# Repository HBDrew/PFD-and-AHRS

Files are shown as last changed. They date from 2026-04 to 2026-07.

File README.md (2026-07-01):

# AHRS PFD — Dual Display System

A two-board avionic display system with **two display versions** that share a single AHRS source:

| Board | Role |
|---|---|
| **Pico W** | Reads IMU (ICM-42688-P or WT901), GPS, BME280 baro. Serves state to the display over Wi-Fi SSE |
| **Pi Zero 2W** | Waveshare 3.5" DPI 640×480 PFD — plain horizon, TAWS alerting, airport/runway overlays, no SVT |
| **Pi 4 / Pi 5** | 1024×600 PFD — true 3D Synthetic Vision Terrain rendered through OpenGL ES + same overlays (same `pi4/` build on either board) |

Both displays connect to the same Pico W AHRS unit over Wi-Fi SSE. The feature set (airports, runways, extended centerlines, obstacles, TAWS, persistence, simulator, demo mode) is identical across both — the Pi 4 adds the OpenGL SVT terrain background with mountains that rise above the horizon line.

---

## Repository Structure

```
PFD-and-AHRS/
├── firmware/          # Pico W AHRS sensor firmware (shared by both displays)
├── shared/            # Common Python modules
│   ├── sse_client.py  # SSE streaming client
│   ├── terrain.py     # SRTM tile loader + TAWS clearance query
│   ├── obstacles.py   # FAA DOF parser + spatial query
│   ├── airports.py    # OurAirports parser + spatial query
│   ├── runways.py     # OurAirports runways parser + spatial query
│   ├── settings.py    # Debounced atomic JSON settings persistence
│   └── config_base.py # SIM_PRESETS + shared constants
├── pi_zero/           # Pi Zero 2W display version (no SVT)
│   ├── pfd.py         # Pygame PFD — plain horizon
│   ├── config.py      # 640×480 display config
│   ├── setup.sh       # One-shot install for Pi Zero 2W
│   ├── data/          # SRTM tiles (TAWS) + obstacles + airports + settings.json
│   └── previews/      # Screenshots for this version
├── pi4/               # Pi 4 display version (full SVT)
│   ├── pfd.py         # PFD with OpenGL SVT terrain background
│   ├── svt_renderer.py    # Pygame SVT fallback (when EGL unavailable)
│   ├── svt_renderer_gl.py # OpenGL ES 3.0 SVT renderer (moderngl + EGL)
│   ├── render_pfd_offline.py # Offline preview PNG generator
│   ├── config.py      # Display profile (waveshare_35 / roadom_7)
│   ├── setup.sh       # One-shot install for Pi 4
│   ├── data/          # SRTM tiles + obstacles + airports + settings.json
│   └── previews/      # Screenshots (setup screens + pfd_gl/ OpenGL flight scenes)
├── pi_display/        # Original combined codebase (preserved for reference)
├── iphone_display/    # iPhone / browser PFD (served over AHRS-Link AP by the Pico W)
├── tools/             # Preview image generator
├── fetch_sedona_tiles.sh   # Quick-start: download KSEZ area SRTM tiles
├── fetch_airports.sh       # Download OurAirports CSV + runways CSV
├── wifi_switch.sh          # Toggle Pi between home WiFi and Pico W AP
├── Docs/              # Requirements, user manuals, test procedures
└── README.md
```

---

## Display Version Comparison

| Feature | Pi Zero 2W | Pi 4 |
|---|---|---|
| Processor | ARM Cortex-A53, 512 MB RAM | ARM Cortex-A72, 2–8 GB RAM |
| Display | Waveshare 3.5" DPI LCD (640×480, 40-pin GPIO parallel RGB, I2C cap touch, PWM backlight) | ROADOM 7" HDMI IPS (1024×600, USB cap touch) — or Waveshare 3.5" DPI as a fallback |
| Graphics | Pygame / SDL2 framebuffer | Pygame UI + OpenGL ES 3.0 SVT (via moderngl/EGL) |
| SVT terrain background | No — plain sky/ground horizon | Yes — full 3D perspective mesh |
| Terrain above horizon | No | Yes — mountain peaks + ridges rise above horizon line |
| Sun-angle shading + distance grid | No | Yes |
| TAWS caution / warning banners | Yes | Yes |
| Obstacle symbols (caret + lit star + R/Y/W height colour) | Yes | Yes |
| Airport symbols (public ring / heli H / seaplane / balloon) | Yes | Yes |
| Road-sign airport labels on posts | Yes | Yes |
| Runway polygons (within 8 NM) | Yes | Yes |
| Extended dashed centerlines (within 15 NM) | Yes | Yes |
| Type filters (PUBLIC / HELI / SEAPLANE / OTHER) | Yes | Yes |
| Overlay toggles (RUNWAYS / EXT C/LINES) | Yes | Yes |
| Settings persistence (atomic JSON, debounced writer) | Yes | Yes |
| Built-in flight simulator (12 presets + failure injection) | Yes | Yes |
| Demo mode (scripted Sedona flight) | Yes | Yes |
| Target frame rate | 30 fps | 30 fps |

Both versions share the same AHRS unit, instrument layout, menus, simulator, demo mode, and touch interface. A single `shared/` module tree is used by both.

---

## Hardware

### AHRS PCB rev A (shared by both display variants)

The AHRS sensor head is now a single integrated PCB carrying every sensor on one board. Wiring is fixed in the board layout — no bench breakouts, no jumpers, no per-build pinout drift.

| Part | Bus | Address / Port | Role |
|---|-----|---|---|
| Raspberry Pi Pico W | — | USB-C (debug + power) | Host processor + WiFi AP |
| WitMotion WT901 | UART0 (GP0/GP1, 9600 baud) | — | 9-DOF IMU, fused Euler output |
| u-blox NEO-6M | UART1 (GP4/GP5, 9600 baud) | — | NMEA GPS (GGA + RMC) |
| Bosch BME280 | I²C1 (GP2/GP3, 400 kHz) | `0x76` | Static pressure + OAT |
| Sensirion SDP33-1500Pa | I²C1 (GP2/GP3) | `0x21` | Differential pressure (pitot − static) |
| *(reserved)* SDP3x AOA twin | I²C1 (GP2/GP3) | `0x22` | Future AOA probe — see `Docs/BUGS_AND_TODO.md → AOA-PROBE` |
| MAX3232 breakout | — | — | RS-232 driver for future TruTrak autopilot tie-in |

Power draw is ~130 mA at 5 V from the Pico's USB-C — typical wallwart / cigarette-lighter 5 V supply works fine; aircraft-grade builds run through a regulated 5 V converter.

Pneumatic plumbing for the air-data path:

- SDP33 `+` port → pitot tube (ram pressure)
- SDP33 `−` port → static reference (teed into the BME280's open port)

The combination produces the full pitot-static set — IAS, TAS, density altitude, and a wind solution from the AHRS heading + GPS track — broadcast on the same `$AHRS` SSE / USB JSON packet. See `Docs/REQUIREMENTS_AHRS.md §7B` for the field-level requirements and `Docs/USER_MANUAL_PI4.md §21` for the pilot-facing description.

### Pi Zero 2W display
| Part | Notes |
|---|---|
| Raspberry Pi Zero 2W | 512 MB RAM |
| Waveshare 3.5" DPI LCD | 640×480 IPS, DPI parallel RGB via 40-pin GPIO header, 5-point I2C capacitive touch, PWM backlight on GPIO 18, device-tree overlay `waveshare-35dpi-3b-4b` |
| 64 GB microSD (Class 10 / A1) | Raspberry Pi OS Lite 64-bit |
| USB-C power (5V 2A+) | |

### Pi 4 / Pi 5 display
| Part | Notes |
|---|---|
| Raspberry Pi 4 **or Pi 5** | 2 GB+ RAM recommended. The `pi4/` build runs unchanged on a Pi 5 — same install, just more frame-rate headroom for the OpenGL SVT. |
| ROADOM 7" or 10" HDMI IPS | 1024×600, HDMI video + USB capacitive touch (no software backlight control — use the panel button). Set `DISPLAY_PROFILE` to `roadom_7` or `roadom_10` in `pi4/config.py`. Waveshare 3.5" DPI 640×480 (`waveshare_35`) is a panel-mount fallback (BRIGHTNESS over GPIO-18 PWM). |
| 64 GB microSD (Class 10 / A1) | Raspberry Pi OS Lite 64-bit |
| USB-C power (5V 3A) | |

### ADS-B IN receiver (optional)
Adds live traffic to the moving map. The display consumes **GDL90 over UDP** (port 4000) — the same wire format Stratux and portable receivers emit — so any GDL90 source works; the build below runs the receiver on the same Pi.

| Part | Notes |
|---|---|
| Nooelec NESDR Nano 2 — Dual-Band ADS-B bundle | Two RTL-SDR (RTL2832U) dongles + high-gain 978/1090 antennas. One dongle per band: **1090ES** (airliner/transponder traffic) and **978 UAT** (GA traffic + FIS-B weather, US only). Marketed for Stratux/FlightAware/ForeFlight. |
| (host) Raspberry Pi | Runs `dump1090` (1090) + `dump978` (978) and the GDL90 bridge. Can be the display Pi, a dedicated Pi (e.g. a Pi 5), or an existing Stratux box on the network. |

Install the receiver stack with `sudo bash tools/install_adsb.sh`. Pipeline:

```
NESDR dongles → dump1090 / dump978 → tools/adsb_gdl90_bridge.py → GDL90/UDP :4000 → PFD
```

The display layer is hardware-free (`shared/gdl90.py` decoder + `shared/adsb.py` UDP listener), so traffic also works against a Stratux on the network or in `--demo` (synthetic targets). Toggle the symbols via **Setup → Display → MAP LAYERS → TFC**. See `Docs/ADSB_IN.md` for the full design + setup.

**No receiver? Use the internet.** `tools/adsb_internet_feed.py` pulls live aircraft from a public ADS-B aggregator (airplanes.live / OpenSky, no key) and emits the same GDL90/UDP — so you can **test with real traffic** with no hardware, or use it **in flight over Starlink / cabin Wi-Fi** as a traffic source (it can follow your GPS with `--follow-ahrs`). Internet traffic is advisory only — see the doc. Quick test: `python3 pi4/pfd.py --demo --sim` in one terminal, `python3 tools/adsb_internet_feed.py --lat 33.94 --lon -118.40 --radius 80` in another.

---

## Quick Start — Pi Zero 2W

### 1. Flash SD card

Download **Raspberry Pi OS Lite (64-bit)**. Use **Raspberry Pi Imager** with SSH enabled, hostname `pfd`, and your Wi-Fi credentials.

### 2. Clone and install

```bash
ssh pi@pfd.local
sudo apt update && sudo apt install git -y
git clone https://github.com/HBDrew/PFD-and-AHRS.git
cd PFD-and-AHRS
sudo bash pi_zero/setup.sh
```

### 3. Download runtime data

```bash
bash fetch_sedona_tiles.sh        # SRTM tiles for KSEZ area (TAWS)
bash fetch_airports.sh pi_zero    # OurAirports airports + runways CSVs
# FAA obstacle data downloads in-app from Setup → System → OBSTACLES
```

### 4. Test demo mode

```bash
python3 pi_zero/pfd.py --demo --sim
```

### 5. Reboot — PFD starts automatically

```bash
sudo reboot
```

---

## Quick Start — Pi 4 / Pi 5

### 1. Flash SD card

Same as above, but use a Pi 4 **or Pi 5** (hostname e.g. `pfd4` / `pfd5`). The install is identical on both boards. Set `DISPLAY_PROFILE` in `pi4/config.py` to match the connected panel — `roadom_7` or `roadom_10` for the 1024×600 HDMI panels, `waveshare_35` for the 640×480 DPI.

### 2. Clone and install

```bash
ssh pi@pfd4.local
sudo apt update && sudo apt install git -y
git clone https://github.com/HBDrew/PFD-and-AHRS.git
cd PFD-and-AHRS
sudo bash pi4/setup.sh
```

### 3. Download runtime data

```bash
bash fetch_sedona_tiles.sh        # SRTM tiles — powers TAWS and the SVT terrain mesh
bash fetch_airports.sh pi4        # OurAirports airports + runways CSVs
# FAA obstacle data downloads in-app from Setup → System → OBSTACLES
```

### 4. Test demo mode

```bash
python3 pi4/pfd.py --demo --sim
```

You should see the SVT terrain mesh behind the attitude indicator with cyan distance grid and sun-angle shading. If the console logs `SVT_RENDERER: opengl  GL_AVAILABLE: True` you're running the full OpenGL path; a `pygame` fallback indicates EGL couldn't initialise.

### 5. Reboot — PFD starts automatically

```bash
sudo reboot
```

---

## Multi-display panels (Pi 4/5 + Pi Zero together)

Several displays on the same cabin network keep each other in sync (bugs,
baro, direct-to, flight plans, **and winds aloft**) over UDP — peer-to-peer, no
master. Turn it on per display from the **Screen Sync** setup screen (see the
pilot manuals). Winds in particular: only **one** display needs internet — it
fetches the national winds grid and broadcasts it; the others adopt it and make
zero Open-Meteo calls (so three displays don't trip the per-IP rate limit).

### Seeding a fresh Pi Zero from a Pi 4/5 (no re-download)

The Pi 4/5 does the heavy data work (SRTM, water masks, Natural Earth). Hand
the cooked data to a Pi Zero instead of re-downloading on it:

```bash
# On the Pi 4/5: compact SRTM1 → SRTM3 copies for the Zero
python3 tools/compact_srtm.py --srtm-dir ~/PFD-and-AHRS/pi4/data/srtm \
    --output-dir /tmp/srtm3_out
# Then on the Pi Zero, pull the three datasets over the LAN:
rsync -av pfd4.local:/tmp/srtm3_out/                      ~/PFD-and-AHRS/pi_zero/data/srtm/
rsync -av pfd4.local:~/PFD-and-AHRS/pi4/data/water/       ~/PFD-and-AHRS/pi_zero/data/water/
rsync -av pfd4.local:~/PFD-and-AHRS/pi4/data/natural_earth/ ~/PFD-and-AHRS/pi_zero/data/natural_earth/
```

The Zero then has terrain + water + boundary lines with no Mapzen/Natural-Earth
downloads of its own. (A one-command bootstrap wrapper is on the TODO list —
DEPLOY-RSYNC.)

---

## Pico W / Pico 2W — Setup

> **Pico 2W (RP2350) vs Pico W (RP2040):** either works; the Pico 2W's larger RAM is the recommended board (it absorbs the bigger iPhone page + future growth). Both flash the same way. If the board is **blank** (no MicroPython yet), install MicroPython first: hold the **BOOTSEL** button while plugging the USB cable, release once it mounts as a USB drive (labelled `RPI-RP2` on RP2040 or `RP2350` on the Pico 2W), then **drag the matching MicroPython `.uf2`** onto that drive — be sure to use the **RP2350** build for a Pico 2W. It reboots into MicroPython; then copy the firmware files below.

### Copy firmware files

Connect the Pico via USB. Copy the `firmware/` folder contents to the Pico root (using Thonny, rshell, or mpremote):

```
firmware/
├── main.py
├── config.py          ← WiFi credentials, pin map, sensor enables
├── web_server.py
├── wt901.py
├── gps.py
├── bme280.py          ← BME280 (static pressure + OAT)
├── sdp31.py           ← SDP33-1500Pa differential pressure (IAS)
└── airdata.py         ← IAS / TAS / density alt / wind triangle
```

### Edit config.py

```python
AP_SSID     = "PFD_AP"      # must match wifi_switch.sh PICO_SSID
AP_PASSWORD = "picoahrs1"   # must match wifi_switch.sh PICO_PSK
```

`config.py` also carries the sensor enable flags (`BME280_ENABLE`, `SDP31_ENABLE`) so a bench Pico W without one or both sensors still boots cleanly — the firmware sets `baro_ok` / `airdata_ok = False` and the displays fall back automatically.

### Wiring — AHRS PCB rev A

The pin map matches the [hardware table](#ahrs-pcb-rev-a-shared-by-both-display-variants) above. On the PCB build everything is already wired; on the bench-breakout build see the [Appendix](#appendix-bench-breakout-wiring) below.

---

## Flight Mode Workflow

### Switch Pi to Pico W AP
```bash
sudo bash wifi_switch.sh flight
```

### Switch Pi to home WiFi (for updates/terrain)
```bash
sudo bash wifi_switch.sh home
```

### Check current WiFi
```bash
bash wifi_switch.sh status
```

---

## Touchscreen Controls

| Action | Effect |
|---|---|
| Tap altitude tape | Set altitude bug to tapped position |
| Tap top of alt tape | Open altitude bug numpad |
| Tap top of speed tape | Open speed bug numpad |
| Tap heading tape | Set heading bug to tapped position |
| Tap bottom-left of heading strip | Open heading bug numpad |
| Tap bottom-right of heading strip | Open baro setting numpad |
| Two-finger hold (0.8 s) | Open setup menu |
| Setup → System → AIRPORTS | Airport data screen (filters, runway/centerline toggles, UPDATE) |
| Tap red SIM ✕ button at AI top-centre (during sim) | Open SIM CONTROLS overlay (sensor failures + FOLLOW mode + PAUSE/RESUME + EXIT SETUP / EXIT SIM) |
| (keyboard) D | Toggle demo mode |
| (keyboard) Esc | Quit |

See `Docs/USER_MANUAL_ZERO.md` or `Docs/USER_MANUAL_PI4.md` for full operational documentation. Filter states, bug values, brightness, baro unit, and every other user-set value persist across power cycles in `data/settings.json`.

---

## Documentation

| Document | Description |
|---|---|
| `Docs/REQUIREMENTS_AHRS.md` | AHRS unit high-level requirements (shared) |
| `Docs/REQUIREMENTS_DISPLAY_ZERO.md` | Pi Zero 2W display HLRs (no SVT) |
| `Docs/REQUIREMENTS_DISPLAY_PI4.md` | Pi 4 display HLRs (full SVT + OpenGL) |
| `Docs/USER_MANUAL_IPHONE.md` | iPhone / browser PFD pilot's user manual |
| `Docs/USER_MANUAL_ZERO.md` | Pi Zero 2W pilot's user manual |
| `Docs/USER_MANUAL_PI4.md` | Pi 4 pilot's user manual |
| `Docs/TEST_PROCEDURE_ZERO.md` | Pi Zero 2W bench test procedure (TP-ZERO-001) |
| `Docs/TEST_PROCEDURE_PI4.md` | Pi 4 bench test procedure (TP-PI4-001) — adds an OpenGL SVT phase |

---

## AHRS Setup

Configure how the AHRS box is physically mounted in the aircraft, fine-trim residual offsets, and run the compass calibration wizard. All on the same screen:

**Setup → AHRS / SENSORS**

| Row | Control | What it does |
|-----|---|---|
| PITCH TRIM | ± steppers (0.1° per tap) | Fine-trim if the horizon sits above/below level on the ground |
| ROLL TRIM | ± steppers (0.1° per tap) | Fine-trim if a wing reads low on the ground |
| MAGNETOMETER | CALIBRATE button | Opens the 8-point compass-cal wizard (N / NE / E / SE / S / SW / W / NW). Cal table is stored *on the AHRS* in flash, shared by every display |
| ORIENTATION | FWD / LEFT / RIGHT / AFT | Which side of the AHRS the connector points toward, viewed from the pilot's seat. Default is RIGHT. Stored on the AHRS (`orient.json` on Pico flash) |
| MOUNTING | NORMAL / INVERTED | Whether the AHRS is right-side-up or upside-down. Independent of orientation. Stored on the AHRS |
| HEADING SOURCE | MAG / TRK / AUTO | Magnetometer, GPS ground track, or auto-select (TRK in motion, MAG when stationary) |
| AIRSPEED SOURCE | GPS GS / IAS SENSOR | IAS SENSOR by default — SDP33-1500Pa with BME280 density correction; falls back to GPS groundspeed when the air-data path reports unhealthy |

Trim, orientation, mounting, and the compass cal all combine cleanly — orientation remaps pitch/roll axes for a non-RIGHT mounting, mounting flips for upside-down, the cal corrects the residual mag bias, and trim is the final fine-tuning. Sim and Demo modes bypass every AHRS-mounting compensation so a calibrated trim doesn't show up as wing-down on a level sim flight.

### Compass Calibration

Tap CALIBRATE to open the 8-point walk-through wizard:

1. Point the aircraft's nose **NORTH** (000°) and tap **⊕ CAPTURE N**.
2. **NE** (045°), tap CAPTURE NE.
3. **EAST** (090°), tap CAPTURE E.
4. **SE** (135°), tap CAPTURE SE.
5. **SOUTH** (180°), tap CAPTURE S.
6. **SW** (225°), tap CAPTURE SW.
7. **WEST** (270°), tap CAPTURE W.
8. **NW** (315°), tap CAPTURE NW.

The wizard builds a 36-point deviation table (linear interpolation between the 8 captures, one slot per 10°) and pushes it to the AHRS over USB serial (`$MAGDEV,<36 floats>`) or the Wi-Fi config endpoint (`GET /magcal?action=set&t=…`). The Pico W writes the table to `magdev.json` on its flash and applies it before broadcasting yaw — so every display (Pi 4, Pi Zero, iPhone PWA) reads the same calibrated heading off the SSE / `$AHRS` stream without per-display calibration. The Pi 4 also keeps a belt-and-braces local copy in `pi4/data/settings.json` (`pi4_magdev`) that it applies on top of the broadcast yaw if the push to the Pico fails. AHRS orientation + mounting are persisted the same way (`orient.json` on Pico flash, via `$ORIENT,connector,mounting`).

Buttons:
- **EXIT** — close the modal (the cal is committed on the 8th capture, so this is non-destructive). Reads CANCEL only mid-walk when there are partial captures still in flight to the AHRS.
- **RESET** — wipe the stored cal back to zero (sends `$MAGDEV,CLEAR` to the AHRS).
- **RESTART** — abandon partial captures and start the eight-capture sequence over.
- **⊕ CAPTURE X** — record the current heading at the cardinal / intercardinal indicated by X (N / NE / E / SE / S / SW / W / NW).

The status row on the AHRS Setup screen shows `max |Δ|` (worst-case residual across the eight captures) so a glance tells you whether the cal is current.

The cal only shifts MAG-mode display — TRK mode is unaffected because the complementary filter operates on yaw deltas, where a constant-shape correction's frame-to-frame derivative is negligible.

---

## Direct-to Navigation

Tap the empty **CDI strip** above the heading box (or **DIRECT TO** on the AIRPORT DATA screen) to open the on-screen keyboard for waypoint entry.

| Action | Effect |
|---|---|
| Type ident → ENTER | Look up the airport. If found, prompt "Activate Direct to *XXXX*?" with ACTIVATE / CANCEL. Two-tap commit prevents accidental flight-plan edits. |
| Hit ENTER on empty buffer (with an active waypoint) | Re-activate the existing waypoint. Use this to refresh the magenta course line from your current position without retyping. |
| Type unknown ident → ENTER | Keyboard stays open with a red "UNKNOWN WAYPOINT *XXXX*" hint. Backspace or any keystroke clears the error so you can correct in place. |
| **DIRECT TO *XXXX*** button (on tall keyboards) | Resolves and shows the nearest public airport's ident on the button itself, then routes through the same Activate? confirmation. |
| **CANCEL FLIGHT PLAN** | Wipes the active direct-to. |

After activation, a magenta course-trace line draws from your activation point to the destination, **draped over the SRTM terrain mesh**. The trace is sampled in a background thread (every 0.2 NM) so the line shows up immediately at the near end and grows outward toward the waypoint as the worker walks the SRTM tiles — no UI freeze even on long cross-country courses.

The **CDI** strip above the heading box shows ident · bearing · distance and a magenta XTK diamond at full-scale ±1 NM.

---

## AGL Readout

A small "AGL" box in the lower-right corner of the AI shows your real altitude above the SRTM terrain at your current lat/lon — independent of baro, calculated from real GPS / sensor altitude minus the local ground elevation. Reads dashes when at or below ground level (sensor / DEM disagreement). Hidden when there's no GPS fix or the SRTM lookup returns "missing tile".

---

## V-Speed Configuration

V-speeds are set via the on-screen setup menu and take effect immediately on the speed tape:

1. Two-finger hold anywhere on the PFD for 0.8 s to open the setup menu
2. Tap **FLIGHT PROFILE**
3. Tap any V-speed field and enter the value with the numpad

Default values (Cessna 172S) are restored by tapping **RESET DEFAULTS** on the Flight Profile screen, or via **System → RESET DEFAULTS**.

---

## Troubleshooting

### PFD screen blank on boot
```bash
sudo systemctl status pfd.service
sudo journalctl -u pfd.service -n 50
```

### Display wrong orientation / resolution
Check `/boot/firmware/config.txt` — `setup.sh` should have added the framebuffer settings.

### "NO LINK" badge on PFD — can't connect to Pico W
1. Check Pi is on Pico W AP: `bash wifi_switch.sh status`
2. Check Pico W is powered and booted: LED should be blinking
3. Verify `config.py` AP_SSID matches `wifi_switch.sh` PICO_SSID
4. Try: `curl http://192.168.4.1/state` from the Pi

### "AHRS FAIL" on display
- WT901 UART wiring (check TX→RX cross)
- WT901 baud rate (default 9600 in `config.py`)
- Allow 5 seconds after Pico boot for sensor to initialise

### No GPS fix
- GPS needs open-sky view; initial fix can take 2–5 minutes cold-start
- Check NEO-6M LED: 1 Hz blink = fix acquired, fast blink = searching

### Terrain not showing in demo (Pi 4 only)
```bash
bash fetch_sedona_tiles.sh
```
After downloading, restart PFD: `sudo systemctl restart pfd.service`

If the Pi 4 SVT falls back to the flat blue/brown split even with tiles present, check the startup console for `SVT_RENDERER: opengl  GL_AVAILABLE: True`. If it says `GL_AVAILABLE: False`, the EGL context failed to create — typically a GPU memory allocation issue. Check `gpu_mem=256` is set in `/boot/firmware/config.txt`.

### Airport symbols / runways / centerlines not appearing
```bash
bash fetch_airports.sh           # downloads to both pi_zero and pi4
bash fetch_airports.sh pi4       # just pi4
```
Check that the RUNWAYS / EXT C/LINES toggles on the AIRPORT DATA screen are enabled (they persist across power cycles in `settings.json`).

### Settings don't persist across reboots
`data/settings.json` is written atomically on a background thread with a 1.5 s debounce. If a setting isn't persisting, wait 3+ seconds before power-cycling. Verify the file exists and is readable:
```bash
cat pi4/data/settings.json     # (or pi_zero/)
```
The Wi-Fi password is intentionally not persisted — this is not a bug.

---

## Updating

```bash
sudo bash wifi_switch.sh home   # get on internet
cd ~/PFD-and-AHRS
git pull
sudo systemctl restart pfd.service
```

---

## Autostart on Boot

The `pi4/setup.sh` and `setup.sh` installers both create and enable a `pfd.service` systemd unit so the PFD launches automatically on every power-up — no keyboard, no SSH, no manual command. If you've already installed but want to refresh just the service definition (for example after pulling a fix to the unit's environment), run the standalone helper:

```bash
sudo bash tools/install_autostart.sh
```

---

## Shutting down (don't just pull power)

An SD-booted Pi can corrupt its card if power is cut mid-write. The **SYSTEM** setup screen now has **SHUTDOWN** and **REBOOT** buttons (arm-to-confirm: tap once to arm, again within 4 s to execute). SHUTDOWN halts the OS cleanly — **wait for the green activity LED to stop blinking, then cut power.** Settings are also written durably (temp-file + `fsync` + atomic rename), so a hard pull can't truncate `settings.json`.

The setup scripts install a scoped sudoers rule so the non-root PFD user can run *only* `systemctl poweroff` / `reboot`. On a Pi that was set up before this feature, install just that rule:

```bash
sudo bash tools/install_shutdown_sudoers.sh
```

**Optional hardware power button.** Wire a momentary switch across a GPIO and GND and add an overlay to `/boot/firmware/config.txt` — it halts the Pi cleanly on a short press *and* wakes it from halt:

```
# GPIO3 (pin 5) is the default; it also has hardware wake-from-halt
dtoverlay=gpio-shutdown
```

A more robust "cut the master and walk away" option — read-only root filesystem so a power pull can never corrupt the OS — is planned; see `Docs/BUGS_AND_TODO.md`.

This writes a clean unit, reloads systemd, and starts the service. Common control commands:

```bash
sudo systemctl status  pfd.service     # current state + last few log lines
sudo journalctl -u     pfd.service -n 100 --no-pager   # recent log
sudo systemctl restart pfd.service     # bounce
sudo systemctl stop    pfd.service     # take it down (until reboot)
sudo systemctl disable pfd.service     # don't auto-start next boot
```

The unit uses `SDL_VIDEODRIVER=kmsdrm`, `SupplementaryGroups=video render input`, and `StartLimitIntervalSec=0` so the service can grab the framebuffer cleanly and keeps retrying after transient crashes instead of giving up.

---

## Branch Model

This repository carries two independent device timelines on the remote:

| Branch | Targets | Notes |
|---|---|---|
| `main` | Pi 4 + Pi Zero 2W displays | Default branch. The displays auto-pull this on update. |
| `iphone-main` | Browser / iPhone display under `iphone_display/` | Independent history — used for in-flight iPhone testing without disturbing the dedicated displays. |

Shared work (firmware, `shared/` modules, docs touched by both) is generally applied twice — once on each branch — rather than merging across the timelines. The two branches can be merged later if/when the device feature sets converge.

---

## Roadmap

| Phase | Feature |
|---|---|
| ✅ V1 | AHRS PFD — Pico W + phone browser display |
| ✅ V2 | Pi Zero 2W dedicated display with SVT terrain |
| ✅ V3 | Split into Pi Zero 2W (no SVT) and Pi 4 (full SVT) versions |
| ✅ V4 | Pi 4 OpenGL ES SVT with sun shading, distance grid, 3D terrain above horizon |
| ✅ V4.1 | Airport database (OurAirports, 72k airports) + type filters + road-sign labels |
| ✅ V4.2 | FAA obstacle database + caret symbols with R/Y/W height colour coding |
| ✅ V4.3 | Runway polygons + extended dashed centerlines with toggles |
| ✅ V4.4 | User settings persistence (atomic JSON, debounced writer) |
| ✅ V4.5 | Runway forward-clip + per-corner anchoring so the polygon stays visible during taxi / fly-over and never wraps as a phantom across the AI |
| ✅ V4.6 | Obstacle airport-boundary clutter filter — hides terminal / ramp infrastructure under 50 ft AGL within 1 NM of any runway centroid; true MSL labels |
| ✅ V4.7 | AGL readout (lower-right of AI) + magenta direct-to course trace draped over SRTM terrain (async, progressive build) |
| ✅ V4.8 | Direct-to nav with on-screen keyboard, "Activate Direct to XXXX?" confirmation modal, NEAREST quick-button showing the resolved ident |
| ✅ V4.9 | AHRS 4-way mounting orientation (FWD / LEFT / RIGHT / AFT) with magnetic offset, ENU→NED base correction, sim/demo bypass |
| ✅ V5.0 | Compass calibration wizard — 8-point walk-through, 36-slot deviation table stored on the AHRS in flash so every display reads the same calibrated heading |
| ✅ V5.1 | AHRS PCB rev A — single-board Pico W + WT901 + NEO-6M + BME280 + SDP33-1500Pa; full pitot-static air-data set (IAS / TAS / density alt / wind triangle) on the SSE / USB stream |
| ✅ V5.2 | EGPWS-style voice callouts (TERRAIN / OBSTACLE / SINK RATE / PULL UP / BANK ANGLE), unusual-attitude recovery cues, look-ahead TAWS, ±25° forward-wedge obstacle filter |
| ✅ V5.3 | Flight-plan SAVE / LOAD — named, persistent plans recallable on the MFD FPL page |
| ✅ V5.4 | ADS-B IN traffic — GDL90/UDP decoder + UDP listener, TCAS-style diamonds on both moving maps, Nooelec NESDR Nano 2 dual-band receiver via dump1090/dump978 + GDL90 bridge; on-screen traffic status + flashing TRAFFIC banner + "Traffic, Traffic" callout (pi4) |
| ✅ V5.5 | Internet + FIS-B weather suite — METARs (category dots), TAF / AIRMET / SIGMET / NOTAM readouts, graphical AIRMET/SIGMET, NEXRAD, RADIO/AUTO/INET source toggle; full-screen MFD with the OVLY overlay cycle |
| ✅ V5.6 | Winds aloft (WND) — cached national GFS grid (Open-Meteo), barbs + temps at selectable altitude/forecast-time, disk-cached + shared between displays over the LAN |
| ✅ V5.7 | Flight-path vector (velocity-vector marker) on the AI — pi4 + iPhone |
| V6 | TruTrak Vizion RS-232 autopilot interface |
| V7 | Moving map / MFD (separate dedicated hardware unit) |
| V8 | Highway-in-the-sky waypoint tunnel; IFR procedures (approaches / holds / airways) |
| V9 | Time-of-day sun position, texture-mapped terrain |
| V10 | Setup-screen vertical scrolling for compact display profiles |

---

## Appendix — Bench breakout wiring

The original development build wired the Pico W to four separate breakout boards. The same firmware runs on the bench rig as on the PCB — the pin map below matches `firmware/config.py` and produces an identical `$AHRS` packet. Use this when bringing up a Pico without the rev A board.

### WT901 AHRS → Pico W
| WT901 | Pico W | Notes |
|---|---|---|
| VCC (5V) | VBUS (pin 40) | 5 V from USB |
| GND | GND (pin 38) | |
| TX | GP1 (pin 2) | UART0 RX |
| RX | GP0 (pin 1) | UART0 TX |

### NEO-6M GPS → Pico W
| NEO-6M | Pico W | Notes |
|---|---|---|
| VCC | 3V3 (pin 36) | |
| GND | GND | |
| TX | GP5 (pin 7) | UART1 RX |
| RX | GP4 (pin 6) | UART1 TX |

### BME280 → Pico W
| BME280 | Pico W | Notes |
|---|---|---|
| VCC | 3V3 | |
| GND | GND | |
| SDA | GP2 (pin 4) | I²C1 (shared with SDP33) |
| SCL | GP3 (pin 5) | I²C1 (shared with SDP33) |

### SDP33-1500Pa → Pico W
| SDP33 | Pico W | Notes |
|---|---|---|
| VDD | 3V3 | |
| GND | GND | |
| SDA | GP2 (pin 4) | I²C1 (shared with BME280) |
| SCL | GP3 (pin 5) | I²C1 (shared with BME280) |
| ADDR | floating | I²C address `0x21`; tie to VDD for `0x22` (AOA twin) |
| `+` port | airframe pitot | ram pressure |
| `−` port | airframe static (teed into BME280's open port) | static reference |

If your bench Pico has only some of these sensors connected, leave the corresponding `*_ENABLE` flag in `firmware/config.py` as default (the firmware probes for each sensor and gracefully falls back when one is missing — speed tape switches to GPS GS, altitude tape switches to GPS ALT, etc.).

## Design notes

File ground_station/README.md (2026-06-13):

# PFD Ground Station

A desktop companion app that **builds**, **deploys**, and **publishes** the
flight data the PFD/AHRS consumes — so the 28-day data refresh is buttons, not
a terminal.

One card per data product:

| Product | Source you supply | Auto-download |
|---|---|---|
| **Nav Data** | FAA NASR folder + CIFP (`FAACIFP18`) | — |
| **Airspace** | folder of FAA `*.geojson` | — |
| **Airports** | — | OurAirports CSV |
| **Obstacles** | — | FAA Digital Obstacle File |
| **Terrain (SRTM)** | folder of raw `.hgt` tiles | — |
| **Water Tiles** | Natural Earth water `.shp` | — |

For each: **Build** writes the cache into a workspace, **Deploy** copies it into
the connected checkout's `pi4/data/…` and `pi_zero/data/…` folders, and (nav
data only) **Publish →GitHub** uploads it to the release the on-device NAV DATA
screen downloads from.

## Why this exists (nav data in particular)

Airports / obstacles / terrain / airspace can be fetched by the device itself
from public sources. **Nav data can't** — the FAA only publishes IFR data
(fixes, airways, approaches, holds) as large raw subscription files too big to
parse on a Pi. So it must be built on a real computer once per cycle, then
either copied to the device or published for it to download. This app does that
build.

## Run from source

```bash
python3 -m ground_station          # or:  python3 run_ground_station.py
```
Needs Python 3.8+, `numpy`, and Tk (stdlib; on Linux: `apt install python3-tk`).
Run it from inside a repo checkout so **Deploy** can see the `pi4` / `pi_zero`
data dirs.

## Build a standalone app (no Python needed on the target PC)

```bash
pip install pyinstaller
pyinstaller ground_station/pfd_ground_station.spec
# → dist/PFD-Ground-Station(.exe)
```
Drop the executable inside (or next to) a repo checkout so **Deploy** can find
the device data dirs; **Build** and **Publish** work from anywhere.

## The 28-day nav-data refresh

1. Download the current **NASR Subscription** (CSV zip) and **CIFP** zip from
   faa.gov (both free). Unzip them.
2. In the app: point **Nav Data** at the NASR folder and the `FAACIFP18` file,
   click **Build**.
   - First time only: validate the CIFP column offsets — see the note in
     `tools/build_navdata_us.py` (`--dump-cifp`).
3. Click **Deploy** (copies onto the Pi data dir / SD card) **and/or**
   **Publish →GitHub** (needs a token with `repo` / Contents:write scope; the
   device then pulls it via NAV DATA → DOWNLOAD).

Settings (token, last-used paths, deploy targets) are remembered in
`~/.pfd_ground_station.json`.

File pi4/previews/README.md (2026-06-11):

# Pi 4 — Preview Screenshots

Screenshots from the Pi 4 version of the PFD with full Synthetic Vision
Terrain (SVT) rendered via OpenGL.

## Regenerating

These PNGs are checked into git so the user manuals render correctly on
GitHub.  To regenerate them after a UI / scene change, run on the pi4:

```bash
./tools/regen_previews.sh pi4
```

That wraps `tools/capture_pi4_previews.sh`, which uses the offline GL
renderer (`pi4/render_pfd_offline.py`) with `SDL_VIDEODRIVER=dummy` +
an offscreen EGL context so the captured PNGs include the full 3D SVT
terrain.  Must be run on a pi4 (needs the V3D driver).  The script
stops `pfd.service` for the capture session and brings it back on exit.
(The same build runs on a **Pi 5** — capture there too if that's your
flying hardware.)

## New-feature previews (referenced by the manual)

| File (in `pfd_gl/`) | Source | Notes |
|---|---|---|
| `preview_flight_path_vector.png` | **offline tool** (`SCENES` + `_setup_flight_path_vector` in `render_pfd_offline.py`) | regenerated by `regen_previews.sh pi4` — no live data needed |
| `preview_winds.png` | **live capture** | WND overlay needs real winds data — see below |
| `preview_metar.png` | **live capture** | MET overlay needs live METARs |
| `preview_traffic.png` | **live capture** | needs live/replayed ADS-B traffic |
| `preview_mfd.png` | **live capture** | full-screen MFD (3-finger swap), any overlay |
| `preview_mfd_airspace.png` | **live capture** | MFD with OVLY → ASP (airspace data loaded, within 80 NM) |
| `preview_mfd_nexrad.png` | **live capture** | MFD with OVLY → NEX (live NEXRAD raster) |
| `preview_mfd_trk_up.png` | **live capture** | MFD in **TRK↑** orientation (tap the N↑/TRK↑ label) |
| `preview_mfd_160.png` | **live capture** | MFD zoomed out to the **160 NM** range |

The following are **2D screens generated by the offline tool** (`regen_previews.sh pi4`, no live data needed) and land in `pi4/previews/` (not `pfd_gl/`): `preview_fpl_editor.png`, `preview_fpl_load.png`, `preview_fpl_latlon.png`, `preview_user_wpt.png`, `preview_mfd_strip_setup.png`, `preview_setup_screen_sync.png`, `preview_airspace_data.png`, `preview_airspace_classes.png`, `preview_wifi_scan.png`, `preview_ahrs_firmware.png`.

**Live capture** (the offline renderer has no live weather/traffic feeds, so
these four are grabbed from the running display instead): with the app running
and the internet feeds up, switch to the page you want (OVLY → WND / MET / TFC,
or 3-finger-swap to the MFD), then save a framebuffer grab to the matching
filename, e.g.:

> **Load an active flight plan first** (or a Direct-To) before grabbing
> `preview_mfd.png` — otherwise the WPT / BTW / DIST / ETE / ETA slots on the
> bottom data strip dash out and the magenta course line is absent. The piZ
> offline batch seeds a KPRC → KSEZ → KFLG plan for this; match it on the pi4
> capture so the two manuals stay consistent.

```bash
# on the running pi4/pi5, capture the current framebuffer:
fbgrab ~/PFD-and-AHRS/pi4/previews/pfd_gl/preview_winds.png    # WND page up
fbgrab ~/PFD-and-AHRS/pi4/previews/pfd_gl/preview_metar.png    # MET page up
fbgrab ~/PFD-and-AHRS/pi4/previews/pfd_gl/preview_traffic.png  # TFC page, traffic in view
fbgrab ~/PFD-and-AHRS/pi4/previews/pfd_gl/preview_mfd.png      # full-screen MFD
fbgrab ~/PFD-and-AHRS/pi4/previews/pfd_gl/preview_mfd_airspace.png  # MFD, OVLY=ASP
fbgrab ~/PFD-and-AHRS/pi4/previews/pfd_gl/preview_mfd_nexrad.png    # MFD, OVLY=NEX
fbgrab ~/PFD-and-AHRS/pi4/previews/pfd_gl/preview_mfd_trk_up.png    # MFD, TRK-up
fbgrab ~/PFD-and-AHRS/pi4/previews/pfd_gl/preview_mfd_160.png       # MFD, 160 NM range
```

(`sudo apt install fbgrab` if needed; or use the sim + the internet feeds for
repeatable framing.)

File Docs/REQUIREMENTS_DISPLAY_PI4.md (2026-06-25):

# Display Unit (Pi 4) — High-Level Requirements

| Field | Value |
|---|---|
| Document No. | HLR-DISP-PI4-001 |
| Title | Display Unit (Pi 4) — High-Level Requirements |
| Project | Pico-AHRS / PFD |
| Date | 2026-05-15 |
| Version | 0.4 |

---

## 1. Overview

The Pi 4 display unit is the high-performance variant of the pilot-facing PFD. It runs on a Raspberry Pi 4 (2 GB) and renders a full Primary Flight Display with true Synthetic Vision Terrain (SVT) using OpenGL ES vector graphics. The SVT renderer uses a 3D perspective projection so that terrain features — including mountain peaks and ridges above the aircraft's altitude — are visible above the horizon line. The display unit receives flight-state data from the AHRS unit over a Wi-Fi SSE stream and provides the same touch-based interface, menus, simulator, and demo mode as the Pi Zero 2W variant. The Pi 4's VideoCore VI GPU and additional RAM allow sustained 30 fps rendering of the full SVT terrain mesh, vector-drawn instruments, and anti-aliased graphics.

For the lightweight variant without SVT, see HLR-DISP-ZERO-001.

---

## 2. Hardware Platform

> **REQ-DISP-PI4-HW-001** The processor shall be a Raspberry Pi 4 with a minimum of 2 GB RAM.

> **REQ-DISP-PI4-HW-002** The nominal display shall be a ROADOM 7" IPS 1024×600 HDMI panel with USB capacitive touch. The software shall support a configurable display profile via `DISPLAY_PROFILE` in `pi4/config.py` so that alternative panels of the same or higher resolution, or a 640×480 Waveshare DPI panel as a fallback, can be substituted. The minimum supported resolution is 640×480 pixels.

> **REQ-DISP-PI4-HW-003** The touchscreen shall support at minimum 2-point simultaneous touch detection to allow two-finger gestures for menu access.

> **REQ-DISP-PI4-HW-004** The display unit shall be powered from an aircraft 5 V supply (3 A minimum for Pi 4).

> **REQ-DISP-PI4-HW-005** The GPU memory allocation shall be set to a minimum of 256 MB to support OpenGL ES terrain rendering.

---

## 3. Rendering Performance

> **REQ-DISP-PI4-REND-001** The PFD shall render at a sustained minimum of 30 frames per second under all normal operating conditions including full SVT terrain rendering.

> **REQ-DISP-PI4-REND-002** The PFD renderer shall use a hybrid architecture: pygame/SDL shall draw all PFD UI elements (tapes, pitch ladder, roll arc, drum boxes, menus, aircraft symbol) into the display surface; OpenGL ES shall render only the SVT terrain background, which is composited into the attitude indicator region of the pygame surface as a `pygame.Surface` read back from an offscreen framebuffer.

> **REQ-DISP-PI4-REND-003** The OpenGL SVT renderer shall use OpenGL ES 3.0 (accessed via `moderngl`) with a standalone EGL context so that no X11 or Wayland compositor is required. If the EGL context cannot be created, the renderer shall automatically fall back to the pygame scanline SVT implementation.

> **REQ-DISP-PI4-REND-004** The SVT rendering path shall be selectable via the `SVT_RENDERER` configuration value (`"opengl"` or `"pygame"`). Default shall be `"opengl"`.

> **REQ-DISP-PI4-REND-005** Anti-aliasing on terrain grid lines shall be applied via `fwidth()`-based screen-space derivatives so that line width is constant regardless of terrain distance.

> **REQ-DISP-PI4-REND-006** An IIR low-pass smoothing filter with coefficient α = 0.25 per frame shall be applied to the attitude, altitude, airspeed, and vertical speed values before rendering.

---

## 4. Data Stale Detection

> **REQ-DISP-PI4-STALE-001** If no valid SSE event is received from the AHRS unit within 3 seconds, the display shall treat all received data as stale.

> **REQ-DISP-PI4-STALE-002** While data is stale, the display shall show a `NO LINK` status badge and shall set `ahrs_ok = false` internally.

---

## 5. Airspeed Tape

> **REQ-DISP-PI4-SPD-001** The airspeed tape shall display a Veeder-Root style drum readout centred on the current airspeed value, with smooth continuous digit roll as speed changes.

> **REQ-DISP-PI4-SPD-002** V-speed colour arcs shall be drawn on the right edge of the airspeed tape: white (VS0–VFE), green (VS1–VNO), yellow (VNO–VNE), and a red radial line at VNE.

> **REQ-DISP-PI4-SPD-003** The drum numerals shall change colour based on airspeed: white below VNO, yellow above VNO, red above VNE.

> **REQ-DISP-PI4-SPD-004** A speed bug chevron shall be rendered at the currently set speed bug value.

> **REQ-DISP-PI4-SPD-005** The speed bug chevron and readout button shall be MAGENTA when the source is GPS groundspeed, and CYAN when the source is an IAS sensor.

> **REQ-DISP-PI4-SPD-006** The pilot shall be able to set the speed bug via numpad entry by tapping the readout button.

> **REQ-DISP-PI4-SPD-007** The airspeed source shall be selectable from the AHRS / Sensors sub-menu. The selectable options shall be `IAS SENSOR` (SDP33-1500Pa with BME280 density correction, sourced from the AHRS `ias_kt` field) and `GPS GS` (GPS groundspeed, sourced from `speed`). The default selection shall be `IAS SENSOR`, with automatic fallback to `GPS GS` when `airdata_ok = False`.

> **REQ-DISP-PI4-SPD-008** When the active airspeed source falls back from `IAS SENSOR` to `GPS GS` (sensor failure, missing baro, or `airdata_ok` cleared), the speed tape, drum, and bug shall recolour from cyan to magenta to communicate the source change without an explicit banner. No additional alert is required: the colour convention is the same as the altitude tape's baro/GPS fallback indication.

---

## 6. Altitude Tape and VSI

> **REQ-DISP-PI4-ALT-001** The altitude tape shall display a Veeder-Root drum readout advancing in 50 ft increments.

> **REQ-DISP-PI4-ALT-002** An altitude bug chevron shall be rendered at the currently set target altitude.

> **REQ-DISP-PI4-ALT-003** The altitude bug and readout button shall be CYAN when barometric, MAGENTA when GPS-derived.

> **REQ-DISP-PI4-ALT-004** The baro setting button shall display the current QNH in CYAN when the barometric sensor is active, or `GPS ALT` in MAGENTA when absent.

> **REQ-DISP-PI4-ALT-005** The pilot shall be able to enter a QNH baro setting via numpad in either inHg or hPa.

> **REQ-DISP-PI4-ALT-006** The altitude bug shall be settable by tapping the readout button or by tapping directly on the altitude tape.

> **REQ-DISP-PI4-ALT-007** A vertical speed indicator bar shall run along the inner edge of the altitude tape, scaled to ±2000 fpm, turning amber above ±1500 fpm.

---

## 7. Attitude Indicator and Synthetic Vision

The attitude indicator on the Pi 4 variant provides full 3D Synthetic Vision Terrain rendering, including terrain features visible above the horizon line.

> **REQ-DISP-PI4-AI-001** The SVT terrain background shall be rendered using a 3D perspective projection from the aircraft's current position (latitude, longitude, altitude) looking along the current heading vector.

> **REQ-DISP-PI4-AI-002** Terrain features whose elevation exceeds the aircraft's current altitude shall be visible above the horizon line as mountain peaks and ridges, rendered in correct geometric perspective.

> **REQ-DISP-PI4-AI-003** The terrain mesh shall be constructed from SRTM elevation data within a configurable radius of the aircraft position. Default radius shall be 20 nautical miles, with configurable altitude-scaled mode available (radius scales with √altitude, clamped between 10 and 40 nautical miles).

> **REQ-DISP-PI4-AI-004** The terrain mesh shall update at a minimum rate of 10 Hz to ensure smooth visual tracking during turns and altitude changes. Mesh rebuilds shall be cached and triggered only when aircraft position moves by more than ~0.3 nm or altitude changes by more than 200 ft.

> **REQ-DISP-PI4-AI-005** Terrain shall be coloured by clearance relative to the aircraft altitude using the following palette: red for terrain above aircraft altitude, deep orange for 0–100 ft clearance, amber for 100–500 ft, brown for 500–1000 ft, dark brown for 1000–2000 ft, and very dark brown for clearance greater than 2000 ft.

> **REQ-DISP-PI4-AI-006** When SRTM terrain tiles are not present, a plain horizon shall be displayed using a solid blue upper half and solid brown lower half.

> **REQ-DISP-PI4-AI-007** A sky gradient background shall be rendered behind the terrain mesh, darker at zenith and lighter near the horizon. The sky/ground boundary in the background shader shall rotate with aircraft roll to match the terrain mesh orientation at any bank angle.

> **REQ-DISP-PI4-AI-008** Beyond the mesh radius, the rendering shall transition smoothly to a dusty atmospheric-haze gradient (lighter at horizon, darker deep) so that there is no visible seam between the mesh edge and the distant view.

> **REQ-DISP-PI4-AI-009** Directional sun-angle lighting shall be applied to the terrain mesh using a Lambertian diffuse model. Slopes facing the sun shall appear brighter; slopes in shadow shall darken toward a configurable ambient level. Sun azimuth, elevation, intensity, and ambient level shall be configurable in the renderer module.

> **REQ-DISP-PI4-AI-010** A cardinal-aligned distance grid shall be overlaid on the terrain. Minor lines shall be drawn every 0.5 nautical miles; major lines every 2 nautical miles. Grid line width shall be anti-aliased and constant in screen space regardless of distance.

> **REQ-DISP-PI4-AI-011** Distance grid line colour shall be contrast-aware: light cyan-white on safe-clearance terrain, dark blue on caution/warning terrain (red/orange zones). Line intensity shall boost automatically over red zones so the lines remain clearly visible.

> **REQ-DISP-PI4-AI-012** The distance grid shall fade to invisible at the mesh edge to avoid clutter at the haze transition.

> **REQ-DISP-PI4-AI-013** A zero-pitch reference line shall be drawn across the attitude indicator as a pair of cyan hash marks with a gap for the aircraft symbol. The line shall offset vertically with pitch (drop below centre for positive pitch, rise above centre for negative pitch) using a scale of 10 pixels per degree matching the pitch ladder, and shall rotate around the AI centre with aircraft roll.

> **REQ-DISP-PI4-AI-014** The SVT vertical field of view shall be 48° so that the pitch ladder bars, the zero-pitch reference line, and the SVT horizon all align at the same screen position for any given pitch angle.

> **REQ-DISP-PI4-AI-015** Pitch ladder lines shall be drawn at ±5°, ±10°, ±15°, ±20°, and ±30° from the horizon, consistent with GI-275 styling. The pitch ladder 0° bar shall coincide with the zero-pitch reference line.

> **REQ-DISP-PI4-AI-016** A roll arc shall be rendered implementing the sky-pointer convention. The arc, tick marks (10°, 20°, 30°, 45°, 60°), and outer doghouse marker shall rotate with the sky so that a fixed aircraft reference inside the arc reads the current bank angle on the graduated scale.

> **REQ-DISP-PI4-AI-017** A slip/skid ball indicator shall deflect laterally in proportion to lateral acceleration (`ay`).

> **REQ-DISP-PI4-AI-018** A fixed amber delta-wing aircraft symbol shall be rendered at the centre of the attitude indicator.

---

## 8. Heading Tape and Source Modes

> **REQ-DISP-PI4-HDG-001** A heading tape shall scroll horizontally across the bottom of the display with cardinal and intercardinal labels.

> **REQ-DISP-PI4-HDG-002** A central heading box shall display the current heading as a 3-digit value with degree symbol.

> **REQ-DISP-PI4-HDG-003** A subscript `M` (magnetometer) or `G` (GPS track) shall appear in the heading box.

> **REQ-DISP-PI4-HDG-004** In GPS TRK mode, the heading box border shall be MAGENTA.

> **REQ-DISP-PI4-HDG-005** GPS TRK mode shall slave the heading to GPS ground track using a complementary filter (K = 0.05 default).

> **REQ-DISP-PI4-HDG-006** A heading bug shall be rendered on the tape, colour-coded by heading source (CYAN for MAG, MAGENTA for GPS TRK).

> **REQ-DISP-PI4-HDG-007** The heading bug shall be settable via numpad or by tapping the heading tape.

> **REQ-DISP-PI4-HDG-008** A CYAN GPS ground track tick mark shall be rendered on the heading tape when in MAG mode with valid GPS fix.

---

## 9. Terrain and Obstacle Proximity Alerting

> **REQ-DISP-PI4-TAWS-001** A TERRAIN CAUTION banner (amber, steady) shall be displayed when terrain or an obstacle is within 500 ft below aircraft altitude.

> **REQ-DISP-PI4-TAWS-002** A PULL UP / TERRAIN banner (red, 1 Hz flash) shall be displayed when terrain or an obstacle is within 100 ft below aircraft altitude.

> **REQ-DISP-PI4-TAWS-003** Obstacle proximity alerting shall activate within 3 nautical miles of the aircraft.

> **REQ-DISP-PI4-TAWS-004** SRTM terrain tiles shall be downloadable from within the PFD user interface.

> **REQ-DISP-PI4-TAWS-005** FAA Digital Obstacle File data shall be downloadable from within the PFD user interface, with a 28-day expiry indication.

> **REQ-DISP-PI4-TAWS-006** Terrain-clearance alerting shall use a look-ahead along the current GPS ground track of at least 45 seconds at the current ground speed, sampled at no fewer than 12 points and with altitude projected forward by the current vertical speed. The worst (minimum) projected clearance along the look-ahead shall determine the alert level.

> **REQ-DISP-PI4-TAWS-007** Obstacle proximity alerting shall be gated by a forward-facing wedge of ±25° around the GPS ground track. Obstacles abeam or behind the wing shall not trigger the alert, regardless of their absolute clearance.

> **REQ-DISP-PI4-TAWS-008** Both terrain and obstacle alerting (visual banners and audio callouts) shall be inhibited when ground speed is below the pilot-configured VS0 stall speed. This inhibit shall apply uniformly to all alert classes (TERRAIN, OBSTACLE, SINK RATE, PULL UP) to silence false fires during taxi, takeoff roll, and landing rollout.

> **REQ-DISP-PI4-TAWS-009** A SINK RATE caution (audio only; the banner band is owned by TERRAIN / OBSTACLE) shall fire when the aircraft is below 2 500 ft AGL and the descent rate exceeds an AGL-scaled threshold curve: 1 500 fpm at the surface, rising linearly to approximately 5 000 fpm at 2 500 ft AGL. This implements the GPWS Mode 1 (excessive descent rate) callout.

> **REQ-DISP-PI4-TAWS-010** When a synthetic approach is active and the aircraft is inside the published-approach corridor, the terrain look-ahead, obstacle proximity, and pull-up alerts shall be auto-inhibited. The approach corridor shall be defined as: along-track within −0.5 NM to +5.0 NM of the threshold along the published course, cross-track within ±0.3 NM of the centreline, and altitude between threshold elevation and threshold elevation + 2 500 ft. The SINK RATE callout (REQ-DISP-PI4-TAWS-009) shall remain armed inside the corridor — sink rate is the one alert that stays relevant on a stabilised approach. Aircraft outside the corridor on any axis shall re-arm all alerts immediately.

> **REQ-DISP-PI4-TAWS-011** The AHRS / Sensors setup screen shall provide a pilot-controlled TERRAIN INHIBIT button. When tapped, terrain look-ahead, obstacle, and pull-up callouts shall be muted for 120 seconds; SINK RATE shall remain armed. A second tap shall clear the inhibit immediately. The inhibit shall auto-clear when the 120 s timer expires, so a forgotten toggle cannot permanently disable the TAWS safety net.

> **REQ-DISP-PI4-TAWS-012** While the manual TERRAIN INHIBIT (REQ-DISP-PI4-TAWS-011) is active, the status badge strip shall display `TER INH Xs` in amber, where X is the integer number of seconds remaining on the 120 s timer.

> **REQ-DISP-PI4-TAWS-013** While the approach-corridor auto-inhibit (REQ-DISP-PI4-TAWS-010) is gating TAWS callouts, the status badge strip shall display `TER INH APR` in amber, so the pilot can see at a glance that the safety net is off and that the cause is the active approach (not a stuck manual inhibit). When both inhibits are active simultaneously the manual `TER INH Xs` countdown shall take precedence on the badge label, since the countdown is the more actionable cue.

---

## 9A. Airport Display

The display unit shall show nearby airports on the attitude indicator to provide the pilot with immediate situational awareness of emergency-landing options, navigation references, and surrounding airspace structure.

> **REQ-DISP-PI4-APT-001** Airports within a configurable radius of the aircraft (default 20 nm) shall be rendered on the attitude indicator as small symbols projected into the 3D view using the same perspective-projection scale as the pitch ladder and SVT.

> **REQ-DISP-PI4-APT-002** Airport symbol style shall encode airport type:
>
> - Public airport (small / medium / large) — cyan ring with dark centre; a second outer ring shall be added for medium and large airports
> - Heliport — magenta letter "H"
> - Seaplane base — cyan circle with a wavy underscore
> - Balloonport — grey triangle

> **REQ-DISP-PI4-APT-003** The airport identifier (ICAO/local code) shall be rendered within a closer configurable range (default 15 nm) as a "road sign" — a dark-filled, coloured-bordered text box mounted on a thin vertical post anchored at the airport symbol. The post shall lift the sign clear of the airport symbol so the label remains legible against busy terrain. The sign border colour shall match the symbol colour (cyan for public airports, magenta for heliports, etc.). The sign shall be auto-sized to the rendered text width plus padding, and shall be clamped to remain within the AI rectangle when the airport is near the top of the visible area.

> **REQ-DISP-PI4-APT-004** Airports with relative bearing outside the attitude indicator's angular field of view shall be culled so that no symbol appears clipped at the edge of the AI rectangle.

> **REQ-DISP-PI4-APT-005** Airport symbols shall be drawn before obstacle symbols in the Z-order so that close-in towers and obstructions appear on top of airport symbols at the same screen position.

> **REQ-DISP-PI4-APT-006** The airport database shall be the OurAirports global CSV (field-accurate latitude, longitude, elevation, and type for approximately 72,000 airports worldwide). Closed airports and records with missing coordinates shall be filtered out at parse time.

> **REQ-DISP-PI4-APT-007** The airport database shall be downloadable from within the PFD user interface via a dedicated AIRPORT DATA screen. The screen shall show record count, disk usage, age in days since last download, and shall indicate an expired dataset when older than AIRPORT_EXPIRY_DAYS (default 60 days).

> **REQ-DISP-PI4-APT-008** Downloaded airport CSV shall be parsed into a NumPy structured-array cache (.npy) on first access so that subsequent PFD launches load the database without re-parsing the text CSV.

> **REQ-DISP-PI4-APT-009** A `NO APT` status badge (amber) shall be displayed when no airport data is loaded. An `EXP APT` status badge (orange) shall be displayed when the loaded airport data is older than the configured expiry.

> **REQ-DISP-PI4-APT-010** The AIRPORT DATA screen shall provide four independently toggleable display filters controlling which airport types render on the attitude indicator:
>
> - PUBLIC — small / medium / large public-use airports (default: on)
> - HELIPORTS — heliports (default: on)
> - SEAPLANE — seaplane bases (default: off)
> - OTHER — balloonports and uncategorised types (default: off)
>
> Filter state shall persist across the session. When all four filters are off, no airport symbols shall render.

> **REQ-DISP-PI4-APT-011** Runway polygons for airports within 8 NM shall be projected onto the attitude indicator from each runway's low-end and high-end threshold lat/lon/elevation, using the same flat-earth atan2 bearing/elevation projection as airport and obstacle symbols. Polygons shall scale with runway width (derived from `runways.csv`) and translate/scale/rotate correctly with aircraft position, heading, pitch, and roll. The runway database shall be the OurAirports `runways.csv` (approximately 14,700 records globally), parsed into a NumPy structured-array cache (`runways_cache.npy`) analogous to the airport cache. Closed runways shall be filtered out at parse time. Runway polygons shall be drawn before airport symbols in the Z-order so that the cyan airport ring appears on top of the runway asphalt at the airport centre.
>
> A `RUNWAYS` toggle on the AIRPORT DATA screen shall enable or disable runway rendering (default: on). Toggle state shall persist across power cycles via the settings persistence layer.

> **REQ-DISP-PI4-APT-012** Extended dashed centerlines shall be rendered outward from each runway threshold along the runway bearing, for airports within 15 NM. Each centerline shall extend 10 NM from the threshold with 0.5 NM dash segments. Extended centerlines shall not render when the aircraft is between the two thresholds of the same runway.
>
> An `EXT CENTERLINES` toggle on the AIRPORT DATA screen shall enable or disable extended centerlines independently of the runway polygons (default: on). Toggle state shall persist across power cycles via the settings persistence layer.

> **REQ-DISP-PI4-APT-013** The runway polygon shall be clipped to the aircraft's forward half-plane via Sutherland-Hodgman against the perpendicular line through the aircraft. When the aircraft is on / past one threshold (taxi, takeoff roll, landing rollout, low fly-over), the half behind the wing line shall be discarded and the half ahead shall continue to render — the polygon shall not all-or-nothing disappear when one corner crosses the rear of the aircraft.

> **REQ-DISP-PI4-APT-014** Runway-number labels shall be gated per-end by an actual forward-distance check on the threshold lat/lon. Labels shall stop drawing the moment the corresponding threshold passes the wing line, rather than floating on the runway surface where the clip-derived midpoint landed.

> **REQ-DISP-PI4-APT-015** The airport-environment box (green frame around the runway polygon) shall be suppressed when the aircraft is within 2 NM of the runway centroid AND under 500 ft above the threshold elevation. Close-in the box's far corners foreshorten enough that the rectangle reads as broken; the runway polygon itself is the primary cue at that range.

> **REQ-DISP-PI4-APT-016** Obstacle rendering shall apply an airport-boundary clutter filter: obstacles shorter than `_OBS_AIRPORT_FLOOR_FT` (50 ft) AGL within `_OBS_AIRPORT_RADIUS_NM` (1.0 NM) of any runway centroid shall be hidden. This suppresses the dense low-AGL terminal / ramp infrastructure (signs, jetway masts, terminal cornices, taxiway lighting) that otherwise paints across the runway visual at busy fields. Tall airport obstructions like ATC towers (typically 200+ ft) clear the floor and remain visible.

> **REQ-DISP-PI4-APT-017** Obstacles shall additionally be subject to a global `_OBS_MIN_AGL_FT` (25 ft) AGL floor regardless of airport proximity, so airport-surface signs and similar trivial obstructions never render.

> **REQ-DISP-PI4-APT-018** Obstacle labels shall display the obstacle's true MSL top elevation in feet (e.g. `1185`) rather than a bucketed-to-100-ft form. The label format shall make clear the value represents an altitude (MSL) not a height (AGL).

> **REQ-DISP-PI4-APT-019** Obstacle vertical-angle projection shall use the real (sensor) altitude, NOT the camera-floor-clamped `alt_render`. Using the clamped value at low altitudes (when alt_render exceeds real alt to keep the SVT camera above terrain) produces obstacles projected below their actual top angle and made them appear stamped onto the runway visual at major fields like PHX.

---

## 9B. Direct-to Navigation

> **REQ-DISP-PI4-NAV-001** The display shall provide a direct-to navigation feature accessible by tapping the CDI strip above the heading box (live PFD) or the DIRECT TO tile on the AIRPORT DATA screen.

> **REQ-DISP-PI4-NAV-002** A keyboard for waypoint entry shall open with the existing active ident (if any) shown as a dim placeholder under an empty input buffer. The first keystroke shall replace the placeholder rather than appending to it.

> **REQ-DISP-PI4-NAV-003** Pressing ENTER on the keyboard with a non-empty buffer shall validate the typed ident against the airport database. On a match, a centered modal "Activate Direct to *XXXX*?" with CANCEL / ACTIVATE buttons shall be shown. Tapping ACTIVATE (or pressing physical ENTER) shall commit the activation; tapping CANCEL (or pressing ESC) shall dismiss.

> **REQ-DISP-PI4-NAV-004** Pressing ENTER on an empty buffer with an active waypoint loaded shall offer to re-activate the existing waypoint via the same confirmation modal. Re-activation shall reset `act_lat`/`act_lon` to the current aircraft position so the magenta course line redraws from the present position.

> **REQ-DISP-PI4-NAV-005** Pressing ENTER on an unknown ident shall keep the keyboard open with a red "UNKNOWN WAYPOINT *XXXX*" hint under the entry field. Any subsequent keystroke or backspace shall clear the error.

> **REQ-DISP-PI4-NAV-006** A NEAREST quick-button shall be available on the waypoint keyboard. The button label shall display the resolved nearest public airport's ident (S/M/L type within 100 NM of current position, refreshed approximately every 2 s). Tapping shall route through the same Activate? confirmation modal.

> **REQ-DISP-PI4-NAV-007** A magenta course-trace line shall be drawn on the attitude indicator from the activation point to the destination waypoint along the great-circle path, draped over SRTM terrain at a 200 ft offset above the maximum local elevation. Vertices shall be sampled at 0.2 NM intervals (capped at 1000 vertices per course) with rolling-max smoothing so the line never dips below terrain between sample points.

> **REQ-DISP-PI4-NAV-008** The course trace shall be built asynchronously in a background daemon thread and published progressively as samples are computed, so the UI remains responsive during long cross-country activations. If the user changes the active waypoint mid-build, the in-flight worker shall discard its result on detecting the key mismatch.

> **REQ-DISP-PI4-NAV-009** A CDI (Course Deviation Indicator) strip above the heading box shall display ident · bearing · distance and a magenta diamond at full-scale cross-track error. The diamond shall display on the side OPPOSITE the course relative to the aircraft (right-of-course → diamond LEFT, indicating "fly left to intercept"). When no waypoint is active the strip shall display a "DIRECT →" prompt as a tap target.

> **REQ-DISP-PI4-NAV-010** CDI full-scale deflection shall be mode-dependent: ±1.0 NM in en-route / direct-to mode, and ±0.3 NM (RNAV / LPV convention) when a synthetic approach (REQ-DISP-PI4-APPR-001 et seq.) is active.

> **REQ-DISP-PI4-NAV-011** When a synthetic approach is active, the CDI cross-track reference shall be the extended runway centreline (a line through the threshold along the published runway course), NOT the line from the activation point to the threshold. The activation point shall continue to define the cross-track reference in en-route / direct-to mode.

> **REQ-DISP-PI4-NAV-012** When a synthetic approach is active, the CDI ident readout shall append the runway suffix to the airport ident in `IDENT/RWY` form (e.g. `KSEZ/03`).

---

## 9D. Synthetic Approach (HITS + VDI)

The display unit shall provide a synthetic approach capability that loads a 3° glideslope to a selected runway and surfaces three coordinated cues — Highway-In-The-Sky (HITS) tunnel boxes, a vertical glideslope diamond (VDI), and tightened CDI scaling.

> **REQ-DISP-PI4-APPR-001** A synthetic approach shall be activatable from the waypoint keyboard via an **APPR** button. The APPR button shall be visible only when the entered ident matches an airport with one or more runway records loaded.

> **REQ-DISP-PI4-APPR-002** Tapping APPR shall open a runway-end picker listing each end (ident, course, length). Tapping a runway tile shall activate the approach: HITS boxes draw, the VDI paints, the CDI rescales per REQ-DISP-PI4-NAV-010, the magenta direct-to course trace is suppressed, and the airport ident readout transitions to `IDENT/RWY` form.

> **REQ-DISP-PI4-APPR-003** A **CANCEL APPROACH** button shall be present at the bottom of the runway picker when an approach is currently active. Tapping shall clear the approach and revert to plain direct-to to the airport, restoring CDI scaling and the magenta course trace.

> **REQ-DISP-PI4-APPR-004** HITS boxes shall be cyan rectangular polylines drawn along the published 3° glideslope, with the box centre on the glideslope (pilot eye-line through box centre). Default geometry: 300 ft wide × 200 ft tall, spaced 1000 ft apart, starting one spacing-step outside the threshold and continuing to 5 NM final. All values configurable in `pi4/hits.py`.

> **REQ-DISP-PI4-APPR-005** HITS boxes shall be rendered through the same depth-tested polyline pipeline used for the magenta direct-to course trace, so terrain and obstacles correctly occlude boxes that would otherwise paint through intervening ridges.

> **REQ-DISP-PI4-APPR-006** While a synthetic approach is active, the magenta direct-to course trace on the AI shall be hidden. HITS boxes are mutually exclusive with the magenta trace.

> **REQ-DISP-PI4-APPR-007** A Vertical Deviation Indicator (VDI) shall be rendered as a vertical bar with a magenta diamond on the right side of the AI, just inside the altitude tape. The VDI shall paint only when a synthetic approach is active.

> **REQ-DISP-PI4-APPR-008** VDI deviation shall be the elevation-angle error from a 3° glideslope to the threshold:
> `dev_deg = atan2(alt − thresh_elev, dist_ft) − 3°`.
> Full-scale deflection shall be ±0.7° (LPV / ILS convention). The diamond shall move DOWN when the aircraft is above the GS (glideslope below — fly down to the diamond) and UP when below the GS.

> **REQ-DISP-PI4-APPR-009** The moving-map inset's course trace shall switch colour: cyan while a synthetic approach is active (matching HITS / VDI / CDI), magenta otherwise. While approach is active the trace shall be drawn from the threshold along the reciprocal of the published course (the actual extended centreline), NOT from the activation point.

> **REQ-DISP-PI4-APPR-010** The moving-map inset's ETE label shall be coloured cyan in approach mode and magenta in direct-to mode, matching the active trace colour.

---

## 9E. Audio Alerts (EGPWS-style voice callouts)

The Pi 4 display shall provide aviation-style voice callouts coordinated with the visual TAWS / obstacle / attitude alerts.

> **REQ-DISP-PI4-AUD-001** The PFD shall play short, pre-rendered voice callouts through the system audio output for the following conditions, with phrasing chosen to identify the alert source rather than emit a generic tone:
>
> | Trigger | Callout | Band |
> |---------|---------|------|
> | Terrain look-ahead clearance < 500 ft | `Terrain. Terrain.` | Caution |
> | Obstacle in the ±25° forward wedge with clearance < 500 ft | `Obstacle. Obstacle.` | Caution |
> | Descent rate exceeding the AGL-scaled threshold curve (REQ-DISP-PI4-TAWS-009) | `Sink rate. Sink rate.` | Caution |
> | Terrain look-ahead clearance < 100 ft | `Terrain. Terrain. Pull up. Pull up.` | Warning |
> | Obstacle in the ±25° forward wedge with clearance < 100 ft | `Obstacle. Obstacle. Pull up. Pull up.` | Warning |
> | Absolute bank > 60° with AHRS healthy and simulator not paused | `Bank angle. Bank angle.` | Attention |

> **REQ-DISP-PI4-AUD-002** Callout phrases shall be generated once at first run using a text-to-speech engine (default: `espeak`) and cached on disk so subsequent boots can play the clips with no synthesis cost.

> **REQ-DISP-PI4-AUD-003** When multiple alert conditions are satisfied in the same frame, only the highest-priority callout shall be played. Priority order, highest first: obstacle pull-up, terrain pull-up, sink rate, obstacle caution, terrain caution, bank angle.

> **REQ-DISP-PI4-AUD-004** Each callout shall be rate-limited by a minimum repeat interval — warning-band callouts (the `Pull up` variants) at no less than 4 s, caution-band and bank-angle callouts at no less than 3 s. New triggers within the hold-off window shall be silently dropped, not queued.

> **REQ-DISP-PI4-AUD-005** The DISPLAY setup screen shall expose an `ALERT AUDIO` master mute (OFF / ON, default ON) that suppresses all callouts when OFF, and an `ALERT VOLUME` control (1–10) that applies a linear volume multiplier to every loaded callout. Both settings shall persist across power cycles via the settings persistence layer.

> **REQ-DISP-PI4-AUD-006** The PFD shall fire one self-test callout (`Terrain. Terrain.`) at startup when `ALERT AUDIO` is ON, so that speaker continuity and the audio pipeline state can be confirmed without a real alert.

> **REQ-DISP-PI4-AUD-007** Audio initialization shall not block the PFD render loop: if the mixer cannot be opened, the audio module shall log a diagnostic and silently no-op subsequent `play()` calls. The visual alert pipeline shall continue to operate unaffected.

> **REQ-DISP-PI4-AUD-008** The audio module shall force the SDL audio backend to ALSA before pygame imports so that an `~/.asoundrc` redirect to a specific device (e.g. HDMI panel speakers via `plughw:1,0`) is honoured.

---

## 9F. Unusual-Attitude Recovery Cues

When the aircraft enters an extreme attitude, the PFD shall declutter to a minimum legible set and overlay red recovery glyphs centred on the aircraft symbol.

> **REQ-DISP-PI4-UA-001** Unusual-attitude declutter shall trigger when absolute pitch exceeds 30° or absolute roll exceeds 60°. While active, the SVT terrain mesh, water mask, airport / runway / obstacle / direct-to overlays shall all be suppressed, leaving only the sky/ground polygon, the pitch ladder, the aircraft symbol, and the recovery glyphs visible.

> **REQ-DISP-PI4-UA-002** A vertical chevron stack (three filled red chevrons) shall be drawn centred on the aircraft symbol whenever |pitch| > 30°. The stack shall point downward when pitch is nose-high (push to recover) and upward when pitch is nose-low (pull to recover). The midline of the stack shall coincide exactly with the aircraft symbol so the pilot's eye does not need to leave AI centre to read the cue.

> **REQ-DISP-PI4-UA-003** A curved red arrow shall be drawn sweeping over the aircraft symbol whenever |roll| > 60°. The arc shall sweep counter-clockwise when right wing is low (roll left to recover) and clockwise when left wing is low (roll right to recover). The arc radius shall be large enough that the glyph reads as a frame around the pitch chevrons rather than colliding with them, and shall scale with the AI region's short dimension.

> **REQ-DISP-PI4-UA-004** Both glyphs shall be drawable simultaneously when both pitch and roll exceed their respective thresholds.

> **REQ-DISP-PI4-UA-005** The PFD shall correctly express attitudes outside ±90° pitch by re-folding them into the renderer's expected Euler chart (pitch ′ = 180° − pitch; roll ′ = roll + 180°), so that over-the-top loops, split-S manoeuvres, and aerobatic inverted flight remain continuously drawable.

> **REQ-DISP-PI4-UA-006** When the terrain mesh is suppressed (no SRTM tiles, or unusual-attitude declutter), the sky/ground polygon shall be drawn from a roll-aware horizon direction vector so that the brown half of the AI always corresponds to the actual ground side, including past ±90° bank.

---

## 9G. Backlight Control

> **REQ-DISP-PI4-BL-001** The PFD shall provide a brightness control (1–10) on the DISPLAY setup screen, persisted across power cycles, that drives whichever backlight transport is available on the host hardware.

> **REQ-DISP-PI4-BL-002** The PFD shall attempt to control panel brightness through, in order of preference: (a) the `/sys/class/backlight/*/brightness` sysfs node, (b) DDC/CI VCP code 0x10 (luminance) over an i2c-N bus matching a DDC-capable HDMI display, (c) no-op if neither is available.

> **REQ-DISP-PI4-BL-003** DDC/CI writes shall be executed on a background thread under a serialising lock so that brightness adjustments do not block the render loop and concurrent writes do not collide on the I²C bus.

> **REQ-DISP-PI4-BL-004** Diagnostic log lines at startup shall report which backlight transport is in use, or that no transport could be selected.

---

## 9C. AGL Readout

> **REQ-DISP-PI4-AGL-001** A small AGL readout box shall be displayed in the lower-right corner of the attitude indicator, between the altitude tape (right edge) and the heading tape (top edge). Box size: 78 × 42 px on the 1024×600 display. Layout: dim "AGL" label on top line, numeric value (white) on bottom line.

> **REQ-DISP-PI4-AGL-002** AGL value = (real sensor altitude) − (SRTM ground elevation at current lat/lon). The real (unclamped) altitude shall be used, NOT the camera-floor-clamped `alt_render`, so a punched-ground state surfaces as a sanity-check warning rather than being silently clamped to ≥0.

> **REQ-DISP-PI4-AGL-003** When the computed AGL is at or below 0, the readout shall display dashes ("---") in dim grey rather than a misleading negative number. When there is no GPS fix or the SRTM lookup returns the missing-tile sentinel, the readout shall be hidden entirely.

---

## 9a. User Settings Persistence

> **REQ-DISP-PI4-PERSIST-001** User-adjusted settings shall persist across power cycles via a JSON file at `pi4/data/settings.json`. Persisted values shall include: flight profile (V-speeds, tail number, aircraft type, TAS offset), display settings (brightness, baro unit, speed unit, altitude unit, colour scheme), system settings, connectivity settings (Wi-Fi SSID excluding password), airport-data display filters (PUBLIC / HELIPORTS / SEAPLANE / OTHER / RUNWAYS / EXT CENTERLINES), heading bug, altitude bug, and last-used display mode.

> **REQ-DISP-PI4-PERSIST-002** Settings writes shall be debounced and performed on a background thread (default 1.5 s coalesce window) so that rapid consecutive toggle changes produce at most one file write. Writes shall be atomic via `os.replace` from a `.tmp` file so that a power-loss during write cannot corrupt `settings.json`.

> **REQ-DISP-PI4-PERSIST-003** The Wi-Fi password shall not be written to `settings.json`. Any other security-sensitive values explicitly listed in the persistence skip-list shall be excluded similarly.

> **REQ-DISP-PI4-PERSIST-004** On shutdown, pending settings changes shall be flushed synchronously so that no user-visible change is lost on a graceful exit.

---

## 10. Status Badges

> **REQ-DISP-PI4-BADGE-001** Status badges shall appear only when a condition requires pilot attention.

> **REQ-DISP-PI4-BADGE-002** Required badges: `AHRS FAIL` (red), `NO LINK` (red), `NO TER` (amber), `NO OBS` (amber), `EXP OBS` (orange), `NO APT` (amber), `EXP APT` (orange), `GPS TRK` (magenta), `GPS ALT` (amber), `GPS Nsat` (amber), `NO GPS` (red).

---

## 11. Colour Coding — Data Source Convention

> **REQ-DISP-PI4-COLOR-001** GPS-derived values and controls shall be MAGENTA.

> **REQ-DISP-PI4-COLOR-002** Onboard-sensor-derived values and controls shall be CYAN.

> **REQ-DISP-PI4-COLOR-003** The colour convention shall apply to: speed bug/button, altitude bug/button, baro button, heading bug/button, heading box border, and heading source subscript.

---

## 12. Setup and Configuration

> **REQ-DISP-PI4-SETUP-001** The setup menu shall be opened by a two-finger press-and-hold for at least 0.8 seconds.

> **REQ-DISP-PI4-SETUP-002** Sub-menus: Flight Profile, Display, AHRS / Sensors, Connectivity, System.

> **REQ-DISP-PI4-SETUP-003** Factory default V-speeds: VS0=48, VS1=55, VFE=85, VNO=129, VNE=163 (Cessna 172S).

> **REQ-DISP-PI4-SETUP-004** Display units independently selectable for speed (kt/mph/kph), altitude (ft/m), pressure (inHg/hPa).

> **REQ-DISP-PI4-SETUP-005** Backlight brightness adjustable in 10 steps.

> **REQ-DISP-PI4-SETUP-006** Pitch and roll trim shall be independently settable in 0.1° increments via on-screen ± steppers.

> **REQ-DISP-PI4-SETUP-007** AHRS mounting orientation shall be selectable from FORWARD / LEFT / RIGHT / AFT (which side of the AHRS the connector points toward, viewed from the pilot's seat). Default RIGHT. The display shall remap pitch / roll axes and apply a magnetic heading offset such that the displayed values match the aircraft's frame regardless of physical mounting.

> **REQ-DISP-PI4-SETUP-008** AHRS NORMAL / INVERTED mounting shall combine independently with orientation to support upside-down installations.

> **REQ-DISP-PI4-SETUP-009** AHRS firmware reports yaw and roll with an ENU sign convention; the display shall negate both at the base before applying orientation, mounting, and trim transforms so MAG-mode heading reads CW-positive and roll reads right-wing-down-positive.

> **REQ-DISP-PI4-SETUP-010** Sim and Demo modes shall bypass all AHRS-mounting compensations (orientation rotation, mounting flip, base ENU→NED correction, pitch/roll trim, compass cal). Synthetic data is generated in aircraft-frame NED; applying mounting transforms would double-flip values.

> **REQ-DISP-PI4-SETUP-011** A compass-calibration wizard shall be available from the AHRS / Sensors screen. Implementation: cardinal walk-through capturing the (expected − raw) heading delta at NORTH / EAST / SOUTH / WEST. Persistence: four signed deltas stored in `data/settings.json`. Render application: piecewise-linear interpolation between adjacent cardinals so each 90° quadrant has its own correction curve. RESET shall wipe the stored cal back to zero.

> **REQ-DISP-PI4-SETUP-012** The compass cal correction shall apply only to MAG-mode heading. TRK mode shall remain GPS-track-slaved (the complementary filter operates on yaw deltas, where a constant cal correction's frame-to-frame derivative is negligible).

> **REQ-DISP-PI4-SETUP-013** Heading source AUTO mode shall use TRK when ground speed is above ~3 kt, MAG otherwise.

> **REQ-DISP-PI4-SETUP-014** A systemd service (`pfd.service`) shall be installed and enabled by `setup.sh`. The service shall auto-start the PFD on every power-up using `SDL_VIDEODRIVER=kmsdrm` for OpenGL ES compatibility, with `SupplementaryGroups=video render input` for KMS/DRM device access, and `StartLimitIntervalSec=0` to keep retrying after transient crashes. A separate refresh helper (`tools/install_autostart.sh`) shall be available to update just the unit definition without re-running the full installer.

---

## 13. Flight Simulator

> **REQ-DISP-PI4-SIM-001** The display shall include a built-in flight simulator driving all PFD instruments through an internal autopilot model.

> **REQ-DISP-PI4-SIM-002** 12 preset departure airports across the US.

> **REQ-DISP-PI4-SIM-003** Failure injection: GPS, baro, and AHRS failures independently toggleable.

> **REQ-DISP-PI4-SIM-004** A `SIM` watermark shall be displayed during simulator operation; tapping it opens SIM CONTROLS.

> **REQ-DISP-PI4-SIM-005** The autopilot model shall respond to heading, altitude, and speed bug changes in real time.

> **REQ-DISP-PI4-SIM-006** The simulator shall offer two AP follow modes selectable from SIM CONTROLS: **FOLLOW BUGS** (default — pure heading / altitude / speed bug tracker) and **FOLLOW FLT PLAN** (couples the AP to the active direct-to or synthetic approach, overriding the heading bug for course intercept and the altitude bug for glideslope tracking).

> **REQ-DISP-PI4-SIM-007** In FOLLOW FLT PLAN mode the AP shall fly a 45°-max-intercept course-capture profile to the active D2 line (en-route) or the extended runway centreline (approach). Tuning shall switch on approach-active state: gentle band 0.3 → 0.1 NM, full-intercept threshold 1.5 → 0.5 NM, and inner-band gain raised so the AP settles on centreline at the ±0.3 NM CDI scale.

> **REQ-DISP-PI4-SIM-008** In FOLLOW FLT PLAN mode with a synthetic approach active, the AP shall capture the glideslope only from above. While below the GS, the AP shall hold current altitude (it shall NOT command a climb to chase the GS). Approach-mode altitude tracking shall include a feedforward of the GS descent rate (`V × tan(3°)`) and a higher closed-loop gain than en-route altitude hold so the diamond centres without persistent lag.

> **REQ-DISP-PI4-SIM-009** The simulated airplane shall be a coordinated-turn model: bank shall be the only AP-commanded quantity, and yaw rate shall be derived from bank via `ω = g·tan(φ)/V`. Yaw shall not be commanded independently of bank under any condition; zero bank shall produce zero yaw.

> **REQ-DISP-PI4-SIM-010** SIM CONTROLS shall include an EXIT SETUP button so the pilot can leave the SIM CONTROLS overlay without ending the simulator.

---

## 14. Demo Mode

> **REQ-DISP-PI4-DEMO-001** A scripted demo mode shall animate a flight over Sedona, Arizona, driving all instruments without hardware.

> **REQ-DISP-PI4-DEMO-002** Demo mode shall be launchable with the `--demo` command-line flag.

---

## 14A. Display Hardware Profiles

> **REQ-DISP-PI4-HW-001** The full-SVT build shall run unmodified on both the Raspberry Pi 4 and the Raspberry Pi 5.

> **REQ-DISP-PI4-HW-002** A `DISPLAY_PROFILE` selector shall support `roadom_7` (1024×600 HDMI), `roadom_10` (1024×600 HDMI), and `waveshare_35` (640×480 DPI). All layout constants shall be derived from `DISPLAY_W`/`DISPLAY_H` so the PFD scales to the selected resolution.

---

## 14B. Flight-Path Vector

> **REQ-DISP-PI4-FPV-001** The AI shall display a velocity-vector / flight-path marker computed from GPS track (azimuth) and flight-path angle (`atan2(vertical speed, groundspeed)`), projected into the same AI frame as the airport/terrain overlays.

> **REQ-DISP-PI4-FPV-002** The marker shall be hidden below 5 kt groundspeed and shall clamp to an edge arrow when the vector falls outside the AI viewport.

> **REQ-DISP-PI4-FPV-003** The marker shall be toggleable from DISPLAY setup (`FLIGHT PATH`, default ON) and persist in `data/settings.json`.

---

## 14C. Weather (internet + FIS-B)

> **REQ-DISP-PI4-WX-001** The display shall present METAR, TAF, AIRMET/SIGMET, NEXRAD, and NOTAM weather from two blended sources — internet (aviationweather.gov, Open-Meteo, FAA NMS-API for NOTAMs) and FIS-B 978 UAT radio — selectable per product family via a RADIO / AUTO / INET toggle (AUTO: radio wins per station, internet backfills).

> **REQ-DISP-PI4-WX-002** Each readout shall be tagged with its origin (FIS-B / INET) and a data-age, and the map status strip shall show source mode + per-source counts + age.

> **REQ-DISP-PI4-WX-003** A single on-map overlay control (OVLY) shall cycle the heavy overlays one at a time: Airspace → Traffic → METAR → Winds → NEXRAD. Traffic shall render on every page regardless.

> **REQ-DISP-PI4-WX-004** The MET page shall show flight-category station dots (VFR/MVFR/IFR/LIFR) and a tap-to-open readout with METAR/TAF/AIRMET/SIGMET/NOTAM tabs (nearest-first, scrollable, ON-ROUTE flagged), falling back to the nearest reporting station when the tapped field has none. When the map range is below 160 NM the station dots shall be labelled with their ICAO ident (hidden at wider zoom).

> **REQ-DISP-PI4-WX-005** NEXRAD shall badge both the receipt age and the radar mosaic valid-age (green <10 min / amber <20 / red beyond).

> **REQ-DISP-PI4-WX-006** NOTAMs shall require FAA NMS-API credentials — client_id / client_secret and an environment selector — entered on the Connectivity screen as **NOTAM KEY / NOTAM SECRET / NOTAM ENV** (preprod default); absent a key the NOTAM fetch shall be a no-op leaving the rest of the suite unaffected. NOTAM queries shall use a dedicated tight, zoom-following radius (≈10–40 NM), narrower than the weather radius, so a query over a busy area returns a local set rather than the whole region.

> **REQ-DISP-PI4-WX-007** With multiple displays on the network, fetched NOTAMs shall be shared over the screen-sync link (one keyed display feeds peers that hold no key), and the NOTAM credentials shall be pushable to every display by entering them once on any display (each persisting its own copy). The secret shall be transmitted only on entry and shown masked everywhere.

---

## 14D. Winds Aloft

> **REQ-DISP-PI4-WND-001** Winds/temperatures aloft shall be displayed as standard wind barbs on the moving map at a pilot-selectable altitude (3,000–18,000 ft) and forecast time (now / +N h), from the GFS `gfs025` pressure-level forecast via Open-Meteo (US-only, no key).

> **REQ-DISP-PI4-WND-002** Winds shall be cached as a national grid split into zones, fetched one zone at a time (the aircraft's zone first), persisted to disk, and re-pulled only when a zone exceeds a staleness threshold (≥ 1 h; GFS reissues ~6 h) — so the grid can be pre-loaded on the ground and used with no in-flight connection.

> **REQ-DISP-PI4-WND-003** The WND page shall use its own limited zoom (40/80/160 NM), render barbs only at ≥40 NM, and show a grid-fill + age status line.

> **REQ-DISP-PI4-WND-004** With multiple displays on the network, winds zones shall be shared over the screen-sync link so a display with internet feeds its peers, which shall make no Open-Meteo calls while a peer is supplying data (per-IP rate-limit mitigation).

---

## 14E. Traffic (ADS-B / FIS-B IN)

> **REQ-DISP-PI4-TFC-001** ADS-B IN traffic (radio GDL90/UDP or built-in internet feed, source-selectable) shall render as diamonds with a heading leader and relative-altitude tag, colour-coded by threat tier (alert / proximate / other) per range+altitude envelopes.

> **REQ-DISP-PI4-TFC-002** Traffic shall be drawn on every map page (clamped to nearby targets except on the dedicated TFC page); alert-class threats shall never be hidden by the clamp or the declutter filters (TFC ALT / TFC RANGE).

> **REQ-DISP-PI4-TFC-003** A new target entering the alert envelope shall raise a flashing TRAFFIC banner and, on the Pi 4, a rate-limited "Traffic, Traffic" voice callout gated by the ALERT AUDIO master switch.

---

## 14F. Full-Screen MFD

> **REQ-DISP-PI4-MFD-001** A 3-finger ~2 s hold shall swap between the PFD and a full-screen moving-map MFD, gated by an ENABLE MFD setting; the unit shall boot to the PFD.

> **REQ-DISP-PI4-MFD-002** The MFD shall provide direct-to, flight-plan, overlay-cycle, orientation, range, zoom, and recenter controls, pan-by-drag, and a configurable 8-slot bottom data strip.

---

## 14G. Screen Sync (multi-display)

> **REQ-DISP-PI4-SYNC-001** Displays on a shared network shall peer-sync (no master) over UDP broadcast, with per-category TX/RX control for bugs, baro, nav, AHRS, GPS, and the flight plan/library, plus always-on sharing of winds-aloft zones and NOTAMs (with on-demand NOTAM-credential push), an AUTO/USB/NET transport selector, and a live peer/links status.

---

## 14H. Hard-Iron (TUMBLE) Magnetometer Calibration

> **REQ-DISP-PI4-MAG-001** In addition to the cardinal walk-through, the AHRS cal modal shall offer a TUMBLE hard-iron calibration: while active the firmware collects per-axis magnetometer min/max as the unit is rotated through all orientations, and on finish solves the hard-iron offset as the per-axis ellipsoid centre and persists it to AHRS flash. The modal shall show elapsed time and per-axis spread.

---

## 15. Future Planned Features

The following features are planned for future versions of the Pi 4 display and are not required for the initial release:

- **Texture-mapped terrain** with satellite imagery, USGS terrain textures, or elevation-shaded relief maps
- **Velocity vector / flight-path marker** on the AI — see TODO `FPV` (software-only with current sensors)
- **Computed AOA indexer** on the right side of the AI when no approach is active — see TODOs `AOA-CALC` and `AOA-PROBE`
- **Air-data integration** (IAS / TAS / wind triangle / stall warn) once the SDP33-1500Pa ships on the new sensor board — see TODO `SDP31-AIRDATA`
- **GPS-aided AHRS** for centripetal-corrected attitude in coordinated turns (Pico 2 W) — see TODO `AHRS-GPS-AID`

Landed since v0.2 (now in §7, §9D, §13 above): time-of-day sun position, moving-map inset, Highway-In-The-Sky (HITS) rendering with runway picker, vertical glideslope diamond (VDI), approach-mode CDI scaling, sim FOLLOW FLT PLAN with 45° intercept, glideslope capture from above, coordinated-turn AP model.

---

*This document covers the Pi 4 variant with full SVT. For the Pi Zero 2W variant without SVT, see HLR-DISP-ZERO-001.*

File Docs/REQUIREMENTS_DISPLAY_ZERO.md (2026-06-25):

# Display Unit (Pi Zero 2W) — High-Level Requirements

| Field | Value |
|---|---|
| Document No. | HLR-DISP-ZERO-001 |
| Title | Display Unit (Pi Zero 2W) — High-Level Requirements|
| Project | Pico-AHRS / PFD |
| Date | 2026-04-13 |
| Version | 0.2 |

---

## 1. Overview

The display unit (Pi Zero 2W variant) is the pilot-facing component of the Pico-AHRS / PFD system optimised for deployment on Raspberry Pi Zero 2W hardware. It connects to a 640×480 Waveshare 3.5" DPI LCD (parallel RGB over the 40-pin GPIO header with I2C capacitive touch) and is responsible for receiving the flight-state SSE stream from the AHRS unit, rendering a full Primary Flight Display (PFD) at 30 fps directly on the framebuffer, and providing a touch-based interface for pilot configuration and bug setting. The display unit contains all rendering logic, terrain awareness alerting, configuration menus, a built-in flight simulator, and a scripted demo mode.

This variant deliberately omits Synthetic Vision Terrain (SVT) background rendering on the attitude indicator in order to remain within the GPU and memory budget of the Pi Zero 2W. The attitude indicator instead uses a plain horizon: a solid blue upper half representing sky and a solid brown lower half representing ground. SRTM elevation tile data is still consumed for Terrain Awareness and Warning System (TAWS) proximity alerting — generating TERRAIN CAUTION and PULL UP / TERRAIN banners — but that data is never used to texture or colour the attitude indicator background.

The Pi 4 variant of this display (document HLR-DISP-PI4-001) provides the full Synthetic Vision Terrain background capability. Operators requiring SVT should refer to that document.

The display unit operates independently of the AHRS unit for configuration and simulation purposes, and degrades gracefully to stale-data indication when the SSE link is interrupted.

---

## 2. Hardware Platform

The following requirements define the minimum acceptable hardware configuration for the Pi Zero 2W display unit. The display unit must be capable of sustained 30 fps rendering of full-screen PFD graphics without relying on a graphical desktop environment.

> **REQ-DISP-ZERO-HW-001** The processor shall be a Raspberry Pi Zero 2W.

> **REQ-DISP-ZERO-HW-002** The display shall be a Waveshare 3.5" DPI LCD: 640×480 IPS, DPI parallel RGB via the 40-pin GPIO header, I2C capacitive touch, and PWM backlight on GPIO 18. The software shall target 640×480 native resolution. Alternative DPI/HDMI panels of the same resolution may be substituted provided the touch interface is compatible.

> **REQ-DISP-ZERO-HW-003** The touchscreen shall support at minimum 2-point simultaneous touch detection to allow two-finger gestures for menu access.

> **REQ-DISP-ZERO-HW-004** The display unit shall be powered from an aircraft 5 V supply.

---

## 3. Rendering Performance

All PFD rendering is performed by `pi_display/pfd.py` using the pygame library writing directly to the Linux framebuffer. The requirements below govern the frame rate target, the display stack, and the signal smoothing applied to raw sensor values before they reach the rendering pipeline.

> **REQ-DISP-ZERO-REND-001** The PFD shall render at a sustained minimum of 30 frames per second under all normal operating conditions.

> **REQ-DISP-ZERO-REND-002** All rendering shall target the pygame framebuffer interface, writing to `/dev/fb0` or an equivalent framebuffer device. No X11 or Wayland compositor shall be required for the display to operate.

> **REQ-DISP-ZERO-REND-003** An IIR low-pass smoothing filter with coefficient α = 0.25 per frame shall be applied to the attitude (roll, pitch, yaw), altitude, airspeed, and vertical speed values before they are passed to the rendering routines, in order to eliminate jitter caused by sensor noise.

---

## 4. Data Stale Detection

The display unit must detect and clearly indicate to the pilot when the SSE data link to the AHRS unit has been interrupted. The requirements below define the timeout threshold and the required indication behaviour.

> **REQ-DISP-ZERO-STALE-001** If no valid SSE event is received from the AHRS unit within 3 seconds, the display shall treat all received data as stale.

> **REQ-DISP-ZERO-STALE-002** While data is stale, the display shall show a `NO LINK` status badge and shall set `ahrs_ok = false` internally, causing the AHRS FAIL indication to activate on the relevant instruments.

---

## 5. Airspeed Tape

The airspeed tape occupies the left side of the PFD. It presents the current speed value using a Veeder-Root drum readout and provides visual encoding of V-speed thresholds through colour arcs and numeral colouring. The requirements below govern the tape rendering, V-speed arcs, numeral colouring, speed bug behaviour, and source selection.

> **REQ-DISP-ZERO-SPD-001** The airspeed tape shall display a Veeder-Root style drum readout centred on the current airspeed value, with smooth continuous digit roll as speed changes.

> **REQ-DISP-ZERO-SPD-002** V-speed colour arcs shall be drawn on the right edge of the airspeed tape as follows: a white arc spanning the flap operating speed range (VS0 to VFE), a green arc spanning the normal operating speed range (VS1 to VNO), a yellow arc spanning the caution speed range (VNO to VNE), and a red radial line at VNE.

> **REQ-DISP-ZERO-SPD-003** The drum numerals shall change colour based on the current airspeed: white when below VNO, yellow when above VNO, and red when above VNE.

> **REQ-DISP-ZERO-SPD-004** A speed bug chevron shall be rendered on the airspeed tape at the position corresponding to the currently set speed bug value.

> **REQ-DISP-ZERO-SPD-005** The speed bug chevron and the speed readout button at the top of the tape shall be displayed in MAGENTA when the airspeed source is GPS groundspeed, and in CYAN when the airspeed source is an indicated airspeed (IAS) sensor.

> **REQ-DISP-ZERO-SPD-006** The pilot shall be able to set the speed bug value by tapping the speed readout button at the top of the tape, which shall open a numpad entry overlay for direct numeric input.

> **REQ-DISP-ZERO-SPD-007** The airspeed source — GPS groundspeed or IAS sensor — shall be selectable from within the AHRS / Sensors sub-menu of the setup interface. The default selection shall be `IAS SENSOR` (consuming the AHRS `ias_kt` field produced by the SDP33-1500Pa air-data path), with automatic fallback to `GPS GS` when the AHRS reports `airdata_ok = False`. The tape, drum, and bug shall recolour from cyan (IAS) to magenta (GS) when the active source falls back.

---

## 6. Altitude Tape and VSI

The altitude tape occupies the right side of the PFD. It presents the current altitude using a Veeder-Root drum readout, provides an altitude bug, and includes an integrated vertical speed indicator bar. The requirements below govern the tape rendering, the drum increment, the altitude bug, the baro setting button, QNH entry, and the VSI bar.

> **REQ-DISP-ZERO-ALT-001** The altitude tape shall display a Veeder-Root drum readout with smooth continuous digit roll, advancing in 50 ft increments, centred on the current altitude value.

> **REQ-DISP-ZERO-ALT-002** An altitude bug chevron shall be rendered on the altitude tape at the position corresponding to the currently set target altitude.

> **REQ-DISP-ZERO-ALT-003** The altitude bug chevron and the altitude readout button shall be displayed in CYAN when the altitude value is derived from the barometric sensor, and in MAGENTA when the altitude value is derived from GPS because the barometric sensor has failed or is absent.

> **REQ-DISP-ZERO-ALT-004** The baro setting button shall display the current QNH setting in CYAN — formatted as `29.92 IN` or `1013 hPa` depending on the selected unit — when the barometric sensor is active and providing valid data. When the barometric sensor is absent or invalid, the button shall display `GPS ALT` in MAGENTA.

> **REQ-DISP-ZERO-ALT-005** The pilot shall be able to enter a QNH baro setting by tapping the baro setting button, which shall open a numpad entry overlay. Entry shall be accepted in either inches of mercury (four digits with an automatic decimal point inserted after the second digit) or hectopascals (four-digit integer), according to the currently selected pressure unit.

> **REQ-DISP-ZERO-ALT-006** The altitude bug shall be settable by tapping the altitude readout button and entering a value in hundreds of feet via the numpad overlay, or by tapping directly on the altitude tape at the desired target altitude position.

> **REQ-DISP-ZERO-ALT-007** A vertical speed indicator bar shall run along the inner edge of the altitude tape, scaled to ±2000 fpm full deflection. The bar shall turn amber in colour when the magnitude of the vertical speed exceeds ±1500 fpm.

---

## 7. Attitude Indicator

The attitude indicator (AI) occupies the centre of the PFD. It renders the aircraft's roll and pitch attitude against a plain horizon background, and includes a pitch ladder, roll arc, slip/skid ball, and fixed aircraft symbol. Synthetic Vision Terrain (SVT) background rendering is not provided in this variant; SRTM tile data is used solely for TAWS proximity alerting as described in Section 9.

> **REQ-DISP-ZERO-AI-001** The AI background SHALL use a plain horizon at all times: the upper half of the attitude sphere shall be rendered as a solid blue representing sky, and the lower half shall be rendered as a solid brown representing ground, divided by the horizon line. The display SHALL NOT render a synthetic vision terrain background on the attitude indicator regardless of whether SRTM terrain tiles are present on storage. SRTM tiles, when present, are used exclusively for TAWS proximity alerting (Section 9) and shall have no effect on the AI background appearance.

> **REQ-DISP-ZERO-AI-002** Pitch ladder lines shall be drawn at ±5°, ±10°, ±15°, ±20°, and ±30° from the horizon, styled consistent with the Garmin GI-275 pitch ladder convention, with longer lines at the larger pitch angles and text labels at ±10°, ±20°, and ±30°.

> **REQ-DISP-ZERO-AI-003** A roll arc shall be rendered at the top of the attitude indicator with a moving doghouse-style bank angle pointer that tracks the current roll angle, and a fixed wings-level reference mark at the 0° roll position.

> **REQ-DISP-ZERO-AI-004** Terrain proximity colouring SHALL NOT be applied to the AI background. Terrain proximity conditions are communicated to the pilot exclusively through the TAWS banner system defined in Section 9 (TERRAIN CAUTION and PULL UP / TERRAIN banners). No tinting or colouring of the attitude indicator background based on terrain proximity is performed in this variant.

> **REQ-DISP-ZERO-AI-005** A slip/skid ball indicator shall be displayed below the roll arc, deflecting laterally in proportion to the lateral acceleration value (`ay`) received from the AHRS unit.

> **REQ-DISP-ZERO-AI-006** A fixed amber delta-wing aircraft symbol shall be rendered at the centre of the attitude indicator to serve as the pitch and roll reference for the pilot.

---

## 8. Heading Tape and Source Modes

The heading tape runs across the bottom of the PFD and displays the current magnetic heading or GPS ground track. It supports a heading bug, a GPS track pointer, and two selectable heading source modes. The requirements below govern the tape layout, the heading box, source mode indication, the heading bug, and the GPS track pointer.

> **REQ-DISP-ZERO-HDG-001** A heading tape shall be rendered horizontally across the bottom of the display, showing compass cardinal and intercardinal labels that scroll continuously as the aircraft turns.

> **REQ-DISP-ZERO-HDG-002** A central heading box shall be superimposed over the heading tape and shall display the current heading as a 3-digit numeric value followed by a degree symbol.

> **REQ-DISP-ZERO-HDG-003** A subscript letter shall appear to the lower-right of the degree symbol in the heading box: `M` when the heading source is the magnetometer, and `G` when the heading source is GPS ground track.

> **REQ-DISP-ZERO-HDG-004** In MAG mode, the heading box border shall be rendered in a white or dim neutral colour. In GPS TRK mode, the heading box border shall be rendered in MAGENTA to indicate that the heading is GPS-derived.

> **REQ-DISP-ZERO-HDG-005** A GPS TRK heading source mode shall be selectable from within the AHRS / Sensors sub-menu. When GPS TRK mode is active, the display shall continuously slave the gyro-derived heading to GPS ground track using a complementary filter with a default blending coefficient of K = 0.05.

> **REQ-DISP-ZERO-HDG-006** A heading bug shall be rendered on the heading tape at the position corresponding to the currently set target heading. The heading bug and its associated readout button shall be displayed in CYAN when the heading source is MAG, and in MAGENTA when the heading source is GPS TRK.

> **REQ-DISP-ZERO-HDG-007** The pilot shall be able to set the heading bug by tapping the heading readout button and entering a value via the numpad overlay, or by tapping directly on the heading tape at the desired heading position.

> **REQ-DISP-ZERO-HDG-008** When GPS fix is valid and the active heading source is MAG, a CYAN tick mark representing the GPS ground track shall be rendered on the heading tape at the current GPS track angle, providing a wind-correction-angle reference.

---

## 9. Terrain and Obstacle Proximity Alerting

The display unit implements a basic terrain awareness and warning function using SRTM elevation tiles and FAA Digital Obstacle File data. In this Pi Zero 2W variant, SRTM data is used exclusively for TAWS proximity alerting and does not affect the attitude indicator background rendering. The requirements below govern the alert thresholds, alert presentation, obstacle detection range, and the in-app data download capability.

> **REQ-DISP-ZERO-TAWS-001** A TERRAIN CAUTION banner rendered in amber shall be displayed when the MSL elevation of terrain or an obstacle within the look-ahead area is within 500 ft below the current aircraft MSL altitude.

> **REQ-DISP-ZERO-TAWS-002** A PULL UP / TERRAIN banner rendered in red shall be displayed, flashing at 1 Hz, when the MSL elevation of terrain or an obstacle within the look-ahead area is within 100 ft below the current aircraft MSL altitude.

> **REQ-DISP-ZERO-TAWS-003** Obstacle proximity alerting shall activate when a charted obstacle is located within 3 nautical miles of the current aircraft position.

> **REQ-DISP-ZERO-TAWS-004** SRTM terrain elevation tiles shall be downloadable by geographic region from within the PFD user interface, without requiring the use of any external computer tools or command-line utilities.

> **REQ-DISP-ZERO-TAWS-005** FAA Digital Obstacle File data shall be downloadable from within the PFD user interface. Downloaded obstacle data shall be considered expired after 28 days from the download date, and the display shall indicate expired obstacle data via the `EXP OBS` status badge.

> **REQ-DISP-ZERO-TAWS-006** Terrain and obstacle proximity alerting shall be inhibited when ground speed is below the pilot-configured VS0 stall speed, to silence false fires during taxi, takeoff roll, and landing rollout. The Pi Zero 2W variant does not implement the Pi 4 voice-callout pipeline, forward-wedge obstacle filtering, or ground-track look-ahead refinements — alert evaluation uses the spot terrain sample at the aircraft's current GPS position.

---

## 9A. Airport Display

The display unit shall show nearby airports on the attitude indicator to give the pilot immediate awareness of emergency-landing options and navigational references.

> **REQ-DISP-ZERO-APT-001** Airports within a configurable radius of the aircraft (default 20 nm) shall be rendered on the attitude indicator as small symbols projected onto the AI using the same pixel-per-degree scale as the pitch ladder.

> **REQ-DISP-ZERO-APT-002** Airport symbol style shall encode airport type:
>
> - Public airport (small / medium / large) — cyan ring with dark centre; outer ring added for medium and large airports
> - Heliport — magenta letter "H"
> - Seaplane base — cyan circle with a wavy underscore
> - Balloonport — grey triangle

> **REQ-DISP-ZERO-APT-003** The airport identifier (ICAO/local code) shall be rendered within a closer configurable range (default 15 nm) as a "road sign" — a dark-filled, coloured-bordered text box mounted on a thin vertical post anchored at the airport symbol. The post shall lift the sign clear of the airport symbol so the label remains legible against busy terrain. The sign border colour shall match the symbol colour. The sign shall be auto-sized to the text width plus padding and clamped to remain within the AI rectangle.

> **REQ-DISP-ZERO-APT-004** Airports outside the attitude indicator's angular field of view shall be culled so that no symbol appears clipped at the edge of the AI rectangle.

> **REQ-DISP-ZERO-APT-005** Airport symbols shall be drawn before obstacle symbols in the Z-order so that close-in towers and obstructions appear on top of airport symbols at the same screen position.

> **REQ-DISP-ZERO-APT-006** The airport database shall be the OurAirports global CSV (approximately 72,000 airports worldwide). Closed airports and records with missing coordinates shall be filtered out at parse time.

> **REQ-DISP-ZERO-APT-007** The airport database shall be downloadable from within the PFD user interface via a dedicated AIRPORT DATA screen. The screen shall show record count, disk usage, age in days since last download, and shall indicate an expired dataset when older than 60 days (configurable).

> **REQ-DISP-ZERO-APT-008** Downloaded airport CSV shall be parsed into a NumPy structured-array cache (.npy) on first access so that subsequent PFD launches load the database without re-parsing the text CSV.

> **REQ-DISP-ZERO-APT-009** A `NO APT` status badge (amber) shall be displayed when no airport data is loaded. An `EXP APT` status badge (orange) shall be displayed when the loaded airport data is older than the configured expiry.

> **REQ-DISP-ZERO-APT-010** The AIRPORT DATA screen shall provide four independently toggleable display filters controlling which airport types render on the attitude indicator:
>
> - PUBLIC — small / medium / large public-use airports (default: on)
> - HELI — heliports (default: on)
> - WATER — seaplane bases (default: off)
> - OTHER — balloonports and uncategorised types (default: off)
>
> Filter state shall persist across the session. When all four filters are off, no airport symbols shall render.

> **REQ-DISP-ZERO-APT-011** Runway polygons for airports within 8 NM shall be projected onto the attitude indicator from each runway's low-end and high-end threshold lat/lon/elevation, using the same flat-earth atan2 bearing/elevation projection as airport and obstacle symbols. Polygons shall scale with runway width (derived from `runways.csv`) and translate/scale/rotate correctly with aircraft position, heading, pitch, and roll. The runway database shall be the OurAirports `runways.csv` (approximately 14,700 records globally), parsed into a NumPy structured-array cache (`runways_cache.npy`) analogous to the airport cache. Closed runways shall be filtered out at parse time. Runway polygons shall be drawn before airport symbols in the Z-order so that the cyan airport ring appears on top of the runway asphalt at the airport centre.
>
> A `RUNWAYS` toggle on the AIRPORT DATA screen shall enable or disable runway rendering (default: on). Toggle state shall persist across power cycles via the settings persistence layer.

> **REQ-DISP-ZERO-APT-012** Extended dashed centerlines shall be rendered outward from each runway threshold along the runway bearing, for airports within 15 NM. Each centerline shall extend 10 NM from the threshold with 0.5 NM dash segments. Extended centerlines shall not render when the aircraft is between the two thresholds of the same runway.
>
> An `EXT C/LINES` toggle on the AIRPORT DATA screen shall enable or disable extended centerlines independently of the runway polygons (default: on). Toggle state shall persist across power cycles via the settings persistence layer.

---

## 9a. User Settings Persistence

Settings the pilot adjusts through the PFD user interface — brightness, units, flight-profile V-speeds and tail number, display filters, heading bug, etc. — must persist across power cycles so that the display remembers configuration between flights.

> **REQ-DISP-ZERO-PERSIST-001** User-adjusted settings shall persist across power cycles via a JSON file at `pi_zero/data/settings.json`. Persisted values shall include: flight profile (V-speeds, tail number, aircraft type, TAS offset), display settings (brightness, baro unit, speed unit, altitude unit, colour scheme), system settings, connectivity settings (Wi-Fi SSID excluding password), airport-data display filters (PUBLIC / HELI / WATER / OTHER / RUNWAYS / EXT C/LINES), heading bug, altitude bug, and last-used display mode.

> **REQ-DISP-ZERO-PERSIST-002** Settings writes shall be debounced and performed on a background thread (default 1.5 s coalesce window) so that rapid consecutive toggle changes produce at most one file write. Writes shall be atomic via `os.replace` from a `.tmp` file so that a power-loss during write cannot corrupt `settings.json`.

> **REQ-DISP-ZERO-PERSIST-003** The Wi-Fi password shall not be written to `settings.json`. Any other security-sensitive values explicitly listed in the persistence skip-list shall be excluded similarly.

> **REQ-DISP-ZERO-PERSIST-004** On shutdown, pending settings changes shall be flushed synchronously so that no user-visible change is lost on a graceful exit.

---

## 10. Status Badges

Status badges provide at-a-glance annunciation of system conditions that require pilot awareness. The badge strip is intentionally blank during fully normal operation so that any badge appearance is immediately conspicuous. The requirements below govern when the badge strip is used and which specific badges must be implemented.

> **REQ-DISP-ZERO-BADGE-001** Status badges shall appear in the badge strip only when a condition exists that requires pilot attention. The badge strip shall be completely blank during fully normal operation with all systems healthy and all data current.

> **REQ-DISP-ZERO-BADGE-002** The following status badges shall be implemented, with the indicated colour and trigger condition:
>
> - `AHRS FAIL` (red) — the AHRS unit is not providing valid attitude data.
> - `NO LINK` (red) — no SSE event has been received within the stale timeout period.
> - `NO TER` (amber) — no SRTM terrain tiles are present for the current region.
> - `NO OBS` (amber) — no FAA Digital Obstacle File data is loaded.
> - `EXP OBS` (orange) — the loaded obstacle data has exceeded the 28-day validity period.
> - `NO APT` (amber) — no airport data is loaded.
> - `EXP APT` (orange) — the loaded airport data is older than the configured expiry.
> - `GPS TRK` (magenta) — GPS TRK heading source mode is active.
> - `GPS ALT` (amber) — altitude is being sourced from GPS because the barometric sensor has failed.
> - `GPS Nsat` (amber) — GPS fix is valid but the satellite count is below the minimum reliable threshold.
> - `NO GPS` (red) — no valid GPS fix is available.

---

## 11. Colour Coding — Data Source Convention

A consistent colour coding convention is used throughout the PFD to communicate to the pilot whether a displayed value originates from an onboard sensor or from GPS. This convention must be applied uniformly to every affected element so that the pilot can immediately identify the data source of any readout or control element without consulting documentation.

> **REQ-DISP-ZERO-COLOR-001** All values and controls associated with data derived from GPS shall be displayed in MAGENTA.

> **REQ-DISP-ZERO-COLOR-002** All values and controls associated with data derived from onboard sensors — including the IMU, barometric pressure sensor, and any connected indicated airspeed sensor — shall be displayed in CYAN.

> **REQ-DISP-ZERO-COLOR-003** The MAGENTA / CYAN data source colour convention shall be applied consistently to all of the following elements: the speed bug and speed readout button, the altitude bug and altitude readout button, the baro setting button, the heading bug and heading readout button, the heading box border, and the heading source subscript letter.

---

## 12. Setup and Configuration

The setup interface provides access to all pilot-configurable parameters. It is designed to be inaccessible by accidental single-finger touches and is organised into sub-menus grouped by function. The requirements below govern the gesture used to open the setup menu, the required sub-menu structure, default V-speed values, unit options, and brightness control.

> **REQ-DISP-ZERO-SETUP-001** The setup menu shall be opened by a two-finger press-and-hold gesture on the touchscreen, sustained for at least 0.8 seconds.

> **REQ-DISP-ZERO-SETUP-002** The setup menu shall contain the following sub-menus: Flight Profile (for aircraft callsign and V-speed entry), Display (for unit selection and brightness adjustment), AHRS / Sensors (for pitch/roll trim, mounting orientation, heading source mode, and airspeed source selection), Connectivity (for AHRS SSE URL and Wi-Fi configuration), and System (for system information display and terrain/obstacle data downloads).

> **REQ-DISP-ZERO-SETUP-003** The factory default V-speed values shall correspond to the Cessna 172S: VS0 = 48 kt, VS1 = 55 kt, VFE = 85 kt, VNO = 129 kt, VNE = 163 kt.

> **REQ-DISP-ZERO-SETUP-004** Display units shall be independently selectable for each measurement type: airspeed in knots, miles per hour, or kilometres per hour; altitude in feet or metres; and pressure in inches of mercury or hectopascals.

> **REQ-DISP-ZERO-SETUP-005** Display backlight brightness shall be adjustable in 10 discrete steps from minimum to maximum brightness.

---

## 13. Flight Simulator

The built-in flight simulator allows the pilot or technician to exercise all PFD instruments and alerting functions without any connection to the AHRS unit or to an actual aircraft. It uses an internal autopilot model to generate realistic flight dynamics. The requirements below govern the simulator's operational modes, airport presets, failure injection capability, in-flight controls, and PFD interactivity.

> **REQ-DISP-ZERO-SIM-001** The display unit shall include a built-in flight simulator that drives all PFD instruments — attitude, altitude, airspeed, heading, vertical speed, GPS position, and status badges — through an internal autopilot model, without requiring any external hardware or network connection.

> **REQ-DISP-ZERO-SIM-002** The simulator shall provide 12 preset departure airports located across geographically diverse regions of the United States, allowing the pilot to observe terrain awareness and TAWS alerting behaviour in different terrain environments.

> **REQ-DISP-ZERO-SIM-003** The simulator shall allow independent injection of the following failure modes during a simulated flight: GPS failure (forcing GPS-derived values to become invalid), barometric sensor failure (forcing fallback to GPS altitude and activating the `GPS ALT` badge), and AHRS failure (activating the `AHRS FAIL` badge and flagging attitude data as invalid).

> **REQ-DISP-ZERO-SIM-004** A `SIM` watermark shall be displayed on the PFD at all times during simulator operation. Tapping the `SIM` watermark shall open a SIM CONTROLS overlay that exposes the failure injection toggles and simulator parameters.

> **REQ-DISP-ZERO-SIM-005** While the simulator is running, the autopilot model shall respond in real time to changes in the heading bug, altitude bug, and speed bug as set by the pilot through the normal PFD touch interface.

---

## 14. Demo Mode

Demo mode provides a self-contained, scripted demonstration of the PFD that can be run without any AHRS hardware, network connection, or pilot interaction. It is intended for exhibition, software testing, and system verification purposes. The requirements below define the demo flight sequence, the geographic setting, and the launch method.

> **REQ-DISP-ZERO-DEMO-001** The display unit shall include a scripted demo mode that animates a pre-defined flight sequence in the vicinity of Sedona, Arizona, driving all PFD instruments through the scripted profile without requiring any Pico W hardware, SSE connection, or external input.

> **REQ-DISP-ZERO-DEMO-002** Demo mode shall be launchable by invoking the PFD software from the command line with the `--demo` flag, with no additional configuration required.

---

## 14A. Weather, Winds, Traffic, MFD, Screen Sync

The Pi Zero implements the same weather suite, winds aloft, traffic, full-screen MFD, and screen-sync features as the Pi 4 — see **REQUIREMENTS_DISPLAY_PI4 §14C–14G** for the detailed requirements; they apply equally here. Pi-Zero-specific points:

> **REQ-DISP-ZERO-WX-001** The Pi Zero shall present the same internet + FIS-B weather products, OVLY overlay cycle, RADIO/AUTO/INET source toggle, MET readout picker (with ICAO station-ident labels when the map range is below 160 NM), NEXRAD, and NOTAM (FAA NMS-API KEY/SECRET/ENV) key entry as the Pi 4.

> **REQ-DISP-ZERO-WX-002** The Pi Zero shall share/adopt NOTAMs over the screen-sync link (one keyed display feeds keyless peers) and shall accept a pushed NOTAM credential set from a peer, persisting its own copy — matching Pi 4 §14C (REQ-DISP-PI4-WX-007).

> **REQ-DISP-ZERO-WND-001** The Pi Zero shall display winds aloft (national disk-cached GFS grid, altitude/forecast-time selectors, 40/80/160 zoom, status line) and shall share/adopt winds zones over the screen-sync link with peer displays.

> **REQ-DISP-ZERO-TFC-001** The Pi Zero shall display ADS-B/FIS-B traffic with threat-coloured diamonds and the declutter filters, and shall raise a flashing TRAFFIC banner on an alert-envelope entry. The Pi Zero has **no audio stack**, so the traffic alert is **visual-only** (no voice callout).

> **REQ-DISP-ZERO-MFD-001** The Pi Zero shall provide the full-screen MFD (3-finger swap, chrome, data strip, pan/recenter) and peer screen-sync (per-category TX/RX, transport selector).

> **REQ-DISP-ZERO-MAG-001** The Pi Zero compass cal currently provides the cardinal walk-through only; the TUMBLE hard-iron flow (Pi 4 §14H) is a planned port.

> **REQ-DISP-ZERO-FPV-001** The flight-path-vector marker (Pi 4 §14B) is **not yet implemented** on the Pi Zero (planned port).

> **REQ-DISP-ZERO-SRTM-001** When full-resolution SRTM1 tiles are present (e.g. rsynced from a Pi 4/5), an on-screen **COMPACT** action shall decimate them in place to SRTM3 (~8.7× smaller) with atomic per-tile rewrites.

---

## 15. Relationship to Pi 4 Variant and SVT Capability

This section documents the deliberate architectural scope boundary between the Pi Zero 2W display variant and the full-capability Pi 4 variant, to prevent ambiguity in requirements tracing and software integration.

> **REQ-DISP-ZERO-ARCH-001** This document (HLR-DISP-ZERO-001) governs the Pi Zero 2W display variant exclusively. The Pi 4 display variant is governed by a separate document, HLR-DISP-PI4-001, which supersedes this document in all respects where full SVT capability is required.

> **REQ-DISP-ZERO-ARCH-002** The Pi Zero 2W variant SHALL NOT implement Synthetic Vision Terrain background rendering on the attitude indicator. This exclusion is a deliberate design constraint arising from the Pi Zero 2W's limited GPU memory bandwidth and VideoCore IV capability relative to the per-frame cost of SRTM tile sampling and terrain mesh rasterisation at 30 fps.

> **REQ-DISP-ZERO-ARCH-003** SRTM terrain elevation data downloaded and stored on the Pi Zero 2W display unit SHALL be used for TAWS proximity alerting only (Section 9). The presence or absence of SRTM tiles SHALL NOT affect the rendering of the attitude indicator background, which shall remain a plain sky/ground horizon at all times.

> **REQ-DISP-ZERO-ARCH-004** The software architecture of the Pi Zero 2W display variant shall be structured such that the SVT rendering code path is either absent or disabled at build/configuration time, so that no terrain tile loading, sampling, or rasterisation is performed on the rendering thread, ensuring the 30 fps frame budget is not compromised by unused code paths.

> **REQ-DISP-ZERO-ARCH-005** Operators who require Synthetic Vision Terrain background rendering on the attitude indicator shall use the Pi 4 variant of the display unit, as defined in HLR-DISP-PI4-001. The Pi Zero 2W variant is the recommended choice for weight-sensitive or cost-sensitive installations where TAWS alerting without SVT is operationally acceptable.

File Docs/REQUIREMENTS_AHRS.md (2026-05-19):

# AHRS Unit — High-Level Requirements

| Field | Value |
|---|---|
| Document No. | HLR-AHRS-001 |
| Title | AHRS Unit — High-Level Requirements |
| Project | Pico-AHRS / PFD |
| Date | 2026-05-15 |
| Version | 0.2 |

---

## 1. Overview

The AHRS unit is the airborne sensor node of the Pico-AHRS / PFD system. It runs on a Raspberry Pi Pico W and is responsible for acquiring raw inertial, barometric, and GPS data; fusing that data into a real-time attitude solution; and broadcasting the resulting flight-state information over a Wi-Fi Server-Sent Events (SSE) stream to one or more display units. The AHRS unit operates autonomously once powered and requires no operator interaction during normal flight. All pilot-adjustable parameters — mounting orientation, baro reference, and Wi-Fi credentials — are set from the display unit or from a configuration file without reflashing firmware.

---

## 2. Hardware Platform

The following requirements define the minimum acceptable hardware configuration for the AHRS unit. All components must be integrated into a self-contained enclosure suitable for aircraft cockpit installation.

> **REQ-AHRS-HW-001** The processor shall be a Raspberry Pi Pico W.

> **REQ-AHRS-HW-002** The IMU shall be an ICM-42688-P 6-axis (gyroscope and accelerometer) sensor mounted on the same PCB or on a breakout board connected to the Pico W via SPI or I2C.

> **REQ-AHRS-HW-003** A BMP280 or BME280 barometric pressure sensor shall be connected to the Pico W via I2C.

> **REQ-AHRS-HW-004** A GPS module providing NMEA sentences — at minimum GGA and RMC — shall be connected to the Pico W via UART.

> **REQ-AHRS-HW-005** The unit shall be powered from an aircraft 5 V USB supply or a regulated aircraft bus.

> **REQ-AHRS-HW-006** A Sensirion SDP33-1500Pa differential-pressure sensor shall be connected to the Pico W via I²C at address 0x21, sharing the same SDA/SCL pair as the BME280. The sensor's `+` port shall be connected to the airframe pitot tube and the `−` port to the static reference (teed into the BME280's static port).

> **REQ-AHRS-HW-007** The AHRS unit shall be implemented as a single integrated printed-circuit board (rev A or later) carrying the Pico W, IMU, GPS, BME280, and SDP33. The PCB shall reserve an additional I²C device footprint at address 0x22 for a future second differential-pressure sensor dedicated to angle-of-attack measurement (see AOA-PROBE in `Docs/BUGS_AND_TODO.md`). Backwards compatibility with the bench-breakout pinout shall be preserved so that the same firmware boots on either build path. The driver implementation (`firmware/sdp31.py`) is protocol-compatible with the entire Sensirion SDP3x family — the scale factor is read from the device at startup — so a future swap to a higher-range part requires only a part-number update in the documentation.

---

## 3. Sensor Fusion

The firmware must maintain a continuous, low-latency attitude estimate by combining gyroscope and accelerometer measurements through a numerical filter. The requirements in this section govern the algorithm choice, update rate, accuracy budget, and latency budget for the attitude solution delivered to the display.

> **REQ-AHRS-SF-001** The firmware shall compute roll, pitch, and yaw (magnetic heading) by fusing gyroscope and accelerometer data using a complementary filter or a Madgwick / Mahony filter algorithm.

> **REQ-AHRS-SF-002** Yaw drift shall be corrected by magnetometer data when a magnetometer is available, or by GPS ground track when magnetometer data is unavailable or invalid.

> **REQ-AHRS-SF-003** The sensor fusion algorithm shall execute at a minimum internal update rate of 100 Hz.

> **REQ-AHRS-SF-004** Attitude data placed into the outbound SSE stream shall be no older than 20 ms at the moment of transmission.

> **REQ-AHRS-SF-005** Roll accuracy shall be within ±1° of the true roll angle under steady coordinated flight conditions.

> **REQ-AHRS-SF-006** Pitch accuracy shall be within ±1° of the true pitch angle under steady coordinated flight conditions.

---

## 4. Barometric Altimetry

The barometric subsystem converts raw pressure readings from the pressure sensor into a pilot-correctable pressure altitude. The requirements below govern the sampling rate, the altitude computation method, fault detection, and resolution.

> **REQ-AHRS-BARO-001** The firmware shall read the barometric pressure sensor at a minimum rate of 10 Hz.

> **REQ-AHRS-BARO-002** Altitude shall be computed from measured pressure using the International Standard Atmosphere (ISA) formula, with a pilot-adjustable barometric reference setting (QNH) applied to the calculation.

> **REQ-AHRS-BARO-003** When the pressure sensor is absent or returns readings that are outside the valid range or otherwise flagged as invalid, the firmware shall set `baro_ok = false` and report `baro_src = "gps"` in the outbound data stream, indicating that GPS altitude is being used as the fallback source.

> **REQ-AHRS-BARO-004** The computed altitude shall have a resolution better than 5 ft across the operational altitude range.

---

## 5. GPS Integration

The GPS subsystem parses standard NMEA sentences received over UART and forwards position, velocity, and navigation state data to the display unit as part of the regular SSE stream. The requirements below govern which sentences are parsed, which data fields are exposed, and how loss of fix is reported.

> **REQ-AHRS-GPS-001** The firmware shall parse NMEA GGA and RMC sentences received from the connected GPS module.

> **REQ-AHRS-GPS-002** The following GPS-derived values shall be included in the outbound data stream: latitude, longitude, ground track (true), ground speed, GPS altitude (MSL), fix status, and satellite count.

> **REQ-AHRS-GPS-003** When no valid GPS fix is available, the firmware shall set `gps_ok = false` in the outbound data stream.

> **REQ-AHRS-GPS-004** GPS data shall be forwarded to the display within one NMEA update epoch, which is typically one second at the standard 1 Hz GPS output rate.

---

## 6. Data Output — SSE Stream

The SSE stream is the sole output interface of the AHRS unit. It must carry all flight-state data needed by the display unit in a self-describing, reconnect-tolerant format. The requirements below govern the server configuration, the endpoint definition, the JSON payload, the emission rate, and the reconnect behaviour.

> **REQ-AHRS-SSE-001** The Pico W shall host an HTTP/1.1 server listening on port 80.

> **REQ-AHRS-SSE-002** The endpoint `/stream` shall deliver responses with `Content-Type: text/event-stream`, conforming to the Server-Sent Events specification.

> **REQ-AHRS-SSE-003** Each SSE event payload shall be a JSON object containing at minimum the following fields: `roll`, `pitch`, `yaw`, `speed`, `alt`, `vspeed`, `lat`, `lon`, `track`, `gps_alt`, `baro_hpa`, `baro_src`, `baro_ok`, `gps_ok`, `ahrs_ok`, `fix`, `sats`, `ay`, `ias_kt`, `tas_kt`, `dp_pa`, `oat_c`, `dens_alt_ft`, `wind_dir`, `wind_kt`, and `airdata_ok`.

> **REQ-AHRS-SSE-004** The `/stream` endpoint shall emit events at a minimum rate of 20 Hz.

> **REQ-AHRS-SSE-005** A client that disconnects and reconnects to `/stream` shall receive a valid, well-formed SSE event within one second of reconnection, without requiring any handshake beyond the initial HTTP GET request.

> **REQ-AHRS-SSE-006** The Pico W Wi-Fi access point SSID shall default to `AHRS-Link`. Both the SSID and the passphrase shall be configurable by editing a configuration file without requiring reflashing of the firmware.

---
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

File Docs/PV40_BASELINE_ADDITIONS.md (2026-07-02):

# PV.40 Baseline Additions (v0.1)

**Scope:** What the chosen baseline **PMA Vizion PV.40** (`pv.40` branch,
`9757708`, 2019-05-07) adds over the ~2011-era `TT AP Sources` snapshot the v0.1
spec set was reverse-engineered from. The core engine, control laws, stepper
stage, torque scheme, and envelope logic are unchanged (see the v0.1 deep-dives);
this document captures the *deltas*.

**Source:** `pv40/PV.40/vizion2hc12/Sources/` (branch `pv.40`). Citations `File:line`.

---
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

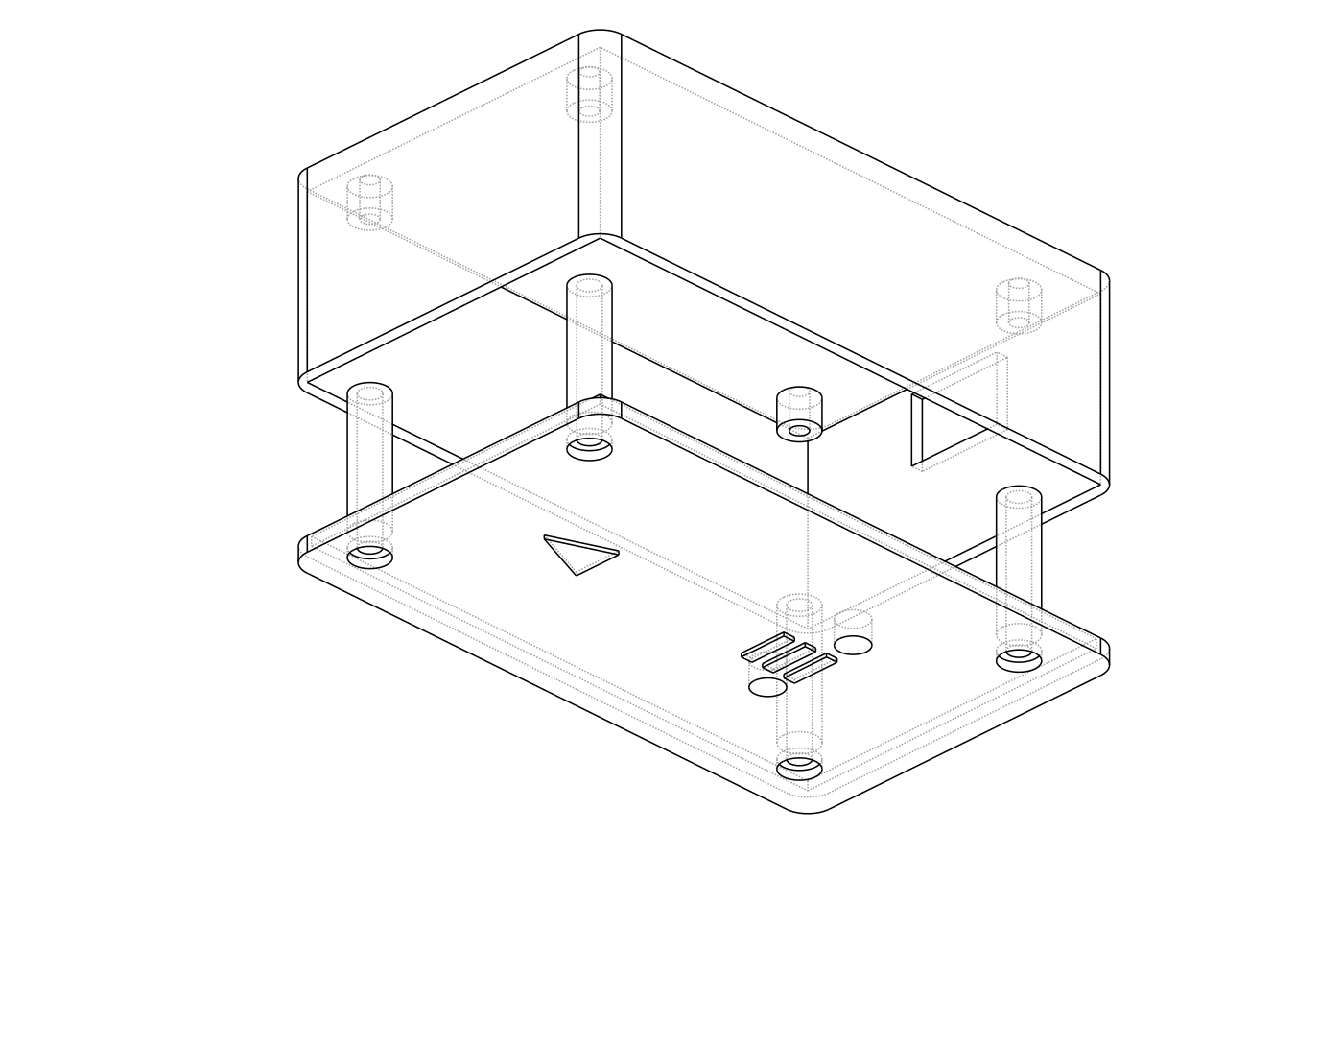
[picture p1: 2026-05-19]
hardware/v1/enclosure/preview_iso.png

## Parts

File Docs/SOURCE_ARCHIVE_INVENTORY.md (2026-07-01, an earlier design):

# Source Archive Inventory (working)

Running triage of the TruTrak source drops provided for the revival project.
Appended as drops arrive. Goal: know exactly what we have, which build is
canonical, and which to use as the revival baseline.

**Products expected (per owner):** Gemini, Sorcerer, PMA Vizion, Vizion 380 —
"everything most recent."

---

## Drops received

| # | Product | Project | VCS | Newest version | Date | Targets | Key interfaces |
|---|---|---|-----|---|---|---|---|
| 1 | Vizion 380 (mixed) | `TT AP Sources` | none (loose) | ~A.43 / 2.44 era | ~2010–11 | VZ380 Flat, Round | GPS NMEA, ARINC-429, CDI |
| 2 | **Vizion 380** (experimental) | `vizion380 VZ15` | **git** | **VZ.15** | 2015-03-17 | VZ380 Flat, Round | + SkyView, Xavion |
| 3 | **PMA Vizion** (certified) | `vizion2hc12` (PV.40) | **git** | **PV.40** | 2019-05-07 | Vizion2 Flat, Round | + **Garmin G5, G3X, Aspen** |
| 4 | **Sorcerer / DFC gen2** | `Sorcerer_2` + `sorcerer_git` | **git** | **V3.66** | 2015-11-19 | Sorcerer, Sorcerer NG, DF-II (flat/round/tall ±ng), Model 100, RV-10, Sky Pilot (flat/round/tall) | GPS, ARINC, CDI |
| 5 | Gemini | — | — | *pending* | — | — | — |

**All three received drops share the same engine** (`DFCMain/DFC_IRQ/p20Hz/
AD7714/EEPROM/...`) — one codebase, target- and era-differentiated. Everything in
`CONTROL_LOGIC_MAP.md` + the four deep-dives applies across them; deltas are
target/version specific.

---

## Drop 1 — `TT AP Sources` (baseline of the existing spec set)

Loose files, no VCS. `DFCMain.asm` HISTORY ends ~`A.43 (11/02/2010)` / `2.44`.
This is the snapshot the current v0.1 docs were reverse-engineered from. Targets:
`Vizion 380 Flat` (PRODUCT_ID 1) and `Round` (49). Oldest of the three — treat as
reference, supersede with Drop 2/3 where they differ.

## Drop 2 — `vizion380 VZ15` (experimental Vizion 380, newest exp.)

- **Git**, branches: `master` = `master-2` = **VZ.15** (`d2c6be1`, "compiled for
  production", 2015-03-17); `Production` = VZ.13.
- History: VZ.08 → VZ.09 → VZ.12 → VZ.125 → VZ.13 (2014-03-31 batch) →
  **VZ.14** (2015-01-09, *"merge from skyview-pilot DY.26 … basic SkyView
  interface … Xavion basic interface"*) → **VZ.15** (2015-03-11, *"bugfix for
  aviation data not recognised on primary serial input"*).
- Full CodeWarrior project: `Vizion380.mcp`, `prm/banked_flash.prm`, built
  `.abs/.s19` images, `.map`/`.lst`.
- New vs Drop 1: `GPSMonitor2.asm`; the SkyView/Xavion serial interfaces.
- **Canonical: `master` @ VZ.15.**

## Drop 3 — `vizion2hc12` (PMA Vizion, PV.40) — **newest & most capable**

- Project folder `PV.40/vizion2hc12`. **Git**, branches: `master`, `master2`,
  **`pv.40`**, `FAILURETEST`, `withouthdgtrkswitching`.
- Timeline: **PV.30 "approved version"** (`431bb46`, 2017-06-27) → flat/round
  rework (2017-08) → G5 interface (2018-06) → **Aspen "went to OSH"** (2018-07) →
  first compile of new line (2019-03) → G5/G3X/Aspen modes working (2019-05) →
  **PV.40** (`9757708`, "PV.40 fixed eeprom save for def vs", 2019-05-07).
- Targets renamed **`Vizion2Flat` / `Vizion2Round`** (the "Vizion2"/PMA line).
  Also carries `Sorcerer_Data/` and `Vizion380_Data/` build-output folders.
- **Certified-panel EFIS interfaces** present in source: **Aspen** (18 refs),
  **G5** (9), **G3X**, SkyView. This is the "talk to anything" line, matured.
- ⚠ **Canonical = branch `pv.40`** (`9757708`) — it is `master` + 1 (the def-VS
  EEPROM-save fix). **The extracted working tree is checked out on
  `withouthdgtrkswitching`** (`a671f07`, 2019-07-18, *"not sure, strange
  behavior"*) — an experimental WIP, **not** the release. Analyze the `pv.40`
  branch, not the loose working-tree files.

## Drop 4 — `Sorcerer_2` + `sorcerer_git` (DFC gen2 multi-product)

- The big **multi-target "gen2"** CodeWarrior project. `Sorcerer_2` is the working
  tree; `sorcerer_git` is its `.git` history (they pair).
- **Git** (in `sorcerer_git`): branches `master`, `364` (checked out),
  `Production`, `3.66`. History `3.60 → 3.61 → 3.62/A.62 → 3.63/A.63/B.63/C.63 →
  3.64` (2014-03-31 batch) → 2015 work (virtual gyro for new gyro model, track
  rollout rework, autocalibrate, servo reverses, new VNAV) → **V3.66 released**
  (`26a3e83`, 2015-11-19), tagged in-message *"last software to work with old
  hardware."*
- **Targets** (`Sources/` + `dfc_gen2_Data/`): **Sorcerer** (PRODUCT_ID 22, "no
  CAN hardware"), **Sorcerer NG** (next-gen), **DF-II** flat/round/tall and `_ng`
  variants, **Model 100**, **RV-10**, **Sky Pilot** flat/round/tall.
- This is the direct descendant of Drop 1's DF-II/Sorcerer/Model-100/RV-10 family —
  the legacy experimental multi-product line, frozen at V3.66.
- ⚠ Working tree checked out on branch **`364`**; canonical release is **`master`/
  `3.66`** (`26a3e83`). Note "NG" targets imply a new-gyro/CAN hardware variant.

---

## Baseline decision

See **[`BASELINE_COMPARISON_PV40_vs_VZ15.md`](BASELINE_COMPARISON_PV40_vs_VZ15.md)**
— structured PV.40 vs VZ.15 diff. **Verdict: fork PV.40 (`pv.40`)** — newest, adds
the `EFISTYPE` interface selector + AEP/ASPEN/EXT_ALT modes + more ARINC/CAN/Aspen,
shares the engine + envelope. VZ.15 kept as experimental cross-reference (and for
its richer audio/`Talker`).

---

## Lineage / timeline

```
2010–11  Drop 1  TT AP Sources        A.43 / 2.44        (spec v0.1 baseline)
   |     (SkyPilot Cessna cert branch diverges at v2.37, 2010)
2014–15  Drop 4  Sorcerer/DFC gen2    3.60 → V3.66       legacy multi-product; "last for old hw"
2014–15  Drop 2  Vizion 380 VZ15      VZ.08 → VZ.15      + SkyView, Xavion
2017–19  Drop 3  PMA Vizion PV.40     PV.30 → PV.40      + G5, G3X, Aspen, EFISTYPE  ← BASELINE
```

## Recommended baseline for the revival

- **Primary reference: PV.40 (`pv.40` branch).** Newest (2019), most interfaces
  (G5/G3X/Aspen/SkyView), certified pedigree — best match for "talk to anything"
  and any future cert path.
- **Cross-check: VZ15 `master`** as the experimental Vizion 380 counterpart (the
  direct experimental drop-in target).
- Keep Drop 1 only as the historical baseline the current docs cite.
- Re-validate the v0.1 spec set against PV.40 and record deltas (mode encodings,
  gains, envelope, target pin maps, the new EFIS interfaces).

---

## Open items

- [x] Baseline decision: **PV.40** (`pv.40`) — see comparison doc.
- [x] Sorcerer/gen2 received (Drop 4, V3.66).
- [ ] Receive **Gemini** drop; add row + detail.
- [ ] Decide whether to **vendor these trees into the repo** (they carry their own
      `.git` + build artifacts; IP/licensing owner-confirmed) or keep them
      external and cite by version.
- [ ] Re-point the spec set's citations to **PV.40 `pv.40`** as canonical, noting
      VZ15/Drop-1 deltas.
- [ ] Document the **G5 / G3X / Aspen / SkyView / Xavion** interface handlers
      (new since Drop 1) — directly serves the interoperability goal.
- [ ] Map PV.30 (certified/"approved") vs PV.40 delta — what changed post-approval.

---

*Working document — updated as drops arrive. Canonical branches: VZ15 `master`
(VZ.15), PMA Vizion `pv.40` (PV.40).*

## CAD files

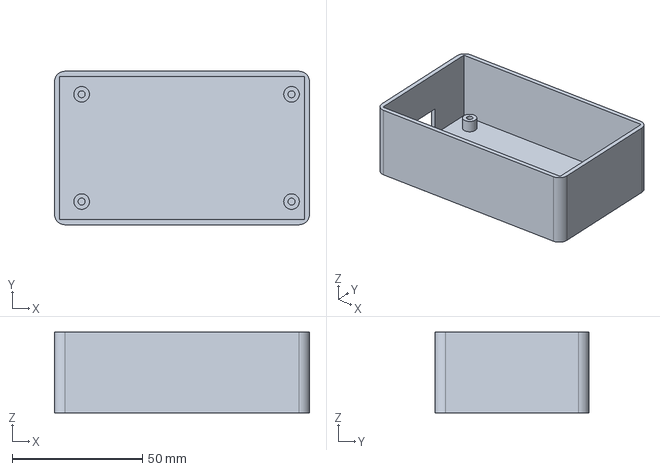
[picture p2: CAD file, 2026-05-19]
hardware/v1/enclosure/enclosure_bottom.step
98.0 x 59.0 x 31.1 mm

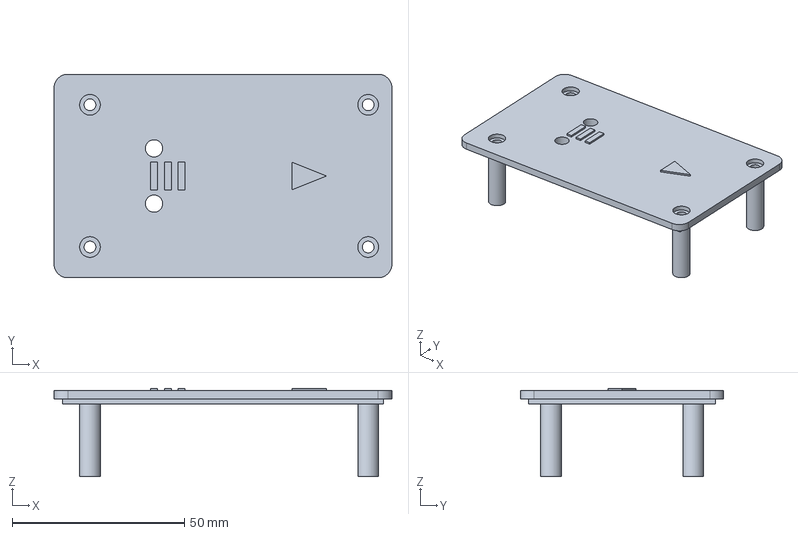
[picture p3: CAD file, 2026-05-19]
hardware/v1/enclosure/enclosure_lid.step
98.0 x 59.0 x 25.6 mm

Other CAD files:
hardware/v1/enclosure/enclosure_bottom.stl
hardware/v1/enclosure/enclosure_lid.stl

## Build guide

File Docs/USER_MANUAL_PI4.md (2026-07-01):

# AHRS PFD — Pi 4 / Pi 5 Pilot's User Manual

**Software version 0.5 · Hardware: AHRS PCB rev A (Pico W + WT901 + NEO-6M + BME280 + SDP33-1500Pa) · Display: ROADOM 7" or 10" HDMI 1024×600 (or Waveshare 3.5" DPI 640×480)**

*Full SVT version — OpenGL vector graphics with 3D terrain rendering*

> This manual covers the **full-SVT build**, which runs on both the **Raspberry Pi 4** and the **Raspberry Pi 5** (same `pi4/` software — the Pi 5's extra headroom just gives more frame-rate margin). For the Pi Zero 2W version (no SVT), see USER_MANUAL_ZERO.md. Display hardware and resolution are set by a **display profile** — see §1.

---

## Contents

1. [Screen Overview](#1-screen-overview)
2. [Airspeed Tape](#2-airspeed-tape)
3. [Altitude Tape and VSI](#3-altitude-tape-and-vsi)
4. [Attitude Indicator](#4-attitude-indicator)
5. [Heading Tape](#5-heading-tape)
6. [Status Badges](#6-status-badges)
6A. [PFD Top Ribbon](#6a-pfd-top-ribbon)
7. [Setting Bugs](#7-setting-bugs)
8. [Setup Menu](#8-setup-menu)
9. [Flight Profile — V-Speeds and Callsign](#9-flight-profile--v-speeds-and-callsign)
10. [Display Settings](#10-display-settings)
11. [AHRS / Sensors](#11-ahrs--sensors)
12. [Connectivity](#12-connectivity)
12A. [Screen Sync (multi-display panels)](#12a-screen-sync-multi-display-panels)
13. [System](#13-system)
14. [Data Downloads](#14-data-downloads)
    - [Terrain data](#terrain-data)
    - [Airspace data](#airspace-data)
    - [Obstacle data](#obstacle-data)
    - [Airport data](#airport-data)
15. [Full-Screen MFD](#15-full-screen-mfd)
16. [Navigation & Approach](#16-navigation--approach)
    - [Direct-to Navigation](#direct-to-navigation)
    - [AGL Readout](#agl-readout)
    - [Synthetic Approach (HITS + VDI)](#synthetic-approach-hits--vdi)
17. [Moving Map & Overlays](#17-moving-map--overlays)
    - [Moving-Map Inset](#moving-map-inset)
    - [Winds Aloft (WND)](#winds-aloft-wnd)
    - [Weather — Sources and Overlays](#weather--sources-and-overlays)
    - [Traffic — ADS-B / FIS-B IN](#traffic--ads-b--fis-b-in)
18. [Demo Mode](#18-demo-mode)
19. [Flight Simulator](#19-flight-simulator)
20. [Audio Alerts](#20-audio-alerts)
21. [Unusual-Attitude Recovery Cues](#21-unusual-attitude-recovery-cues)
22. [AHRS PCB and Air-Data Hardware](#22-ahrs-pcb-and-air-data-hardware)

---

## 1. Screen Overview

This build runs on a **Raspberry Pi 4 or Pi 5** (identical software; the Pi 5 just renders with more headroom) and supports three display profiles:

| Profile (`DISPLAY_PROFILE`) | Display | Resolution | Interface | Backlight |
|---|---|---|---|---|
| `roadom_7` (default) | ROADOM 7" HDMI | 1024×600 | HDMI + USB touch | DDC/CI (BRIGHTNESS slider) |
| `roadom_10` | ROADOM 10" HDMI | 1024×600 | HDMI + USB touch | DDC/CI (BRIGHTNESS slider) |
| `waveshare_35` | Waveshare 3.5" DPI | 640×480 | DPI GPIO + I2C touch | PWM on GPIO 18 |

All layout elements scale automatically to the resolution. Pick your panel by setting **`DISPLAY_PROFILE`** in `pi4/config.py` (or override `DISPLAY_W`/`DISPLAY_H` in `config_local.py` for a custom panel). Both ROADOM panels are 1024×600 — the 7" and 10" differ only physically — so the layout is identical; the 10" just shows it bigger. **All three panels respond to the BRIGHTNESS slider** (§10): the ROADOM HDMI panels over **DDC/CI** (the Pi 4 setup script installs `ddcutil`; the panel's own hardware button still works too), the Waveshare over **GPIO-18 PWM**.

The display is divided into five fixed zones (sizes shown for 1024×600 default):

| Zone | Width / Height | Content |
|---|---|---|
| Left tape | 118 px wide | Airspeed |
| Right tape | 131 px wide | Altitude + VSI |
| Centre AI | remainder (~775 px) | Attitude + synthetic vision terrain |
| Bottom strip | 55 px tall | Heading tape |
| Top ribbon | 28 px tall | Bug readouts + a configurable 5-slot data ribbon (§6A) |

Everything is rendered at 30 fps using OpenGL ES vector graphics directly on the framebuffer.

---

## 2. Airspeed Tape

### Reading the tape

The tape scrolls so that current airspeed is always at the centred **Veeder-Root drum** readout. The drum shows two-digit resolution (e.g. `115`, `099`, `008`): the **ones** digit rolls smoothly on a small inner drum to the right, and the **tens** digit cascades one slot up whenever the ones drum passes 9 → 0. Above the current tens digit a faint preview of the next digit (and the one two above) peeks in from the top of the box so you can see what you're approaching — e.g. at 99 kt the "1" of 100 is already visible above the "0" and "9". This matches the altimeter drum behaviour and makes crossings through 10 / 100 / 1000 obvious at a glance.

The readout box is scaled with the display font so the digits remain crisp at 1024×600.

### Colour arcs (right edge of tape)

| Arc | Colour | Meaning |
|-----|---|---|
| White | White | VS0 – VFE — flap operating range |
| Green | Green | VS1 – VNO — normal operating range |
| Yellow | Yellow | VNO – VNE — caution / structural |
| Red line | Red | VNE — never-exceed |

The drum numerals turn **yellow** above VNO and **red** above VNE.

### Speed bug

A chevron marker tracks the speed bug. Tap the readout button at the **top** of the tape to set a value.

| Colour | Source |
|---|---|
| Cyan | IAS — SDP33-1500Pa differential-pressure sensor with BME280 density correction. Default when the air-data path reports `airdata_ok = True`. |
| Magenta | GPS groundspeed (GS) — fallback when SDP33 is absent, has failed, or AIRSPEED SOURCE is forced to GPS GS in AHRS / Sensors. |

The active source is also surfaced in the AIRSPEED SOURCE row of the AHRS / Sensors menu (§11) and on the speed tape itself as the bug colour. When pulling the IAS feed offline (cap on pitot, low altitude, sensor failure) the tape silently switches to GS — the bug + drum recolour from cyan to magenta so the change is unambiguous.

---

## 3. Altitude Tape and VSI

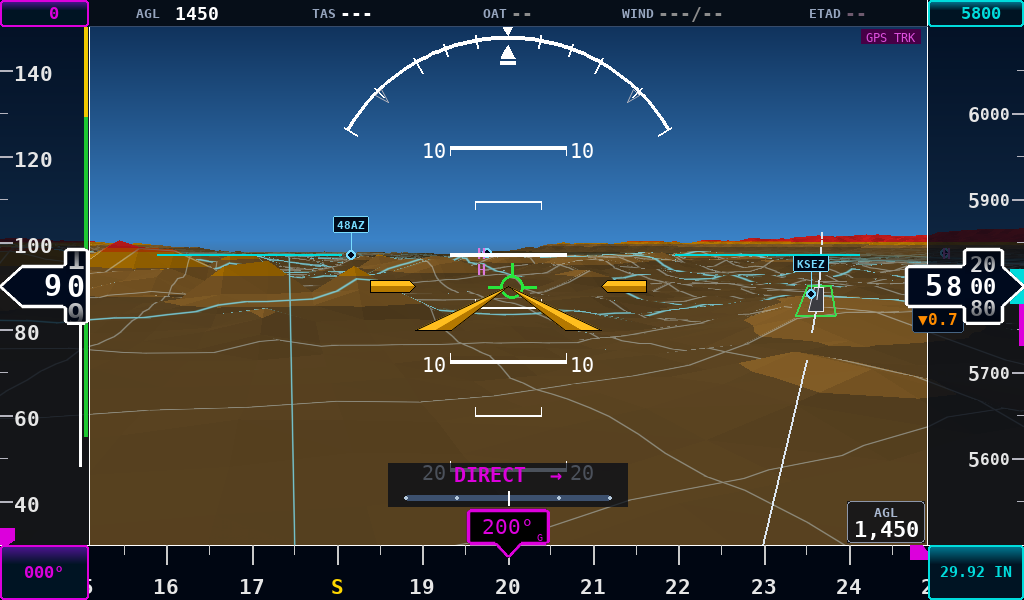
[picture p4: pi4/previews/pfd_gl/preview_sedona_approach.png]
Descending final approach


### Altitude tape

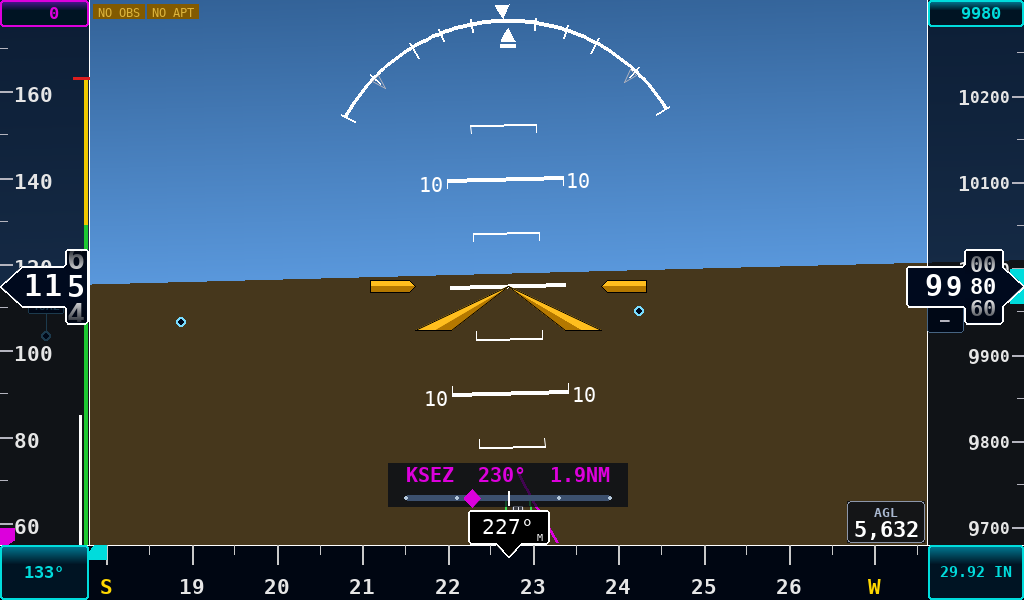
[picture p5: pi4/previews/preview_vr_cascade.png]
Altitude drum passing 10000 ft — the leading "1" is visible above the "0" before integer roll-over


Veeder-Root drum on the right side. Scrolls in 50 ft increments. The right-hand inner drum shows the ten-foot digit; the centre cell shows the hundreds/tens pair in 20-ft steps; the leading thousands column reveals the next column one slot above so transitions through 1000 / 10000 ft stay readable. The drum renders as two/three independent cells that roll at the correct rates — the altitude value is always the number vertically centred in the large outer cell.

**Altitude bug** settable via numpad (entry in hundreds of feet) or by tapping the tape.

| Colour | Source |
|---|---|
| Cyan | Barometric altitude (BME280 active) |
| Magenta | GPS altitude (baro failed or absent) |

### Baro setting

| Display | Colour | Meaning |
|---|---|---|
| `29.92 IN` | Cyan | BME280 active; inHg |
| `1013 hPa` | Cyan | BME280 active; hPa |
| `GPS ALT` | Magenta | No baro sensor |

### VSI

Green/amber bar along the inner edge of the alt tape. ±2000 fpm scale. Amber above ±1500 fpm.

---

## 4. Attitude Indicator

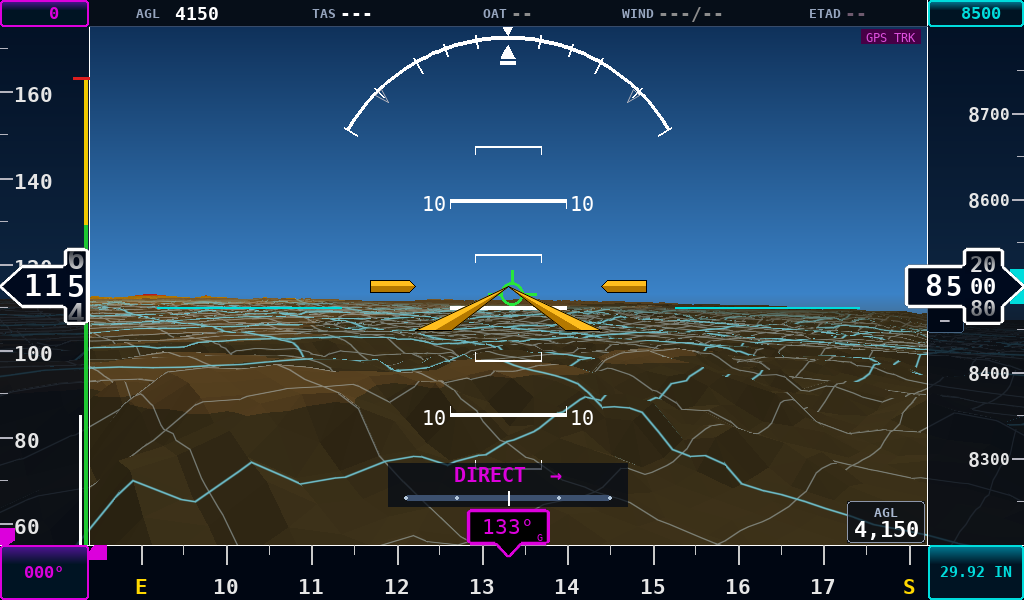
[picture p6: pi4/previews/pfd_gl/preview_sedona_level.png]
Level cruise over Sedona — SVT, distance grid, sun-angle shading


### Synthetic vision background

The Pi 4 renders a **full 3D Synthetic Vision Terrain (SVT)** background behind the attitude indicator using OpenGL ES. A terrain mesh is built from SRTM elevation data within a 20 nm radius of the aircraft and rendered through a true perspective projection from the aircraft's position.

**Key capability:** Unlike 2D scanline renderers, the OpenGL SVT shows terrain features that are **above the aircraft's altitude** — mountain peaks and ridges rise **above the horizon line** in correct geometric perspective. This gives the pilot a natural, out-the-window view of the terrain environment.

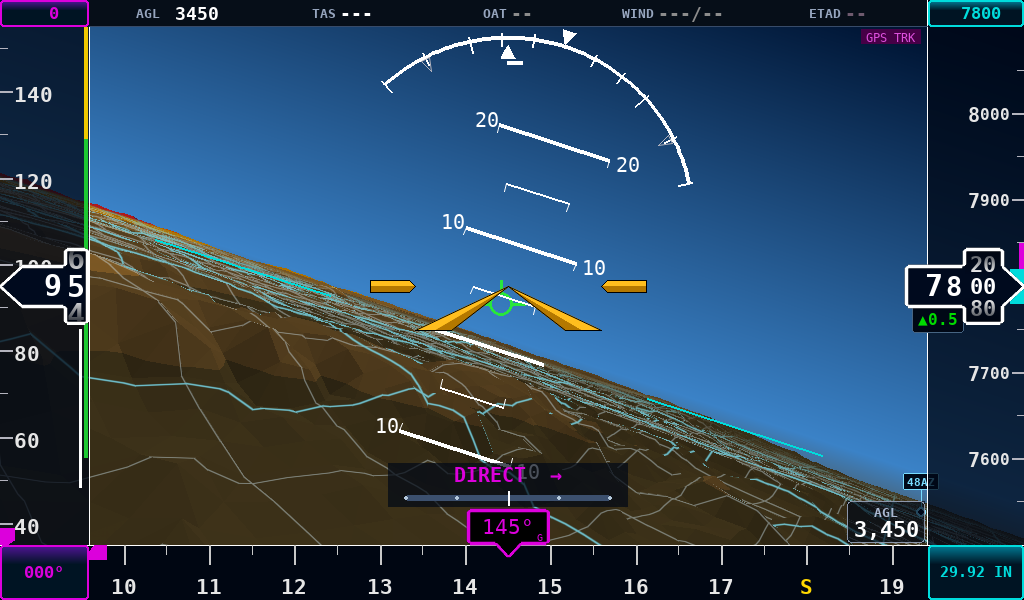
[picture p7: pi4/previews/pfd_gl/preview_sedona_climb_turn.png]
Climbing left turn — banked terrain mesh, grid follows roll


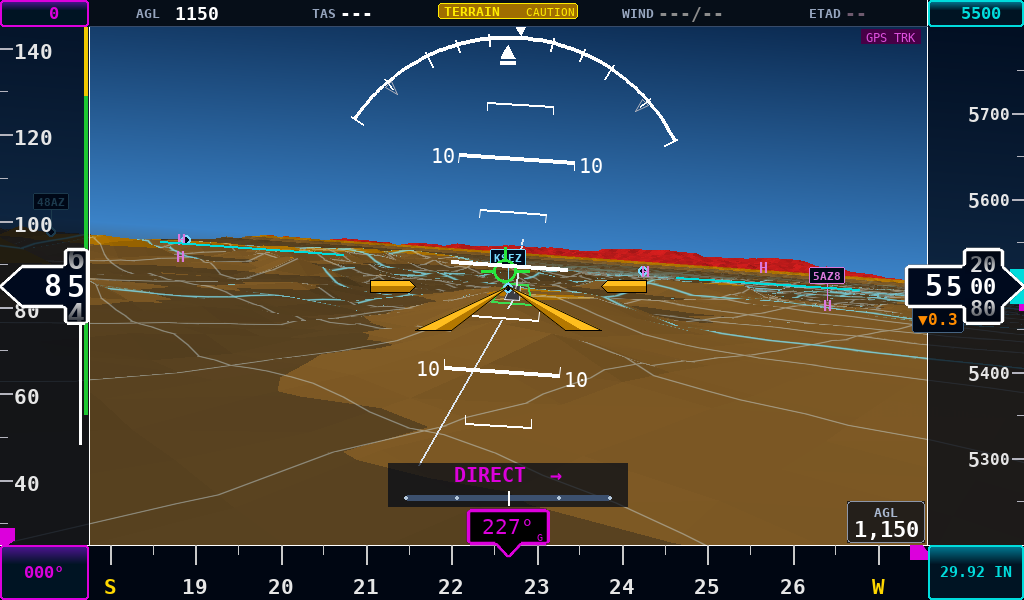
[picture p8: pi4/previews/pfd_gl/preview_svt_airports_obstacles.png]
Combined SVT + airports + obstacles near Sedona


#### Clearance colouring

Terrain is coloured by clearance below the aircraft:

| Clearance | Colour | Meaning |
|---|---|---|
| Above aircraft altitude | Red | Terrain is higher than you — obstacle |
| 0–100 ft below | Deep orange | Immediate proximity |
| 100–500 ft below | Amber | Caution |
| 500–1000 ft below | Brown | Safe clearance |
| 1000–2000 ft below | Dark brown | Well clear |
| More than 2000 ft below | Very dark | Far below |

Beyond the 20 nm mesh edge the rendering fades to a dusty atmospheric-haze gradient that blends with distant terrain so there is no visible seam.

#### Sun-angle lighting

Terrain is shaded by a directional sun source so that slopes facing the sun appear brighter and slopes in shadow darken toward the ambient level. Ridge-lines, valleys, canyons, and mesa edges become immediately recognisable. Default sun position is 45° elevation, SE azimuth (mid-morning). This is configurable in `pi4/svt_renderer_gl.py`.

#### Distance grid

A cyan grid aligned with cardinal directions is overlaid on the terrain to help judge distance and orientation.

- Minor lines every **0.5 nm** (counts squares to estimate distance)
- Major lines every **2 nm** (slightly brighter for longer-range reference)
- Lines fade toward the mesh edge to avoid clutter at the visible horizon
- Grid colours switch automatically: light cyan-white on brown terrain, dark blue on red/orange "above aircraft" terrain for contrast

The grid doubles as a heading reference — the N/S grid line is always parallel to true north, so a glance at the grid orientation relative to the aircraft symbol gives a crude no-compass heading check.

#### Zero-pitch reference line

A pair of short cyan hash marks across the AI mark the aircraft's **0° pitch reference** in the sky frame. With 3D SVT the visible horizon may be higher or lower than the actual 0° pitch position depending on terrain (for example, mountains above your altitude push the apparent horizon up). The zero-pitch line is independent of terrain — it always shows where level flight would put the nose.

- Drops below AI centre in climbs
- Rises above AI centre in descents
- Tilts with the horizon during banks
- Aligned exactly with the pitch ladder's 0° bar

When terrain is at or below your altitude, the zero-pitch line and the visible SVT horizon coincide.

#### No terrain data

When no SRTM tiles are loaded the SVT falls back to a traditional blue-sky-over-brown-ground split. The `NO TER` badge appears in the status strip.

### Pitch ladder

White pitch bars run from ±5° out to ±80° (every 5° to ±20°, every 10° beyond). The horizon bar is white; line length narrows progressively at extreme attitudes so the ladder reads clean during unusual-attitude recoveries. Scale is 10 px/° and matches the SVT horizon projection exactly so the 0° bar and the terrain horizon align at every pitch.

### Roll arc and pointer

Graduated arc at the top of the AI implementing the **sky-pointer** convention. The arc and tick marks (10°, 20°, 30°, 45°, 60°) rotate with the sky so that the fixed aircraft reference at the very top of the screen reads the current bank angle on the arc. A moving doghouse outside the arc marks the sky's "up" direction; a fixed reference inside the arc at the top marks the aircraft's current bank position.

### Aircraft symbol

Amber swept-delta wing symbol fixed at AI centre.

### Flight-path vector (velocity vector)

A cyan open circle with two short horizontal wings and a vertical stub marks the **flight-path vector (FPV)** — where the airplane is actually going through space, not where the nose is pointed. It's computed from GPS: azimuth = ground **track**, elevation = flight-path angle (`atan2(vertical speed, groundspeed)`).

- **Horizontal offset** from the aircraft symbol = drift/crab (track vs. heading). In a left crosswind the FPV sits right of the nose, and vice-versa.
- **Vertical offset** = the difference between pitch and flight-path angle. In a steady climb the FPV sits **below the nose by the angle of attack** — fly the FPV onto the runway numbers on approach and that's where you'll touch down, whatever the crab and AOA are doing.
- **Hidden below 5 kt** groundspeed (parked / taxi has no meaningful track).
- In an extreme attitude (or large crab) where the vector would fall outside the AI, it's **clamped to the edge as a small arrow** pointing toward the true off-screen vector, so the cue never just vanishes.

Toggle it on the DISPLAY setup screen — **FLIGHT PATH** (default **ON**). It draws over the synthetic-vision background and airport symbols, under the pitch ladder.

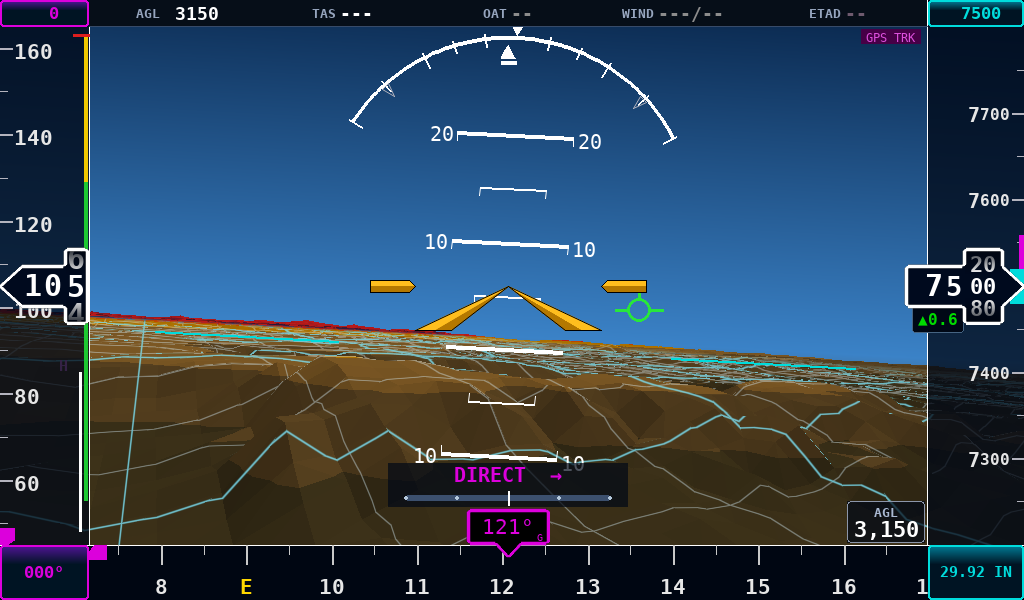
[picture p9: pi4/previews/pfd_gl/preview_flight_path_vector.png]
Flight-path vector — cyan circle/wings/stub sitting below and right of the nose in a climbing crab


### Slip/skid indicator

A short white horizontal bar (16×4 px) sits below the roll pointer's doghouse base and slides laterally with uncoordinated flight. Centred under the zero-bank triangle = ball-centered, coordinated flight. The bar moves in the same direction as the imaginary ball of a conventional inclinometer — step on the rudder toward the bar to re-centre it.

### Terrain / obstacle proximity alert

**TERRAIN CAUTION** (amber, steady) — terrain clearance below **500 ft** along the 45-second look-ahead, or an obstacle within the forward wedge below **500 ft** of the aircraft.

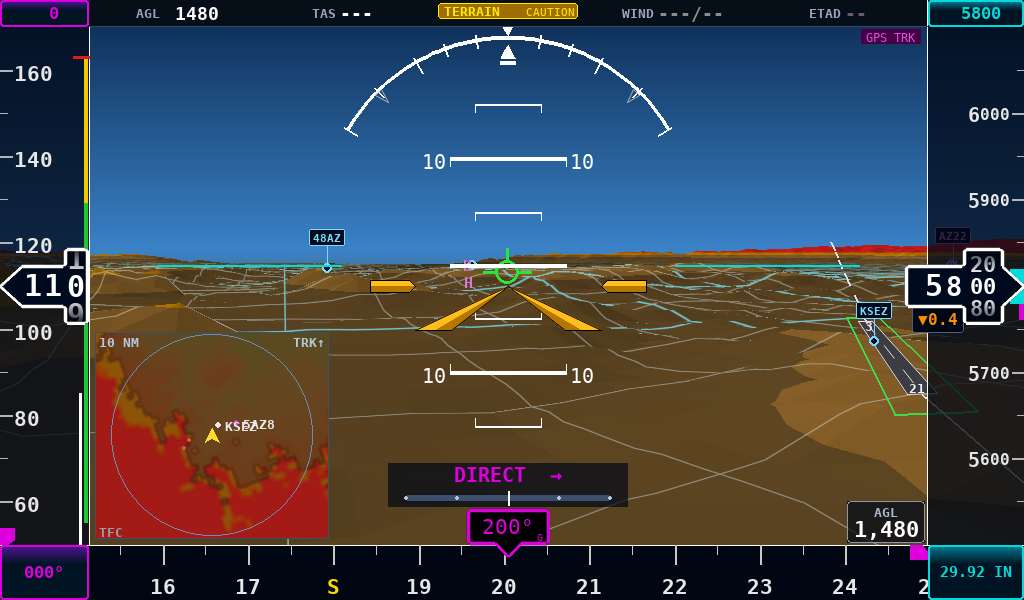
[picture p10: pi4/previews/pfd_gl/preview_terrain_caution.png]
Amber TERRAIN CAUTION banner during a descent into rising terrain


**PULL UP TERRAIN** (red, 1 Hz flash) — terrain clearance below **100 ft** along the look-ahead, or an obstacle within the forward wedge below **100 ft**.

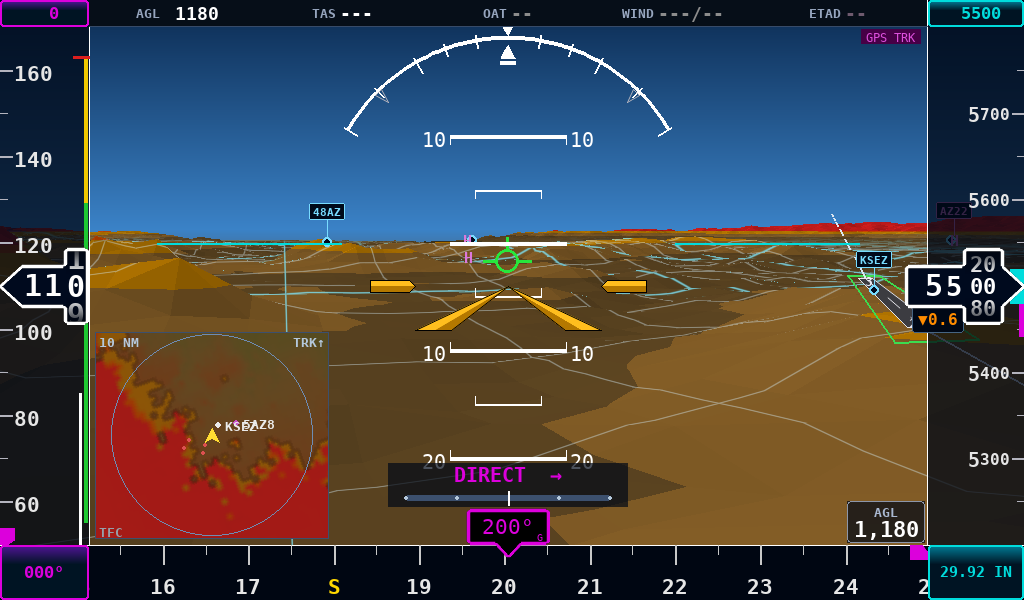
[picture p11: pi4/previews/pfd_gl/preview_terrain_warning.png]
Red PULL UP TERRAIN at critical clearance — flashes at 1 Hz


**TERRAIN look-ahead**: the alert isn't fired off your current ground point alone. Each render frame the PFD walks twelve samples along your current GPS ground track for 45 s of flight (≈ 1.2 NM at 100 kt), projects altitude forward at the current VSI, and trips the alert on the worst clearance encountered — same convention EGPWS / TAWS-B uses. The benefit is that you get the banner (and the voice callout) while there's still room to climb, not when you're already in the wall.

**Forward wedge**: obstacle proximity is filtered to a **±25° wedge** around the GPS ground track. A 1500 ft tower abeam or behind the wing won't fire the alert — only obstacles you're actually flying toward. The wedge is wider than the AI's angular FOV so a sloppy bank doesn't unhide a tower you were about to overfly.

**Low-speed inhibit**: alerts (terrain and obstacle, both banners *and* the voice callouts) are silenced below **VS0** (default 48 kt). This kills the nuisance fire during taxi, takeoff roll, and landing rollout where the aircraft is in continuous "ground-impact territory" by design. Sink-rate / bank-angle callouts share the same inhibit.

**Approach-corridor auto-inhibit**: when a synthetic approach is loaded (§16) and the aircraft is inside the published-approach corridor, TAWS callouts auto-suppress — same Mode 7 convention Honeywell MK V/VII and Garmin G3X use. The corridor is defined as:

- Within **5 NM** of the threshold along the approach course
- Cross-track within **±0.3 NM** of the published centreline (matches the CDI full-scale on approach)
- Altitude between threshold-elevation and threshold + **2 500 ft**

While the aircraft is in the corridor the look-ahead terrain / obstacle / pull-up alerts go quiet — you don't get nagged during a normal descent into a known runway environment. **Sink-rate stays armed** because "you're going down too fast at the runway" is the one cue that's still relevant on a stabilised approach. The moment the aircraft drifts outside the corridor (high deviation, way off centreline, missed approach, sidestep manoeuvre) every alert comes back automatically.

A `TER INH APR` amber badge appears in the status strip whenever the auto-corridor is gating callouts, so you can see at a glance that the TAWS safety net is currently off and that it's the approach that turned it off (not a stuck manual inhibit). The badge clears the instant the aircraft leaves the corridor or the approach is cancelled.

**Manual TERRAIN INHIBIT**: a pilot-controlled mute on the DISPLAY setup screen (§10). Tap **INHIBIT** to silence terrain + obstacle + pull-up callouts for **120 seconds**, after which the safety net comes back on automatically. Use it at known false-positive locations (low passes, off-airport landings, charted approaches into airports surrounded by terrain where the auto-corridor doesn't catch it). The status badge `TER INH Xs` appears in the badge strip with the remaining countdown so you can never forget the inhibit is on. A second tap clears the inhibit immediately. Sink-rate also stays armed under manual inhibit.

Requires GPS fix and SRTM tiles (terrain) or FAA obstacle data (obstacles) loaded.

Voice callouts for the same conditions live in §20. The full alert pipeline (banner + voice + on-AI red recovery cues at extreme attitudes) is designed so the pilot gets the same information whether their eyes are on the instruments or on the windscreen.

### Past 60° bank — sky/ground and pitch ladder agreement

At extreme bank the simple sky/ground polygon (used when there is no SRTM tile or when the unusual-attitude declutter has stripped the SVT mesh, see §21) is drawn from a roll-aware horizon **direction vector** rather than a fixed-up horizontal line. Past ±60° this prevents the brown half from sliding across the wrong side of the AI — the sky/ground split now agrees with the pitch ladder all the way to inverted, and the AI no longer flips to "all brown" when rolled past vertical.

### Roll-aware horizon point

The horizon point the SVT camera projects through is rotated with bank so that inverted flight no longer puts the entire SVT inside the brown half of the screen. Combined with the pitch-ladder Euler-chart fix (pitch >90° re-expressed as 180°−pitch with a 180° roll offset; see `normalize_attitude` in `pi4/pfd.py`) the AI stays drawable through over-the-top loops and split-S manoeuvres.

---

## 5. Heading Tape

### Heading source modes

Heading tape — MAG mode

**MAG mode (default):** Magnetometer heading. Dim border, `M` subscript.

**GPS TRK mode:** Heading slewed to GPS track via complementary filter. Magenta border, `G` subscript. `GPS TRK` badge appears.

### Track pointer

In MAG mode with GPS fix, a **magenta** tick shows GPS ground track (wind/crab indication). Magenta matches the PFD's data-source convention: GPS-derived values and indicators are magenta; sensor-derived values are cyan.

### Heading bug

Chevron on the tape. CYAN (MAG) / MAGENTA (GPS TRK). Settable via numpad or tap on tape.

### Magnetic vs True reference

A small **`MAG`** / **`TRU`** tag sits at the top-left of the heading box telling you which reference *all* headings and courses are shown in:

- **`MAG` (default, grey):** Magnetic — matches charts, plates, runway numbers and ATC clearances. The system computes everything internally in **true** and subtracts the local magnetic variation from the **WMM2025** world magnetic model at your GPS position. In Arizona that's about 10–11° east, so a runway labelled "03" reads ~030°, not the ~041° true it actually points.
- **`TRU` (amber):** True — every heading/course shown exactly as computed, no variation applied. The amber tag flags that you're off the charted (magnetic) convention.

The toggle is **Setup → Display → UNITS → HDG / CRS REF**. It is one global setting: the heading tape, the data-strip `TRK` / `HDG` / `BTW` / `DTK` / `WIND` fields, the CDI/direct-to bearing, and the flight-plan leg courses all follow it. The choice persists across power cycles and is per-display (each screen can differ). Without a GPS fix the system can't look up variation, so MAG mode shows true until a fix is acquired.

> The magnetometer is still calibrated against *true* cardinals (the compass-cal wizard is unchanged); MAG mode is purely a display conversion, so the internal navigation math is unaffected.

---

## 6. Status Badges

Blank during normal flight. Appear only when attention required.

| Badge | Colour | Meaning |
|---|---|---|
| `AHRS FAIL` | Red | IMU data absent or invalid |
| `NO LINK` | Red | SSE stream not connected |
| `NO TER` | Amber | No SRTM terrain tiles loaded |
| `NO OBS` | Amber | No FAA obstacle data loaded |
| `EXP OBS` | Orange | Obstacle data > 28 days old |
| `NO APT` | Amber | No airport data loaded |
| `EXP APT` | Orange | Airport data older than expiry |
| `TER INH` *N*`s` | Amber | TAWS callouts muted by the pilot, *N* seconds remain on the 120 s inhibit |
| `TER INH APR` | Amber | TAWS callouts auto-inhibited because the aircraft is inside the approach corridor of an active synthetic approach (§16). Clears automatically when you leave the corridor or cancel the approach. |
| `GPS TRK` | Magenta | GPS TRK heading mode active |
| `GPS ALT` | Amber | Altitude from GPS (baro failed) |
| `NO FIX` | Amber | GPS hardware responding (NMEA flowing) but no satellite lock yet — acquiring. A shadow/peer display mirrors the source's GPS, so it too shows **NO FIX** (not NO SIGNAL) while the source is still acquiring. |
| `NO SIGNAL` | Red | GPS hardware not responding (no NMEA at all). If GPS is the only position source, airspeed/altitude also show a red ✕. |

---

## 6A. PFD Top Ribbon

The band across the top of the attitude indicator — between the **groundspeed** bug box (top-left) and the **altitude** bug box (top-right) — is a **configurable 5-slot readout ribbon**. It gives you a row of glanceable numbers on the PFD itself, separate from the MFD's bottom data strip (§15).

PFD top ribbon — AGL · TAS · OAT · WIND · ETAD across the top of the AI, between the GS and ALT bug boxes

**Default fields:** **AGL · TAS · OAT · WIND · ETAD** — height above terrain, true airspeed, outside air temperature, wind direction/speed, and estimated arrival at the final destination.

**Configuring it.** **Tap the ribbon** to open its field picker: the five current slots show as pills across the top (the selected one ringed cyan); tap a field in the grid to assign it, and the selection auto-advances to the next slot so you can fill the row with successive taps. It draws from the **same field set as the MFD data strip** — groundspeed, airspeed, TAS, track, heading, altitude, AGL, VS, WIND, UTC, baro, satellites, and the nav-derived WPT · BTW · DTK · DIST · DISTD · XTE · ETE · ETED · ETA · ETAD. See **§15** for the full field table and the **ARRIVAL TIME (LOCAL / ZULU)** toggle that governs the ETA/ETAD readouts.

**Independent of the MFD strip.** The PFD ribbon keeps its **own** 5-slot selection — changing it doesn't touch the MFD's 8-slot strip, and vice-versa. Both persist in `data/settings.json` across power cycles.

**Values fill when their source is live.** A field reads `--` (or `---/--` for WIND) until its data is available: AGL needs terrain data, TAS/OAT/WIND need air-data (WIND is computed from the TAS + GPS-track triangle when there's no OAT sensor), and ETAD needs an active flight plan or Direct-To.

**Alerts win.** When an annunciation fires (terrain, traffic, etc.) it paints over the ribbon, so a warning is never hidden behind a readout.

---

## 7. Setting Bugs

Three bugs — altitude, heading, ground-speed — plus the baro setting. All four use the same numpad overlay.

### Bug buttons on the PFD

Four tap targets sized for gloved / in-turbulence use. The bug buttons fill the full heading-strip height (55 px on 1024×600) so they're easy to hit without looking away from the horizon.

| Button | Location | Opens |
|---|---|---|
| **Speed bug** | Top of airspeed tape | SET SPD BUG |
| **Altitude bug** | Top of altitude tape | SET ALTITUDE BUG |
| **HDG bug** | Bottom-left of heading strip | SET HDG BUG |
| **Baro** | Bottom-right of heading strip | SET BARO inHg / SET BARO hPa |

### Numpad entry

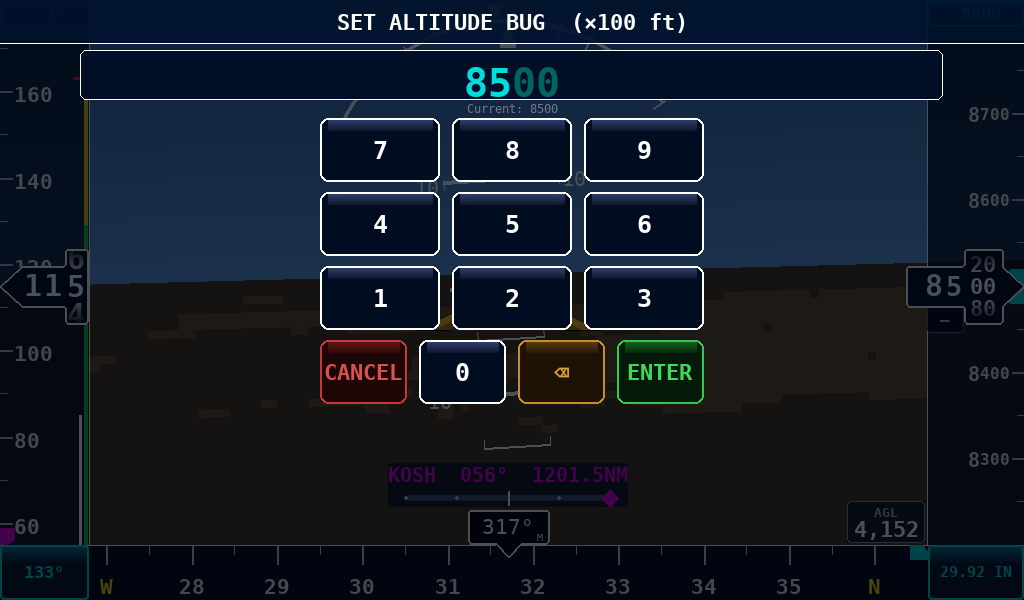
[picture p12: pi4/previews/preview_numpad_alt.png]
Altitude bug numpad — current value 8500 shown as placeholder, new value being typed


Tap the readout button. The numpad slides in over the live PFD so attitude remains visible behind the keys.

**Current value is shown as a dim placeholder** under the entry field — the input starts empty so typing ENTER without changing anything keeps the previous bug value. Typing overwrites; ⌫ backspaces the buffer.

| Target | Entry | Example |
|---|---|---|
| Altitude | hundreds of feet | `85` → `8500 ft` |
| Heading | 3 digits | `270` → `270°` |
| Speed  | whole knots | `90` → `90 kt` |
| Baro (inHg) | 4 digits, decimal auto-inserted | `2992` → `29.92 in` |
| Baro (hPa) | plain integer | `1013` → `1013 hPa` |

Numpad keys: `0`–`9`, **CANCEL**, **⌫** (backspace — deletes one character from the buffer), **ENTER**. The numpad is centred under the AI so the fingers rest below the horizon while typing.

### Baro entry

The baro numpad title switches between **SET BARO inHg** and **SET BARO hPa** based on the unit selected in Display Settings. The pre-populated placeholder shows the current baro setting in whichever unit is active.

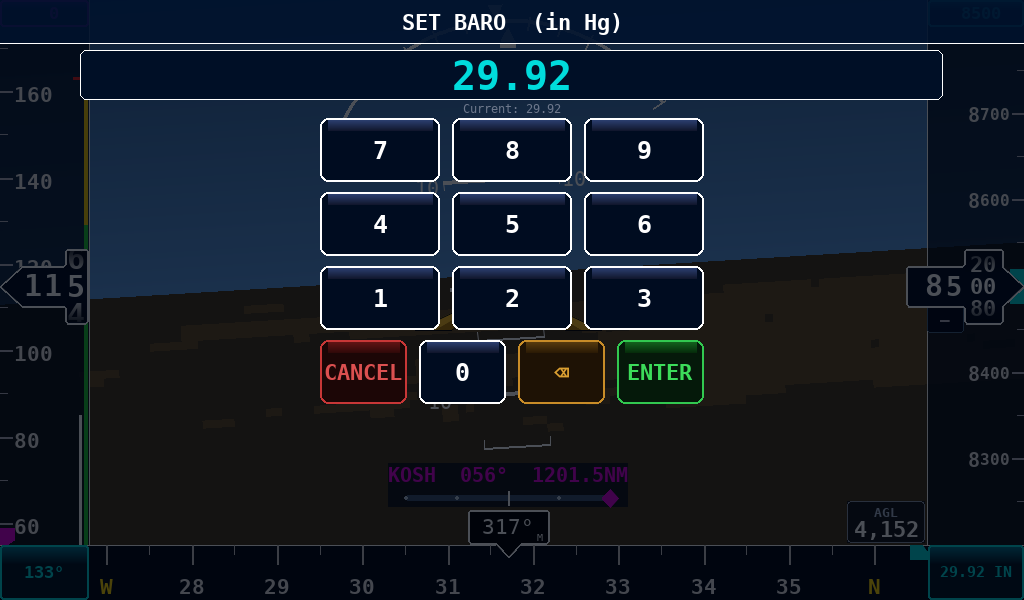
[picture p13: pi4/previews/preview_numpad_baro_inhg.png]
Baro inHg

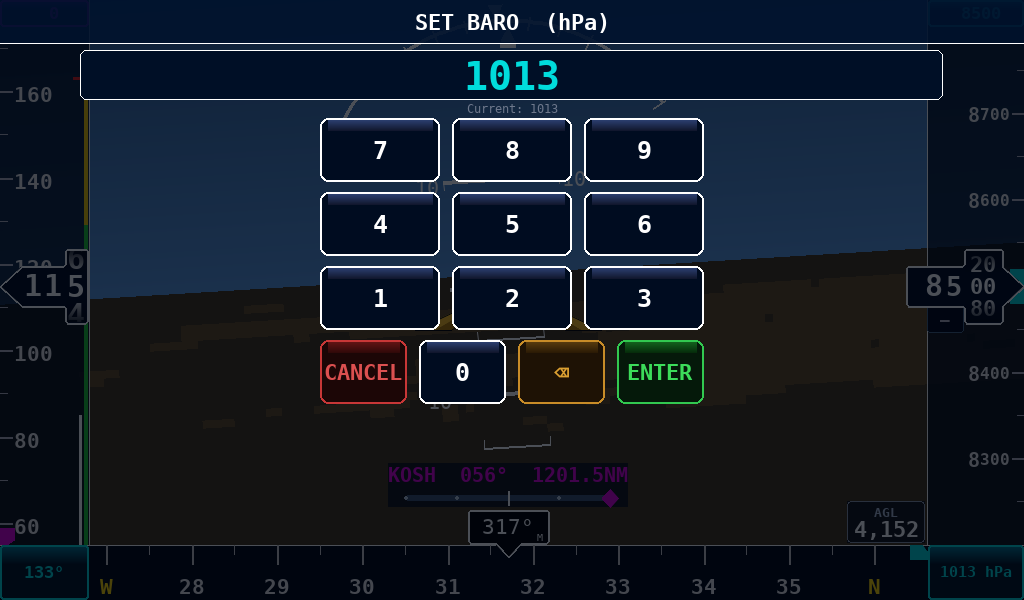
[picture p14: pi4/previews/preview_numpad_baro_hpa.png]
Baro hPa


### Tape taps

Tap heading tape → jump HDG bug. Tap altitude tape → jump alt bug (nearest 100 ft). These are fine-positioning shortcuts — the buttons and numpad are for precise values.

### Clear

Enter `0` + **ENTER**. Clears the bug (alt/spd/hdg); for baro this resets to 29.92 in / 1013 hPa.

---

## 8. Setup Menu

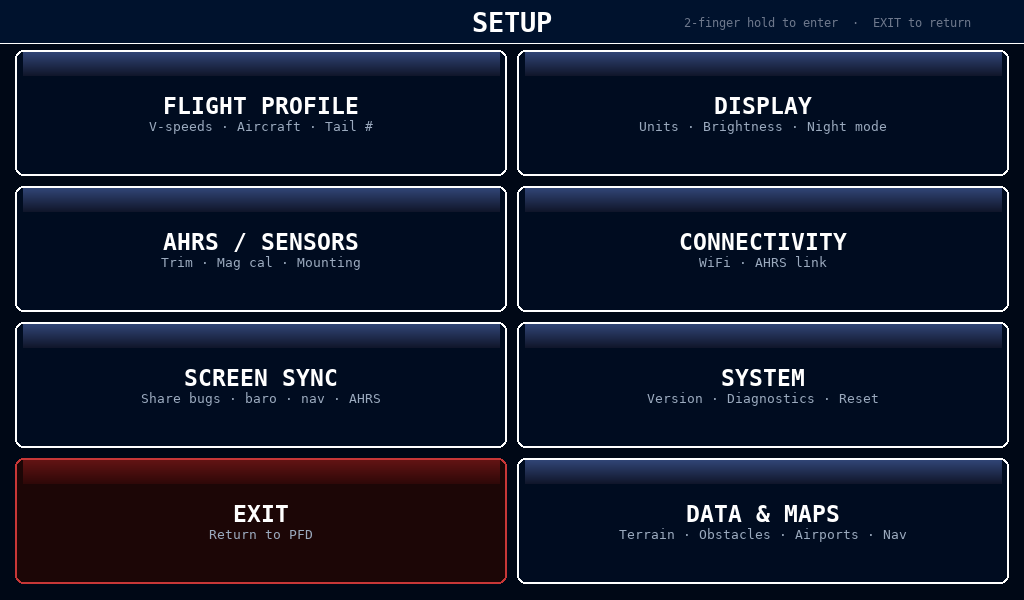
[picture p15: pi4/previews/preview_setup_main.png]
Main setup screen


Two-finger hold 0.8 s → six tiles: FLIGHT PROFILE, DISPLAY, AHRS / SENSORS, CONNECTIVITY, SYSTEM, EXIT.

---

## 9. Flight Profile — V-Speeds and Callsign

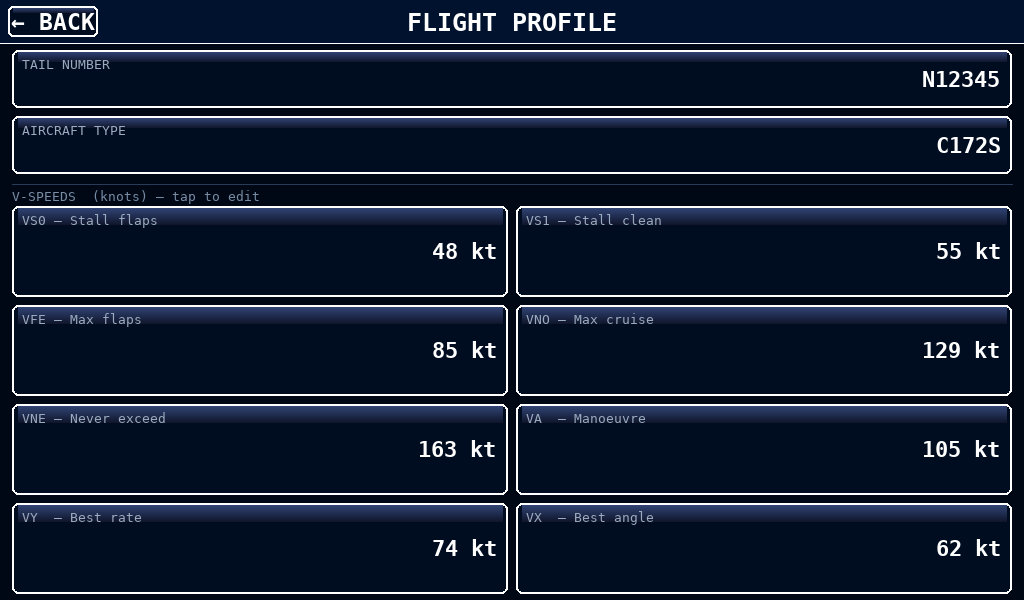
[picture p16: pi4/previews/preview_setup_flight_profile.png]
Flight profile screen


Cessna 172S defaults: VS0=48, VS1=55, VFE=85, VNO=129, VNE=163, VA=105, VY=74, VX=62 kt.

Tap any V-speed box to change — the numpad opens with the current value shown as a dim placeholder. RESET DEFAULTS restores all.

### Keyboard — tail number and aircraft type

Tap **CALLSIGN** or **A/C TYPE** to open the on-screen keyboard.

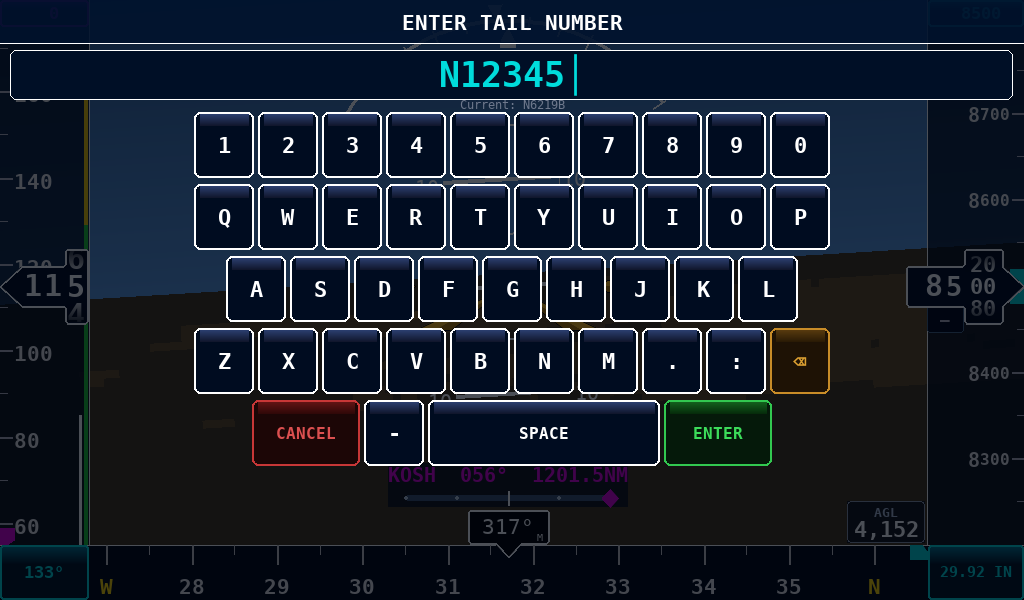
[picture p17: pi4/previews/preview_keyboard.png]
Keyboard — 1234567890 / QWERTY / ASDF / ZXCVBNM.: + CANCEL / - / SPACE / DONE


Four rows:

1. Digits `1 2 3 4 5 6 7 8 9 0`
2. `Q W E R T Y U I O P`
3. `A S D F G H J K L`
4. `Z X C V B N M` + period (`.`), colon (`:`), and **⌫** backspace

Action row across the bottom: **CANCEL** (discard), hyphen (`-`), **SPACE**, **DONE** (commit).

The period and colon keys are useful for entering URLs (e.g. `http://192.168.4.1`) on the Connectivity screen — the same keyboard is used there. The current field value appears pre-populated so you can edit in place rather than re-typing from scratch; the ⌫ backspace key deletes one character at a time from the end of the buffer.

---

## 10. Display Settings

The screen is split into four tabbed sub-pages — **UNITS**, **DISPLAY**, **MAP**, and **HORIZON** — selected from the tab bar under the header. Tapping a tab swaps the visible rows; each page fits without scrolling. The screen opens on **UNITS**. The current tab is not persisted — the screen always reopens on UNITS.

**UNITS** — speed / altitude / pressure:

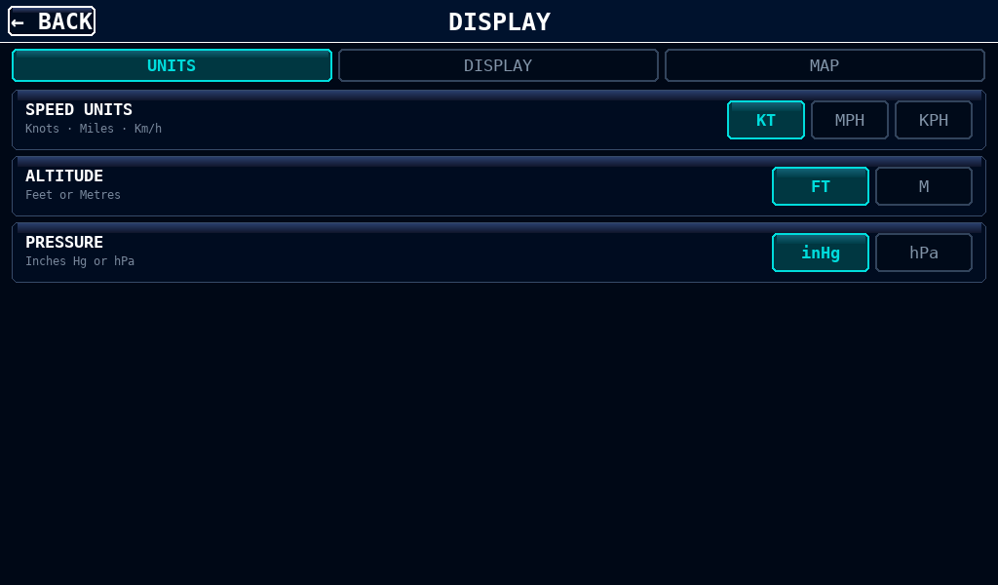
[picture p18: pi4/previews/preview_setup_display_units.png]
Display settings — UNITS tab


**DISPLAY** — brightness, alert audio/volume, sun position, flight path:

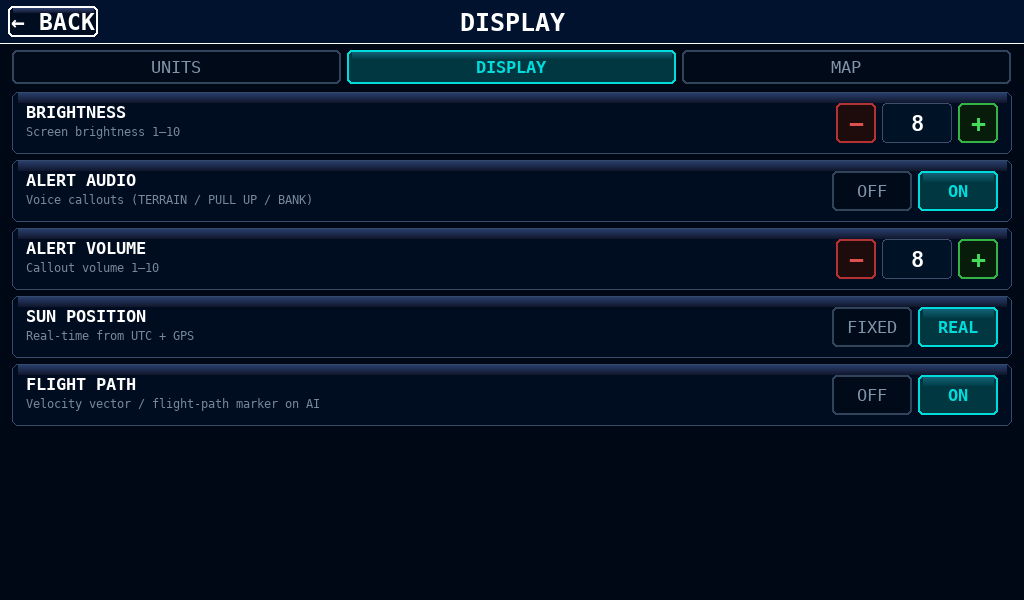
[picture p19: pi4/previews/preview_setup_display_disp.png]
Display settings — DISPLAY tab


**MAP** — inset enable/orient, range, winds level, traffic filters, MAP LAYERS:

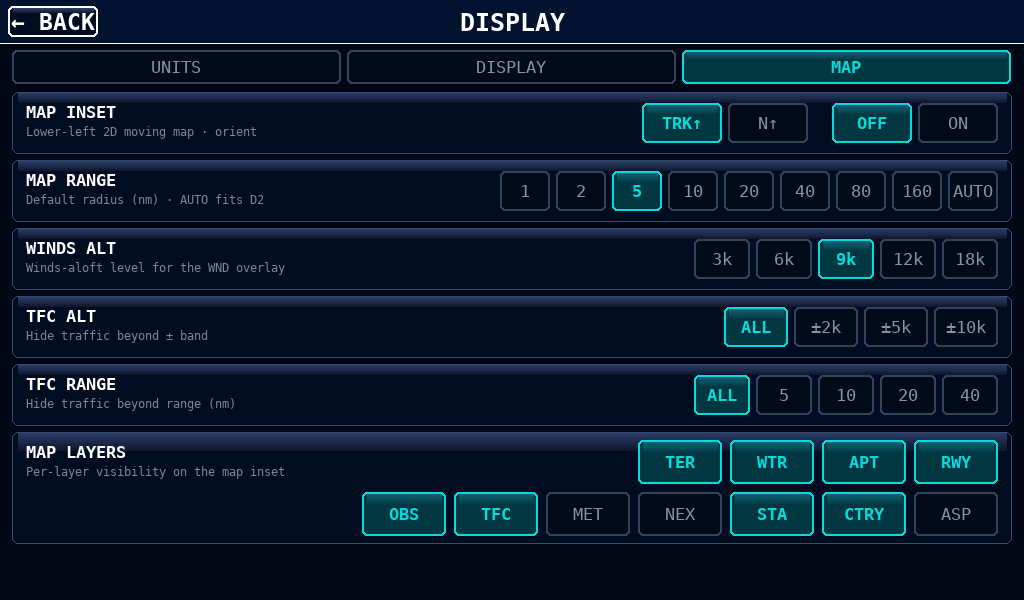
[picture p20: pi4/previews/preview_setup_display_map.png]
Display settings — MAP tab


| Tab | Row | Options | Default | Notes |
|-----|-----|---|---|---|
| UNITS | **SPEED UNITS** | KT / MPH / KPH | KT | Speed tape + bug numpad units. |
| UNITS | **ALTITUDE** | FT / M | FT | Altitude tape, bug, AGL readout. |
| UNITS | **PRESSURE** | inHg / hPa | inHg | Baro setting; numpad title and entry mode follow this. |
| UNITS | **HDG / CRS REF** | MAG / TRUE | MAG | Reference for *all* displayed headings and courses (heading tape, TRK/HDG/BTW/DTK/WIND strip fields, CDI bearing, FPL leg courses). MAG applies WMM2025 magnetic variation at GPS position so the numbers match charts/plates/ATC; TRUE shows the raw computed values. The heading box carries a `MAG` / `TRU` tag. See §5. |
| DISPLAY | **BRIGHTNESS** | 1 – 10 | 8 | Backlight level. Routed to the active backlight transport (see below). |
| DISPLAY | **ALERT AUDIO** | OFF / ON | ON | Master mute for the voice-callout pipeline. When OFF, terrain / obstacle / sink-rate / bank-angle callouts are suppressed and any in-flight clip is cut. The visual banners stay on regardless. |
| DISPLAY | **ALERT VOLUME** | 1 – 10 | 8 | Callout volume scale. 0 is effectively muted; 10 is unity. Applied live to the pygame mixer; takes effect on the next callout. |
| DISPLAY | **SUN POSITION** | FIXED / REAL | REAL | SVT terrain lighting: FIXED uses a SE mid-morning sun; REAL pulls UTC + GPS lat/lon through the NOAA solar formulas. |
| DISPLAY | **FLIGHT PATH** | OFF / ON | ON | Flight-path vector (velocity-vector) marker on the AI. See §4. |
| DISPLAY | **HITS BOXES** | OFF / ON | ON | Highway-in-the-sky approach corridor — the cyan 3D boxes drawn on the AI during an active synthetic approach (§16). Turn off to declutter the AI on approach; the VDI / CDI still work. |
| DISPLAY | **TERRAIN INHIBIT** | INHIBIT button | (off) | Mute all TAWS callouts (terrain look-ahead, obstacle, pull-up) for 120 s. Sink-rate stays armed — the descent-rate alert still applies even while inhibited. Status row shows the countdown while active; an amber `TER INH Xs` badge also appears in the badge strip. Second tap clears the inhibit early. Auto-clears on timeout. |
| MAP | **MAP INSET** | OFF / ON + TRK↑ / N↑ | OFF · TRK↑ | Lower-left 2D moving-map inset and its rotation mode. See §17. |
| MAP | **MAP RANGE** | 1/2/5/10/20/40/80/160 NM · AUTO | 5 NM | Default inset radius; AUTO fits to the active direct-to. |
| MAP | **WINDS ALT** | 3k / 6k / 9k / 12k / 18k ft | 9k | Winds-aloft level shown on the WND overlay. See §16. |
| MAP | **TFC ALT** | ALL / ±2k / ±5k / ±10k ft | ALL | Hide traffic outside this relative-altitude band. See §16G. |
| MAP | **TFC RANGE** | ALL / 5 / 10 / 20 / 40 NM | ALL | Hide traffic beyond this range. |
| MAP | **MAP LAYERS** | TER · WTR · APT · RWY · OBS · TFC · MET · NEX · STA · CTRY · ASP (independent pills) | all ON | Per-layer visibility for the moving-map inset. **TER** terrain tint; **WTR** ocean/lake water mask; **APT** airport / heliport / seaplane symbols; **RWY** runway outlines; **OBS** FAA DOF obstacles; **TFC** traffic; **MET** METAR station dots (idents labelled when zoomed in below 160 NM range); **NEX** NEXRAD; **STA** state / province boundary lines (Natural Earth admin_1, slate-blue, fades in at ≥ 20 NM); **CTRY** country boundary lines (Natural Earth admin_0, tan, also ≥ 20 NM); **ASP** airspace. Toggles are independent and persist in `data/settings.json`. |
| HORIZON | **PITCH TRIM** | ± steppers | 0.0° | 0.1° per tap. Display-side cosmetic offset for a horizon that sits a touch above/below level. Separate from the AHRS **ZERO** (§11) — this only nudges the drawn horizon on this display; the AHRS's own solution is untouched. |
| HORIZON | **ROLL TRIM** | ± steppers | 0.0° | 0.1° per tap. Display-side cosmetic offset for a wing that reads slightly low. |

### Backlight transports

`BRIGHTNESS` writes to whichever backlight control is wired:

1. **sysfs** — `/sys/class/backlight/rpi_backlight/brightness` (Waveshare 3.5" DPI; some HDMI panels with backlight pads on the DSI bus expose the same node).
2. **DDC/CI** — `ddcutil` on the i2c-N bus matching a panel that speaks VESA MCCS. The ROADOM 7" / 10" HDMI panels fall into this bucket. Writes are background-threaded and serialised so a brightness drag never blocks the render loop.
3. **None** — neither found; the slider still works in the UI but won't change panel output. Diagnostic logs print `[BL] No backlight control available` at startup.

The Pi 4 setup script installs `ddcutil` and pre-loads the `i2c-dev` module. If brightness control silently does nothing on an HDMI panel, run `sudo ddcutil detect` to confirm the panel responds and that `Brightness (10)` is in its VCP feature list.

### Alert volume / mute persistence

`ALERT AUDIO` and `ALERT VOLUME` persist with the rest of the display settings in `data/settings.json` and reload at boot, so the speaker level you set on the bench is what powers up in the cockpit. The startup self-test fires a one-shot `"terrain"` callout at boot (unless ALERT AUDIO is OFF) so you can confirm the speaker is alive without waiting for a real alert.

---

## 11. AHRS / Sensors

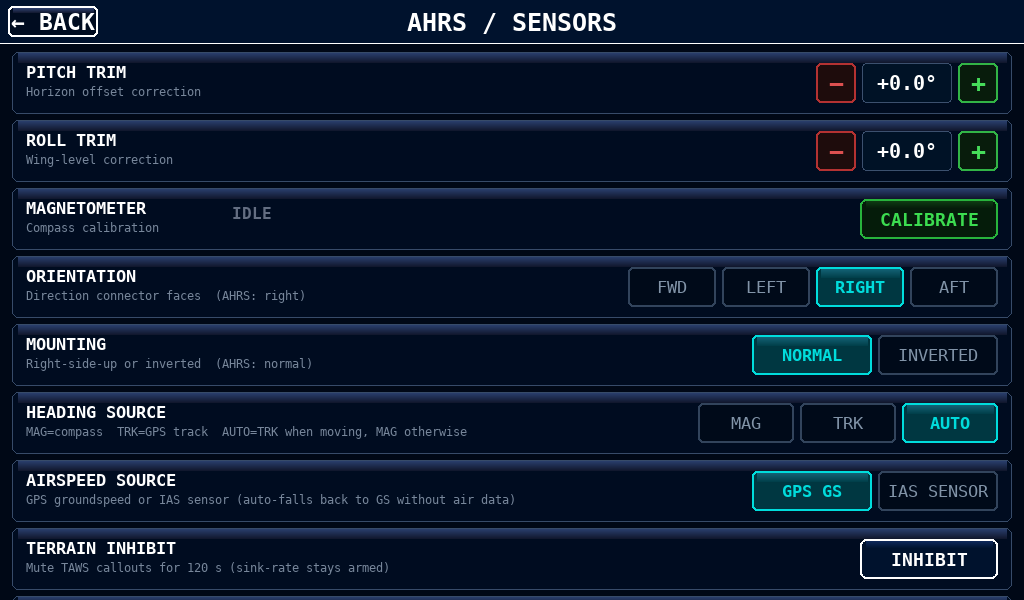
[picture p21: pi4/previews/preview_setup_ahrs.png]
AHRS setup screen


Each row on this screen is independent:

This page now holds **only AHRS-sensor settings** — the sensor **ZERO** and the align/mounting/compass/airspeed setup. The display-side **PITCH / ROLL TRIM** (a cosmetic horizon nudge) moved to **DISPLAY → HORIZON** (§10) so the AHRS zero and the display zero aren't mixed in the same space.

| Row | Control | Default | Notes |
|-----|---|---|---|
| **PITCH ALIGN** | ± steppers + **ZERO** button | 0.0° | Input-side axis alignment — rotates the raw gyro/accel/mag *before* the filter to cancel a mounting tilt. **ZERO** (green, this row) is the one-tap AHRS flight-zero — see below. |
| **ROLL ALIGN** | ± steppers | 0.0° | Roll-axis half of the same input-side alignment. |
| **MAGNETOMETER** | CALIBRATE button | (idle) | Opens the 8-point compass-cal wizard (N / NE / E / SE / S / SW / W / NW). Cal is stored *on the AHRS* in flash, so both Pi 4 and Pi Zero displays read the same calibrated heading off the SSE / USB broadcast. Status row shows `max \|Δ\| X.X°` once a cal is committed. |
| **ORIENTATION** | FWD / LEFT / RIGHT / AFT | RIGHT | Which side of the AHRS the connector points toward, viewed from the pilot's seat. |
| **MOUNTING** | NORMAL / INVERTED | NORMAL | Whether the AHRS is right-side-up or upside-down. Independent of orientation. |
| **HEADING SOURCE** | MAG / TRK / AUTO | AUTO | Magnetometer, GPS ground track (via complementary filter), or auto-select (TRK in motion, MAG when stationary). |
| **AIRSPEED SOURCE** | GPS GS / IAS SENSOR | IAS SENSOR | IAS from the SDP33-1500Pa differential-pressure sensor (default when `airdata_ok`). Forced fallback to GPS groundspeed when the sensor is unhealthy or the pilot pins it manually. |

**ZERO (AHRS flight zero).** The green **ZERO** button on the PITCH ALIGN row re-zeros the **AHRS itself** to the current attitude — the "Level" cage a Sentry gives ForeFlight. Fly straight-and-level, tap it once, and the AHRS treats your present orientation as its new level.

This is a true **sensor** zero, not a display trim: it folds the captured attitude into the AHRS **input-side axis alignment** (the `PITCH ALIGN` / `ROLL ALIGN` steppers it sits on), which rotates the raw gyro/accelerometer/magnetometer *before* the attitude filter runs. The new alignment is pushed to the AHRS (over USB `$ALIGN`, or HTTP `/align` on a WiFi link), **persisted in the AHRS flash**, and seen identically by every display. Because it corrects the mounting tilt at the sensor input, it also removes the yaw-into-pitch/roll coupling that makes a small static error *compound in turns* — the failure mode that makes an un-levelled AHRS unusable. Use it whenever you couldn't do a full ground level.

Notes: the correction is clamped to the AHRS's ±15° alignment range (a residual larger than that is a wrong ORIENTATION/MOUNTING, not a trim job — fix those first). Tapping it also clears any leftover display-side PITCH/ROLL TRIM so the zero isn't double-counted. It's reversible from the PITCH ALIGN / ROLL ALIGN steppers, and you can re-tap any time. On a display connected to the AHRS over WiFi only, the push uses the HTTP `/align` endpoint.

### Mounting and orientation

The AHRS box can be installed with the connector facing any of four directions, plus right-side-up or upside-down:

- **ORIENTATION = RIGHT** (default): connector toward the right wing. No transform applied.
- **ORIENTATION = FWD**: connector toward the nose. Pitch and roll axes swap; magnetic heading shifted +90°.
- **ORIENTATION = LEFT**: connector toward the left wing. Pitch and roll both negate; heading shifted +180°.
- **ORIENTATION = AFT**: connector toward the tail. Pitch and roll axes swap (opposite of FWD); heading shifted +270°.

Combine with **MOUNTING = INVERTED** for upside-down installs — the inversion is a separate flip about the longitudinal axis applied after orientation.

The base AHRS firmware reports yaw and roll with an ENU-style sign convention; the display assumes NED. The PFD negates roll and yaw at the base before any orientation transform layers on, so once you've picked the right ORIENTATION + MOUNTING the AI banks the same direction as the airplane and the heading number rises when you turn right. Pitch is unchanged between the two conventions.

**Sim and Demo modes bypass every AHRS-mounting compensation** (orientation, mounting, base correction, trim, compass cal) so a calibrated trim doesn't show up as wing-down on a level sim flight.

### Compass calibration (8-point walk-through)

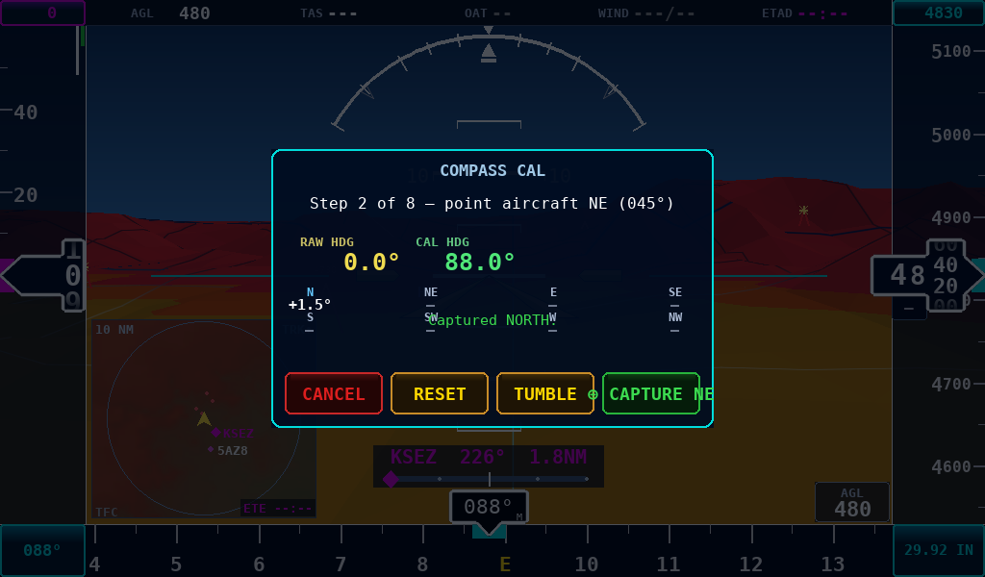
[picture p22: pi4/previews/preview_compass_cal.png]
Compass cal wizard — point cardinal / intercardinal, capture, repeat


Tap CALIBRATE on the MAGNETOMETER row to open the wizard. Step through eight headings, holding each one steady before you tap CAPTURE:

1. **N** (000°) → **⊕ CAPTURE N** (or press ENTER on a keyboard).
2. **NE** (045°) → CAPTURE NE.
3. **E** (090°) → CAPTURE E.
4. **SE** (135°) → CAPTURE SE.
5. **S** (180°) → CAPTURE S.
6. **SW** (225°) → CAPTURE SW.
7. **W** (270°) → CAPTURE W.
8. **NW** (315°) → CAPTURE NW.

The modal shows live readouts for **RAW HDG** (the raw compass output before cal) and **CAL HDG** (with the cal applied), plus the captured Δ values laid out in two rows of four (N / NE / E / SE on top, S / SW / W / NW below). After the eighth capture the cal commits automatically.

| Button | Action |
|---|---|
| **EXIT** | Close the modal. The cal commits on the 8th capture so this is non-destructive. Reads CANCEL only mid-walk when there are partial captures still in flight to the AHRS. |
| **RESET** | Wipe the stored cal back to zero (sends `$MAGDEV,CLEAR` to the AHRS, or `/magcal?action=clear` over Wi-Fi). |
| **RESTART** | Abandon partial captures and restart the eight-capture sequence. |
| **⊕ CAPTURE *X*** | Record the current heading at the cardinal/intercardinal indicated by *X*. Available throughout. |

### Hard-iron calibration (TUMBLE)

The cal modal also has a **TUMBLE** flow — a faster hard-iron calibration that doesn't need you to find headings. Tap **TUMBLE** and then, over about **30 seconds**, slowly rotate the AHRS unit through **all** orientations (roll it, pitch it, yaw it — like polishing every face of a ball). The modal shows the **elapsed time** and the live **per-axis spread** (the min–max range the magnetometer has seen on X / Y / Z) so you can tell when you've covered enough; keep going until each axis stops growing. Tap **STOP TUMBLE** to finish.

The firmware tracks the min/max on each magnetometer axis during the tumble and, on finish, solves the **hard-iron offset** as the centre of that ellipsoid `((min+max)/2)` per axis, writes it to flash, and applies it before computing yaw. It drives the same `/magoff?action=tumble_start` / `tumble_finish` endpoints (over Wi-Fi or USB serial) and persists like the deviation table below — on the **AHRS**, so every display benefits.

Use TUMBLE when you can move the unit freely (bench, or a handheld unit before mounting); use the 8-point walk-through when it's already panel-mounted and you can only swing the airplane. *(The Pi Zero still has the 8-point flow only — its TUMBLE port is pending.)*

### Storage — AHRS-side, not display-side

Magnetometer calibration and the AHRS orientation / mounting selection both live in flash **on the Pico W**, not in the display's `settings.json`. The wizard builds a 36-point deviation table from your eight samples (linear interpolation per 10° slot) and pushes it to the AHRS over the USB serial link (`$MAGDEV,<36 floats>`) or the Wi-Fi config endpoint (`GET /magcal?action=set&t=…`). The Pico writes the table to `magdev.json` on its own filesystem and applies it before broadcasting yaw on the SSE / `$AHRS` stream. Same for orientation / mounting (`$ORIENT,connector,mounting` → `orient.json`).

Practical consequences:

- **Both displays see the same calibrated heading** — Pi 4, Pi Zero, and the iPhone PWA all consume the AHRS's pre-corrected yaw. You don't need to redo cal per display.
- **Re-flashing the display SD card doesn't lose the cal.** The cal sits on the AHRS, not on the display.
- **Re-flashing the Pico firmware does** — the deviation table lives on the Pico flash filesystem; a clean reflash wipes it. Re-run the wizard after a Pico re-flash.
- **The Pi 4 also keeps a local 36-point table** (`pi4_magdev` in `settings.json`) that it applies on top of the broadcast yaw if the push to the Pico fails (the wizard tries USB first, falls back to HTTP). This is a belt-and-braces second copy, not the source of truth.

The 36-point form on the AHRS gives finer resolution than the 8-sample input — at render time the firmware interpolates between adjacent slots so each 10° heading window has its own correction. Same convention as a real aircraft compass swing card; strictly better than a single average offset for sinusoidal hard-iron or higher-order soft-iron error.

### Heading source — MAG / TRK / AUTO

- **MAG** — magnetometer heading from the AHRS. Compass cal applies. Fastest response; subject to local magnetic deviation.
- **TRK** — GPS ground track via a complementary filter (high-frequency from AHRS yaw rate, low-frequency from GPS track). Shows the direction the aircraft is actually moving over the ground, including wind drift.
- **AUTO** — TRK while moving above ~3 kt ground speed; MAG when stationary or below the threshold (where GPS track is meaningless). Default.

Displayed heading sub-tag: `M` (cyan) for MAG, `G` (magenta) for TRK. AUTO shows whichever it's currently using.

The compass calibration only affects MAG-mode display. TRK mode is naturally drift-free because it's slaved to GPS ground track — a constant cal correction's frame-to-frame derivative blends invisibly into the complementary filter.

### AHRS firmware update

The AHRS firmware loader pushes `firmware.py` to the Pico W AHRS over the USB serial link. Tap the loader, and it transfers the firmware and reboots the Pico, showing a `Pushed firmware.py ✓` done state on success. (Re-flashing the Pico wipes the on-AHRS compass cal — re-run the wizard afterward, see Storage above.)

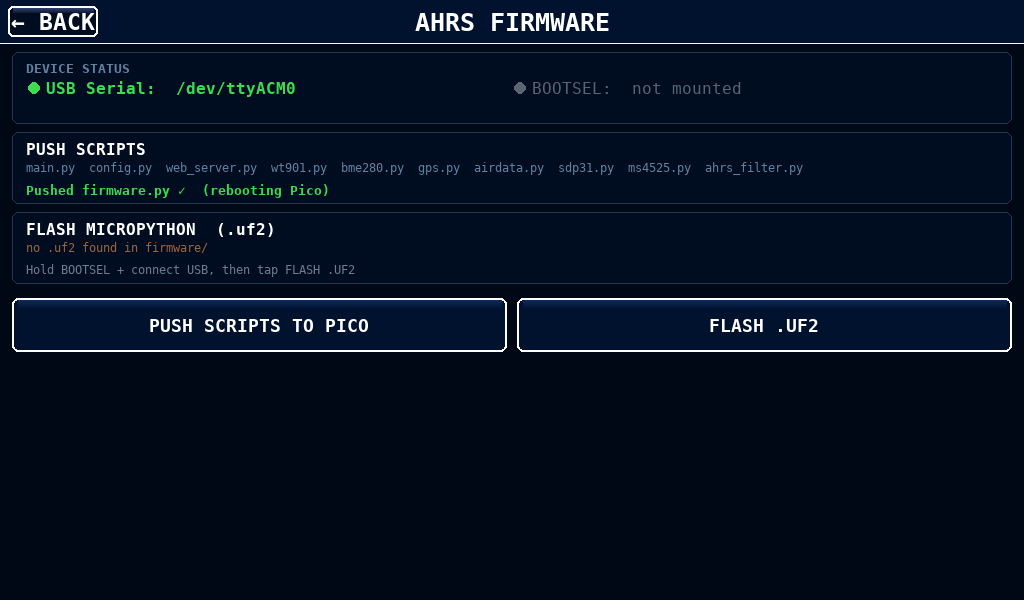
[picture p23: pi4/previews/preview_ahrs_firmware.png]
AHRS firmware loader — pushes firmware.py to the Pico W AHRS over USB, "Pushed firmware.py ✓" done state


---

## 12. Connectivity

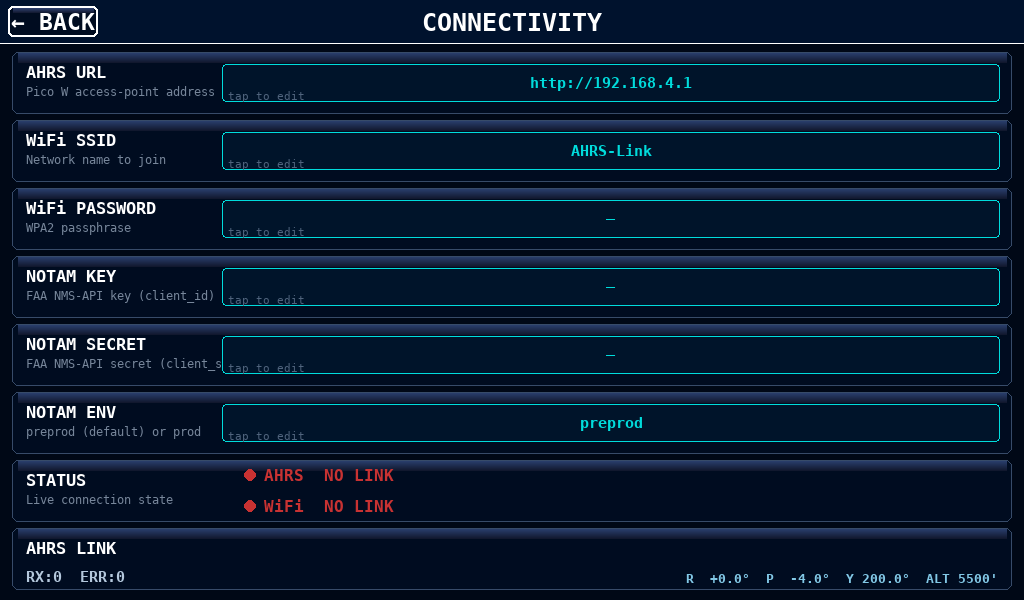
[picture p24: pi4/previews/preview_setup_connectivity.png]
Connectivity screen — editable fields, live STATUS badges, AHRS LINK diagnostics, live R/P/Y/ALT values


Editable fields + two status rows + two action buttons.

### Editable fields

Tap any value box to open the keyboard and edit.

| Field | Purpose | Default |
|---|---|---|
| **AHRS URL** | Pico W access-point address | `http://192.168.4.1` |
| **WiFi SSID** | Network name the Pi should join (for downloads) | `AHRS-Link` |
| **WiFi PASSWORD** | WPA2 passphrase | (blank; not persisted) |
| **NOTAM KEY** | FAA NMS-API client_id | (blank) |
| **NOTAM SECRET** | FAA NMS-API client_secret (masked) | (blank) |
| **NOTAM ENV** | NMS environment: `preprod` (default) or `prod` | `preprod` |

The Wi-Fi password is intentionally **not** stored in `settings.json` and must be re-entered when you switch networks — see §13.

Rather than type the SSID by hand, tap the WiFi SSID field to open the **WIFI NETWORKS** scan list: nearby networks with signal-strength bars and a **WPA** / **OPEN** tag, plus a **RESCAN** button. Tap a network to drop it into the SSID field.

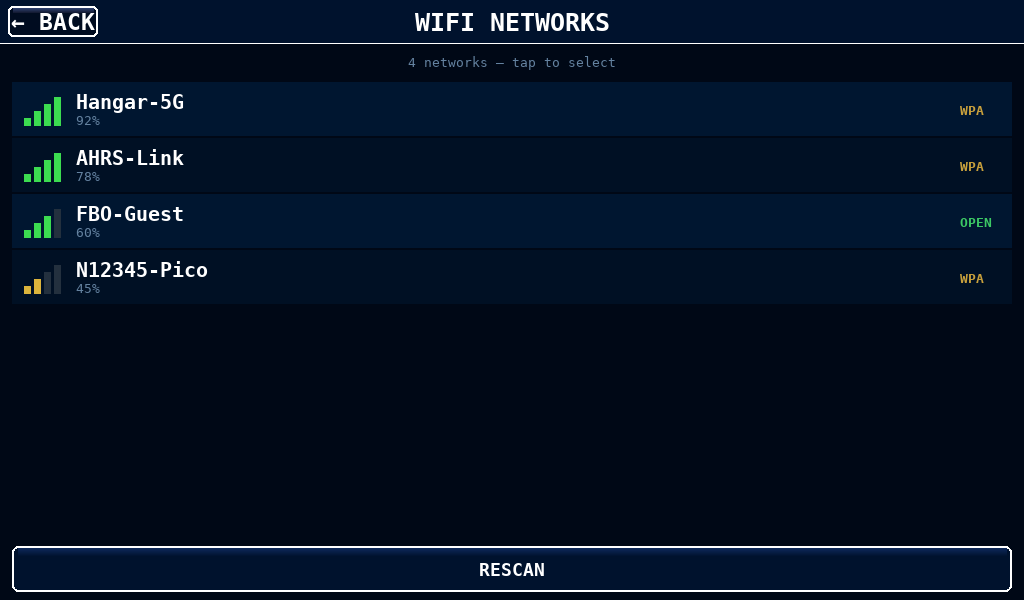
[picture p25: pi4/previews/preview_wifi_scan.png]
WIFI NETWORKS scan list — networks with signal-strength bars and WPA / OPEN tags plus a RESCAN button


**NOTAMs** come from the **FAA NMS-API**. Paste your **client_id** into **NOTAM KEY** and your **client_secret** into **NOTAM SECRET** (masked with bullets), and leave **NOTAM ENV** at `preprod` (switch to `prod` only when you hold production credentials — it selects the NMS host). The poller reads them live, so entering a key enables NOTAMs (in the MET readout picker, §17) on the next fetch with **no reboot**; leave them blank and the rest of the weather suite is unaffected.

**One key for the whole panel.** You only need to enter the key on *one* display:

- *NOTAM data* is shared over the cabin network (screen-sync) — any display on the LAN shows NOTAMs even with **no key entered**, as long as one keyed display is feeding them.
- *The key itself* is **pushed to the other displays** the moment you finish entering it here, so each stores its own copy (persisted locally) and can fetch independently. See §12A.

NOTAMs are scoped to a tight, **zoom-following radius** (~10–40 nm), so the list stays local to what you're looking at rather than returning every NOTAM for hundreds of miles. (Entering the secret on a touchscreen is tedious — you can instead set it over SSH; see the FAQ in `Docs/BENCH_TEST_PI5_ADSB.md`.)

### STATUS row

Two coloured dot/label pairs showing the live state of the two links:

- **AHRS** — green dot + "CONNECTED" when the SSE/USB link is up and the Pico W is pushing frames; red dot + "NO LINK" otherwise.
- **WiFi** — green + `WiFi: <ssid>` when the Pi has an `iwgetid` result (the **actual** network name, truncated with `…` if longer than 18 characters); red + "NO LINK" otherwise. This is the network the Pi itself is joined to, not the AHRS URL.

### AHRS LINK diagnostics row

This row tells you why the AHRS link is or isn't working when STATUS alone isn't enough:

- **Transport + port** (subtitle on the left): `USB /dev/ttyACM0` or `WIFI http://192.168.4.1`. Shows which transport the PFD chose at startup (USB serial is tried first; SSE over Wi-Fi is the fallback).
- **RX counter** — total frames received since boot. Should tick up ~20×/s when a live link is working.
- **ERR counter** — parse failures. A few at boot are normal; continuous growth points at a baud/wiring issue.
- **Last error** — most recent parse error string, truncated at 44 chars.
- **Live R / P / Y / ALT** (right-hand side) — the most recent roll, pitch, yaw, and altitude values the PFD has received. If RX is growing but R/P/Y are stuck at `+0.0°` the firmware is alive but the WT901 isn't talking — check the TX/RX crossover at pin 2 (GP1).

### Action buttons

- **APPLY WIFI** (amber) — saves SSID + password and attempts to join. Uses `nmcli` / `wpa_supplicant` depending on distribution. A status message appears above the button on success or failure.
- **TEST AHRS** (green) — issues a one-shot HTTP GET to the AHRS URL (Wi-Fi transport) or probes the serial port (USB transport) and reports whether the peer answered. Use after APPLY WIFI to confirm the peer is reachable.

After editing WiFi SSID/password, tap **APPLY WIFI** to actually commit the change. After changing AHRS URL, tap **TEST AHRS** to confirm the peer is reachable.

---

## 12A. Screen Sync (multi-display panels)

When you run more than one display (e.g. a Pi 5 PFD + a Pi Zero MFD), they keep each other in sync over the cabin network — set a bug or a flight plan on one and it appears on the others. It's **peer-to-peer** (no master), over UDP broadcast on every available link (USB-gadget, cabin Wi-Fi, the Pico-W AP). The **SCREEN SYNC** setup screen controls it:

- **Master enable** — turn all sync on/off.
- **TRANSPORT** — `AUTO` (broadcast on every link), `USB` (force the USB-gadget link only), or `NET` (force Wi-Fi/ethernet only). Useful for proving a specific link carries packets; the listener still accepts from anywhere.
- **PEER** badge — green with the peer's short ID + "last *N*s ago" when another display is heard; red "NO PEER" when sync is on but nobody's there; grey when sync is off (peers go stale after 6 s of silence).
- **LINKS** row — per-interface diagnostics: `●`/`○` eligible, plus TX/RX packet counts and each interface's address.

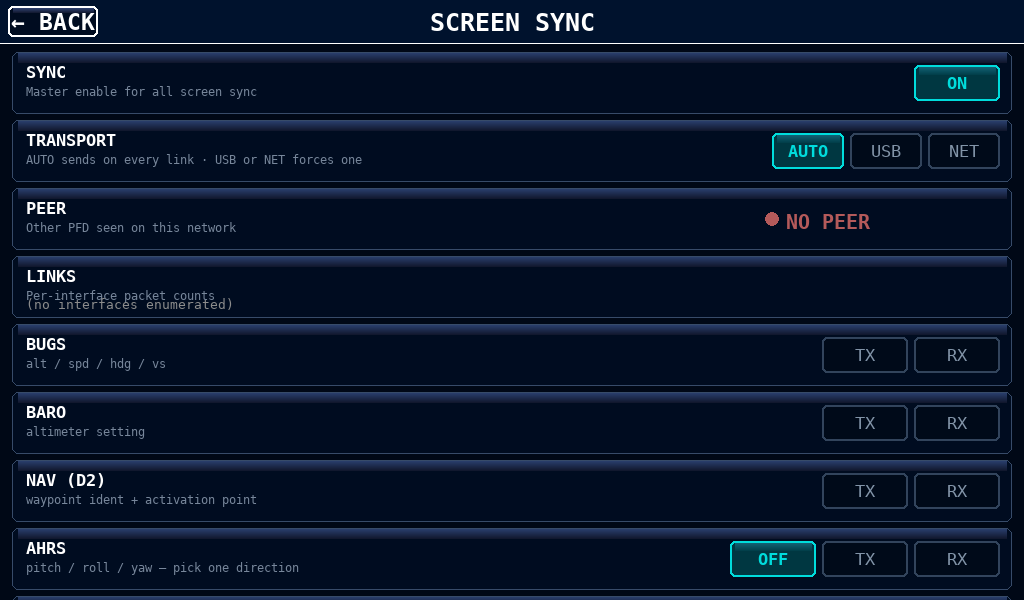
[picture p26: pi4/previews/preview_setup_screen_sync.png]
Screen Sync setup screen — master enable, AUTO/USB/NET transport, per-category TX/RX toggles, SHARE FPL, and the peer / links diagnostics


**Per-category sharing** (each its own TX / RX, so you choose direction):

| Category | What syncs |
|---|---|
| **BUGS** | altitude / speed / heading / VS bugs |
| **BARO** | altimeter setting |
| **NAV** | the active direct-to (ident, position, activation point) |
| **AHRS** | pitch / roll / yaw — **OFF / TX / RX** (mutually exclusive, to prevent an echo loop on the streaming sensor) |
| **GPS** | position / alt / speed / track — **OFF / TX / RX** (same mutex) |
| **SHARE FPL** | the active flight plan **and** the saved-plan / user-waypoint library — a single bidirectional toggle |

Bugs / baro / nav publish only when *you* edit them, so they don't echo. **Winds aloft and NOTAMs are also shared automatically** whenever sync is enabled, and don't need a toggle:

- **Winds aloft** — a display with internet feeds the winds grid to the others (see §17).
- **NOTAMs** — a display with a NOTAM key feeds its fetched NOTAMs to the others, so a display with no key still shows them (§12). Entering the NOTAM key/secret on one display also **pushes the credentials** to the others, which store their own copy so they can fetch independently. The secret travels the LAN only when you enter it, and shows masked everywhere.

All choices persist in `data/settings.json`.

---

## 13. System

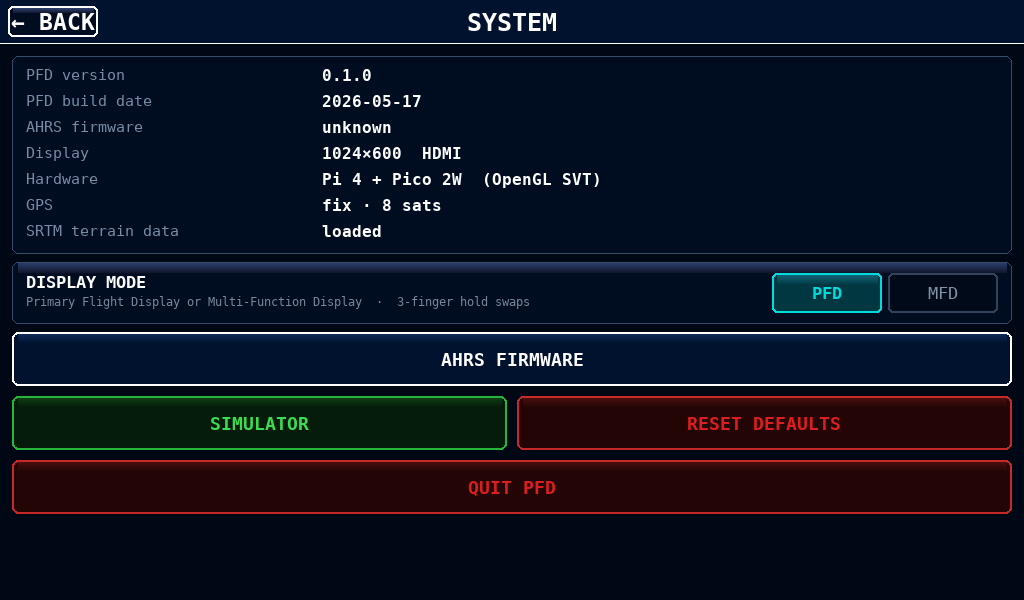
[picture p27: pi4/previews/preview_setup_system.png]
System screen


Version info, terrain/obstacle status, DIAGNOSTICS (future), RESET DEFAULTS, FLIGHT SIMULATOR, and the **SHUTDOWN / REBOOT** power buttons.

**SHUTDOWN / REBOOT (graceful stop).** The bottom button row halts or reboots the Pi cleanly instead of pulling power — which is what protects the SD card from corruption. Both are **arm‑to‑confirm**: the first tap turns the button amber and changes its label to *TAP AGAIN*; a second tap within 4 seconds executes (a single stray tap does nothing, and the arm auto‑clears after 4 s). SHUTDOWN flushes settings, halts the OS, and leaves the Pi in a safe powered‑off state — **wait for the activity LED to stop, then cut power.** REBOOT restarts it. (These need the small sudoers rule the setup script installs; on an already‑set‑up Pi, run `sudo bash tools/install_shutdown_sudoers.sh` once. A hardware power button can also be wired — see the README.)

All configurable settings — V-speeds, tail number, units, backlight brightness, colour scheme, heading-source mode, Wi-Fi SSID, airport display filters, and the runway/centerline overlay toggles — persist across power cycles in `pi4/data/settings.json`. The file is written atomically (temp‑file + `fsync` + rename) on a background thread with a 1.5 s debounce, so rapid successive taps produce a single durable write with no UI stutter, and a power pull can't leave a truncated settings file. The Wi-Fi password is intentionally *not* stored — it must be re-entered when joining a new network.

---

## 14. Data Downloads

### Terrain data

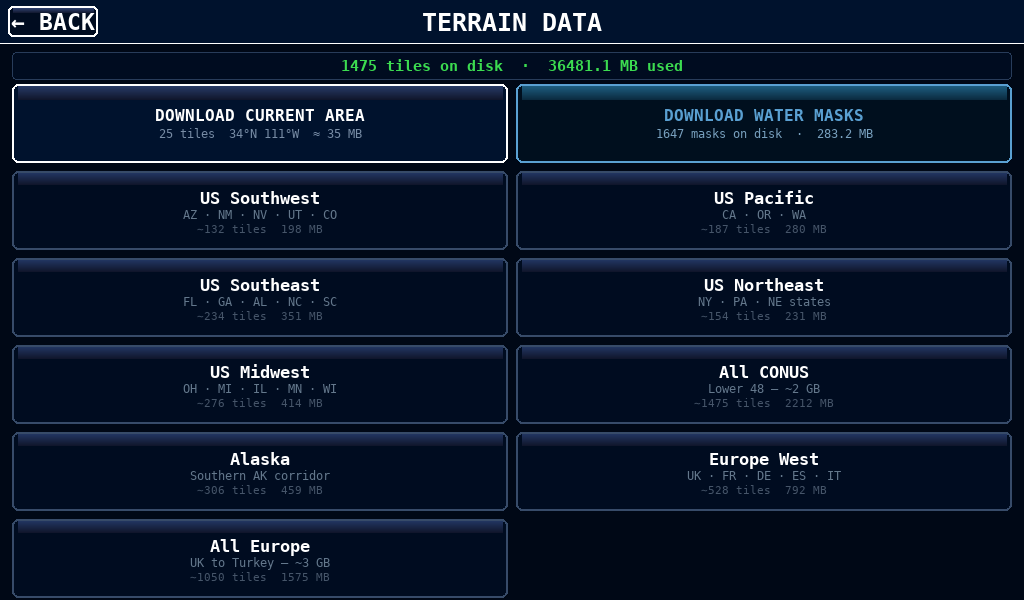
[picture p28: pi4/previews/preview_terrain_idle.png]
Terrain idle screen — DOWNLOAD CURRENT AREA + DOWNLOAD WATER MASKS along the top, preset region tiles below


The TERRAIN DATA screen now manages three layered datasets in one place:

- **SRTM elevation tiles** (`pi4/data/srtm/*.hgt`) — ground texture for the SVT background and the TAWS proximity check. Without these the AI shows a plain blue/brown split and the `NO TER` badge appears.
- **Water masks** (`pi4/data/water/*.npy`) — rasterised Natural Earth ocean + lake polygons so the SVT mesh and the moving-map inset paint water blue rather than terrain-coloured. ~12 MB worldwide, downloaded once.
- **State / province boundary polylines** (`pi4/data/natural_earth/admin_1_*`) — used by the moving-map inset at wide zoom levels to give context (boundaries fade in around 20 NM range, slate-blue). Downloaded automatically alongside the water masks as a free side-effect.
- **Country boundary polylines** (`pi4/data/natural_earth/admin_0_*`) — same Natural Earth source, country-level (admin_0) outlines. Drawn in tan so they're distinguishable from the slate-blue state lines when both layers overlap (e.g. the US-Canada border draws once as state, once as country). Same 20 NM gate. Fetched in the same download pass as admin_1.

#### Top row — DOWNLOAD CURRENT AREA · DOWNLOAD WATER MASKS

Two side-by-side full-width tiles at the top of the screen.

- **DOWNLOAD CURRENT AREA** — downloads a 5°×5° SRTM box (≈ 25 tiles, ~35 MB) centred on the current GPS position. Requires a GPS fix. This is the fastest way to get flying in an unfamiliar area: one tap and the tiles you actually need are on disk a minute later.
- **DOWNLOAD WATER MASKS** — rasterises Natural Earth's 10 m ocean + lake vectors against every SRTM tile already on disk, then fetches the admin-1 (state / province) + admin-0 (country) line sets in the same run. ~12 MB for the global vector source, plus a small per-tile cache. Re-tap any time you've added new SRTM tiles — the rasteriser skips masks that are already on disk and only builds the new ones.

#### Preset regions

Preset regions below the two top tiles. Each tile shows the states/countries it covers, approximate tile count, and estimated size. Tap a tile to start the download; a progress bar replaces the status strip at the bottom of the screen.

| Region | Coverage | ~Tiles | ~Size |
|---|---|---:|---:|
| **US Southwest** | AZ · NM · NV · UT · CO | 132 | 198 MB |
| **US Pacific** | CA · OR · WA | 187 | 280 MB |
| **US Southeast** | FL · GA · AL · NC · SC | 234 | 351 MB |
| **US Northeast** | NY · PA · NE states | 154 | 231 MB |
| **US Midwest** | OH · MI · IL · MN · WI | 276 | 414 MB |
| **All CONUS** | Lower 48 — single-tap full coverage | ~1,475 | ~2 GB |
| **Alaska** | Southern AK corridor | 306 | 459 MB |
| **Europe West** | UK · FR · DE · ES · IT | 528 | 792 MB |
| **All Europe** | UK to Turkey | ~1,050 | ~3 GB |

Downloads are resumable: already-present tiles are skipped, so re-tapping a region after a partial download finishes the remainder. **CANCEL** stops in flight; tiles already on disk are kept.

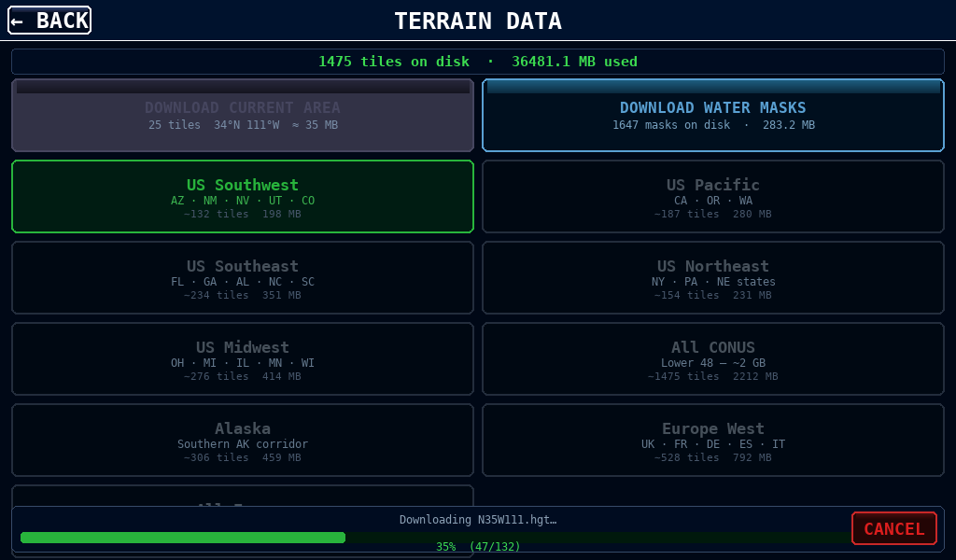
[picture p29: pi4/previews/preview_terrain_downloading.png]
Download in progress


#### WiFi requirement

The Pi 4 must be on an internet-reachable network to download. Use the Connectivity screen (§12) to switch to your home Wi-Fi, download here, then switch back to the Pico W AP for flight. If you tap DOWNLOAD while still on the Pico W AP the screen will show a "WiFi (home network) required" guard message instead of starting.

#### Compacting SRTM (SRTM1 → SRTM3) and the pi4 → pi_zero hand-off

The Pi 4/5 downloads full-resolution **SRTM1** tiles (3601², ~25 MB each). The Pi Zero uses the lighter **SRTM3** (1201², ~3 MB) and can't hold the SRTM1 set, so there's a one-shot compactor, `tools/compact_srtm.py`, that decimates SRTM1 → SRTM3 (~8.7× smaller). On the Pi 4 it's a command line:

```bash
# Compact in place:
python3 tools/compact_srtm.py --srtm-dir ~/PFD-and-AHRS/pi4/data/srtm
# Or write SRTM3 copies elsewhere (leaves the SRTM1 originals untouched) —
# the hand-off path for seeding a Pi Zero:
python3 tools/compact_srtm.py --srtm-dir ~/PFD-and-AHRS/pi4/data/srtm \
    --output-dir ~/srtm3_for_zero        #  then rsync that to the Zero
```

(The Pi Zero also has an on-screen **COMPACT** button that does this in place — see the Pi Zero manual. See also the multi-display deploy recipe in the README.)

---

### Airspace data

The AIRSPACE DATA screen downloads the airspace boundary file that feeds the **ASP** overlay (§17). It mirrors the terrain / obstacle / airport download screens: tap **DOWNLOAD**, watch the progress bar, and the status line reads e.g. `Done ✓ 9,183 airspaces loaded` when the file is parsed and cached.

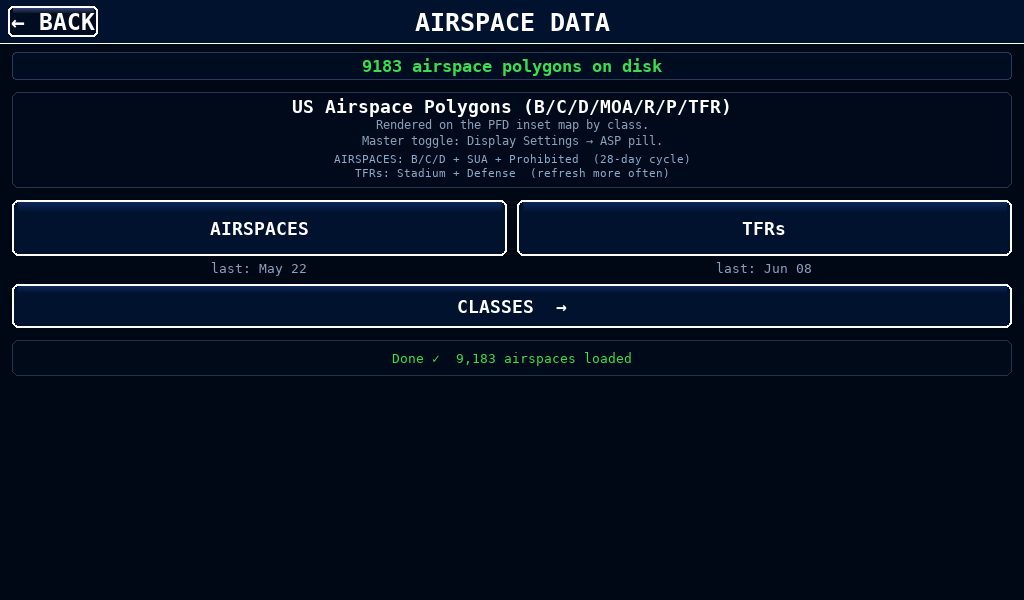
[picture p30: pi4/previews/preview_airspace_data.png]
Airspace data screen — loaded, "Done ✓ 9,183 airspaces loaded"


#### Airspace classes

Per-class toggles hide individual airspace classes on the map without turning off the whole overlay (the master switch is the **ASP** stop in the OVLY cycle). Each colour-coded badge — **Class B / C / D / MOA / R / P / TFR** — has its own **ON / OFF**.

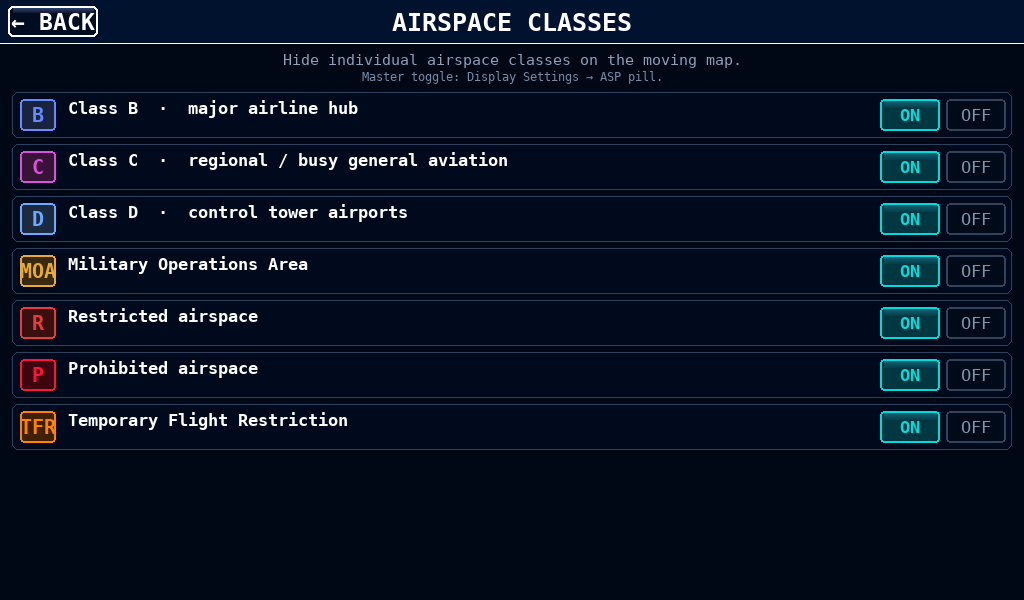
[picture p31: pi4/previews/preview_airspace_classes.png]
Airspace class toggles — colour-coded Class B / C / D / MOA / R / P / TFR badges, each ON / OFF


---

### Obstacle data

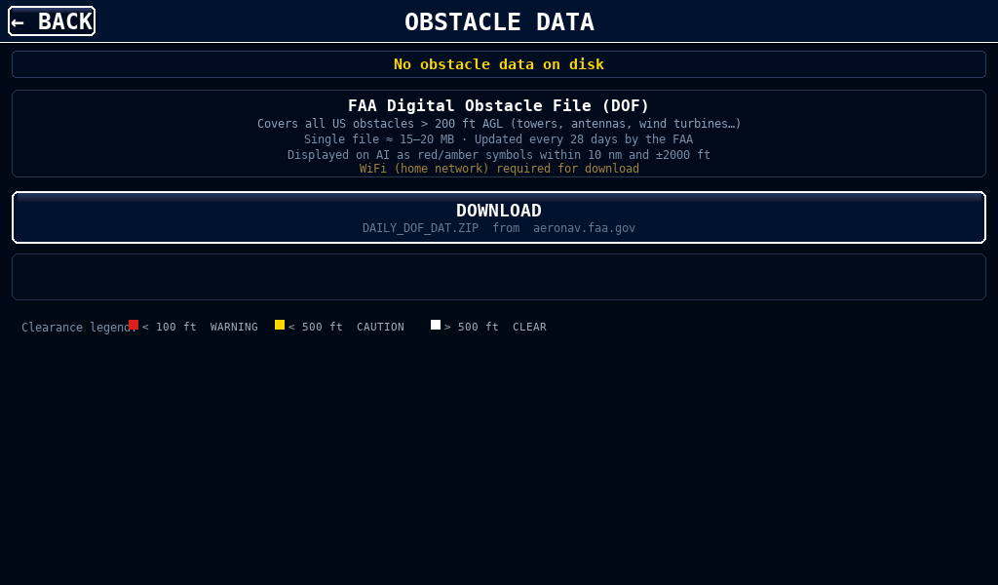
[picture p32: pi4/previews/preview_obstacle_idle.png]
Obstacle data screen — idle


FAA DOF adds tower/antenna/wind-turbine symbols. Within 10 nm and ±2000 ft.

Tap DOWNLOAD to fetch. Symbols colour-coded:

| Colour | Meaning |
|---|---|
| Red | Within 100 ft below |
| Amber | Within 500 ft below |
| White | Cleared > 500 ft |

Red dot = lit obstacle. 28-day update cycle.

---

### Airport data

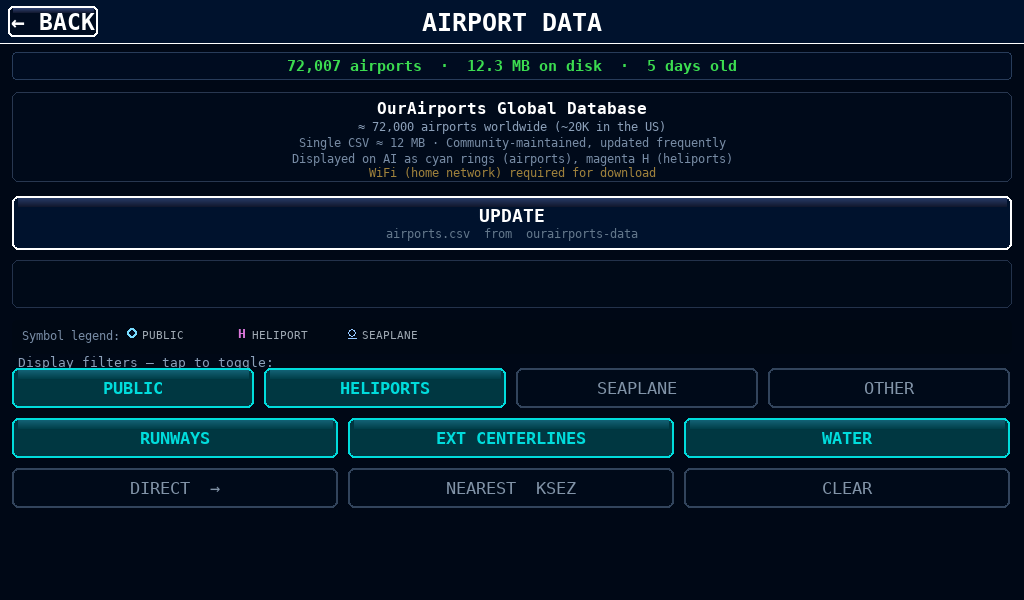
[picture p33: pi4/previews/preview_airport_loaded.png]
Airport data screen — loaded


The OurAirports.com global database adds airport and heliport symbols to the attitude indicator within 20 nm of the aircraft. The database covers approximately 72,000 airports worldwide including ~20,000 in the US.

#### Symbols on the AI

| Symbol | Meaning |
|---|---|
| Cyan ring (filled centre) | Public airport (small / medium / large) |
| Cyan ring with outer ring | Medium or large public airport |
| Magenta "H" | Heliport |
| Cyan circle with wavy underscore | Seaplane base |
| Grey triangle | Balloonport |

The airport identifier (e.g. "KSEZ") is rendered within 15 nm as a small "road sign" — a coloured text box mounted on a thin vertical post that lifts the label clear of the symbol and any nearby terrain features. The sign border matches the symbol colour (cyan for public airports, magenta for heliports). Beyond 15 nm only the symbol is drawn to reduce clutter at distance.

#### Display filters

The AIRPORT DATA screen has four type filters and two overlay toggles at the bottom. Tap any tile to toggle its state.

| Filter | Controls | Default |
|---|---|---|
| **PUBLIC** | Small / medium / large public-use airports | On |
| **HELIPORTS** | Hospital helipads, rooftop pads, private helis | On |
| **SEAPLANE** | Seaplane bases (water operations) | Off |
| **OTHER** | Balloonports and uncategorised types | Off |
| **RUNWAYS** | Paved/unpaved runway polygons (within 8 nm) | On |
| **EXT CENTERLINES** | Dashed extended centerlines off each threshold (within 15 nm) | On |

This lets you declutter the AI to show only the types relevant to your flight — for example, turn off HELIPORTS when operating in dense urban airspace where helipads would swamp the display, or turn off EXT CENTERLINES en-route and only re-enable during terminal-area operations.

All filter and toggle states persist across power cycles — you don't need to re-configure on every startup.

#### Runways and extended centerlines

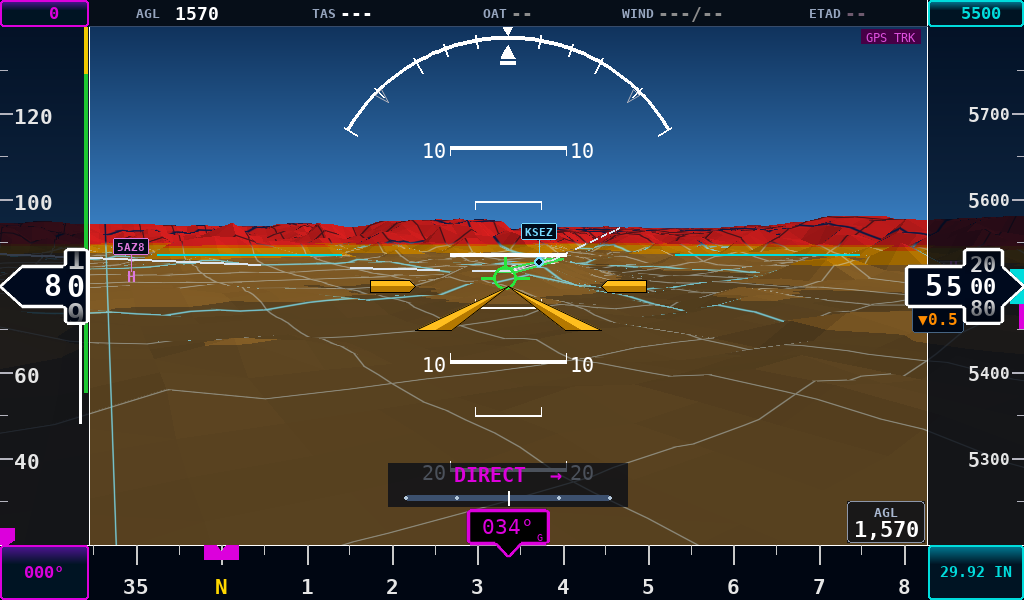
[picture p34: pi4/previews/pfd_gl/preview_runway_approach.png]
Runway approach — KSEZ RWY 03


Within 8 nm of an airport, the PFD overlays a scaled polygon for each runway threshold-to-threshold, projected in the same perspective as the rest of the attitude indicator so runways translate, rotate, and scale naturally with the aircraft's position, bank and pitch. Width is taken from the OurAirports database.

Extended centerlines (dashed yellow) extend 10 nm outward from each runway threshold along its exact bearing, visible within 15 nm of the airport. This provides an at-a-glance final-approach reference for non-precision and visual approaches — the same kind of cue you get from a flight director's course bar, but derived purely from the runway geometry rather than a flight-plan waypoint.

Runway data comes from OurAirports `runways.csv` (approximately 14,700 runways worldwide) and is downloaded alongside the airport CSV in a single UPDATE action.

#### Downloading

Tap **AIRPORTS** on the System screen to open the airport data screen.

Tap **DOWNLOAD** (or **UPDATE** if data is already present) to fetch `airports.csv` (~12 MB) plus `runways.csv` (~3 MB) from the OurAirports GitHub mirror.

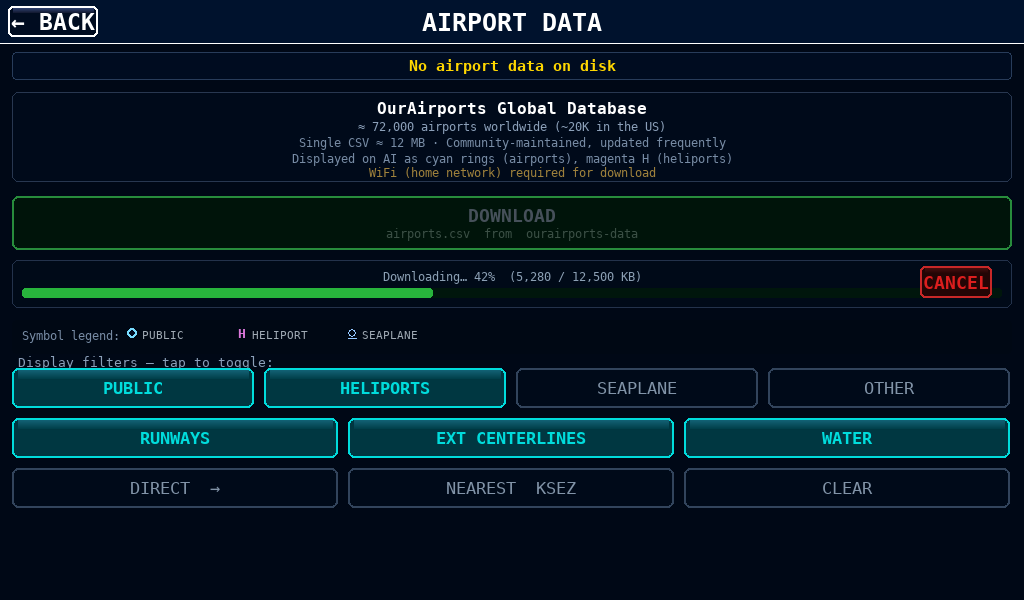
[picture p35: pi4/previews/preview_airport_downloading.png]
Airport data screen — downloading


A progress bar updates as the download runs. After completion the CSV is parsed into a NumPy cache for fast future loads. Tap **CANCEL** to abort at any time — no partial data is kept.

#### Update schedule

The OurAirports database is community-maintained and updated frequently. A 60-day local expiry is enforced; after that the `EXP APT` badge appears in the status strip to remind the pilot to refresh. The data is usable past expiry — the badge is an advisory only.

#### WiFi requirement

The Pi 4 must be on an internet-reachable network to download. Use the Connectivity screen to switch to home Wi-Fi, download here, then switch back to the Pico W AP for flight.

---

## 15. Full-Screen MFD

The map overlays above (weather, traffic, winds, airspace) also live on a **full-screen multi-function display**. The lower-left **moving-map inset** (§17) is always available on the PFD; the full-screen MFD trades the PFD instruments for a large map when you want the whole picture.

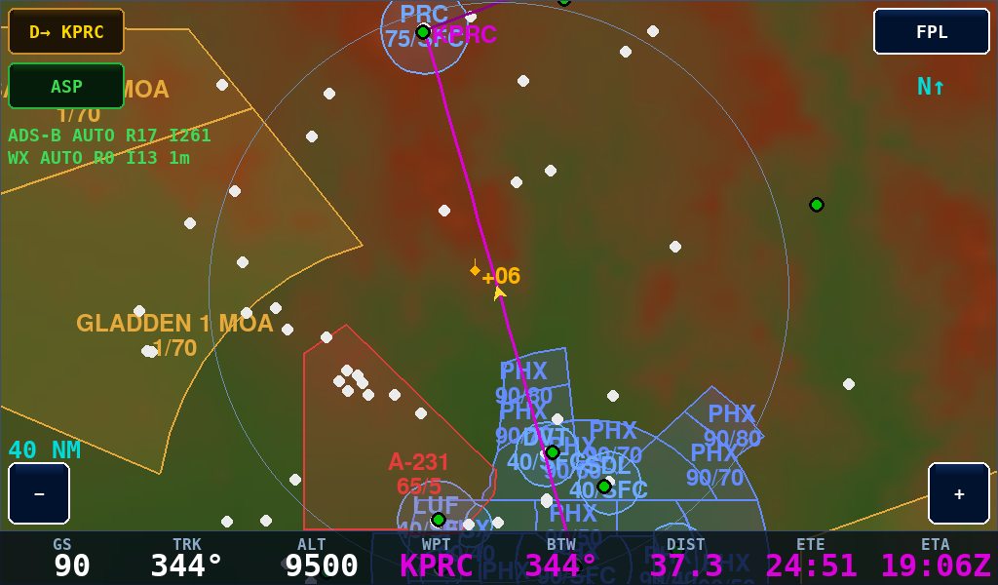
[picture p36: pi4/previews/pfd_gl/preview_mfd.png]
Full-screen MFD — large moving map with D2/FPL/OVLY chrome and the bottom data strip


### Switching PFD ↔ MFD

A **3-finger hold (~2 s)** anywhere on the screen swaps between the PFD and the full-screen MFD. (A **2-finger hold (~0.8 s)** opens the setup menu — different finger count.) The swap is gated by **ENABLE MFD** in DISPLAY setup (default **ON** on the larger HDMI panels); turn it off to lock the display to the PFD and prevent accidental swaps. The unit always boots to the PFD.

### Chrome (buttons and labels)

| Control | Where | Action |
|---|---|---|
| **D→** | top-left | Direct-to. Reads `D→` idle, `D→ KSEZ` (magenta) when active. Tap to enter/clear a waypoint (§16). |
| **FPL** | top-right | Open the flight-plan editor. |
| **TRK↑ / N↑** | top-right, under FPL | Cyan label — tap to toggle track-up vs. north-up. |
| **OVLY** | lower-left | Cycle the weather/airspace overlay (§17). |
| **RNG** (e.g. `10 NM` / `AUTO`) | lower-left, above the zoom buttons | Current range; `AUTO` fits the active direct-to leg. |
| **− / +** | bottom corners | Zoom out / in through the range ladder. |
| **CTR** | right side | Appears only when the map is **panned**; tap to recenter on the aircraft. |

The **TRK↑ / N↑** label toggles the map orientation between track-up (own-ship heading at the top) and north-up.

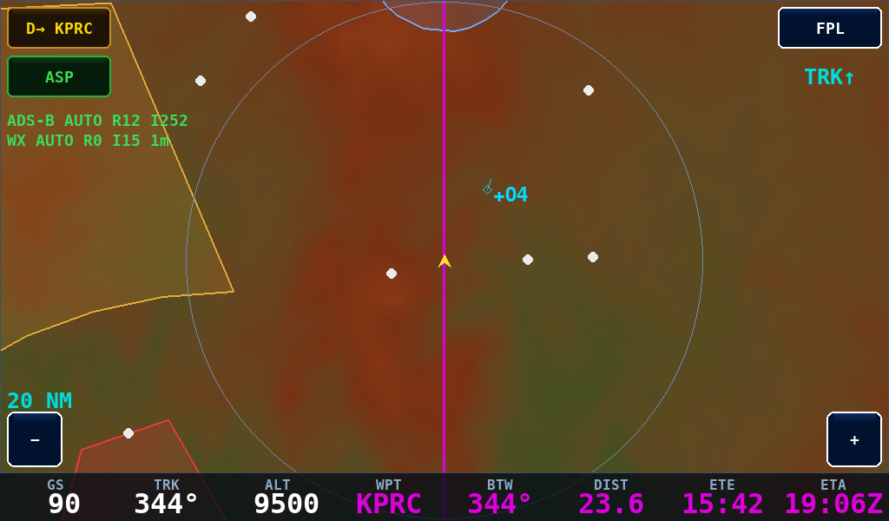
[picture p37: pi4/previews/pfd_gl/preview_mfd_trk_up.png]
Full-screen MFD in TRACK-UP orientation — the orientation label reads TRK↑


The **− / +** buttons step the **RNG** through the range ladder out to 160 NM for a cross-country overview.

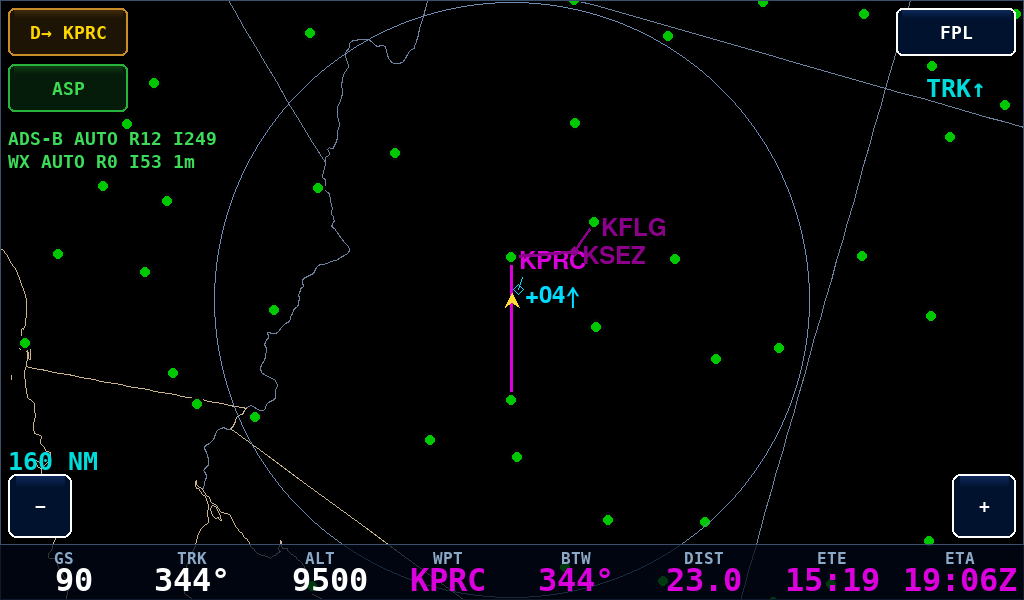
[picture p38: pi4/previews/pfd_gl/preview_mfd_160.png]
Full-screen MFD zoomed out to the 160 NM range


### Pan and recenter

Drag anywhere on the map (outside a button) to **pan**; heavy layers (terrain tint, water, airspace, NEXRAD, METAR) are skipped while dragging so it tracks your finger, and repaint on release. When panned, the **CTR** button appears — tap it (or the own-ship chevron) to snap back to the aircraft.

### Bottom data strip

A full-width strip along the bottom carries **8 readout slots**, each a cyan caption over a coloured value. **Tap any slot** to open the picker, then tap a field to assign it; the selection advances to the next slot so you can fill the row left-to-right with successive taps. The default layout is **GS · TRK · ALT · WPT · BTW · DIST · ETE · ETA**, and your choices persist in `data/settings.json`.

The full set of assignable fields:

| Field | Caption | Shows |
| --- | --- | --- |
| Groundspeed | **GS** | GPS groundspeed, kt |
| Airspeed | **AS** | Indicated airspeed, kt |
| True airspeed | **TAS** | True airspeed, kt |
| Track | **TRK** | GPS ground track, ° (dashes below ~3 kt) |
| Heading | **HDG** | Magnetic/true heading, ° |
| Altitude | **ALT** | Baro altitude, ft |
| Above-ground | **AGL** | Height above terrain, ft (needs terrain data) |
| Vertical speed | **VS** | Climb/descent, ft/min |
| Wind | **WIND** | Wind direction/speed, `DDD/SS` — from the AHRS/sim wind solution, else computed on the display from TAS + GPS track (assumes ISA temperature until an OAT sensor is fitted); `---/--` on the ground or with no IAS / GPS track |
| Time | **UTC** | Zulu clock, HH:MMZ |
| Baro setting | **BARO** | Altimeter setting (inHg or hPa per units) |
| Satellites | **SAT** | GPS satellites in solution |
| Active waypoint | **WPT** | Ident of the active leg's destination |
| Bearing-to | **BTW** | Bearing to the active waypoint, ° |
| Desired track | **DTK** | Course of the active leg, ° |
| Distance | **DIST** | Distance to the active waypoint, NM |
| Distance (dest.) | **DISTD** | Distance to the final destination through all remaining legs, NM |
| Cross-track | **XTE** | Cross-track error off the active leg, NM |
| Time en route | **ETE** | Time to the active waypoint, MM:SS / H:MM |
| ETE (dest.) | **ETED** | Time enroute to the final destination |
| Arrival | **ETA** | Arrival clock at the active waypoint — **local time by default** (`HH:MM`), or Zulu (`HH:MMZ`) per the ARRIVAL TIME toggle |
| Arrival (dest.) | **ETAD** | Arrival clock at the final destination — local by default, Zulu per the ARRIVAL TIME toggle |

The nav-derived fields (**WPT, BTW, DTK, DIST, DISTD, XTE, ETE, ETED, ETA, ETAD**) render magenta and show `--` when there's no active Direct-To or flight-plan leg; once a waypoint is active they fill in live. The `…D` fields (DISTD / ETED / ETAD) are to the **final destination** (the whole route), versus the plain fields to the **active waypoint**.

**Tap any slot** to open the field picker. The eight current slots show as pills across the top (the selected one ringed cyan); tap a field in the grid below to assign it to the selected slot — the selection then auto-advances to the next slot so you can fill the whole row with successive taps. Nav-derived fields are tagged **needs D2** and render magenta. The picker also carries an **ARRIVAL TIME** toggle (**LOCAL / ZULU**, default **LOCAL**) that flips every ETA / ETAD readout between the destination's local time and Zulu.

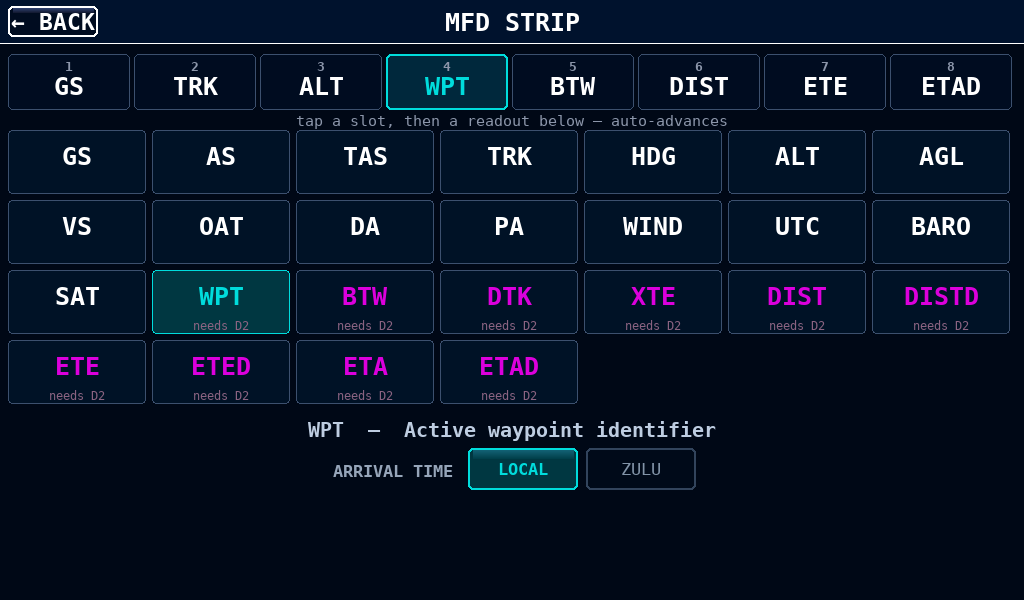
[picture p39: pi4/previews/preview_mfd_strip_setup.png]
MFD data-field picker — eight slot pills on top (WPT selected) over a grid of assignable fields; nav fields tagged "needs D2" in magenta


---

## 16. Navigation & Approach

### Direct-to Navigation

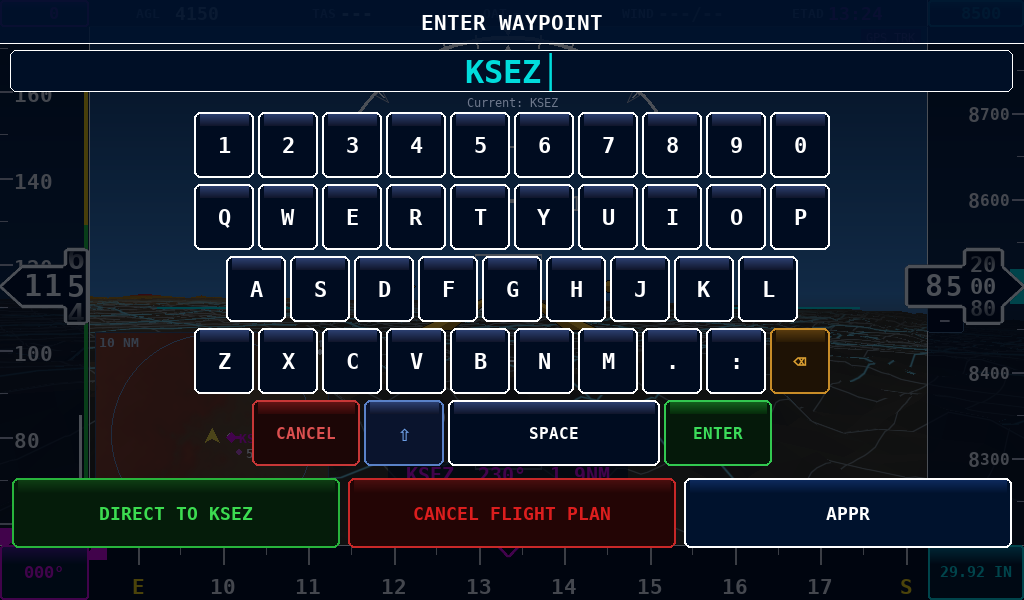
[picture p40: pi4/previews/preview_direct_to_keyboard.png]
Direct-to keyboard with WAYPOINT title and existing ident as placeholder


The PFD has built-in direct-to navigation: pick an airport ident, the pilot is asked to confirm, and a magenta course line draws from the activation point to the waypoint, draped over the SRTM terrain.

### Opening the keyboard

| From | How |
|---|-----|
| **PFD (live flight)** | Tap the **CDI strip** above the heading box. The keyboard opens with the existing ident as a dim placeholder; the buffer starts empty so first-keystroke replaces. |
| **AIRPORT DATA screen** | Tap the **DIRECT TO** tile in the action row. |

### Three keyboard outcomes

| You do | What happens |
|---|---|
| Type a known ident → ENTER | Modal pops up: **"Activate Direct to *XXXX*?"** with **CANCEL** / **ACTIVATE** buttons. Tap ACTIVATE (or hit physical ENTER) to commit. Two-tap commit prevents accidental flight-plan edits. |
| Hit ENTER on **empty** buffer (with an active waypoint already loaded) | Same confirmation modal opens with the **existing** ident — confirms re-activation, which refreshes the magenta course line from your **current** position. Use this when you want a new course line drawn from where you are now. |
| Type an **unknown** ident → ENTER | Keyboard stays open with a red **"UNKNOWN WAYPOINT *XXXX*"** hint under the entry field. Backspace or any keystroke clears the error so you can correct the ident in place. |

### NEAREST quick-button

If the keyboard is opened from PFD and the display is tall enough (1024×600 fits it), an extra row appears below the keys:

- **DIRECT TO *XXXX*** — green. *XXXX* is the resolved nearest public airport (small / medium / large) within 100 NM of your current position. Tap to route through the same Activate? confirmation modal. The ident on the button refreshes every ~2 s so it's accurate even while you're typing.
- **CANCEL FLIGHT PLAN** — red. Wipes the active direct-to immediately (no confirmation; the impact is recoverable by re-typing the ident).

### Confirmation modal

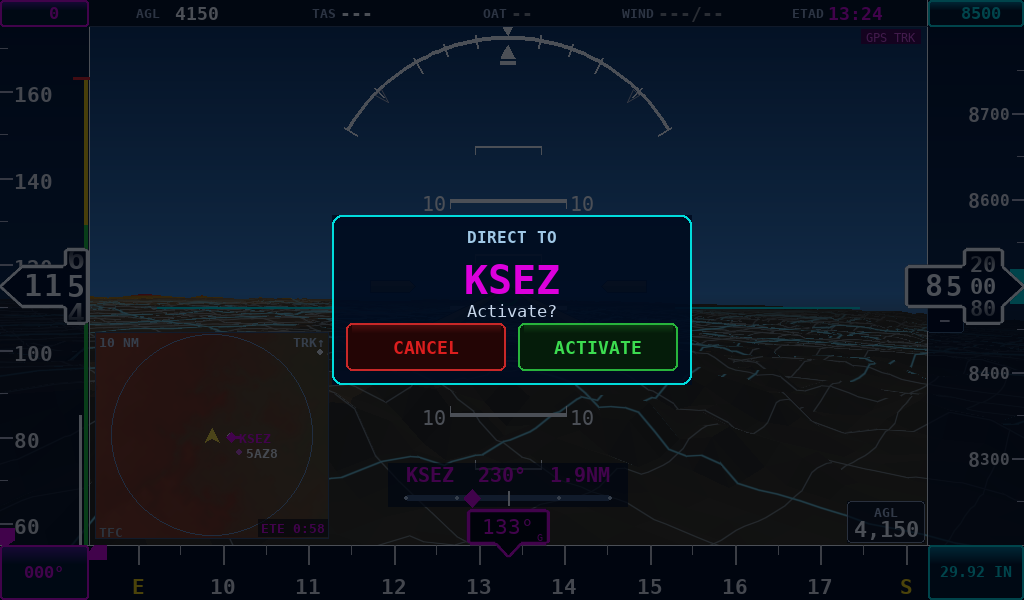
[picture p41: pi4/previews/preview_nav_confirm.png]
Activate Direct to KSEZ?


Modal text:
- **DIRECT TO** label.
- The ident in large magenta text.
- **Activate?** prompt.
- **CANCEL** (red) and **ACTIVATE** (green) buttons. Physical ESC = cancel. Physical ENTER = activate.

### Magenta course trace

After activation, a magenta line draws from the **activation point** (your position when you confirmed) to the destination, draped over the SRTM terrain mesh. The line is sampled at 0.2 NM steps with a rolling-max smoothing so it always sits at least 200 ft above the highest terrain in each segment — never cuts through ridges, including in dense terrain like Sedona.

The trace is built **asynchronously** in a background thread and **published progressively** as samples come in: the near end of the line shows up within ~1 s of activation; the rest fills in as the worker walks the SRTM tiles toward the waypoint. No UI freeze on long cross-country activations. If you change the direct-to mid-build, the in-flight worker discovers the mismatch and discards its result so no stale course flashes.

### CDI strip

Above the heading box: a horizontal bar with cross-track-error scale. The magenta diamond shows where the reference course is **relative to your aircraft** — diamond-LEFT means the course is to your left, so steer left to intercept. Right of course → diamond LEFT (fly left). Standard "fly to the needle" CDI.

**Full-scale deflection is mode-dependent**, matching standard avionics:

| Mode | Full-scale | Reference line |
|---|---|---|
| En-route / Direct-to | ±1.0 NM | Activation point → waypoint great circle |
| Synthetic approach (§16 active) | ±0.3 NM | Extended runway centreline (threshold + published course) |

The tighter approach scale matches RNAV / LPV convention so a half-scale needle on final actually means something. When the ident on the readout includes a runway suffix (e.g. `KSEZ/03`), the approach-mode scaling is in effect.

The line on the bar shows tick marks at ±50 % and ±full-scale. The line itself is dim grey; the diamond magenta. Above the bar a readout shows **ident · BRG · DIST** in magenta (e.g. `KSEZ  155°  3.2 NM`); on approach the runway suffix is appended (`KSEZ/03`).

When no waypoint is active the strip is still drawn but reads **"DIRECT  →"** as a tap target.

### Flight plan (multi-waypoint)

Tap **FPL** (top-right on the MFD, §15) to open the flight-plan editor — an ordered list of waypoints where each leg is one ICAO ident, and each row shows that leg's **course and distance** (e.g. `123°  4.5 nm`). The course follows the **HDG / CRS REF** setting (§10): magnetic by default — bare degrees, matching charts — or true, shown with a `T` suffix (`123°T`). Tap a row to **activate that leg** as the direct-to (the active leg is highlighted green with an **● ACTIVE** badge and its waypoint turns magenta); auto-sequencing advances to the next leg as you pass each waypoint, **leading the turn (fly-by)** — it sequences early using a groundspeed-based turn-anticipation distance so the aircraft rolls onto the next course without overshooting the fix (the final approach leg stays fly-over). Vertical step-downs on an approach are distance-to-threshold based, so leading the lateral turn never advances the altitude profile early.

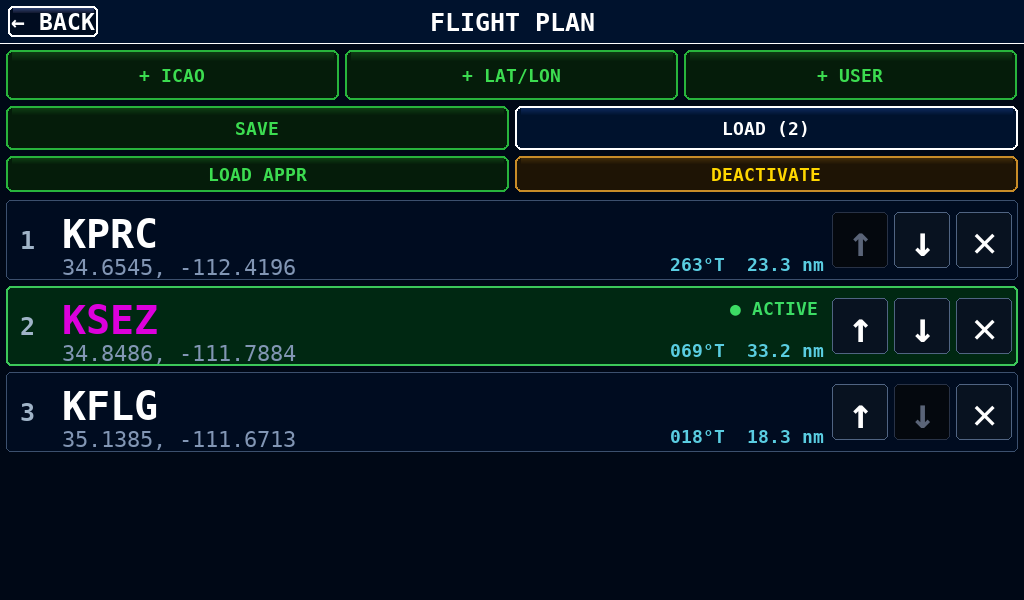
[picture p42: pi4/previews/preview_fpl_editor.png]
Flight-plan editor — KPRC → KSEZ → KFLG with the KSEZ leg active, +ICAO/+LAT-LON/+USER add buttons, SAVE / REVERSE / LOAD, and a DEACTIVATE button


- **+ ICAO** — add a waypoint by ident (opens the keyboard; unknown idents are rejected with a red hint).
- **+ LAT/LON** — add a custom point by coordinates.
- **+ USER** — pick from your saved user-waypoint library.
- **↑ / ↓ / ✕** on each row — reorder or delete that waypoint.
- **REVERSE** — flip the whole route end-for-end (A→…→Z becomes Z→…→A), e.g. to fly the return trip. Needs at least two waypoints. Reversing **deactivates** the active leg (the old leg's course no longer applies to the reversed route), so re-tap a row to activate; the reversed order syncs to the other displays.
- **DEACTIVATE** — stop navigating the plan without deleting it.

### Saving and loading plans

**SAVE** stores the current waypoint list under a name you type; **REVERSE** flips the leg order (above); **LOAD (*n*)** opens the saved-plan picker. Each saved plan shows its leg count and first → last idents; tap **LOAD** to recall it into the editor or **DEL** to remove it. Saved plans (and the user-waypoint library) persist across power cycles and sync to the other displays when **SHARE FPL** is on (§12A).

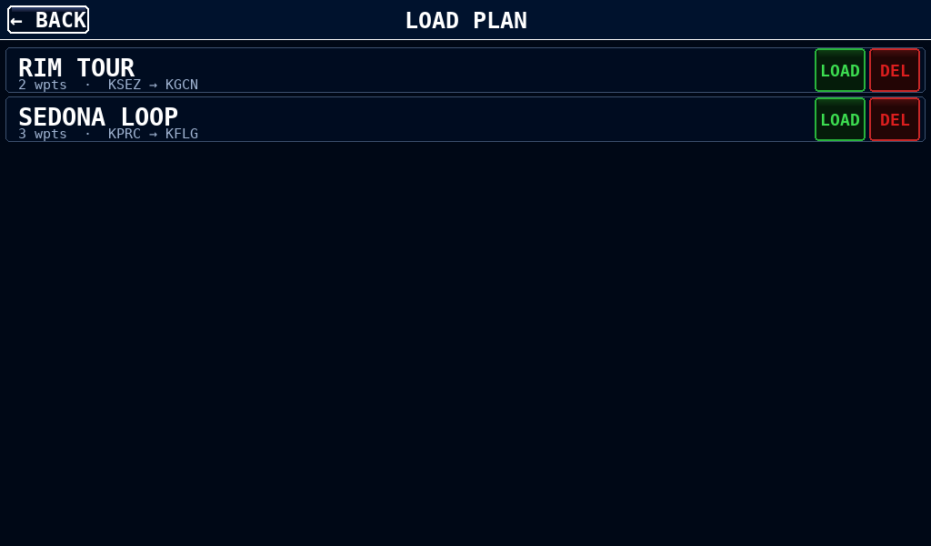
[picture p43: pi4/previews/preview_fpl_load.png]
Load-plan picker — saved plans (SEDONA LOOP, RIM TOUR) each with a leg count, first → last idents, and LOAD / DEL buttons


### Custom waypoints

**+ LAT/LON** on the flight-plan page opens the add-user-waypoint entry screen: an **IDENT** field plus **LAT** / **LON** in decimal degrees (e.g. `FISH`, `34.523`, `-111.812`), with **CANCEL** / **SAVE**. The saved point is added to the plan and auto-stored in the user-waypoint library for reuse.

Add user waypoint — IDENT / LAT / LON fields (FISH, 34.523, -111.812) with CANCEL / SAVE

The **+ USER** button picks from the **user-waypoints** library — every point you've made with +LAT/LON, listed with its lat/lon. **ADD** inserts the selected point into the plan; **DEL** removes it from the library. The library persists across power cycles and syncs to the other displays when **SHARE FPL** is on (§12A).

User waypoints library — saved points FISH / RDV1 / CAMP with lat/lon and ADD / DEL

---

### AGL Readout

AGL readout bottom-right of the AI

A small box in the lower-right corner of the AI shows your **altitude above the local terrain** in feet — useful as a sanity check against the baro altimeter, especially when overflying mountainous terrain where field elevations vary widely.

Layout: a translucent dark backplate with a 1-px light-grey border, sized 78 × 42 px, sitting just left of the altitude tape and just above the heading tape. Two-line stack:
- Top: **"AGL"** label in dim grey.
- Bottom: numeric value in white (or dashes if invalid), rounded to the nearest 10 ft, e.g. `1230`.

### What it reads

`AGL = round(real_alt − ground_elev_ft_at_lat_lon, 10)`

- `real_alt` is the unclamped sensor altitude (NOT the camera-floor-clamped value used to keep the SVT camera above terrain), so a punched-ground state shows in dashes as a sanity-check warning rather than being silently clamped to ≥0.
- `ground_elev_ft_at_lat_lon` is the SRTM tile sample at your current GPS position, taken once per render frame and shared with the SVT camera-floor calculation.
- The result is rounded to the nearest 10 ft. Both the GPS altitude and the SRTM terrain sample carry ~10–30 ft of real precision, so a 1-ft display would just flicker on GPS/DEM jitter without telling you anything new — same minimum-resolved-value treatment that the altitude tape's rolling drum already uses.

### Display states

| State | Reading | Why |
|---|---|-----|
| Above ground | `1230` (white, comma-grouped for ≥1000) | Normal flight, nearest 10 ft. |
| At or below ground | `---` (dim grey) | Sensor / DEM disagreement (baro miss-set, runway elev vs SRTM, missing tile). Not useful info — show dashes rather than a misleading negative. |
| No GPS | (hidden) | No position, no terrain lookup. |
| Outside SRTM coverage | (hidden) | Tile not loaded; would be misleading. |

### Cost

Reuses the same SRTM lookup the SVT renderer does for the camera-floor clamp, so it costs zero additional disk I/O per frame.

---

### Synthetic Approach (HITS + VDI)

The PFD can load a synthetic approach to any runway in the airport database. While an approach is active you get a set of coordinated cues:

- **HITS boxes** (cyan, 3D) along the approach path — fly through them.
- **VDI** (vertical glideslope diamond) on the right side of the AI — fly to the diamond.
- **CDI** scaled to ±0.3 NM full-scale (see §16) — fly to the diamond.
- **Approach-fix sign-posts** — an **amber** 3D diamond at each approach fix, floating at that fix's **published crossing altitude** with a vertical post dropping to the terrain, so you can eyeball whether you're high or low on the step-down profile.
- **Next-fix label** — the fix you're currently flying to is labelled (amber) with its **ident + crossing altitude** above its diamond; only the active fix is labelled, to keep the view clear.
- **Magenta approach course line** — the whole approach (initial fix → threshold, every leg) is drawn on the SVT as a bright-magenta terrain-draped course line, alongside the cyan HITS corridor.

The trace on the moving-map inset turns cyan to match while the approach is active. The PFD also previews the **next flight-plan leg** as a **faded-magenta** 3D trace (the same colour the MFD uses for remaining legs) so you can see the upcoming turn before you get there.

### Loading an approach

1. Tap the **CDI strip** to open the waypoint keyboard.
2. Type the airport ident (e.g. `KSEZ`) and hit ENTER. The "Activate Direct to *XXXX*?" modal appears as usual.
3. **Before tapping ACTIVATE**, look at the bottom row of the keyboard for the **APPR** button. APPR appears when the entered airport has runway data loaded.
4. Tap **APPR**. The runway picker opens — a tile per runway end with the ident, course, and length.

Approach runway picker — KSEZ RWY 03 / RWY 21

5. Tap a runway tile. The approach activates: HITS boxes draw, the VDI appears, the CDI rescales to ±0.3 NM, the inset trace turns cyan, and the airport ident readout becomes `IDENT/RWY` (e.g. `KSEZ/03`).

Short final to KSEZ RWY 03 — cyan HITS boxes stack along the centreline, VDI on the right, KSEZ/03 readout, ±0.3 NM CDI scale

6. Tap **CANCEL APPROACH** at the bottom of the runway picker (only present when an approach is active) to clear the approach and revert to plain D2 to the airport.

Once an approach is loaded, the **FPL page** lists its legs in a read-only block indented under the destination — one row per fix (`↳ IDENT`) showing the published **crossing altitude** plus the **inbound track and distance** to that fix (e.g. `031°  2.4 nm`), in the selected HDG / CRS REF. Cross-check those tracks against the plate; the active leg is boxed green.

### HITS boxes

Cyan rectangles drawn along the approach path at the runway centreline. The corridor spans **threshold → the initial fix (IAF)** and follows the approach's **published step-down crossing altitudes** — not a fixed 3° / 5 NM final (that's only the fallback when a procedure has no published altitudes). Box geometry is unchanged: 300 ft wide × 200 ft tall, spaced 1000 ft apart, capped in count, and depth-tested against the SVT terrain so they're occluded correctly by intervening ridges.

The box centreline is the pilot's eye-line — fly the centre of the box, not the bottom. Each box is one closed-loop polyline (TL → TR → BR → BL → TL), so the geometry is light enough to add zero measurable cost to the SVT render.

### VDI

Vertical bar with a magenta diamond on the right side of the AI, just inside the altitude tape. **Only paints when an approach is active.**

| Diamond | Meaning |
|---|---|
| Centre line | On glideslope |
| Above centre | Glideslope is above you — fly up to the diamond |
| Below centre | Glideslope is below you — fly down to the diamond |
| Top dot | ½-scale below GS |
| Top edge | Full-scale (≥ 0.7°) below GS |
| Bottom dot | ½-scale above GS |
| Bottom edge | Full-scale (≥ 0.7°) above GS |

Full-scale deflection is **±0.7°** of glideslope error (LPV / ILS convention), referenced to a 3° GS to the threshold. `G`/`S` markers above and below the bar identify the indicator.

### Cyan inset trace

The lower-left moving-map inset already shows a course trace; while an approach is active the trace is drawn from the **threshold along the reciprocal of the published course** (i.e. the actual extended centreline) and rendered in cyan to match the HITS / VDI / CDI colour cluster. The ETE label in the inset corner also turns cyan in this mode.

### Sim glideslope behaviour

When the simulator is in **FOLLOW FLT PLAN** with an approach active (see §19), the AP captures the GS **only from above**. Below the GS it holds altitude until the GS descends to meet the aircraft, then captures from above — the standard real-world AP convention. This avoids the unphysical "climb to chase the diamond" behaviour and matches what most autopilots will (or won't) do when wired into the real system later.

---

## 17. Moving Map & Overlays

### Moving-Map Inset

A 2D top-down moving map sits at the lower-left of the AI. Off by default — turn it on in DISPLAY setup (`MAP INSET`). When enabled it draws hypsometric terrain, water, state and country boundary lines, runways, airports, obstacles, and the active direct-to course line over a black backplate, with own-ship pinned to the centre and the map rotating in either **TRK↑** or **N↑**.

Moving-map inset on a long direct-to leg at AUTO range — magenta great-circle line passes through ownship, set boundaries faded in around the leg

### Course line — great-circle, not rhumb

The magenta direct-to line is drawn as a polyline along the **great circle** from your activation point to the waypoint. On short legs (< 50 NM) the GC and a flat-earth straight line are visually identical, but on transcontinental legs (e.g. AZ → KOSH ≈ 1200 NM) the GC bends meaningfully — the line you see on the inset is the same curve the CDI references and the SVT direct-to trace draws in 3D, so all three views agree on which side of course you're on.

### When an approach is active

The magenta D2 line is replaced by a cyan line drawn from the **threshold along the reciprocal of the published course** (the actual extended centreline), following the published final-approach course that the HITS corridor covers. The ETE label in the corner also turns cyan to match the HITS / VDI / cyan-CDI colour cluster (§16).

### Zoom ranges + orientation

| Range | Orientation | Notes |
|---:|---|---|
| 1 NM | TRK↑ or N↑ (user choice) | Pattern work, taxi survey |
| 2 / 5 / 10 / 20 / 40 NM | TRK↑ or N↑ (user choice) | Everyday flight; default is 5 NM |
| **80 NM** | **N↑ forced** | Whole-leg picture; rotated terrain tint smears at this scale |
| **160 NM** | **N↑ forced** | Cross-country overview |
| **AUTO** | **N↑ forced** | Picks the smallest standard step that contains the active direct-to (capped at 160 NM); destination doesn't spin under the chevron |

At 80 NM and 160 NM the inset forces north-up regardless of the user setting — the whole-leg picture matters more than nose-up orientation at that scale, the rotated terrain tint smears more visibly, and the async tint rebuild only has to run once per quantised centre instead of every heading change. AUTO mode picks the smallest standard step that contains the leg (with 10 % framing margin) and likewise locks to north-up.

### Tap-to-zoom and tap-to-flip-orientation

Tap-zones inside the inset:

- **Tap the left half** → zoom out one snap-point (e.g. 5 → 10 NM). On the largest range with a direct-to active, tap again to switch to **AUTO**.
- **Tap the right half** → zoom in one snap-point. From AUTO, taps zoom in to the largest standard step (160 NM) and continue downward.
- **Pinch** (two-finger spread / pinch) → also walks the snap-points if the touch driver surfaces FINGERMOTION events. Single-tap is the reliable fallback.
- **Tap the orientation label** in the chrome (`TRK↑` / `N↑`) → toggle between the two. The toggle is inert at 80 NM and above (the inset is locked to N↑ there).

Defaults for range and orientation are set in DISPLAY setup (`MAP RANGE`, `MAP INSET` orientation pair). Per-layer visibility (terrain / water / airports / runways / obstacles / state lines / country lines / direct-to) is toggleable from the same setup screen via the `MAP LAYERS` row of pills.

---

### Winds Aloft (WND)

Wind barbs and temperatures aloft can be overlaid on the moving map (both the inset and the full-screen MFD). The data is the GFS pressure-level forecast, pulled from Open-Meteo over the internet — **US-only**, no key required.

WND page — wind barbs + temperatures across the moving map, with the altitude / forecast-time buttons and the WINDS n/6 status line

### Turning it on

The map carries a cycle of weather/airspace overlays selected by the **OVLY** label (lower-left corner of the map). Cycle it to **WND** to show winds. The overlay choice persists.

### Reading the barbs

Each barb is a standard meteorological wind barb at a grid point: the shaft points **toward the wind source**, with pennants = 50 kt, full barbs = 10 kt, half barbs = 5 kt. The number beside each barb is the **temperature** (°C) at the selected altitude. `LV` (light/variable) is shown as a small circle when the wind is below ~3 kt.

### Altitude and forecast time

Two buttons appear in the map chrome on the WND page:

- **Altitude** (e.g. `9k ft`) — cycles the barb altitude through **3,000 / 6,000 / 9,000 / 12,000 / 18,000 ft**. (Capped at 18,000 ft — non-pressurised GA altitudes — which also keeps the data pull small.)
- **Forecast time** (`NOW`, `+3h`, `+6h` …) — steps the forecast valid-time ahead; each pull carries 48 h of hourly steps so changing the altitude doesn't re-fetch, but changing the forecast time does.

### Zoom on the WND page

The winds page keeps its **own zoom, limited to 40 / 80 / 160 NM** (winds don't vary enough to need a closer view, and this doesn't disturb your terrain-map zoom when you switch overlays). Barbs render at all three; below 40 NM they're hidden. The barb spread is denser on the big MFD and thinned on the small inset at 160 NM so it stays readable.

### Status line — `WINDS n/6 · age`

A status line under the WX line shows how much of the national grid is loaded and how old it is: e.g. `WINDS 4/6 · 12m` (4 of 6 zones, oldest 12 min old). **Green** when all six zones are loaded, **amber** while it's still filling (with a trailing `…`).

### How the data is fetched — pull on the ground, fly offline

Winds are cached as a **national grid split into 6 zones** and written to disk (`data/winds/conus_winds.json`):

- Whenever the display has internet, it fills any stale zone **one at a time**, the **zone you're in first**, then outward — so you can pull the whole US **on the ground** and then fly with no connection.
- A zone is only re-pulled once it's **more than 3 hours old** (GFS only reissues every ~6 h). A restart reloads the disk cache instantly with **no** network calls.
- If a fetch fails (no signal, server busy, rate-limited) it backs off and retries later; the cached picture keeps showing.

### Sharing between displays (multi-screen panels)

Open-Meteo's free tier is rate-limited **per internet connection**, so three displays each pulling the whole US would trip the limit and starve each other. They now **share over the cabin network** (the same screen-sync link used for bugs/flight-plans): the display with internet fetches each zone and broadcasts it, and the **others adopt it and make no Open-Meteo calls of their own** while a peer is feeding them. One display feeds the whole panel. This is automatic whenever screen-sync is enabled. In the journal you'll see one display log `[WX:winds] fetched zone N` and the others `adopted zone N from peer`.

---

### Weather — Sources and Overlays

Beyond winds aloft (§17), the display can show **METARs, TAFs, AIRMETs/SIGMETs, NEXRAD radar, and NOTAMs**. Weather comes from two independent paths and the display blends them:

- **Internet (INET)** — `aviationweather.gov` (AWC) for METAR/TAF/AIRMET/SIGMET, Open-Meteo for winds, and the FAA NOTAM API (key required, see §12). No subscription; needs an internet path.
- **Radio (FIS-B)** — the 978 MHz UAT uplink decoded from an ADS-B receiver (see `Docs/ADSB_IN.md`). Free over the air, no internet needed.

### Source toggle — RADIO / AUTO / INET

The map's left status strip shows a **WX** line you can tap to cycle the weather source:

- **AUTO** (default) — use both; for any given station FIS-B (radio) wins and the internet backfills everything the radio didn't deliver.
- **RADIO** — FIS-B only (internet poller paused).
- **INET** — internet only (radio ignored).

A parallel **ADS-B** line cycles the *traffic* source the same way (§17). Both persist in `data/settings.json`.

### Status lines and provenance

The status strip reads, e.g., `WX AUTO R3 I12 2m`:

- **mode** — AUTO / RADIO / INET.
- **R*n*** — stations heard on the **R**adio (FIS-B).
- **I*n*** — stations from the **I**nternet.
- **age** — time since the last update (`45s`, `2m`; blank when very fresh).
- **Colour:** green = receiving; amber (with a trailing `…`) = enabled but nothing yet.

Each readout is tagged with its origin — **`FIS-B`** or **`INET`** — and a data-age (e.g. METARs show "Observed 15 min ago"), so you always know how the weather got to you and how old it is.

### The overlay cycle (OVLY)

The map shows **one** weather/airspace overlay at a time, selected by the **OVLY** label in the map's lower-left corner. Tap it to cycle:

**ASP → TFC → MET → WND → NEX → (back to ASP)**

| Label | Overlay |
|---|---|
| **ASP** | Airspace (Class B/C/D, MOA, Restricted/Prohibited boundaries) — needs an airspace file (§12 data notes). |
| **TFC** | Traffic-focus — lifts the nearby-only clamp and shows all ADS-B traffic (§17). |
| **MET** | METAR station dots (idents labelled when zoomed in < 160 NM) + the tap-for-readout weather picker. |
| **WND** | Winds aloft (§17). |
| **NEX** | NEXRAD reflectivity. |

(If you turn on more than one layer by hand from the MAP LAYERS pills, OVLY reads **MULTI**; the next tap collapses back to a single overlay.) Traffic is drawn on **every** page (clamped to nearby targets except on TFC), so you never lose collision awareness by looking at weather.

### MET page — METARs and the readout picker

MET page — flight-category station dots and a decoded METAR readout

On **MET**, each reporting station is a dot coloured by flight category: **green VFR · blue MVFR · red IFR · magenta LIFR**. When you're zoomed in (map range below 160 NM) each dot is **labelled with its station ident** (hidden at wider zoom so the map stays a clean dot field). Tap a dot (or an airport) and choose **Weather *ICAO*** to open the readout, which has tabs for:

- **METAR** — wind, visibility, ceiling, altimeter, temp/dew, and the raw line, with the observation age.
- **TAF** — the forecast broken into INITIAL / FROM / BECMG / TEMPO / PROB periods.
- **AIRMET / SIGMET** — scrollable bulletins, **nearest-first**, flagged **ON ROUTE** when the hazard is within ~30 NM of your active leg.
- **NOTAM** — scrollable, nearest-first, scoped to a tight zoom-following radius (~10–40 nm) so the list stays local rather than returning every NOTAM for hundreds of miles. Needs the FAA key on **one** display (§12); both the NOTAMs and the key are shared to the other displays over the cabin network.

A tab is greyed out when there's no data for it. If the field you tapped has no METAR/TAF/winds of its own, the display falls back to the **nearest** reporting station and labels it with the distance/bearing. Long readouts scroll (drag, with a scrollbar); tap outside to close.

**Graphical AIRMET/SIGMET:** hazard areas that carry a polygon are shaded on the map; tap inside one to open its bulletin (smallest polygon wins when they nest).

### ASP page — airspace

On **ASP**, airspace boundaries are drawn over the map: a magenta ring for Class C (labelled with the facility name and the floor/ceiling, e.g. `PRESCOTT 45/SFC`) and a blue ring for Class D. ASP is one stop in the OVLY cycle and needs an airspace file loaded (see §14). Individual classes can be hidden with the per-class toggles (§14).

Full-screen MFD on the ASP page — magenta Class C ring (PRESCOTT 45/SFC) and a blue Class D ring around KSEZ over the map with the magenta course line and bottom data strip

### NEX page — NEXRAD radar

Full-screen MFD on the NEX page — a green→yellow→red NEXRAD reflectivity cell painted over the moving map

On **NEX**, radar reflectivity is painted as coloured intensity cells. Two ages are badged on the status strip: **`NEX`** = how long since the block was received, and **`NEX RDR valid`** = how stale the radar *mosaic* itself is (green < 10 min, amber 10–20, red > 20) — FIS-B radar can be several minutes older than when you received it, so always read the *valid* age.

---

### Traffic — ADS-B / FIS-B IN

Nearby aircraft are shown on the map (and feed the collision alert) from ADS-B IN — either a radio receiver (1090ES + 978 UAT over GDL90/UDP, port 4000) or the built-in internet feed, blended like weather. Tap the **ADS-B** status line to cycle the traffic source **AUTO / RADIO / INET** (`R`/`I` counts split the two).

**Own-ship echo suppression (INET).** A public ADS-B aggregator has no way to know which hex code is *your* aircraft, so it hands your own transponder back like any other target — an annoying diamond glued to the ownship symbol. A radio receiver avoids this (it decodes the GDL90 Ownship Report and never files it as traffic); the internet feed has no such report, so the display rejects the echo itself: any internet target sitting on top of you (within ~0.6 NM and, when both altitudes are known, ~350 ft) is treated as the echo and dropped. When you're moving, a velocity check keeps a *genuine* close pass visible — a real intruder that near usually isn't also flying your exact speed and heading, whereas the echo carries your own velocity by definition. Once identified, the echo's hex is latched and stays suppressed through the feed's few-seconds position lag. Radio traffic is untouched.

### Reading a target

Traffic — diamonds with leader lines and relative-altitude tags, colour-coded by threat

Each target is a **diamond** with a short **leader line** in its direction of travel and a **data tag** showing relative altitude in hundreds of feet (`+05` above, `−12` below) plus `↑`/`↓` when climbing/descending faster than 200 fpm. Colour is the threat tier:

| Tier | Colour | Meaning | Criterion |
|---|---|---|---|
| **Alert** | Red (filled) | Collision threat (RA) | **closure-based** — actually converging and time-to-closest **tau ≤ 30 s** while within the vertical band (±600 ft), plus a hard floor (anything inside **1 NM / 400 ft** regardless of closure) |
| **Proximate** | Amber (filled) | Caution | within **6 NM** *and* **1200 ft** |
| **Other** | Cyan (outline) | Advisory | beyond the above |

The **Alert** tier is **closure/time-based**, like a real TAS — not a flat ring. Parallel, diverging, or co-altitude-but-not-closing traffic (very common in the pattern) stays **amber proximate** and does *not* trip a red RA or the callout; only traffic that's genuinely converging *and* will be close soon goes red. Closure is estimated over real ADS-B update intervals and smoothed; the RA must persist briefly before it fires (so a borderline target flickers amber, not red) and then latches so the cue stays up and the callout fires once. Tuning lives in `shared/config_base.py` (`ADSB_TAU_S`, `ADSB_ALERT_FLOOR_NM/FT`, `ADSB_RA_ARM_S/HOLD_S`).

On weather/airspace pages and the PFD inset, traffic is **clamped to nearby** (within ~7 NM / 3000 ft) to keep the picture clean; the **TFC** page lifts the clamp and shows everything. **Alert-class traffic is never hidden** — not by the clamp, and not by the declutter filters below.

### Detail card

On the full-screen MFD, tap a diamond to open its detail card: **callsign** (or hex ID), altitude (absolute + relative), groundspeed, track, vertical speed (Climbing/Descending/Level), and range/bearing (e.g. "5.2 NM SE"), with a **RADIO**/**INET** source tag. Tap again to dismiss.

### Declutter filters

Two DISPLAY-setup rows thin distant/irrelevant traffic (alert-class still always shows):

- **TFC ALT** — ALL / ±2k / ±5k / ±10k ft (hide targets beyond that relative-altitude band).
- **TFC RANGE** — ALL / 5 / 10 / 20 / 40 NM.

### Collision alert

When a target becomes an alert (RA) — i.e. it's genuinely converging with tau ≤ 30 s, or inside the 1 NM/400 ft floor — a red **TRAFFIC** banner flashes at 1 Hz: on the PFD it's a compact badge ("TFC 2:00 −200" = 2 o'clock, 200 ft below); on the MFD it's a larger top-centre banner with the range added. On the Pi 4 a **"Traffic, Traffic"** voice callout fires with it (gated by the ALERT AUDIO master switch — §10/§20). The callout is edge-triggered on the nearest **new** threat and the alert **latches** for a few seconds, so it fires once and the cue stays up rather than stuttering on a borderline geometry.

---

## 18. Demo Mode

Scripted Sedona, AZ flight. No hardware needed.

```bash
python3 pi4/pfd.py --demo
python3 pi4/pfd.py --demo --sim   # windowed
```

Cycles: level cruise → climbing left turn → level → descending right turn. SVT terrain renders if Sedona tiles are present.

---

## 19. Flight Simulator

Flight simulator setup screen

A full-PFD flight simulator is built in. It drives every instrument on the display through an internal autopilot model — so every tape, badge, bug, the SVT background, airport symbols, runway polygons, and TAWS alerting all behave exactly as they would with a live AHRS link. No external aircraft, no Pico W, and no network are needed.
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

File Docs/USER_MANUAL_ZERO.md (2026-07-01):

# AHRS PFD — Pi Zero 2W Pilot's User Manual

**Software version 0.3 · Hardware: AHRS PCB rev A (Pico W + WT901 + NEO-6M + BME280 + SDP33-1500Pa) + Pi Zero 2W · Display: Waveshare 3.5" DPI LCD (640×480)**

*No SVT version — plain horizon background with TAWS alerting*

> This manual covers the Pi Zero 2W version. For the full SVT version (Pi 4), see USER_MANUAL_PI4.md.

---

## Contents

1. [Screen Overview](#1-screen-overview)
2. [Airspeed Tape](#2-airspeed-tape)
3. [Altitude Tape and VSI](#3-altitude-tape-and-vsi)
4. [Attitude Indicator](#4-attitude-indicator)
5. [Heading Tape](#5-heading-tape)
6. [Status Badges](#6-status-badges)
6A. [PFD Top Ribbon](#6a-pfd-top-ribbon)
7. [Setting Bugs](#7-setting-bugs)
8. [Setup Menu](#8-setup-menu)
9. [Flight Profile — V-Speeds and Callsign](#9-flight-profile--v-speeds-and-callsign)
10. [Display Settings](#10-display-settings)
11. [AHRS / Sensors](#11-ahrs--sensors)
12. [Connectivity](#12-connectivity)
13. [System](#13-system)
14. [Terrain Data Download](#14-terrain-data-download)
15. [Obstacle Data Download](#15-obstacle-data-download)
16. [Airport Data Download](#16-airport-data-download)
16A. [Full-Screen MFD](#16a-full-screen-mfd)
16B. [Weather](#16b-weather)
16C. [Traffic (ADS-B / FIS-B IN)](#16c-traffic-ads-b--fis-b-in)
16D. [Airspace Data](#16d-airspace-data)
17. [Demo Mode](#17-demo-mode)
18. [Flight Simulator](#18-flight-simulator)
19. [AHRS PCB and Air-Data Hardware](#19-ahrs-pcb-and-air-data-hardware)

---

## 1. Screen Overview

PFD — level cruise

The display is divided into five fixed zones:

| Zone | Width / Height | Content |
|---|---|---|
| Left tape | 74 px wide | Airspeed |
| Right tape | 82 px wide | Altitude + VSI |
| Centre AI | remainder | Attitude (plain horizon) |
| Bottom strip | 44 px tall | Heading tape |
| Top ribbon | 22 px tall | Bug readouts + a configurable 5-slot data ribbon (§6A) |

Everything is rendered at 30 fps directly on the framebuffer — there is no operating-system UI underneath.

---

## 2. Airspeed Tape

Climb with bank and V-speed bands

### Reading the tape

The tape scrolls so that current airspeed is always at the centred **Veeder-Root drum** readout. The drum shows two-digit resolution: the **ones** digit rolls smoothly on a narrow inner cell to the right, and the **tens** digit cascades one slot up when the ones cross 9 → 0. A faint preview of the next digit (and the digit two slots above) peeks in from the top of the box so crossings through 10 / 100 are obvious at a glance.

### Colour arcs (right edge of tape)

| Arc | Colour | Meaning |
|-----|---|---|
| White | White | VS0 – VFE — flap operating range |
| Green | Green | VS1 – VNO — normal operating range |
| Yellow | Yellow | VNO – VNE — caution / structural |
| Red line | Red | VNE — never-exceed |

The drum numerals turn **yellow** above VNO and **red** above VNE to reinforce the overspeed warning.

### Speed bug

A chevron marker on the tape tracks the speed bug. The button at the **top** of the airspeed tape shows the bug value or `---` when not set. Tap it to enter a new value with the numpad.

The bug and its readout button are **colour-coded by data source**:

| Colour | Source |
|---|---|
| Cyan | IAS — SDP33-1500Pa differential-pressure sensor with BME280 density correction. Default when the AHRS reports `airdata_ok = True`. |
| Magenta | GPS groundspeed (GS) — fallback when the SDP33 isn't healthy or AIRSPEED SOURCE is forced to GPS GS in AHRS / Sensors. |

---

## 3. Altitude Tape and VSI

Descending final approach

### Altitude tape

Altitude drum passing 10000 ft — the leading "1" is visible above the "0" before integer roll-over

Current altitude is shown in the Veeder-Root drum on the right side. The tape scrolls in 50 ft increments with labels every 100 ft. The drum renders as two (below 100 ft) or three (above) independent cells that cascade at the correct rates — the altitude value is always the number vertically centred in the large outer cell, and the leading column reveals the next digit one slot above so transitions through 1000 / 10000 ft stay readable.

The **altitude bug** chevron marks the selected target altitude. Tap the bug button at the **top** of the alt tape to change it. Entry is in hundreds of feet — type `85` and the display shows `8500 ft`.

The bug and its readout button are **colour-coded by altitude source**:

| Colour | Source |
|---|---|
| Cyan | Barometric altitude (BME280 active) — primary |
| Magenta | GPS altitude (baro sensor failed or absent) — degraded |

### Baro setting

The button at the **bottom-right** of the heading strip shows the current baro setting:

| Display | Colour | Meaning |
|---|---|---|
| `29.92 IN` | Cyan | BME280 active; inHg |
| `1013 hPa` | Cyan | BME280 active; hPa unit selected |
| `GPS ALT` | Magenta | No baro sensor; GPS altitude used |

Tap the box to adjust the baro setting with the numpad when the sensor is active.

### VSI (vertical speed indicator)

A thin green / amber bar runs along the inner edge of the alt tape. It deflects upward for climbs and downward for descents. Scale is ±2000 fpm. The bar turns amber above ±1500 fpm.

---

## 4. Attitude Indicator

### Horizon background

The Pi Zero 2W version uses a **plain horizon background**: solid blue sky above the horizon line and solid brown ground below. Synthetic Vision Terrain (SVT) background rendering is not available on this version due to the Pi Zero 2W's GPU limitations. For SVT terrain rendering, see the Pi 4 version.

**Note:** Although the AI background does not show terrain, SRTM terrain data is still used for **TAWS proximity alerting** (see Section 14). Terrain and obstacle proximity banners function normally when terrain tiles are loaded.

### Pitch ladder

Grey pitch bars are drawn at ±5°, ±10°, ±15°, ±20°, ±30°. The bars narrow as pitch increases, consistent with the GI-275 style. The horizon bar is white.

### Roll arc and pointer

A graduated arc at the top of the AI shows bank angle using the **sky-pointer** convention: the arc and its tick marks (10°, 20°, 30°, 45°, 60° either side) rotate with the sky. The fixed aircraft reference inside the arc stays at the top of the screen and reads the current bank angle directly on the graduated scale. A moving outer doghouse marks the sky's "up" direction.

### Aircraft symbol

An amber swept-delta wing symbol sits fixed at the AI centre.

### Slip/skid indicator

A short white horizontal bar (16×4 px) sits below the roll pointer's doghouse base and slides laterally with uncoordinated flight. Centred under the zero-bank triangle = coordinated flight. Step on the rudder toward the bar to re-centre it — the direction mimics the ball of a conventional turn-coordinator inclinometer.

### Terrain / obstacle proximity alert

A banner appears centred at the top of the display when terrain or an obstacle is within a critical clearance margin:

**TERRAIN CAUTION** (amber, steady) — terrain or obstacle MSL height is within **500 ft** below aircraft altitude.

**PULL UP TERRAIN** (red, 1 Hz flash) — terrain or obstacle MSL height is within **100 ft** below aircraft altitude.

**Low-speed inhibit**: alerts are silenced below **VS0** (default 48 kt). Taxi, takeoff roll and landing rollout don't trip a continuous alert — the alert pipeline only arms above the configured stall speed. (The Pi 4 also adds forward look-ahead and voice callouts on top of this; the Pi Zero variant has neither because it doesn't run an audio stack and the spot-sampled terrain check is adequate for the slower airframes this build typically serves.)

Requires a valid GPS fix and SRTM terrain tiles or obstacle data to be loaded.

---

## 5. Heading Tape

The heading tape runs across the bottom of the screen.

### Heading source modes

**MAG mode (default):** Heading from the Pico W magnetometer. Heading box has a dim border and `M` subscript.

**GPS TRK mode:** Heading slewed to GPS ground track via complementary filter. Heading box border turns **magenta**, subscript changes to `G`. The `GPS TRK` badge appears.

### Track pointer

When GPS fix is valid and in MAG mode, a **magenta** tick mark shows GPS ground track. Drift between heading and track tick indicates wind. Magenta matches the PFD's data-source convention: GPS-derived values and indicators are magenta; sensor-derived values are cyan.

### Heading bug

A chevron marker tracks the HDG bug. Tap the readout button (bottom-left) to enter a new heading. Colour-coded: CYAN (MAG mode) / MAGENTA (GPS TRK mode).

### Magnetic vs True reference

A small **`MAG`** / **`TRU`** tag at the top-left of the heading box shows which reference all headings and courses use:

- **`MAG` (default):** Magnetic — matches charts, plates, runway numbers and ATC. The system computes everything in **true** internally and subtracts the local **WMM2025** magnetic variation at your GPS position (≈10–11° east in Arizona).
- **`TRU` (amber):** True — values shown exactly as computed, no variation applied.

Toggle it at **Setup → Display → UNITS → HDG / CRS REF**. It's one global setting covering the heading tape, the data-strip `TRK` / `HDG` / `BTW` / `DTK` / `WIND` fields, the CDI bearing, and flight-plan leg courses. Persists across power cycles, per-display. Without a GPS fix, MAG shows true until a fix is acquired. The magnetometer is still calibrated to *true* cardinals — MAG is purely a display conversion.

---

## 6. Status Badges

Badges appear **only when something requires attention** — the strip is blank during normal flight.

| Badge | Colour | Meaning |
|---|---|---|
| `AHRS FAIL` | Red | IMU data absent or invalid |
| `NO LINK` | Red | SSE stream not connected |
| `NO TER` | Amber | No SRTM terrain tiles loaded |
| `NO OBS` | Amber | No FAA obstacle data loaded |
| `EXP OBS` | Orange | Obstacle data > 28 days old |
| `NO APT` | Amber | No airport data loaded |
| `EXP APT` | Orange | Airport data older than expiry |
| `GPS TRK` | Magenta | GPS TRK heading mode active |
| `GPS ALT` | Amber | Altitude from GPS (baro failed) |
| `GPS` *N*`sat` | Amber | GPS acquiring — *N* satellites visible, no fix yet |
| `NO GPS` | Red | GPS hardware not responding / no satellites |

---

## 6A. PFD Top Ribbon

The band across the top of the attitude indicator — between the groundspeed (top-left) and altitude (top-right) bug boxes — is a **configurable 5-slot readout ribbon**, separate from the MFD's bottom data strip (§16A).

**Default fields:** **AGL · TAS · OAT · WIND · ETAD** (height above terrain, true airspeed, outside air temperature, wind direction/speed, and arrival at the final destination). **Tap the ribbon** to open its picker and assign any of the same fields the MFD data strip offers (§16A); it keeps its **own** 5-slot selection, separate from the MFD strip, and both persist in `data/settings.json`.

A field reads `--` (or `---/--` for WIND) until its source is live — AGL needs terrain data, TAS/OAT/WIND need air-data (WIND is computed from the TAS + GPS-track triangle without an OAT sensor), and ETAD needs a flight plan or Direct-To. Alert annunciations paint over the ribbon, so a warning is never hidden behind a readout. Behaviour matches the Pi 4 — see **Pi 4 manual §6A** for the full field table and the ARRIVAL LOCAL/ZULU toggle.

---

## 7. Setting Bugs

Three settable bugs — altitude, heading, and ground-speed — plus the baro setting. All four use the same numpad overlay.

### Bug buttons on the PFD

The bug buttons fill the full heading-strip height so they're easy to hit without looking away from the horizon.

| Button | Location | Opens |
|---|---|---|
| **Speed bug** | Top of airspeed tape | SET SPD BUG |
| **Altitude bug** | Top of altitude tape | SET ALTITUDE BUG |
| **HDG bug** | Bottom-left of heading strip | SET HDG BUG |
| **Baro** | Bottom-right of heading strip | SET BARO inHg / SET BARO hPa |

### Numpad entry

Altitude bug numpad — current value 8500 shown as placeholder

Tap the readout button for the bug you want to change. The numpad overlays the live PFD. **The current value is shown as a dim placeholder** under the entry field — the input starts empty so tapping ENTER without typing keeps the previous value.

| Key | Action |
|-----|---|
| `0–9` | Append digit to buffer |
| `⌫` | Delete last digit |
| `ENTER` | Commit (or keep current value if buffer empty) |
| `CANCEL` | Discard |

| Target | Entry | Example |
|---|---|---|
| Altitude | hundreds of feet | `85` → `8500 ft` |
| Heading | 3 digits | `270` → `270°` |
| Speed | whole knots | `90` → `90 kt` |

### Adjusting baro

Baro numpad — inHg

Tap the baro button. The numpad title switches between **SET BARO inHg** and **SET BARO hPa** based on the unit selected in Display Settings, and pre-populates the placeholder with the current baro value.

- **inHg mode**: type four digits, decimal auto-inserted after second digit (`2992` → `29.92`).
- **hPa mode**: plain four-digit integer (`1013`).

### Tapping the tape directly

Tap the **heading tape** to jump the bug to that bearing. Tap the **altitude tape** to set the bug (nearest 100 ft).

### Clearing a bug

Enter `0` and press `ENTER`. (Baro resets to 29.92 in / 1013 hPa.)

---

## 8. Setup Menu

Main setup screen

Two-finger press-and-hold anywhere on the PFD for 0.8 seconds.

| Tile | Screen |
|---|---|
| FLIGHT PROFILE | V-speeds, callsign |
| DISPLAY | Units, brightness, map layers |
| AHRS / SENSORS | Trim, mounting, heading/airspeed source |
| CONNECTIVITY | AHRS URL, WiFi |
| SYSTEM | Version, ENABLE MFD, terrain/obstacle data, simulator |
| EXIT | Return to PFD |

### Gestures — multi-finger holds

Two distinct multi-finger gestures exist on the PFD/MFD view; the count of fingers held disambiguates them. The number of fingers is locked in by the *peak* count during the hold, so a stray third finger after 0.8 s won't accidentally fire the setup hold.

| Gesture | Duration | Effect |
|---|---:|---|
| 2-finger hold | 0.8 s | Enter Setup menu (this screen) |
| 3-finger hold | 2.0 s | Swap PFD ↔ MFD view (only when ENABLE MFD is ON — see §13) |

A short, deliberate gesture for entering setup and a longer, harder-to-misfire gesture for the in-flight view swap. The MFD's own top-right **PFD** button is still a valid tap-back; the gesture is the workflow-friendly version that works from either side without hunting for a button.

---

## 9. Flight Profile — V-Speeds and Callsign

Flight profile screen

| Field | Default | Meaning |
|---|---|---|
| VS0 | 48 kt | Stall — flaps full |
| VS1 | 55 kt | Stall — clean |
| VFE | 85 kt | Max flap extension |
| VNO | 129 kt | Max structural cruising |
| VNE | 163 kt | Never-exceed |
| VA  | 105 kt | Maneuvering |
| VY  | 74 kt | Best rate of climb |
| VX  | 62 kt | Best angle of climb |

Defaults are Cessna 172S. Tap any V-speed box to enter a new value. **RESET DEFAULTS** restores all values.

### Aircraft callsign and A/C type

Keyboard — QWERTY with period and colon on row 3

Tap the **CALLSIGN** or **A/C TYPE** box to open the on-screen keyboard. The current field value is pre-populated so you can edit in place.

Rows:

1. `1 2 3 4 5 6 7 8 9 0`
2. `Q W E R T Y U I O P`
3. `A S D F G H J K L`
4. `Z X C V B N M . : ⌫`

Action row: **CANCEL**, hyphen (`-`), **SPACE**, **DONE**. The period (`.`) and colon (`:`) keys are useful when editing the AHRS URL from the Connectivity screen, which uses this same keyboard. **⌫** deletes one character from the end of the buffer.

---

## 10. Display Settings

The screen is split into four tabbed sub-pages — **UNITS**, **DISPLAY**, **MAP**, and **HORIZON** — selected from the tab bar under the header. Tapping a tab swaps the visible rows; each page fits on screen with no scrolling. The screen always opens on the **UNITS** tab.

**UNITS** — speed / altitude / pressure units:

Display settings — UNITS tab

**DISPLAY** — brightness and night mode:

Display settings — DISPLAY tab

**MAP** — winds-aloft level, traffic filters, and the MAP LAYERS pills:

Display settings — MAP tab

**HORIZON** — **PITCH TRIM** and **ROLL TRIM** (± 0.1° steppers): a display-side cosmetic offset that nudges the drawn horizon on this display only. Separate from the AHRS **ZERO** on the AHRS / Sensors page (§11), which re-references the sensor itself.

### Speed units
**KT**, **MPH**, or **KPH**. All V-speed arcs and GS bug scale together.

### Altitude units
**FT** or **M**.

### Pressure units
**inHg** or **hPa**.

### Heading / course reference
**MAG** (default) or **TRUE** — the reference for every displayed heading and course (heading tape, `TRK` / `HDG` / `BTW` / `DTK` / `WIND` strip fields, CDI bearing, flight-plan leg courses). MAG applies the WMM2025 magnetic variation at GPS position so the numbers match charts/plates/ATC; TRUE shows the raw computed values with a `T` suffix. The heading box carries a `MAG` / `TRU` tag. See §5.

### Brightness
Tap **−** or **+** to step between levels 1–10. Routed to a hardware-PWM channel on **GPIO 18** (configured by the `dtoverlay=pwm,pin=18,func=2` line in `/boot/firmware/config.txt`); `pfd.service`'s `ExecStartPre` block runs as root once at boot to export the channel, set the period (1 kHz) and polarity (inversed — the Waveshare 3.5" DPI backlight is active-low), and hand a group-writable `duty_cycle` node to the unprivileged PFD process. The slider value is persisted in `data/settings.json` and restored on every boot.

The 1–10 scale maps to PWM duty via a hand-tuned non-linear curve, not a linear ramp: the LED driver in the Waveshare panel doesn't conduct below ~22 % duty (anything dimmer is indistinguishable from off), so level 1 lives at the conduction floor and the bottom of the slider has 4–5 % steps for fine control in a dim cockpit. The top half steps at ~11 % so each click is daylight-visible.

| Level | Duty | Use |
|---:|-----:|-----|
| 1 | 22 % | Dimmest visible — night cockpit floor |
| 2 | 26 % | |
| 3 | 30 % | |
| 4 | 35 % | |
| 5 | 44 % | |
| 6 | 55 % | |
| 7 | 67 % | |
| 8 | 78 % | Default |
| 9 | 89 % | |
| 10 | 100 % | Full bright — daylight |

If the slider doesn't change panel output, check `journalctl -u pfd.service -b | grep '\[BL\]'`. The expected line is `[BL] Using PWM backlight: /sys/class/pwm/pwmchip0/pwm0/duty_cycle (period=1000000 ns)`. If you see `[BL] No backlight control available` instead, either the `dtoverlay=pwm,...` line isn't in `config.txt` or `pfd.service` was installed before the backlight-PWM patch landed (re-run `sudo bash pi_zero/setup.sh`).

### MAP LAYERS

A row of six toggle pills that gate which optional layers render on the MFD (and, in future, the moving-map inset). Each pill is independently on/off and persists in `data/settings.json`.

| Pill | Layer |
|---|---|
| **TER** | Hypsometric terrain tint (SRTM elevation → colour ramp) |
| **WTR** | Water mask (oceans + lakes rasterised from Natural Earth, painted blue) |
| **APT** | Airport / heliport / seaplane base symbols |
| **OBS** | FAA DOF obstacles (towers, antennas, wind turbines) |
| **STA** | State / province boundary polylines (Natural Earth admin_1), appears at ≥ 20 NM range |
| **CTRY** | Country boundary polylines (Natural Earth admin_0), tan colour distinct from STA's slate-blue, also ≥ 20 NM |

Toggling a pill takes effect on the next frame. Layers that aren't available because their data hasn't been downloaded yet (e.g. CTRY before the first water-mask download) silently no-op — the pill stays in whatever state you left it.

### Winds aloft (WND overlay)

Wind barbs + temperatures aloft can be overlaid on the MFD. Cycle the **OVLY** label (lower-left of the map) to **WND**. The data is the GFS pressure-level forecast from Open-Meteo (internet, US-only, no key). Identical to the Pi 4 — see the Pi 4 manual §16E for the full description. In brief:

- **Barbs** are standard met barbs (pennants 50 kt / full 10 kt / half 5 kt), shaft toward the source, with the temperature (°C) tagged beside each.
- **Altitude button** cycles **3k / 6k / 9k / 12k / 18k ft**; **forecast-time button** steps `NOW` / `+3h` / … (48 h carried per pull).
- The WND page keeps its **own zoom (40 / 80 / 160 NM only)**; barbs hide below 40 NM.
- A **`WINDS n/6 · age`** status line shows grid fill + age (green when all six zones are loaded, amber while filling).
- Winds are a **cached national grid (6 zones), pulled on the ground and written to disk** (`data/winds/conus_winds.json`), re-pulled only when a zone is **> 3 h** stale — so they survive a restart and work with no in-flight connection.
- **Multi-display sharing:** when more than one screen is on the cabin network with screen-sync enabled, the one with internet fetches and broadcasts each zone and the others **adopt it without calling Open-Meteo** — one display feeds the whole panel and the per-IP rate limit is never an issue.

(Pi Zero has no flight-path-vector marker yet — that's pi4 + iPhone only for now.)

---

## 11. AHRS / Sensors

AHRS setup screen

This page holds **only AHRS-sensor settings**. The display-side **PITCH / ROLL TRIM** (a cosmetic horizon nudge) moved to **DISPLAY → HORIZON** (§10) so the AHRS zero and the display zero aren't in the same place.

### Pitch align / Roll align
Input-side axis alignment — rotates the raw gyro/accel/mag *before* the attitude filter to cancel a small mounting tilt. ±0.1° steps, ±15° range, pushed to the AHRS and persisted in its flash. The green **ZERO** button on the PITCH ALIGN row is the one-tap flight-zero (below).

### ZERO (AHRS flight zero)
Tap **ZERO** (on the PITCH ALIGN row) while straight-and-level to re-zero the **AHRS itself** to the current attitude — the Sentry/ForeFlight "Level" cage. It folds the captured attitude into the AHRS **input-side axis alignment** (the raw gyro/accelerometer rotation applied *before* the attitude filter). It's pushed to the AHRS (USB `$ALIGN`, or HTTP `/align` on a WiFi-only link), **persisted in the AHRS flash**, and seen by every display — and because it fixes the mounting tilt at the sensor input, it also kills the yaw-into-pitch/roll coupling that makes a small error compound in turns. Clamped to ±15°; a bigger residual means the ORIENTATION/MOUNTING is wrong (fix those first). Tapping also clears any leftover display-side trim.

### Mounting orientation
**NORMAL** (label up) or **INVERTED** (label down).

### Heading source

AHRS setup — GPS TRK selected

| Option | Behaviour |
|---|---|
| **MAG** | Magnetometer heading. `M` subscript. |
| **GPS TRK** | Heading slaved to GPS track. `G` subscript, magenta border. |

### Airspeed source

| Option | Behaviour |
|---|---|
| **IAS SENSOR** | SDP33-1500Pa differential pressure + BME280 density correction. Cyan readout. Default when the AHRS reports `airdata_ok`. |
| **GPS GS** | GPS groundspeed. Magenta readout. Auto fallback when SDP33 is absent / unhealthy. |

### Compass calibration

Compass-calibration wizard mid-walk — "Captured NORTH", prompting for the next cardinal heading

The calibration wizard walks you through the four cardinal headings, capturing the magnetometer at each (e.g. **Captured NORTH**) and prompting for the next. Run it after a mounting change or when MAG heading drifts.

### AHRS firmware update

AHRS firmware loader — "Pushed firmware.py ✓" done state

The firmware loader pushes `firmware.py` to the Pico W AHRS over USB and reports a **Pushed firmware.py ✓** done state when complete.

---

## 12. Connectivity

Connectivity screen — editable fields, live STATUS badges, AHRS LINK diagnostics, live R/P/Y/ALT

### AHRS URL
Default `http://192.168.4.1`. Tap to edit — the keyboard lets you enter URLs directly (`.` and `:` are on the main QWERTY). The SSE stream reconnects when you tap DONE.

### WiFi SSID / PASSWORD
Tap either box to edit. Tap **APPLY WIFI** to write the config and switch networks. The Wi-Fi password is intentionally **not** persisted in `settings.json` — it must be re-entered when joining a new network.

WiFi networks scan list — networks with signal-strength bars and WPA/OPEN tags, plus a RESCAN button

The **WIFI NETWORKS** scan lists nearby networks with signal-strength bars and a **WPA / OPEN** tag; tap one to fill the SSID, or tap **RESCAN** to refresh.

### NOTAM KEY / SECRET / ENV
Optional. Paste an **FAA NMS-API** credential — **client_id** into **NOTAM KEY**, **client_secret** into **NOTAM SECRET** (masked) — and leave **NOTAM ENV** at `preprod` (`prod` only with production credentials). Enables NOTAMs in the MET readout picker (§16B); the poller reads them live (no reboot). Blank = NOTAMs off, rest of weather unaffected. You only need to enter the key on **one** display: the NOTAMs **and** the key are shared to the others over the cabin network (see Screen Sync below).

### Screen Sync
Like the Pi 4/5, the Zero peer-syncs with other displays on the cabin network — bugs, baro, direct-to, flight plans, **winds aloft, and NOTAMs** — over UDP, peer-to-peer. Master enable, the AUTO/USB/NET transport selector, per-category TX/RX toggles, the SHARE FPL toggle, and the peer/links diagnostics are all on the **Screen Sync** setup screen. See **Pi 4 manual §12A** for the full description; behaviour is identical. (Winds and NOTAM sharing are automatic — one display with internet/key feeds the rest, and entering the NOTAM key on one display pushes it to the others.)

Screen Sync setup — master enable, AUTO/USB/NET transport, per-category TX/RX toggles, SHARE FPL, and peers/links diagnostics

### STATUS row
Two coloured badges:

- **AHRS** — green "CONNECTED" when the SSE link is up; red "NO LINK" otherwise.
- **WiFi** — when up, shows `WiFi: <ssid>` with the actual network name the Pi is associated to (from `iwgetid`, truncated with `…` if longer than 18 chars); red "NO LINK" otherwise.

### AHRS LINK diagnostics row
Second status row, visible even when the AHRS badge is red so you can see **why**:

- Transport + port on the left (typically `WIFI http://192.168.4.1` on the Pi Zero 2W — USB serial fallback is Pi 4 only).
- **RX:** counter — frames received since boot (should tick ~20×/s on a healthy link).
- **ERR:** counter — parse failures.
- Last error string (truncated).
- Live **R / P / Y / ALT** on the right — confirms sensor output is sane. If RX climbs but R/P/Y stay at `+0.0°` the firmware is alive but the WT901 isn't talking (check TX→RX wiring).

### TEST AHRS
Issues a one-shot HTTP GET to the AHRS URL and reports success/failure. Use after APPLY WIFI to verify the Pi actually reaches the Pico W.

---

## 13. System

System screen

Shows firmware version, build date, display resolution, platform, terrain/obstacle status. Buttons for DIAGNOSTICS (future), RESET DEFAULTS, FLIGHT SIMULATOR, and **SHUTDOWN / REBOOT**.

**SHUTDOWN / REBOOT (graceful stop).** Halts or reboots the Pi cleanly instead of pulling power, which protects the SD card. Both are **arm-to-confirm**: first tap turns the button amber (*TAP AGAIN*), a second tap within 4 s executes; the arm auto-clears after 4 s. After SHUTDOWN, wait for the activity LED to stop, then cut power. (Scroll down if the buttons are below the fold. Needs the sudoers rule the setup script installs; on an older install run `sudo bash tools/install_shutdown_sudoers.sh` once.)

### ENABLE MFD

A single OFF / ON toggle row that gates the Multi-Function Display feature. The MFD is a full-screen 2D moving-map view (terrain, airports, obstacles, state + country boundaries) that replaces the AI horizon when active.

- **OFF** (default): the 3-finger swap gesture (§8) is disarmed and `display_mode` is pinned to `pfd`. The MFD is unreachable.
- **ON**: the 3-finger 2 s hold on either the PFD or the MFD flips between them. Once enabled the gesture is the day-to-day mode swap — you don't need to come back into Setup to change views.

The default is OFF so a fresh install boots straight to the PFD. If an older settings file already had `display_mode = "mfd"` (the legacy toggle), the system auto-migrates it to `mfd_enabled = True` on first boot after upgrade so existing piZ users don't have to re-find the option.

Disabling ENABLE MFD also forces the runtime view back to PFD immediately — a stale "I was on the MFD when I last shut down" state can't strand you in a view the feature gate now says shouldn't exist.

### Persistence

All configurable settings — V-speeds, tail number, units, backlight brightness, colour scheme, heading-source mode, Wi-Fi SSID, airport display filters, runway/centerline overlay toggles, ENABLE MFD, MAP LAYERS — persist across power cycles in `pi_zero/data/settings.json`. The file is written atomically on a background thread with a 1.5 s debounce, so rapid successive taps produce a single write with no UI stutter. The Wi-Fi password is intentionally *not* stored — it must be re-entered when joining a new network.

---

## 14. Terrain Data Download

Terrain idle screen

SRTM elevation tiles are used on this version for **TAWS proximity alerting only** — they do not render a terrain background on the attitude indicator. (For terrain background rendering, use the Pi 4 version.)

Tiles are stored in `pi_zero/data/srtm/` as `.hgt` files (~1 MB each).

### Downloading a preset region

Terrain downloading

Nine preset regions. Each tile shows coverage, approximate tile count, and estimated disk size:

| Region | Coverage | ~Tiles | ~Size |
|---|---|---:|---:|
| US Southwest | AZ · NM · NV · UT · CO | 132 | 198 MB |
| US Pacific | CA · OR · WA | 187 | 280 MB |
| US Southeast | FL · GA · AL · NC · SC | 234 | 351 MB |
| US Northeast | NY · PA · NE states | 154 | 231 MB |
| US Midwest | OH · MI · IL · MN · WI | 276 | 414 MB |
| All CONUS | Lower 48 — single-tap | ~1,475 | ~2 GB |
| Alaska | Southern AK corridor | 306 | 459 MB |
| Europe West | UK · FR · DE · ES · IT | 528 | 792 MB |
| All Europe | UK to Turkey | ~1,050 | ~3 GB |

Tap the region button to start. Progress bar and tile count update during download. **CANCEL** aborts; already-downloaded tiles are kept. Re-tapping a region after a partial download resumes (existing tiles are skipped).

### Current area

**DOWNLOAD CURRENT AREA** at the top of the screen downloads a 5°×5° box (~25 tiles, ~35 MB) centred on the current GPS position — the fastest way to get alerting data for an unfamiliar area. Requires GPS fix.

### COMPACT — shrink SRTM1 to SRTM3

If you've copied full-resolution **SRTM1** tiles onto the Zero (e.g. rsynced from a Pi 4/5 that downloaded them), a **COMPACT** button appears in the status bar once SRTM1 tiles are present. Tap it to decimate every tile in place to **SRTM3** (1201², ~3 MB) — about **8.7×** smaller (a CONUS set drops ~3.7 GB → ~430 MB) at the ~90 m resolution the Zero's spot-check TAWS uses anyway. It rewrites each tile atomically (crash-safe), shows a progress bar, and the label flips to **COMPACTING…** (amber) while it runs. The Zero downloads SRTM3 directly, so you normally only need COMPACT after a hand-off of SRTM1 tiles from a Pi 4/5. (Command-line equivalent: `tools/compact_srtm.py` — see the README deploy recipe.)

### WiFi requirement

The Pi must be on an internet-reachable network to download. Switch to home WiFi via Connectivity, download here, then switch back to Pico W AP for flight.

---

## 15. Obstacle Data Download

Obstacle data screen — idle

FAA Digital Obstacle File adds tower, antenna, and wind-turbine symbols to the display. Obstacles within **10 nm** and **±2000 ft** are shown.

Tap **DOWNLOAD** to fetch from aeronav.faa.gov. Progress bar updates. After download, file is extracted and parsed automatically.

Once loaded, obstacles appear as coloured symbols:

| Symbol colour | Meaning |
|---|---|
| Red | Within **100 ft** below aircraft |
| Amber/yellow | Within **500 ft** below aircraft |
| White | Cleared by more than 500 ft |

Red dot above symbol = lit obstacle. FAA publishes new data every 28 days.

---

## 16. Airport Data Download

Airport data screen — loaded

The OurAirports.com global database adds airport and heliport symbols to the attitude indicator within 20 nm of the aircraft. About 72,000 airports worldwide.

### Symbols on the AI

| Symbol | Meaning |
|---|---|
| Cyan ring with dark centre | Public airport (small / medium / large) |
| Outer ring added | Medium or large public airport |
| Magenta "H" | Heliport |
| Cyan circle with wavy underscore | Seaplane base |
| Grey triangle | Balloonport |

Airport identifier (e.g. "KSEZ") shown within 15 nm as a small "road sign" — a coloured text box on a thin vertical post above the symbol, so the label rises clear of terrain. Beyond 15 nm only the symbol is drawn (declutter).

### Display filters

The AIRPORT DATA screen has four type filters and two overlay toggles:

| Filter | Controls | Default |
|---|---|---|
| **PUBLIC** | Small / medium / large public airports | On |
| **HELI** | Heliports | On |
| **WATER** | Seaplane bases | Off |
| **OTHER** | Balloonports + uncategorised | Off |
| **RUNWAYS** | Runway polygons (within 8 nm) | On |
| **EXT C/LINES** | Dashed extended centerlines (within 15 nm) | On |

Tap to toggle. Useful for decluttering on dense urban sectional overlay (e.g. disable HELI near cities) or turning off EXT C/LINES en-route.

All filter and toggle states persist across power cycles — the settings file is written atomically on a background thread to avoid flight-display stutters.

### Runways and extended centerlines

Runway approach — KSEZ RWY 03

Within 8 nm of an airport, a tan polygon is drawn for each runway, projected from the thresholds' lat/lon/elevation so runways translate, rotate, and scale naturally with aircraft position, bank and pitch. Runway width is taken from the OurAirports database.

Extended centerlines (dashed) project 10 nm outward from each threshold along the runway bearing, visible within 15 nm of the airport. At night, lit runways are distinguishable from unlit by the runway edge colour. The centerlines give an at-a-glance final-approach reference for visual approaches without requiring a flight plan.

Runway data comes from OurAirports `runways.csv` (~14,700 runways worldwide) and is downloaded alongside the airport CSV in a single UPDATE action.

**Published approaches (shared from a Pi 4/5).** The Pi Zero can't load an instrument approach itself, but when a Pi 4/5 on the cabin network loads one, the Zero **receives it over screen-sync** (KIND_APPR) and draws the approach as a cyan course line on the moving map; while it's active the approach's current leg drives the raw CDI. There are no HITS boxes or synthetic-vision approach cues on the Zero — those stay on the Pi 4/5.

### Downloading

Tap **AIRPORTS** on the System screen → **DOWNLOAD** to fetch `airports.csv` (~12 MB) plus `runways.csv` (~3 MB) from the OurAirports GitHub mirror.

Airport data screen — downloading

Progress bar + CANCEL work the same as the obstacle download. After download the CSV is parsed into a NumPy cache for fast future loads.

### Update schedule

Community-maintained, updated frequently. Local expiry: 60 days — then the `EXP APT` badge appears as a reminder. Data remains usable past expiry.

### WiFi requirement

The Pi Zero must be on an internet-reachable network to download. Switch to home Wi-Fi via Connectivity, download here, then switch back to Pico W AP for flight.

---

## 16A. Full-Screen MFD

The Pi Zero has a full-screen moving-map MFD in addition to the PFD.

Full-screen MFD — moving map with D2/FPL/OVLY chrome and the bottom data strip

- **Swap PFD ↔ MFD:** a **3-finger hold (~2 s)** (the 2-finger 0.8 s hold opens the setup menu — §8). The swap is gated by **ENABLE MFD** (§13); the unit boots to the PFD.
- **Chrome:** **D→** (direct-to) top-left, **FPL** top-right, the **TRK↑/N↑** orientation label, **OVLY** overlay cycle, the **RNG** label, **−/+** zoom buttons, and a **CTR** recenter button that appears when the map is panned. Drag the map to pan; tap **CTR** (or the own-ship chevron) to recenter.
- **Data strip:** a bottom row of **8 readout slots** (GS · TRK · ALT · WPT · BTW · DIST · ETE · ETA by default). Tap a slot to open the picker, then tap a field to assign it — the selection advances to the next slot so you can fill the row with successive taps. Persists in `data/settings.json`. Assignable fields: **GS** (groundspeed), **AS** (indicated airspeed), **TAS**, **TRK** (track), **HDG**, **ALT**, **AGL** (above terrain), **VS**, **WIND** (direction/speed, `DDD/SS`), **UTC**, **BARO**, **SAT**, and the nav-derived **WPT · BTW · DTK · DIST · DISTD · XTE · ETE · ETED · ETA · ETAD**. The nav fields render magenta and show `--` until a Direct-To or flight-plan leg is active; the `…D` fields are to the **final destination** (whole route) versus the plain fields to the active waypoint. **ETA / ETAD show local time by default** (`HH:MM`) or Zulu (`HH:MMZ`) per an **ARRIVAL TIME (LOCAL / ZULU)** toggle in the picker.

MFD data-field picker — eight slot pills across the top (selected WPT ringed cyan) over the assignable-field grid; nav-derived fields tagged "needs D2" in magenta

The picker shows the eight slot pills across the top (the one being edited is ringed cyan) above a grid of assignable fields; nav-derived fields are tagged **needs D2** in magenta because they read `--` until a Direct-To or flight-plan leg is active. An **ARRIVAL TIME** toggle (**LOCAL / ZULU**, default LOCAL) flips every ETA / ETAD readout between the destination's local time and Zulu.

The map's **MAP LAYERS** (§10) and the **winds (WND)** overlay (§10) render here, plus the weather and traffic overlays below.

### Orientation and range

Full-screen MFD in TRACK-UP orientation at 40 NM — the orientation label toggles N↑ / TRK↑

Tap the **N↑ / TRK↑** label to switch between north-up and track-up orientation. The **RNG** label and **−/+** buttons step the map range.

Full-screen MFD zoomed out to 160 NM, showing the wider extent

### Airspace overlay (ASP)

Full-screen MFD with the ASP airspace overlay — a magenta Class C ring "PRESCOTT 45/SFC" and a blue Class D ring around KSEZ over the moving map

The **ASP** stop in the **OVLY** cycle draws airspace boundaries on the moving map: Class C as a magenta ring (labelled with its ceiling/floor, e.g. `PRESCOTT 45/SFC`), Class D as a blue ring. Which classes render is set on the airspace-class toggles (§16D); the ASP overlay is the master on/off. Requires the airspace data set to be downloaded (§16D).

### Flight plan (multi-waypoint)

Flight-plan editor — ordered waypoint list KPRC → KSEZ → KFLG with the KSEZ leg active (green highlight, ● ACTIVE badge, magenta ident), + ICAO / + LAT/LON / + USER buttons, SAVE / REVERSE / LOAD row, DEACTIVATE, and per-row ↑ / ↓ / ✕ controls

Tap **FPL** on the MFD to open the flight-plan editor. Build an ordered list with **+ ICAO**, **+ LAT/LON**, or **+ USER**; reorder or remove rows with the per-row **↑ / ↓ / ✕** buttons. Tapping a row activates that leg as the direct-to (green highlight, **● ACTIVE** badge, magenta ident); the plan auto-sequences to the next leg as you pass each waypoint. **DEACTIVATE** clears the active leg. **REVERSE** (on the SAVE / REVERSE / LOAD row) flips the whole route end-for-end — A→…→Z becomes Z→…→A — to fly the return trip; it needs at least two waypoints and deactivates the active leg, and the reversed order syncs to the other displays.

### Saving and loading plans

Load-plan picker — saved named plans "RIM TOUR" and "SEDONA LOOP" with leg count and first→last idents, each with LOAD / DEL buttons

**SAVE** on the flight-plan page stores the current list under a typed name; **LOAD** opens the picker, which lists each saved plan with its leg count and first→last idents and **LOAD / DEL** buttons. Plans persist across power cycles and sync to other displays when **SHARE FPL** is on (§12).

### Custom waypoints

Add user waypoint — IDENT / LAT / LON fields (FISH, 34.523, -111.812) with CANCEL / SAVE

**+ LAT/LON** on the flight-plan page opens the **ADD USER WAYPOINT** screen — enter an **IDENT** and **LAT / LON**, then **SAVE** to add it to the plan. Points created this way are auto-saved to the user-waypoint library for reuse.

User waypoints library — saved user points FISH / RDV1 / CAMP with their lat/lon and ADD / DEL buttons

The **USER WAYPOINTS** library lists every saved user point with its lat/lon; **ADD** inserts it into the current plan and **DEL** removes it from the library.
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

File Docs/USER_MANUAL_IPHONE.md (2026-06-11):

# AHRS PFD — iPhone / Browser Pilot's User Manual

**Software version 0.2 · Hardware: Raspberry Pi Pico W AHRS unit · Display: any iPhone / Android / tablet browser**

*No dedicated display — any smartphone, tablet, or laptop on the Pico W AP becomes the PFD. HTML5 Canvas rendering, SSE-driven at ~20 Hz.*

> This manual covers the iPhone / browser version. For the dedicated Pi Zero 2W display see `USER_MANUAL_ZERO.md`; for the Pi 4 SVT display see `USER_MANUAL_PI4.md`.

---

## Contents

1. [What It Is](#1-what-it-is)
2. [Connecting](#2-connecting)
3. [Screen Overview](#3-screen-overview)
4. [Attitude Indicator](#4-attitude-indicator)
5. [Airspeed Tape](#5-airspeed-tape)
6. [Altitude Tape and VSI](#6-altitude-tape-and-vsi)
7. [Heading Tape](#7-heading-tape)
8. [Slip / Skid Bar](#8-slip--skid-bar)
9. [Badges and Status](#9-badges-and-status)
10. [Baro Setting (QNH)](#10-baro-setting-qnh)
11. [AHRS Trim](#11-ahrs-trim)
12. [Terrain Download](#12-terrain-download)
13. [TAWS Proximity Alerts](#13-taws-proximity-alerts)
14. [Phone Sensor Fallback](#14-phone-sensor-fallback)
15. [Demo Mode](#15-demo-mode)
16. [Feature Differences vs Pi 4 / Pi Zero](#16-feature-differences-vs-pi-4--pi-zero)

---

## 1. What It Is

The iPhone display is the **original** PFD for this project and still the simplest way to get flying: with only a Pico W AHRS unit you can use any phone, tablet, or laptop as the display. No dedicated hardware, no dedicated display, no install — just join the `AHRS-Link` Wi-Fi and open a browser.

Everything you see is rendered by the phone's browser from a single HTML file (`iphone_display/index.html`) served by the Pico W itself. The Pico streams live AHRS / GPS / baro state over Server-Sent Events (SSE) at ~20 Hz; the browser redraws the PFD at up to 60 fps with smoothing in between.

Level cruise — southbound over the Swiss Alps

## 2. Connecting

There are three ways to launch the iPhone PFD:

### 2.1  With the Pico W AHRS (primary — full-fidelity live data)

1. Power the Pico W AHRS unit.
2. After ~5 s, a Wi-Fi AP named **`AHRS-Link`** appears. Join it with your phone. DHCP assigns you an address on `192.168.4.x`.
3. Open `http://192.168.4.1` in Safari / Chrome / Firefox. The PFD fills the screen and starts drawing the moment the first SSE frame arrives.
4. **Add to Home Screen** (Safari → Share → Add to Home Screen) so it launches fullscreen without the address bar. The `apple-mobile-web-app-capable` metadata and safe-area-insets are in place — the PFD runs edge-to-edge on iPhones with a notch or Dynamic Island.

Rotate the phone to **landscape**, dim the screen for night flying, and you have a three-axis PFD with no extra hardware.
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

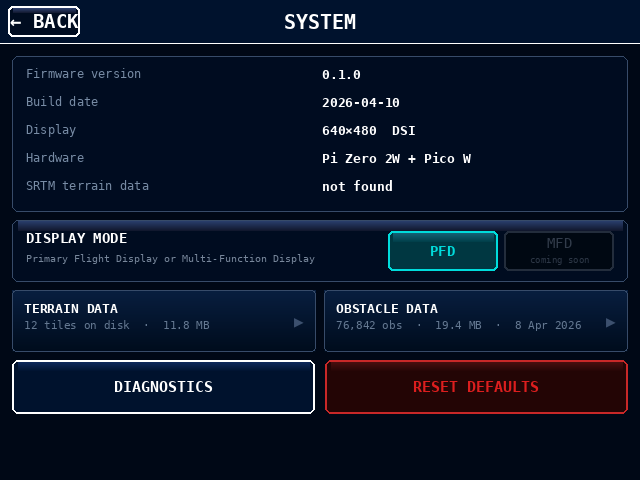
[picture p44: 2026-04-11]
tools/preview_setup_system.png

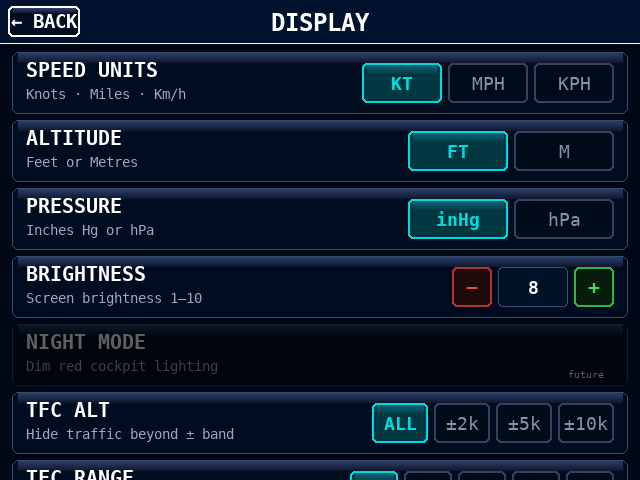
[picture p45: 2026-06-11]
pi_zero/previews/preview_setup_display.png

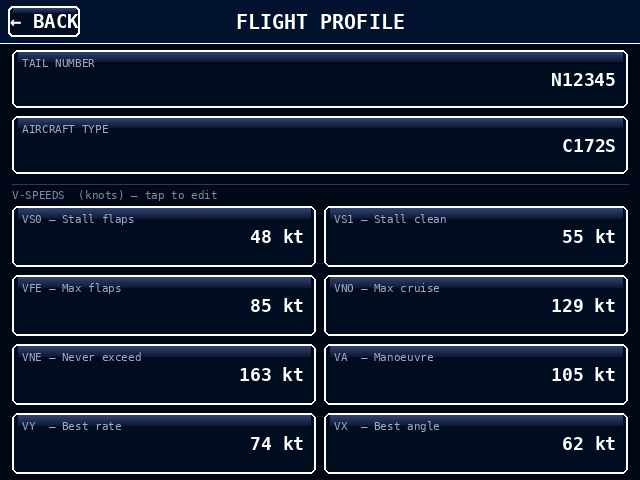
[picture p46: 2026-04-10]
tools/preview_setup_flight_profile.png

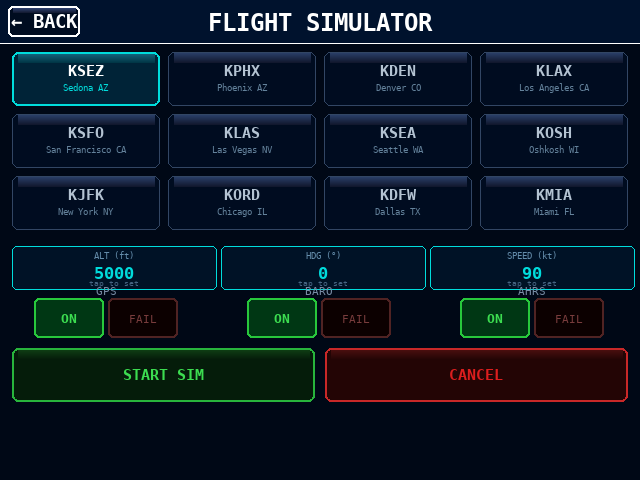
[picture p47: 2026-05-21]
pi_zero/previews/preview_sim_setup.png

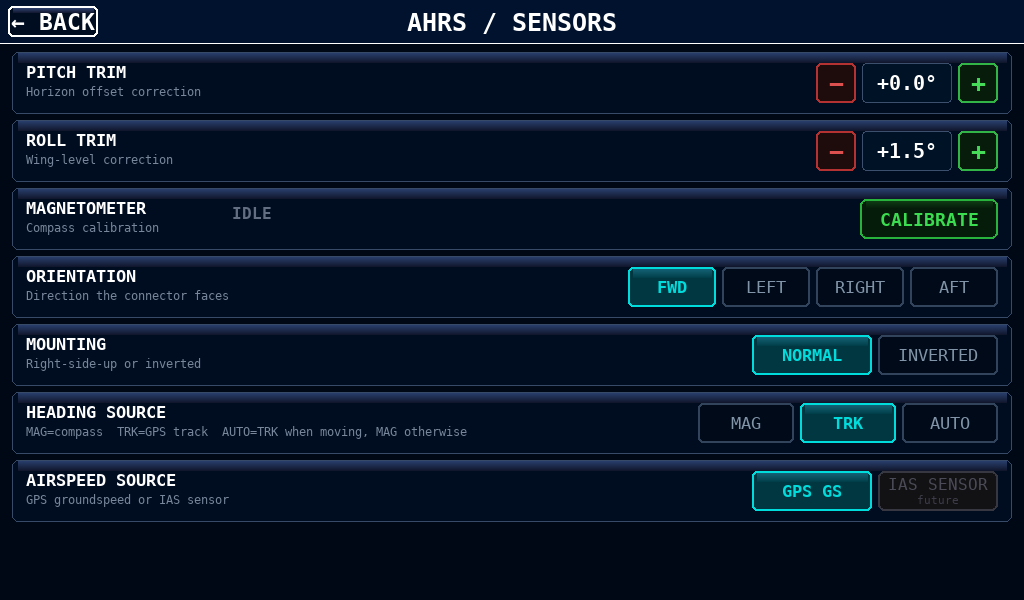
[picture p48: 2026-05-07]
pi4/previews/preview_setup_ahrs_gpstrk.png

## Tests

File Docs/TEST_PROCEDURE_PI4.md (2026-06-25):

# Pi 4 Display Unit — Bench Test Procedure

| Field | Value |
|---|---|
| Document No. | TP-PI4-001 |
| Title | Initial Hardware Bring-Up — Pi 4 Display + AHRS Unit |
| Project | Pico-AHRS / PFD |
| Date | 2026-05-09 |
| Version | 0.3 |
| Performed by | _____________ |
| Date performed | _____________ |

---

## Equipment Required

- Raspberry Pi 4 (2 GB RAM minimum) with a 1024×600 display (e.g. ROADOM 7" IPS HDMI + USB touch) — or a Waveshare 3.5" 640×480 DPI panel with `DISPLAY_PROFILE = "waveshare_35"` in `pi4/config.py`
- Pico W AHRS unit (ICM-42688-P or WT901, BME280, u-blox GPS module)
- 5 V / 3 A USB-C power supply for Pi 4; 5 V / 2 A for Pico W
- USB keyboard (for initial startup commands)
- Smartphone or laptop (for Pico W AP validation and internet-tethered downloads)
- Level surface (bench or table)
- GitHub branch: `claude/split-display-versions-YJ9h8`

**Pass/Fail legend:**  ✓ Pass   ✗ Fail   N/T Not tested   N/A Not applicable

---

## Phase 1 — Display Unit (standalone, no AHRS)

### 1.1 Power-On and Boot

| Step | Action | Expected Result | Result | Notes |
|---|---|---|---|---|
| 1.1.1 | Apply 5 V / 3 A to Pi 4 | Green power LED illuminates; HDMI (or DPI) display powers up | | |
| 1.1.2 | Observe display panel | Backlight or video signal within 10 s; no "no signal" banner once fully booted | | |
| 1.1.3 | Wait for console prompt | OS boot completes without kernel panic; `/boot/firmware/config.txt` has the HDMI force-hotplug + resolution overrides applied by `pi4/setup.sh` | | |
| 1.1.4 | Verify `config.py` DISPLAY_PROFILE | Matches the connected panel (`roadom_7` for 1024×600; `waveshare_35` for 640×480) | | |

### 1.2 First Launch — Demo Mode

| Step | Action | Expected Result | Result | Notes |
|---|---|---|---|---|
| 1.2.1 | Run `python3 pi4/pfd.py --demo` | PFD fills screen within 3 s; frame rate is visibly smooth (target 30 fps) | | |
| 1.2.2 | Observe top strip | `NO LINK` badge present (no AHRS connected — expected) | | |
| 1.2.3 | Observe AI | Blue sky / brown ground horizon visible | | |
| 1.2.4 | Observe AI animation | Horizon animates through scripted demo scenarios | | |
| 1.2.5 | Observe airspeed tape | Speed value scrolls; V-speed arcs visible | | |
| 1.2.6 | Observe altitude tape | Altitude scrolls; VSI bar deflects on climb/descent | | |
| 1.2.7 | Observe heading tape | Heading tape scrolls; bug marker visible | | |
| 1.2.8 | Observe heading box (centre bottom) | "133°" with `M` subscript; heading box white border | | |
| 1.2.9 | Observe speed bug box (top-left) | Magenta border and text — GPS GS source | | |
| 1.2.10 | Observe alt bug box (top-right) | Magenta border — GPS ALT (demo has no baro) | | |
| 1.2.11 | Observe baro button (bottom-right) | Magenta `GPS ALT` label | | |
| 1.2.12 | Observe HDG bug button (bottom-left) | Cyan border — MAG mode | | |
| 1.2.13 | Observe `DEMO` watermark | Red `DEMO` text visible at centre AI | | |

### 1.3 Touch — Setup Menu Access

| Step | Action | Expected Result | Result | Notes |
|---|---|---|---|---|
| 1.3.1 | Place two fingers on screen and hold 0.8 s | Setup menu appears with 6 tiles: FLIGHT PROFILE, DISPLAY, AHRS / SENSORS, CONNECTIVITY, SYSTEM, EXIT | | |
| 1.3.2 | Tap **EXIT** tile | Returns to PFD | | |
| 1.3.3 | Re-enter setup; tap **DISPLAY** | Display settings screen opens | | |
| 1.3.4 | Observe **BACK** button in header | "← BACK" text fits cleanly inside the button outline with no overflow (regression check — the button auto-scales with FONT_SCALE so the label never clips on 1024×600) | | |
| 1.3.5 | Tap **+** brightness button | Backlight brightens one step if panel supports PWM (ROADOM HDMI panels have no software backlight — brightness value changes but physical output may not) | | |
| 1.3.6 | Tap **−** brightness button | Value decreases | | |
| 1.3.7 | Tap **BACK** | Returns to setup menu | | |
| 1.3.8 | Tap **FLIGHT PROFILE** | V-speeds screen opens with VS0/VS1/VFE/VNO/VNE + tail/actype fields | | |
| 1.3.9 | Tap **BACK**; tap **CONNECTIVITY** | Connectivity screen opens; current SSID + AHRS link status visible | | |
| 1.3.10 | Tap **BACK**; tap **SYSTEM** | System screen opens with version, TERRAIN / OBSTACLES / AIRPORTS data tiles, FLIGHT SIMULATOR, RESET DEFAULTS | | |

### 1.4 Touch — Bug Setting

| Step | Action | Expected Result | Result | Notes |
|---|---|---|---|---|
| 1.4.1 | Tap alt bug box (top-right of alt tape) | Numpad overlay appears, title "SET ALTITUDE BUG (×100 ft)"; current value shown as dim `Current: <n>` placeholder below the empty entry line | | |
| 1.4.2 | Tap **ENTER** without typing | Numpad closes; alt bug value unchanged (placeholder-not-pre-populated UX check) | | |
| 1.4.3 | Re-open numpad; type `85` then tap **ENTER** | Numpad closes; alt bug readout shows `8500`; bug chevron moves to 8500 ft | | |
| 1.4.4 | Re-open numpad; type `9` then tap **⌫** (backspace) | Buffer empties one digit at a time — numpad still open | | |
| 1.4.5 | Tap HDG bug box (bottom-left of heading strip) | Numpad overlay appears, title "SET HDG BUG"; full heading-strip-height hit region (regression check) | | |
| 1.4.6 | Type `270` then tap **ENTER** | HDG bug readout shows `270°`; bug chevron moves on tape | | |
| 1.4.7 | Tap speed bug box (top of speed tape) | Numpad overlay appears, title "SET SPD BUG" | | |
| 1.4.8 | Type `90` then tap **ENTER** | Speed bug readout shows `90`; bug chevron visible on tape | | |
| 1.4.9 | Tap baro box (bottom-right of heading strip) | Numpad title "SET BARO inHg" or "SET BARO hPa" matching Display Settings unit | | |
| 1.4.10 | Tap anywhere on heading tape | HDG bug jumps to tapped heading | | |
| 1.4.11 | Tap anywhere on altitude tape | Alt bug jumps to nearest 100 ft | | |

### 1.4.5 Touch — Keyboard Entry

| Step | Action | Expected Result | Result | Notes |
|---|---|---|---|---|
| 1.4.5.1 | Open Flight Profile; tap **CALLSIGN** | Keyboard overlay appears; current tail shown as placeholder, buffer empty | | |
| 1.4.5.2 | Verify row 4 contents | `Z X C V B N M . : ⌫` — period, colon, and backspace must all be present | | |
| 1.4.5.3 | Type `N` then `.` then `1` | Buffer accepts period character (regression check) | | |
| 1.4.5.4 | Tap **⌫** three times | Three chars removed from buffer end | | |
| 1.4.5.5 | Tap **CANCEL** | Keyboard closes; callsign unchanged | | |
| 1.4.5.6 | Connectivity → tap AHRS URL | Keyboard opens pre-populated with current URL (`http://192.168.4.1` by default) | | |
| 1.4.5.7 | Confirm `:` key enters colon | Buffer accepts colon — needed for URLs | | |

### 1.5 Touch — AHRS / Sensors Screen

| Step | Action | Expected Result | Result | Notes |
|---|---|---|---|---|
| 1.5.1 | Enter setup; tap **AHRS / SENSORS** | AHRS setup screen opens | | |
| 1.5.2 | Observe Row 1 (PITCH TRIM) | `−` and `+` buttons present; current value `+0.0°` | | |
| 1.5.3 | Tap `+` pitch trim button | Value increments by 0.5° | | |
| 1.5.4 | Tap `−` pitch trim button | Value decrements back to 0.0° | | |
| 1.5.5 | Observe Row 4 (HEADING SOURCE) | **MAG** button active (cyan), **GPS TRK** available | | |
| 1.5.6 | Tap **GPS TRK** | Button highlights; return to PFD | | |
| 1.5.7 | Observe heading box | Border turns magenta; `G` subscript appears | | |
| 1.5.8 | Observe HDG bug button | Border turns magenta | | |
| 1.5.9 | Return to AHRS setup; tap **MAG** | Heading box returns to white border; `M` subscript | | |
| 1.5.10 | Observe Row 5 (AIRSPEED SOURCE) | **GPS GS** button active; **IAS SENSOR** greyed out | | |

### 1.6 Flight Simulator

| Step | Action | Expected Result | Result | Notes |
|---|---|---|---|---|
| 1.6.1 | Enter setup; tap **SYSTEM** | System screen opens | | |
| 1.6.2 | Tap **FLIGHT SIMULATOR** tile | Simulator setup screen opens with airport grid | | |
| 1.6.3 | Confirm 12 airport presets visible | KSEZ, KPHX, KDEN, KLAX, KSFO, KLAS, KSEA, KOSH, KJFK, KORD, KDFW, KMIA | | |
| 1.6.4 | Tap **KSEZ** (Sedona AZ) | Preset highlights cyan | | |
| 1.6.5 | Tap **START** | PFD returns; `SIM` watermark visible at AI centre | | |
| 1.6.6 | Observe aircraft behaviour | Speed, altitude, heading hold set values | | |
| 1.6.7 | Set alt bug to `9500` | Aircraft climbs toward 9500 ft | | |
| 1.6.8 | Set HDG bug to `270` | Aircraft turns to 270° | | |
| 1.6.9 | Tap `SIM` watermark | SIM controls overlay appears | | |
| 1.6.10 | Tap **BARO → FAIL** | Alt bug/box/tape turn magenta; `GPS ALT` badge appears | | |
| 1.6.11 | Tap **BARO → ON** | Alt bug/box return to cyan; badge clears | | |
| 1.6.12 | Tap **GPS → FAIL** | `NO GPS` badge appears; speed tape shows `---` | | |
| 1.6.13 | Tap **GPS → ON** | Speed recovers; badge clears | | |
| 1.6.14 | Tap **AHRS → FAIL** | `AHRS FAIL` badge appears; horizon freezes | | |
| 1.6.15 | Tap **AHRS → ON** | Horizon resumes | | |
| 1.6.16 | Tap **EXIT SIM** | Simulator stops; watermark clears | | |

---

## Phase 2 — AHRS Unit (standalone)

### 2.1 Pico W Power-On

| Step | Action | Expected Result | Result | Notes |
|---|---|---|---|---|
| 2.1.1 | Apply 5 V to Pico W AHRS unit | Pico W power LED illuminates | | |
| 2.1.2 | Wait 5 s | Pico W WiFi AP `AHRS-Link` visible on a phone/laptop | | |
| 2.1.3 | Connect a device to `AHRS-Link` | DHCP address assigned (typically `192.168.4.x`) | | |
| 2.1.4 | Open browser to `http://192.168.4.1` | JSON or SSE stream response visible | | |
| 2.1.5 | Observe SSE event format | Events contain `pitch`, `roll`, `yaw`, `alt`, `speed` fields | | |
| 2.1.6 | Tilt the AHRS unit ~30° | `roll` value in stream changes correspondingly | | |
| 2.1.7 | Pitch the AHRS unit ~15° nose-up | `pitch` value increases | | |

### 2.2 BME280 Barometric Sensor

| Step | Action | Expected Result | Result | Notes |
|---|---|---|---|---|
| 2.2.1 | Observe SSE stream `baro_src` field | Value is `bme280` (not `gps`) | | |
| 2.2.2 | Observe `baro_hpa` field | Value is within ±5 hPa of local altimeter setting | | |
| 2.2.3 | Observe `alt` field | Pressure altitude within ±50 ft of field elevation | | |

### 2.3 GPS Module

| Step | Action | Expected Result | Result | Notes |
|---|---|---|---|---|
| 2.3.1 | Place unit near window or outside | GPS acquiring — `sats` field > 0 within 2 min | | |
| 2.3.2 | Wait for fix | `fix` field = 1; `sats` ≥ 4 | | |
| 2.3.3 | Observe `lat` / `lon` fields | Values match known position within ~50 m | | |
| 2.3.4 | Observe `speed` field | Near-zero when stationary | | |

---

## Phase 3 — Integrated System

### 3.1 Link Establishment

| Step | Action | Expected Result | Result | Notes |
|---|---|---|---|---|
| 3.1.1 | Start AHRS unit; confirm AP `AHRS-Link` is visible | AP broadcasting | | |
| 3.1.2 | Configure Pi Zero 2W WiFi to join `AHRS-Link` (via Connectivity screen) | Pi associates | | |
| 3.1.3 | Launch `python3 pi4/pfd.py` (no --demo) | PFD starts | | |
| 3.1.4 | Observe top strip within 5 s | `NO LINK` badge clears | | |
| 3.1.5 | Observe baro button (bottom-right) | Shows `29.92 IN` in cyan (not `GPS ALT`) | | |
| 3.1.6 | Observe alt bug box (top-right) | Cyan border | | |
| 3.1.7 | Observe speed bug box (top-left) | Magenta border — GPS GS | | |

### 3.2 Attitude Response

| Step | Action | Expected Result | Result | Notes |
|---|---|---|---|---|
| 3.2.1 | Hold AHRS unit level | AI horizon centred; slip bar centred under zero-bank doghouse | | |
| 3.2.2 | Roll AHRS unit ~30° right | AI rolls right; bank pointer deflects right | | |
| 3.2.3 | Roll AHRS unit ~30° left | AI rolls left | | |
| 3.2.4 | Pitch AHRS unit ~10° nose-up | Horizon bar drops; pitch ladder moves down | | |
| 3.2.5 | Pitch AHRS unit ~10° nose-down | Horizon bar rises | | |
| 3.2.6 | Rotate AHRS unit slowly in yaw | Heading tape scrolls in correct direction | | |
| 3.2.7 | Observe attitude response lag | Horizon responds within 1–2 frames of movement (≤ 100 ms) | | |

### 3.3 Horizon Trim (if needed)

| Step | Action | Expected Result | Result | Notes |
|---|---|---|---|---|
| 3.3.1 | Place AHRS unit on a known-level surface | | | |
| 3.3.2 | Observe AI horizon position | Horizon bar aligned with aircraft symbol | | |
| 3.3.3 | If horizon is high/low: enter setup → AHRS / SENSORS → PITCH TRIM | Adjust in 0.5° steps until aligned | | |
| 3.3.4 | If horizon is tilted: ROLL TRIM | Adjust until wings-level | | |
| 3.3.5 | Confirm trim holds across power cycles | Re-launch pfd.py; horizon remains corrected | | |

### 3.4 GPS Integration

| Step | Action | Expected Result | Result | Notes |
|---|---|---|---|---|
| 3.4.1 | With GPS fix acquired: observe track pointer | **Magenta** tick on heading tape shows GPS ground track (suppressed if track ≈ hdg within 1°) | | |
| 3.4.2 | Observe top strip | No `GPS` badge (fix is valid) | | |
| 3.4.3 | Enable GPS TRK mode in AHRS / SENSORS | Heading box border turns magenta; `G` subscript | | |
| 3.4.4 | Rotate AHRS unit slowly | Heading follows GPS track via complementary filter | | |
| 3.4.5 | Return to MAG mode | Heading box returns to white; `M` subscript | | |

### 3.5 Link Loss and Recovery

| Step | Action | Expected Result | Result | Notes |
|---|---|---|---|---|
| 3.5.1 | With link active: power off AHRS unit | After 3 s: `NO LINK` badge appears | | |
| 3.5.2 | Observe tapes | Values freeze at last received value | | |
| 3.5.3 | Power AHRS unit back on | Within 5 s: `NO LINK` badge clears; tapes resume | | |

### 3.6 Connectivity Screen Diagnostics

| Step | Action | Expected Result | Result | Notes |
|---|---|---|---|---|
| 3.6.1 | Setup → **CONNECTIVITY** with link up | STATUS row: AHRS green "CONNECTED"; WiFi green "WiFi: `<ssid>`" showing the actual network name the Pi is associated to (not the AHRS URL) | | |
| 3.6.2 | Observe AHRS LINK row | Subtitle shows transport + port (`USB /dev/ttyACM0` if Pico is USB-connected, otherwise `WIFI http://192.168.4.1`) | | |
| 3.6.3 | Observe RX: counter | Increments ~20×/s while link is healthy | | |
| 3.6.4 | Observe live R / P / Y / ALT on right-hand side | Values match the current AHRS readings; tilt the AHRS unit and confirm R and P change here as on the main PFD | | |
| 3.6.5 | Power off AHRS unit for 5 s then back on | RX counter pauses, then resumes; ERR may tick up once; last error string may briefly show | | |
| 3.6.6 | Disconnect WT901 TX line, reconnect | RX still increments (firmware alive) but R/P/Y freeze at last values — confirms the diagnostic catches "transport OK, sensor dead" | | |
| 3.6.7 | Tap **TEST AHRS** | Blue status message appears below the buttons — success or specific error | | |

---

## Phase 4 — Baro Setting Verification

| Step | Action | Expected Result | Result | Notes |
|---|---|---|---|---|
| 4.1 | Obtain current local altimeter setting (ASOS/ATIS) | Record value: __________ inHg | | |
| 4.2 | Tap baro button (bottom-right) | Numpad opens with current hPa value | | |
| 4.3 | Enter correct inHg value (e.g. `2992` for 29.92) | Baro button updates; altitude corrects | | |
| 4.4 | Verify indicated altitude | Within ±75 ft of field elevation at known location | | |
| 4.5 | Switch baro unit to hPa in Display Settings | Baro button shows hPa value | | |
| 4.6 | Tap baro button and enter hPa value | Altitude unchanged; unit label updates | | |

---

## Phase 5 — Data Downloads

Requires Pi to be on an internet-reachable WiFi (use `sudo bash wifi_switch.sh home`, or configure a home SSID via Connectivity setup).

### 5.1 Terrain Data (SRTM tiles — powers TAWS + SVT mesh)

| Step | Action | Expected Result | Result | Notes |
|---|---|---|---|---|
| 5.1.1 | Setup → System → **TERRAIN** | Terrain data screen opens; idle state if no tiles present | | |
| 5.1.2 | Observe region grid | Nine preset region tiles visible: US Southwest, US Pacific, US Southeast, US Northeast, US Midwest, All CONUS, Alaska, Europe West, All Europe. Each shows tile count + size estimate | | |
| 5.1.3 | Observe top tile | **DOWNLOAD CURRENT AREA** tile shows `~25 tiles around <lat>°N <lon>°W  ≈ 35 MB` (actual counts vary with latitude) | | |
| 5.1.4 | Tap preset region **US Southwest** | Download starts immediately (no separate DOWNLOAD button); progress strip appears at top | | |
| 5.1.5 | Observe progress | Per-tile status updates; current-of-total counter advances | | |
| 5.1.6 | Tap **CANCEL** mid-download | Download halts; already-downloaded tiles retained on disk | | |
| 5.1.7 | Tap same region again | Download resumes — already-present tiles are skipped, only missing ones fetch | | |
| 5.1.8 | Wait for completion | Done ✓ message; disk tile count + MB updates at top of screen | | |
| 5.1.9 | Return to PFD, observe status badges | `NO TER` badge clears | | |
| 5.1.10 | If on Pico W AP (no internet): tap any region | "WiFi (home network) required" guard message appears | | |

### 5.2 Obstacle Data (FAA DOF)

| Step | Action | Expected Result | Result | Notes |
|---|---|---|---|---|
| 5.2.1 | Setup → System → **OBSTACLES** | Obstacle data screen opens | | |
| 5.2.2 | Tap **DOWNLOAD** | Progress bar runs; ~20 MB CSV downloads then parses | | |
| 5.2.3 | Wait for completion | "Done ✓  ~76,000 obstacles loaded" | | |
| 5.2.4 | Return to PFD | `NO OBS` badge clears | | |

### 5.3 Airport + Runway Data (OurAirports)

| Step | Action | Expected Result | Result | Notes |
|---|---|---|---|---|
| 5.3.1 | Setup → System → **AIRPORTS** | Airport data screen opens | | |
| 5.3.2 | Tap **DOWNLOAD** (or **UPDATE** if present) | Progress bar runs; airports.csv (~12 MB) then runways.csv (~3 MB) download | | |
| 5.3.3 | Wait for completion | "Done ✓  72,007 airports, 14,727 runways" (counts may vary by data version) | | |
| 5.3.4 | Observe screen footer | Two-row toggle panel: PUBLIC / HELIPORTS / SEAPLANE / OTHER on row 1; RUNWAYS / EXT CENTERLINES on row 2 | | |
| 5.3.5 | Return to PFD | `NO APT` badge clears | | |

---

## Phase 5.5 — OpenGL Synthetic Vision Terrain (Pi 4 only)

Requires SRTM tiles loaded (Phase 5.1 complete). Use `pi4/pfd.py --demo --sim` or the flight simulator (KSEZ preset) for repeatable scenes.

| Step | Action | Expected Result | Result | Notes |
|---|---|---|---|---|
| 5.5.1 | Observe PFD startup console | Lines showing `SVT_RENDERER: opengl` and `GL_AVAILABLE: True`; no fallback-to-pygame message | | |
| 5.5.2 | Observe AI background at KSEZ at 6500 ft | 3D terrain mesh visible, not a flat blue/brown split — mesas + Mogollon Rim recognisable | | |
| 5.5.3 | Descend to 5500 ft near Sedona | Mountain peaks rise **above the horizon line** as they exceed aircraft altitude (this is the defining Pi 4 capability) | | |
| 5.5.4 | Observe terrain shading | Sun-angle shading creates distinct bright/dark slopes; ridges and valleys readable | | |
| 5.5.5 | Observe distance grid | Cyan grid on terrain: 0.5 nm minor + 2 nm major lines; fades toward mesh edge | | |
| 5.5.6 | Fly into rising terrain | Terrain colour banding shifts: brown (1000+ ft clear) → amber (100–500 ft) → orange (0–100 ft) → red (above aircraft) | | |
| 5.5.7 | Observe zero-pitch reference line | Short cyan hash marks across AI, always at aircraft 0° pitch regardless of terrain altitude | | |
| 5.5.8 | Roll sim 30° | Terrain mesh rolls with horizon; grid remains screen-aligned to terrain | | |
| 5.5.9 | Delete or rename `pi4/data/srtm` directory; relaunch | SVT falls back to blue/brown split; `NO TER` badge appears | | |
| 5.5.10 | Restore SRTM directory; relaunch | Terrain mesh returns | | |
| 5.5.11 | Observe sustained frame rate during continuous demo | 30 fps target; no visible stutter on ROADOM 1024×600 panel | | |

---

## Phase 5.6 — Veeder-Root Drum Cascade

These checks verify the rolling-drum regressions fixed during software v0.2 development (speed `1` at 100 kt, altitude `1` at 10000 ft, airspeed ones-drum "1 above 0" visibility). Runs in the flight simulator using the preview generator states.

| Step | Action | Expected Result | Result | Notes |
|---|---|---|---|---|
| 5.6.1 | Sim at 99 kt, continue accelerating | Airspeed drum at 99 shows "0" and "9" stacked; a faint "1" is visible ABOVE the "0" before the crossing to 100 (d_hi2 preview slot) | | |
| 5.6.2 | Continue through 100 kt | Tens digit cascades from "9" to "0"; leading "1" column emerges smoothly; no blank slot | | |
| 5.6.3 | Sim at 9980 ft, climb at 500 fpm | Altitude drum shows "99" and "80" stacked; leading column reveals "1" peeking above the "99" before the crossing to 10000 | | |
| 5.6.4 | Continue through 10000 ft | Leading column cascades 9→0; new "1" column appears; tens row advances to "00" — no "0000" flash or missing-digit visual defect | | |
| 5.6.5 | Sim descends from 100 ft to 90 ft | Airspeed/altitude drums narrow from three cells to two without snapping (the two-drum path is entered at `alt_inner ≥ 99.5`, not at integer 100, so the transition is smooth) | | |

---

## Phase 6 — Attitude Indicator Overlays

All overlays presume Phase 5 downloads completed. Run in demo or simulator mode.

### 6.1 Airport Symbols + Road-Sign Labels

| Step | Action | Expected Result | Result | Notes |
|---|---|---|---|---|
| 6.1.1 | Sim at KSEZ, alt 6000 ft, heading 200° | Cyan-ring airport symbol visible for KSEZ in lower AI | | |
| 6.1.2 | Observe near KSEZ | Magenta "H" symbols for nearby heliports (e.g. 4BAZ) | | |
| 6.1.3 | Observe airport label rendering | Ident ("KSEZ") rendered as small box on short vertical post within 15 nm | | |
| 6.1.4 | Open AIRPORT DATA; tap **HELIPORTS** to toggle OFF | H symbols disappear from AI | | |
| 6.1.5 | Tap **HELIPORTS** again | Heliports reappear | | |
| 6.1.6 | Toggle all four type filters OFF | No airport symbols rendered (sanity check) | | |
| 6.1.7 | Re-enable PUBLIC + HELIPORTS | Symbols restored | | |

### 6.2 Runway Polygons + Extended Centerlines

| Step | Action | Expected Result | Result | Notes |
|---|---|---|---|---|
| 6.2.1 | Sim at KSEZ, set alt 5500, heading 033°, position 2 NM SW of RWY 03 threshold | Two tan runway polygons visible below horizon near airport symbol, rendered on top of the SVT mesh | | |
| 6.2.2 | Observe extended centerlines | Dashed white lines extending 10 nm from each threshold along runway axis, visible within 15 nm | | |
| 6.2.3 | Airport Data → toggle **RUNWAYS** OFF | Polygons disappear; centerlines remain | | |
| 6.2.4 | Toggle **EXT CENTERLINES** OFF (RUNWAYS still off) | Centerlines disappear | | |
| 6.2.5 | Re-enable both | Polygons + centerlines restored | | |
| 6.2.6 | Roll simulator ±30° | Runway polygons rotate correctly with horizon; no "phantom" horizontal streaks across the AI (regression check) | | |
| 6.2.7 | Z-order check | Cyan airport ring at runway intersection sits on **top** of the runway asphalt | | |

### 6.3 Obstacle Symbols

| Step | Action | Expected Result | Result | Notes |
|---|---|---|---|---|
| 6.3.1 | Position sim with known tower in view | Caret-shape obstacle symbol visible on AI, anchored to terrain | | |
| 6.3.2 | Observe colour coding | Red = above aircraft alt; Yellow = within 500 ft below; White = more than 500 ft below | | |
| 6.3.3 | Observe lit indicator | Star (★) above caret for lit towers; plain caret for unlit | | |

### 6.4 TAWS Proximity Alerts

| Step | Action | Expected Result | Result | Notes |
|---|---|---|---|---|
| 6.4.1 | Descend sim toward rising terrain (e.g. Mogollon Rim north of KSEZ) | Amber `TERRAIN` caution banner appears at ~500 ft clearance; SVT terrain colour band shifts to amber simultaneously | | |
| 6.4.2 | Continue descent | Red `PULL UP` warning banner appears at ~100 ft clearance; terrain colour bands to orange/red | | |
| 6.4.3 | Climb away from terrain | Banners clear; terrain colours return to brown | | |

---
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

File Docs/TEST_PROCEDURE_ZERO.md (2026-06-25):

# Pi Zero 2W Display Unit — Bench Test Procedure

| Field | Value |
|---|---|
| Document No. | TP-ZERO-001 |
| Title | Initial Hardware Bring-Up — Pi Zero 2W Display + AHRS Unit |
| Project | Pico-AHRS / PFD |
| Date | 2026-04-15 |
| Version | 0.2 |
| Performed by | _____________ |
| Date performed | _____________ |

---

## Equipment Required

- Raspberry Pi Zero 2W with Waveshare 3.5" DPI LCD (640×480, DPI parallel RGB via 40-pin GPIO, I2C capacitive touch)
- Pico W AHRS unit (ICM-42688-P or WT901, BME280, u-blox GPS module)
- 5 V USB power supply (×2)
- USB keyboard (for initial startup commands)
- Smartphone or laptop (for Pico W AP validation and internet-tethered downloads)
- Level surface (bench or table)
- GitHub branch: `claude/split-display-versions-YJ9h8`

**Pass/Fail legend:**  ✓ Pass   ✗ Fail   N/T Not tested   N/A Not applicable

---

## Phase 1 — Display Unit (standalone, no AHRS)

### 1.1 Power-On and Boot

| Step | Action | Expected Result | Result | Notes |
|---|---|---|---|---|
| 1.1.1 | Apply 5 V to Pi Zero 2W | Green power LED illuminates | | |
| 1.1.2 | Observe DPI panel | PWM backlight illuminates within 10 s | | |
| 1.1.3 | Wait for desktop or console prompt | OS boot completes without kernel panic | | |

### 1.2 First Launch — Demo Mode

| Step | Action | Expected Result | Result | Notes |
|---|---|---|---|---|
| 1.2.1 | Run `python3 pi_zero/pfd.py --demo` | PFD fills screen within 3 s | | |
| 1.2.2 | Observe top strip | `NO LINK` badge present (no AHRS connected — expected) | | |
| 1.2.3 | Observe AI | Blue sky / brown ground horizon visible | | |
| 1.2.4 | Observe AI animation | Horizon animates through scripted demo scenarios | | |
| 1.2.5 | Observe airspeed tape | Speed value scrolls; V-speed arcs visible | | |
| 1.2.6 | Observe altitude tape | Altitude scrolls; VSI bar deflects on climb/descent | | |
| 1.2.7 | Observe heading tape | Heading tape scrolls; bug marker visible | | |
| 1.2.8 | Observe heading box (centre bottom) | "133°" with `M` subscript; heading box white border | | |
| 1.2.9 | Observe speed bug box (top-left) | Magenta border and text — GPS GS source | | |
| 1.2.10 | Observe alt bug box (top-right) | Magenta border — GPS ALT (demo has no baro) | | |
| 1.2.11 | Observe baro button (bottom-right) | Magenta `GPS ALT` label | | |
| 1.2.12 | Observe HDG bug button (bottom-left) | Cyan border — MAG mode | | |
| 1.2.13 | Observe `DEMO` watermark | Red `DEMO` text visible at centre AI | | |

### 1.3 Touch — Setup Menu Access

| Step | Action | Expected Result | Result | Notes |
|---|---|---|---|---|
| 1.3.1 | Place two fingers on screen and hold 0.8 s | Setup menu appears with 6 tiles: FLIGHT PROFILE, DISPLAY, AHRS / SENSORS, CONNECTIVITY, SYSTEM, EXIT | | |
| 1.3.2 | Tap **EXIT** tile | Returns to PFD | | |
| 1.3.3 | Re-enter setup; tap **DISPLAY** | Display settings screen opens | | |
| 1.3.4 | Tap **+** brightness button | Screen brightens one step | | |
| 1.3.5 | Tap **−** brightness button | Screen dims one step | | |
| 1.3.6 | Tap **BACK** | Returns to setup menu | | |
| 1.3.7 | Tap **FLIGHT PROFILE** | V-speeds screen opens with VS0/VS1/VFE/VNO/VNE + tail/actype fields | | |
| 1.3.8 | Tap **BACK**; tap **CONNECTIVITY** | Connectivity screen opens showing current SSID and AHRS link status | | |
| 1.3.9 | Tap **BACK**; tap **SYSTEM** | System screen opens; shows version, TERRAIN/OBSTACLES/AIRPORTS data tiles, FLIGHT SIMULATOR, RESET DEFAULTS | | |

### 1.4 Touch — Bug Setting

| Step | Action | Expected Result | Result | Notes |
|---|---|---|---|---|
| 1.4.1 | Tap alt bug box (top-right of alt tape) | Numpad overlay appears, title "SET ALTITUDE BUG (×100 ft)"; current value shown as dim `Current: <n>` placeholder below an empty entry line | | |
| 1.4.2 | Tap **ENTER** with empty buffer | Numpad closes; alt bug value unchanged (placeholder-not-pre-populated check) | | |
| 1.4.3 | Re-open; type `85` then tap **ENTER** | Numpad closes; alt bug readout shows `8500`; bug chevron moves to 8500 ft | | |
| 1.4.4 | Re-open; type `9` then tap **⌫** | Buffer empties one digit (backspace present on numpad) | | |
| 1.4.5 | Tap HDG bug box (bottom-left of heading strip) | Numpad "SET HDG BUG"; hit region extends full heading-strip height | | |
| 1.4.6 | Type `270` then tap **ENTER** | HDG bug readout shows `270°` | | |
| 1.4.7 | Tap speed bug box (top of speed tape) | Numpad "SET SPD BUG" | | |
| 1.4.8 | Type `90` then tap **ENTER** | Speed bug readout shows `90` | | |
| 1.4.9 | Tap baro box (bottom-right of heading strip) | Numpad title "SET BARO inHg" or "SET BARO hPa" matching Display Settings unit | | |
| 1.4.10 | Tap heading tape | HDG bug jumps to tapped heading | | |
| 1.4.11 | Tap altitude tape | Alt bug jumps to nearest 100 ft | | |

### 1.4.5 Touch — Keyboard Entry

| Step | Action | Expected Result | Result | Notes |
|---|---|---|---|---|
| 1.4.5.1 | Open Flight Profile; tap **CALLSIGN** | Keyboard overlay appears; current tail shown as placeholder, buffer empty | | |
| 1.4.5.2 | Verify row 4 contents | `Z X C V B N M . : ⌫` — period, colon, and backspace present | | |
| 1.4.5.3 | Type `N.1`; tap **⌫** twice | Period and digit removed; "N" remains | | |
| 1.4.5.4 | Tap **CANCEL** | Keyboard closes; callsign unchanged | | |
| 1.4.5.5 | Connectivity → tap AHRS URL | Keyboard opens pre-populated with current URL (e.g. `http://192.168.4.1`); `:` and `.` keys usable for URL editing | | |

### 1.5 Touch — AHRS / Sensors Screen

| Step | Action | Expected Result | Result | Notes |
|---|---|---|---|---|
| 1.5.1 | Enter setup; tap **AHRS / SENSORS** | AHRS setup screen opens | | |
| 1.5.2 | Observe Row 1 (PITCH TRIM) | `−` and `+` buttons present; current value `+0.0°` | | |
| 1.5.3 | Tap `+` pitch trim button | Value increments by 0.5° | | |
| 1.5.4 | Tap `−` pitch trim button | Value decrements back to 0.0° | | |
| 1.5.5 | Observe Row 4 (HEADING SOURCE) | **MAG** button active (cyan), **GPS TRK** available | | |
| 1.5.6 | Tap **GPS TRK** | Button highlights; return to PFD | | |
| 1.5.7 | Observe heading box | Border turns magenta; `G` subscript appears | | |
| 1.5.8 | Observe HDG bug button | Border turns magenta | | |
| 1.5.9 | Return to AHRS setup; tap **MAG** | Heading box returns to white border; `M` subscript | | |
| 1.5.10 | Observe Row 5 (AIRSPEED SOURCE) | **GPS GS** button active; **IAS SENSOR** greyed out | | |

### 1.6 Flight Simulator

| Step | Action | Expected Result | Result | Notes |
|---|---|---|---|---|
| 1.6.1 | Enter setup; tap **SYSTEM** | System screen opens | | |
| 1.6.2 | Tap **FLIGHT SIMULATOR** tile | Simulator setup screen opens with airport grid | | |
| 1.6.3 | Confirm 12 airport presets visible | KSEZ, KPHX, KDEN, KLAX, KSFO, KLAS, KSEA, KOSH, KJFK, KORD, KDFW, KMIA | | |
| 1.6.4 | Tap **KSEZ** (Sedona AZ) | Preset highlights cyan | | |
| 1.6.5 | Tap **START** | PFD returns; `SIM` watermark visible at AI centre | | |
| 1.6.6 | Observe aircraft behaviour | Speed, altitude, heading hold set values | | |
| 1.6.7 | Set alt bug to `9500` | Aircraft climbs toward 9500 ft | | |
| 1.6.8 | Set HDG bug to `270` | Aircraft turns to 270° | | |
| 1.6.9 | Tap `SIM` watermark | SIM controls overlay appears | | |
| 1.6.10 | Tap **BARO → FAIL** | Alt bug/box/tape turn magenta; `GPS ALT` badge appears | | |
| 1.6.11 | Tap **BARO → ON** | Alt bug/box return to cyan; badge clears | | |
| 1.6.12 | Tap **GPS → FAIL** | `NO GPS` badge appears; speed tape shows `---` | | |
| 1.6.13 | Tap **GPS → ON** | Speed recovers; badge clears | | |
| 1.6.14 | Tap **AHRS → FAIL** | `AHRS FAIL` badge appears; horizon freezes | | |
| 1.6.15 | Tap **AHRS → ON** | Horizon resumes | | |
| 1.6.16 | Tap **EXIT SIM** | Simulator stops; watermark clears | | |

---

## Phase 2 — AHRS Unit (standalone)

### 2.1 Pico W Power-On

| Step | Action | Expected Result | Result | Notes |
|---|---|---|---|---|
| 2.1.1 | Apply 5 V to Pico W AHRS unit | Pico W power LED illuminates | | |
| 2.1.2 | Wait 5 s | Pico W WiFi AP `AHRS-Link` visible on a phone/laptop | | |
| 2.1.3 | Connect a device to `AHRS-Link` | DHCP address assigned (typically `192.168.4.x`) | | |
| 2.1.4 | Open browser to `http://192.168.4.1` | JSON or SSE stream response visible | | |
| 2.1.5 | Observe SSE event format | Events contain `pitch`, `roll`, `yaw`, `alt`, `speed` fields | | |
| 2.1.6 | Tilt the AHRS unit ~30° | `roll` value in stream changes correspondingly | | |
| 2.1.7 | Pitch the AHRS unit ~15° nose-up | `pitch` value increases | | |

### 2.2 BME280 Barometric Sensor

| Step | Action | Expected Result | Result | Notes |
|---|---|---|---|---|
| 2.2.1 | Observe SSE stream `baro_src` field | Value is `bme280` (not `gps`) | | |
| 2.2.2 | Observe `baro_hpa` field | Value is within ±5 hPa of local altimeter setting | | |
| 2.2.3 | Observe `alt` field | Pressure altitude within ±50 ft of field elevation | | |

### 2.3 GPS Module

| Step | Action | Expected Result | Result | Notes |
|---|---|---|---|---|
| 2.3.1 | Place unit near window or outside | GPS acquiring — `sats` field > 0 within 2 min | | |
| 2.3.2 | Wait for fix | `fix` field = 1; `sats` ≥ 4 | | |
| 2.3.3 | Observe `lat` / `lon` fields | Values match known position within ~50 m | | |
| 2.3.4 | Observe `speed` field | Near-zero when stationary | | |

---

## Phase 3 — Integrated System

### 3.1 Link Establishment

| Step | Action | Expected Result | Result | Notes |
|---|---|---|---|---|
| 3.1.1 | Start AHRS unit; confirm AP `AHRS-Link` is visible | AP broadcasting | | |
| 3.1.2 | Configure Pi Zero 2W WiFi to join `AHRS-Link` (via Connectivity screen) | Pi associates | | |
| 3.1.3 | Launch `python3 pi_zero/pfd.py` (no --demo) | PFD starts | | |
| 3.1.4 | Observe top strip within 5 s | `NO LINK` badge clears | | |
| 3.1.5 | Observe baro button (bottom-right) | Shows `29.92 IN` in cyan (not `GPS ALT`) | | |
| 3.1.6 | Observe alt bug box (top-right) | Cyan border | | |
| 3.1.7 | Observe speed bug box (top-left) | Magenta border — GPS GS | | |

### 3.2 Attitude Response

| Step | Action | Expected Result | Result | Notes |
|---|---|---|---|---|
| 3.2.1 | Hold AHRS unit level | AI horizon centred; slip bar centred under zero-bank doghouse | | |
| 3.2.2 | Roll AHRS unit ~30° right | AI rolls right; bank pointer deflects right | | |
| 3.2.3 | Roll AHRS unit ~30° left | AI rolls left | | |
| 3.2.4 | Pitch AHRS unit ~10° nose-up | Horizon bar drops; pitch ladder moves down | | |
| 3.2.5 | Pitch AHRS unit ~10° nose-down | Horizon bar rises | | |
| 3.2.6 | Rotate AHRS unit slowly in yaw | Heading tape scrolls in correct direction | | |
| 3.2.7 | Observe attitude response lag | Horizon responds within 1–2 frames of movement (≤ 100 ms) | | |

### 3.3 Horizon Trim (if needed)

| Step | Action | Expected Result | Result | Notes |
|---|---|---|---|---|
| 3.3.1 | Place AHRS unit on a known-level surface | | | |
| 3.3.2 | Observe AI horizon position | Horizon bar aligned with aircraft symbol | | |
| 3.3.3 | If horizon is high/low: enter setup → AHRS / SENSORS → PITCH TRIM | Adjust in 0.5° steps until aligned | | |
| 3.3.4 | If horizon is tilted: ROLL TRIM | Adjust until wings-level | | |
| 3.3.5 | Confirm trim holds across power cycles | Re-launch pfd.py; horizon remains corrected | | |

### 3.4 GPS Integration

| Step | Action | Expected Result | Result | Notes |
|---|---|---|---|---|
| 3.4.1 | With GPS fix acquired: observe track pointer | **Magenta** tick on heading tape shows GPS ground track (suppressed if track ≈ hdg within 1°) | | |
| 3.4.2 | Observe top strip | No `GPS` badge (fix is valid) | | |
| 3.4.3 | Enable GPS TRK mode in AHRS / SENSORS | Heading box border turns magenta; `G` subscript | | |
| 3.4.4 | Rotate AHRS unit slowly | Heading follows GPS track via complementary filter | | |
| 3.4.5 | Return to MAG mode | Heading box returns to white; `M` subscript | | |

### 3.5 Link Loss and Recovery

| Step | Action | Expected Result | Result | Notes |
|---|---|---|---|---|
| 3.5.1 | With link active: power off AHRS unit | After 3 s: `NO LINK` badge appears | | |
| 3.5.2 | Observe tapes | Values freeze at last received value | | |
| 3.5.3 | Power AHRS unit back on | Within 5 s: `NO LINK` badge clears; tapes resume | | |

### 3.6 Connectivity Screen Diagnostics

| Step | Action | Expected Result | Result | Notes |
|---|---|---|---|---|
| 3.6.1 | Setup → **CONNECTIVITY** with link up | STATUS row: AHRS green "CONNECTED"; WiFi green "WiFi: `<ssid>`" showing the actual network name the Pi is associated to | | |
| 3.6.2 | Observe AHRS LINK diagnostics row | Transport + port on the left (typically `WIFI http://192.168.4.1` on Pi Zero 2W); RX counter increments ~20×/s | | |
| 3.6.3 | Observe live **R / P / Y / ALT** on the right | Values match the main PFD; tilt the AHRS and confirm they update here | | |
| 3.6.4 | Power-cycle AHRS unit | RX pauses, then resumes; ERR may increment once; last-error string may briefly show | | |
| 3.6.5 | Tap **TEST AHRS** | Blue status message confirms reachability (or shows the specific error) | | |

---

## Phase 4 — Baro Setting Verification

| Step | Action | Expected Result | Result | Notes |
|---|---|---|---|---|
| 4.1 | Obtain current local altimeter setting (ASOS/ATIS) | Record value: __________ inHg | | |
| 4.2 | Tap baro button (bottom-right) | Numpad opens with current hPa value | | |
| 4.3 | Enter correct inHg value (e.g. `2992` for 29.92) | Baro button updates; altitude corrects | | |
| 4.4 | Verify indicated altitude | Within ±75 ft of field elevation at known location | | |
| 4.5 | Switch baro unit to hPa in Display Settings | Baro button shows hPa value | | |
| 4.6 | Tap baro button and enter hPa value | Altitude unchanged; unit label updates | | |

---

## Phase 5 — Data Downloads

Requires Pi to be on an internet-reachable WiFi (use `sudo bash wifi_switch.sh home`, or configure a home SSID via Connectivity setup).

### 5.1 Terrain Data (SRTM tiles for TAWS alerting)

| Step | Action | Expected Result | Result | Notes |
|---|---|---|---|---|
| 5.1.1 | Setup → System → **TERRAIN** | Terrain data screen opens; idle state if no tiles present | | |
| 5.1.2 | Observe region grid | Nine preset tiles visible: US Southwest, US Pacific, US Southeast, US Northeast, US Midwest, All CONUS, Alaska, Europe West, All Europe — each with tile count + size estimate | | |
| 5.1.3 | Observe top tile | **DOWNLOAD CURRENT AREA** — 5°×5° box (~25 tiles, ~35 MB) around GPS position | | |
| 5.1.4 | Tap preset **US Southwest** | Download starts; progress bar advances at top of screen | | |
| 5.1.5 | Tap **CANCEL** mid-download; re-tap region | Existing tiles skipped; remaining ones fetch (resumable) | | |
| 5.1.6 | Wait for completion | Done ✓ message; disk tile count + MB updates | | |
| 5.1.7 | Return to PFD, observe status badges | `NO TER` badge clears | | |
| 5.1.8 | If on Pico W AP (no internet): tap any region | "WiFi (home network) required" guard message appears | | |

### 5.2 Obstacle Data (FAA DOF)

| Step | Action | Expected Result | Result | Notes |
|---|---|---|---|---|
| 5.2.1 | Setup → System → **OBSTACLES** | Obstacle data screen opens | | |
| 5.2.2 | Tap **DOWNLOAD** | Progress bar runs; ~20 MB CSV downloads then parses | | |
| 5.2.3 | Wait for completion | "Done ✓  ~76,000 obstacles loaded" | | |
| 5.2.4 | Return to PFD | `NO OBS` badge clears | | |
| 5.2.5 | After 28-day simulated expiry (or on stale file) | `EXP OBS` orange badge appears | | |

### 5.3 Airport + Runway Data (OurAirports)

| Step | Action | Expected Result | Result | Notes |
|---|---|---|---|---|
| 5.3.1 | Setup → System → **AIRPORTS** | Airport data screen opens | | |
| 5.3.2 | Tap **DOWNLOAD** (or **UPDATE** if present) | Progress bar runs; airports.csv (~12 MB) then runways.csv (~3 MB) download | | |
| 5.3.3 | Wait for completion | "Done ✓  72,007 airports, 14,727 runways" (counts may vary by data version) | | |
| 5.3.4 | Observe screen footer | Two-row toggle panel: PUBLIC / HELI / WATER / OTHER on row 1; RUNWAYS / EXT C/LINES on row 2 | | |
| 5.3.5 | Return to PFD | `NO APT` badge clears | | |

---

## Phase 6 — Attitude Indicator Overlays

Run in demo mode (`pi_zero/pfd.py --demo`) or flight simulator (Setup → System → FLIGHT SIMULATOR → KSEZ → START SIM) for repeatable overlay scenes. All overlays presume Phase 5 downloads completed.
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

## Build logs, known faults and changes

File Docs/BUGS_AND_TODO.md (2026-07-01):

# Bugs & TODO

Tracked in git so nothing is lost across Claude Code sessions.
When opening a new session, start here for context.

Format: each item gets a short ID, a status, a one-line summary, and
notes with enough context to pick it up cold.

## Open

### GRACEFUL-SHUTDOWN  Clean shutdown/reboot + durable settings (SD protection)
Status: **DONE (pi4 + pi_zero) — code + setup + docs landed** (part 1 of 2)
An SD-booted Pi that's always power-pulled will eventually corrupt its card.
Part 1 (this change) adds a graceful stop + hardens the one file the app writes:
  - **SHUTDOWN / REBOOT buttons** on the SYSTEM setup page (both displays),
    arm-to-confirm (first tap arms → "TAP AGAIN", 2nd tap within 4 s executes,
    auto-disarm after 4 s) so a stray tap can't halt the panel in flight.
    `_system_power()` flushes settings then `sudo -n systemctl poweroff|reboot`.
  - **sudoers drop-in** (`/etc/sudoers.d/pfd-power`) scoped to exactly those two
    commands for the non-root PFD user — added to setup.sh / pi4/setup.sh /
    pi_zero/setup.sh, plus `tools/install_shutdown_sudoers.sh` for existing
    installs.
  - **Durable settings write**: `shared/settings.py::save_from` now does
    temp-file → `fsync(file)` → atomic `os.replace` → `fsync(dir)`, so a power
    pull can't leave a truncated `settings.json`.
  - Docs: README "Shutting down" (incl. optional `dtoverlay=gpio-shutdown`
    hardware button), USER_MANUAL_PI4 §13, USER_MANUAL_ZERO §13.
  - pi_zero SYSTEM drag-scroll clamp 9→10 for the extra button row.
Part 2 (**TODO — do at KOSH**): **read-only root filesystem (overlayfs)** so a
power pull can NEVER corrupt the OS, with a small writable partition for
settings + downloaded nav/terrain data and a ground-only "maintenance" toggle
to unlock writes for downloads. This is the real habit-free fix; the buttons
above only help if you remember to use them.
No firmware change. Files: `pi4/pfd.py`, `pi_zero/pfd.py`, `shared/settings.py`,
`setup.sh`, `pi4/setup.sh`, `pi_zero/setup.sh`, `tools/install_shutdown_sudoers.sh`.

### UI-AHRS-ZERO-VS-TRIM-SPLIT  Separate the AHRS zero from the display zero
Status: **DONE (pi4 + pi_zero) — code + manuals landed**
Pilot note: "confusing to have an AHRS Zero and a display zero in the same
space." Reworked the AHRS / SENSORS page to hold ONLY AHRS-sensor settings —
PITCH ALIGN + ROLL ALIGN with the **ZERO** (flight-zero) button on the PITCH
ALIGN row at the top, then mag/orient/mount/hdg/airspeed. The display-side
PITCH/ROLL TRIM moved to a new **HORIZON** tab on the DISPLAY setup page (tab
index 3, `_DSP_TRIM_TAB_INDEX`, custom trim-stepper rows like TERRAIN INHIBIT;
stored in disp["ss"] as before so the AI renderer is unchanged). The LEVEL
button was relabelled **ZERO** to match the "AHRS zero" framing. pi_zero gained
the PITCH/ROLL ALIGN steppers it never had (parity), and now copies the
broadcast pitch_align/roll_align/mounting/orientation into disp so `_flight_zero`
reads the AHRS-confirmed align (not a stale settings value). AHRS drag rows
9→7. No firmware change. Files: `pi4/pfd.py`, `pi_zero/pfd.py`. Docs:
USER_MANUAL_PI4 §10/§11, USER_MANUAL_ZERO §10/§11.

### UI-TERRAIN-INHIBIT-MOVE  Move TERRAIN INHIBIT to the DISPLAY page
Status: **DONE (pi4) — code + manual landed**
Pilot note: terrain inhibit is a display/TAWS preference, not an AHRS-sensor
setting, so it doesn't belong on the AHRS / SENSORS page. Removed it from the
AHRS page (row 7; PITCH/ROLL ALIGN renumber 8/9→7/8, drag rows 10→9) and added
it as a hand-drawn action-button row on the DISPLAY setup tab
(`_dsp_inhibit_btn_rect`, tab index 1). pi4 only (pi_zero never had it). Also
bumped the AHRS alignment clamp 10°→15° everywhere (firmware `$ALIGN` + load +
`/align`, both displays' `_flight_zero` / align-stepper / mag-cal auto-align)
so the LEVEL cage has headroom; test range extended in
`firmware/test_flight_zero_sign.py`. Files: `pi4/pfd.py`,
`firmware/main.py`, `firmware/web_server.py`. Docs: USER_MANUAL_PI4 §10/§11.

### AHRS-LEVEL  One-tap AHRS flight-zero (LEVEL) button on the AHRS page
Status: **DONE (pi4 + pi_zero + firmware) — code + tests + manuals landed; verify in flight**
Branch `claude/ahrs-level-traffic-dedup`. Green **LEVEL** button on the PITCH
TRIM row of the AHRS / SENSORS screen — a Sentry/ForeFlight-style cage that
re-zeros **the AHRS itself**, NOT the display (per explicit pilot requirement:
"MUST set the ZERO for the gyro/accelerometers, not a display zero").
`_flight_zero()` captures the current body attitude (`disp['pitch']`/`['roll']`)
and folds it into the AHRS **input-side axis alignment** (`pitch_align` /
`roll_align` — the raw gyro/accel/mag rotation applied BEFORE the Mahony
filter, `_apply_axis_align` in firmware/main.py), pushed over `$ALIGN` (USB)
with an HTTP `/align` fallback (new firmware endpoint) for WiFi-only links.
Persisted in AHRS flash (`_save_orient`), seen by all displays, and it also
kills the mounting-tilt yaw→pitch/roll coupling that makes a small error
compound in turns — the actual cause of "AHRS 100% unusable".
  - Sign rule (safety-critical, wrong sign DOUBLES the error):
    `align_new = clamp(align_old + sign·body, ±15°)`, `sign = -1 normal / +1
    inverted`. The inverted flip is because align acts on RAW sensor data while
    `_apply_remap` sign-flips the Euler output for inverted mounting. Verified
    to converge for all 4 connectors × both mountings in
    `firmware/test_flight_zero_sign.py` (replicates the main.py align+remap
    math). LEVEL also zeros any leftover display-side trim.
Files: `pi4/pfd.py`, `pi_zero/pfd.py` (`_level_btn_rect`, `_flight_zero`,
`_push_align_to_pico` HTTP fallback, draw/hit/action on `ahrs_setup`);
`firmware/web_server.py` (`/align` endpoint). Docs: USER_MANUAL_PI4 §AHRS,
USER_MANUAL_ZERO. Supersedes the encrypted-Sentry LEVEL experiment reverted
earlier (see FOREFLIGHT-0X65 notes) — now on the WT901 AHRS where it works.
Open: bench/first-flight confirm a level-cruise tap zeros both axes and that
±15° is roomy enough for the real mounting offset (raise the firmware ALIGN
clamp if not).

### TRAFFIC-OWNSHIP-ECHO  Suppress ownship echo on the internet traffic feed
Status: **DONE (pi4 + pi_zero) — code + tests + manuals landed**
The aggregator (airplanes.live / adsb.lol / adsb.fi) has no Ownship Report, so
it returns the ownship's own transponder as a traffic diamond glued to the
ownship symbol. `shared/adsb.py` gains `is_ownship_echo()` (geometry gate —
co-located within 0.6 NM and, when both alts known, 350 ft — plus a velocity
veto when moving so a genuine close pass on a different heading survives) and
`OwnshipEchoFilter` (latches the echo's hex for 45 s so feed lag can't slide it
back into view). Applied to the INET snapshot only, in `_update_traffic()` on
both displays; radio traffic keeps its GDL90-Ownship-Report filtering. Tests:
`shared/test_adsb.py` (`test_ownship_echo_geometry`, `test_ownship_echo_latch`).
Docs: USER_MANUAL_PI4 §Traffic, USER_MANUAL_ZERO §16C.

### MANUALS-UPDATE  Update user manuals for the nav-data-pi-settings session
Status: **OPEN — features shipped + merged to main; docs pending**
Update `Docs/USER_MANUAL_PI4.md`, `Docs/USER_MANUAL_ZERO.md`,
`Docs/USER_MANUAL_IPHONE.md` (where applicable) and `README.md` to cover
everything landed this session (branch `claude/nav-data-pi-settings`):
  - **Nav data**: DATA & MAPS → NAV DATA download; the 28-day refresh flow
    (`Docs/NAVDATA_UPDATE.md`) + the browser/iPad **Publish nav data** Actions
    workflow (`.github/workflows/publish-navdata.yml`).
  - **Nav-data currency badge**: it's a ~56-day validity window (issue date +
    effective period), NOT the 28-day publish cadence — document so it isn't
    mistaken for a bug.
  - **Approaches on the Pi Zero**: LOAD / ACTIVATE / CANCEL + **CHANGE APPR**
    3-button row on the FPL page; SELECT APPROACH → TRANSITION → PREVIEW
    (terrain + racetrack holds); loaded-approach leg list on the FPL; runway DB
    now loaded on the Zero (data-only, still no runway drawing).
  - **Screen-sync additions**: approach load/activate/cancel now syncs both ways
    (last-write-wins); **V-speeds / flight profile sync** across all displays;
    the reboot/power-up re-alignment keepalive.
  - **SIM**: FOLLOW FLIGHT-PLAN now holds the leg centerline enroute (not just
    on approaches).
  - **PFD**: approach fix sign-posts gated to within 30 nm.
  - **MFD radar LOOP**: NEXRAD/FIS-B playback — bottom-centre ▶ LOOP → play/
    pause · scrubber · ● LIVE, "RADAR −NN min"; FIS-B from a RAM buffer,
    internet NEXRAD pulled on demand from the IEM time-machine archive (WMS-T,
    `n0q-t.cgi` / `nexrad-n0q-wmst`), 60 min at 5-min steps, session-cached.
Also refresh any previews the above changed (ties into HITS-PREVIEW below).

### HITS-PREVIEW  Recapture approach previews (HITS fix + orange fix boxes)
Status: **OPEN — queued for tomorrow; code fix already in, captures pending**
Context: the recurring "no HITS boxes in previews" bug was the scenes setting
`active:True` but not `loaded:True` — `_approach_hits_refresh`'s fallback gates
on `loaded` (fixed in `render_pfd_offline.py`: `_setup_synthetic_approach` /
`_setup_hits_boxes` now set `loaded:True`).  A new `_setup_approach_fixes` scene
+ `preview_approach_fixes` was added (KSEZ RWY 03 legs JAKLY/DARTS/WULPI/RW03,
aircraft ~7 NM out) to show the **amber approach-fix sign-post diamonds**.
To do on the displays (pfd5 for pi4/pi5, the Zero for piZ):
  - Run `./tools/regen_previews.sh pi4` (and piZ) and confirm the HITS boxes
    actually render now (the `loaded:True` fix) — last time they were absent
    even though the approach was "active".
  - Frame/verify the new `preview_approach_fixes` orange-box scene.
  - Want a shot with **HITS ON + an approach with a fix (orange box) + the
    magenta course line** all visible together.
  - §16 manual wording: approach-fix sign-posts show even when HITS is OFF
    (the orange boxes are independent of the cyan HITS corridor).
  - While regenerating: also refresh the previews touched by the MAG/TRUE work
    — UNITS settings tab (new HDG/CRS REF row), FPL editor (SAVE/REVERSE/LOAD +
    magnetic leg courses), and the heading-tape shots (now show the `MAG` tag
    and magnetic numbers).

### TZ-HITCH  Timezone lookup blocks the render thread (~1.7 s freeze)
Status: **OPEN — found via MFD cProfile (moving sim); not started**
Context: the MFD strip local time (`_localtime.offset_hours`, pfd.py:14688), its
zone label (`abbrev`, 14712), and the ETA-local (13896) all run on the RENDER
thread and call `timezonefinder.timezone_at` on a cache miss.  One cold lookup =
~800k flatbuffer reads ≈ **1.7 s**, freezing the frame.  `shared/localtime.py`
already caches by ~0.2° (~12 nm) cell, so it's NOT per-frame — but you get the
freeze at startup, on a new destination, and potentially each ~12 nm tz-cell
crossing in flight.  Only shows when MOVING (the parked profile had zero tz cost).
Fix: get `timezone_at` OFF the render thread.  Add `allow_lookup=False` to
`tz_name_for`/`offset_hours`/`abbrev` so the render thread reads cache-only and
falls back to the longitude approx (already there) on a miss; run a small
background warmer that calls the blocking path for the aircraft AND active
destination position every few seconds to keep the cache hot.  Unknown whether
the 1.7 s is a one-time data-load or per-query — the off-thread warmer covers both.

### MAGVAR  Display magnetic courses/headings (add magnetic variation)
Status: **DONE** — MAG is now the default reference; TRUE is a toggle.
Implementation:
  - `shared/magvar.py`: self-contained **WMM2025** declination model (degree-12
    Gauss coefficients embedded, no data file / no network).  Vendored and
    trimmed to declination-only from pygeomag (MIT); validated bit-exact vs
    pygeomag worldwide.  `declination(lat, lon)` / `true_to_mag()` with a coarse
    spatial+temporal cache so it's cheap per frame.
  - Display-layer conversion only (internal nav math stays TRUE).  Applied at:
    heading tape (+ `MAG`/`TRU` annunciation on the box), TRK/HDG/BTW/DTK/WIND
    data-strip fields, CDI bearing, and FPL leg courses (regular + approach;
    `draw_fpl` now shows mag bare / true with a `T` suffix).
  - New **HDG / CRS REF** row on Setup → Display → UNITS (pi4 + pi_zero), default
    MAG, persisted per-display in `settings.json`.
  - Mag-cal wizard left calibrating against TRUE cardinals — MAG is a pure
    display conversion, so no recalibration was needed.
  - Winds-aloft map barbs intentionally left TRUE (forecast-wind convention).

### PIZ-APPROACHES  Port loaded approaches to the Pi Zero
Status: **DONE — receive/draw + LOAD-on-piZ both shipped; see the fuller entry below**
Context: the Pi Zero had NO published-approach support — only a synthetic cyan
final-course stub on the inset (`pi_zero/moving_map.py`), no leg list / no
procedure loading.  Per pilot: **NO HITS boxes** (there's no SVT on the Zero) —
show the **raw CDI / VDI** guidance on the PFD, and the **approach path overlay
on the MFD inset** (the legs drawn as a polyline, like the Pi 4 inset).  Now
implemented as a screen-sync consumer + 2D inset renderer (the active leg drives
the existing CDI); approach-loading ON piZ is the remaining stretch.  Details +
status in the "Published approaches on pi_zero (parity with pi4)" entry below.

### APPR-FINAL-FLYBY  Fly-by (lead) turn onto the final approach course
Status: **OPEN — fly-over works; the final-course intercept should anticipate**
Context: approach leg sequencing is now fly-OVER (cross the fix, then turn) —
correct for step-down crossings and confirmed in flight.  But the turn from the
intermediate segment ONTO the final approach course should be a fly-BY: lead the
turn so the aircraft rolls out established ON the final course instead of
overflying the turn fix and S-turning back through the localizer/centreline.
Real plates mark most fixes fly-by (turn anticipation) and only specific ones
(the MAP, some others) fly-over.  Implement turn-anticipation for the
final-course intercept (lead distance ≈ f(groundspeed, turn angle, bank)),
keeping fly-over for the MAP / charted fly-over fixes.  `_approach_check_advance`
is the place; it currently advances exactly at fix passage for all legs.

### FPV-RUNWAY-ALIGN  Flight-path vector should sit on the runway on final
Status: **OPEN — colour fixed (green); pilot reports it was NOT on the threshold**
Analysis so far (the geometry SHOULD line up on a 3° final):
  - FPV rect `_full_ai = (0,0,W,HDG_Y)` matches the shared-GL SVT viewport
    `(0,HDG_H,W,HDG_Y)` (both height HDG_Y), and the SVT uses V_FOV=48° = the
    same ah/48 px-per-deg the FPV uses.  Centres + scale agree (perspective vs
    linear differ <~1 px at 3°).
  - Vertical: FPV y = (pitch − γ)·px/deg below centre; the threshold on a 3°
    path is 3° below the horizon, horizon is pitch below centre → also
    (pitch − γ) below centre.  Pitch cancels, so they coincide — even with the
    sim's crude `pitch = VS/100` model (shifts both equally).
  - Horizontal: rel_brg = track − hdg; the runway sits at the same crab offset
    from the nose, so they coincide with wind too.
  ⇒ On the FINAL 3° segment FPV and threshold must overlap.  On a STEP-DOWN
    segment the FPV correctly sits ABOVE the threshold (it shows the actual,
    shallower flight path, not the line to the runway) — expected, not a bug.
Flight clues (2026-06-14): on a stabilised final, VDI perfectly centred (~few
ft high) but the FPV "never got close to the runway" — and in LEVEL flight
(VS=0) the FPV sits well above the horizon with its BOTTOM EDGE on the horizon
line (i.e. ring centre ~1 radius ≈ 1° / 12 px high).  By the math, level flight
⇒ γ=0 ⇒ ring centre ON the horizon; the alt-tape VSI uses the SAME `vspeed` the
FPV does, so VSI=0 ⇒ γ=0.  So either (a) a small residual VS the VSI rounds to
0 — note GS was ~90 kt, where the FPV is very sensitive (~1° per ~150 fpm), so
~150 fpm already lifts the ring a full radius — or (b) a reference offset
between the FPV's linear (pitch−γ)·ah/48 and the SVT's perspective horizon.
Added a debug overlay to read it live: set `FPV_DEBUG = True` in config_local.py
→ shows `pit / VS / GS / g / dy` by the marker.  Next flight: when it looks
high, confirm whether VS is truly 0; if VS=0 and γ≠0 it's a code bug, else the
FPV is honest and we may want a min-GS floor / deadband on γ.  Colour green done.

### AHRS-SRC-SELECTOR  Runtime AHRS source picker (AUTO / USB / WIFI)
Status: **OPEN — usable workaround documented**
Today PFD picks the AHRS transport once at startup (USB if
`/dev/ttyACM*` is enumerated within the first ~2 s of `main()`,
otherwise Wi-Fi SSE).  That misses two real cases:
  - **Late USB enumeration**: on the Pi Zero with `dwc2 dr_mode=host`
    the Pico W enumerates around t+79 s, well after PFD has chosen
    Wi-Fi and entered its retry loop.  Workaround: `sudo systemctl
    restart pfd.service` once `ls /dev/ttyACM0` resolves.
  - **Hot-plug / hot-unplug**: yanking the USB cable or losing the
    Pico W's AP doesn't trigger a fallback; the pilot has to restart
    PFD by hand.
Wanted: a setting `ahrs_source` ∈ {auto, usb, wifi} surfaced on the
Connectivity Setup screen as a three-pill segmented control.  A daemon
thread polls every 2–3 s and:
  - When `auto`: prefers USB if `/dev/ttyACM*` exists, else Wi-Fi.
  - When `usb` (forced): retries `/dev/ttyACM*` until present; never
    falls back to Wi-Fi on its own.
  - When `wifi` (forced): never opens the serial port even if a Pico W
    appears.
  - Switches transports cleanly (stop old client, start new) without
    needing a full PFD restart.
  - Surfaces "AHRS DOWN — fallback in 5 s" hint on the AI in the
    interim so the pilot isn't confused by a frozen attitude.
Touches: `pi_zero/pfd.py` + `pi4/pfd.py` AHRS startup block,
`shared/serial_client.py` + `shared/sse_client.py` lifecycle (need a
clean `.stop()` + `.is_alive()` contract).  Estimated work: ~30 min
+ test.

### BOARD-REV-B  Next AHRS PCB spin — index
Status: **OPEN — sensor selection locked, layout work next**
Locked-in decisions (see linked entries for the full rationale):
  - **Airspeed transducer**: **TE MS4525DO ±1 psi** replaces the
    SDP33-1500Pa. The SDP33 saturates at ~96 kt; S-21 cruise is
    130 kt. See SDP31-AIRDATA "Higher-range swap path".
  - **AOA transducer**: a **second MS4525DO** on the same I²C bus at
    the alternate address (single BOM line covers both). See AOA-PROBE.
  - Net result: rev B carries **2× MS4525DO** — one for pitot/static,
    one for AOA — sharing the I²C bus, driver, and supply rails.
  - **AOA probe head**: AlphaSystems Eagle preferred; 2-hole DIY
    flush probe as the cheap alternative.
  - **Sensor footprint reservations**: keep the 0x22 SDP3x pad on rev
    A's footprint plan; rev B replaces it with the second MS4525DO
    footprint + a pair of silicone-hose nipples for the AOA probe lines.
Bench plan before the spin: finish air-data validation on the SDP33
(it'll read up to ~96 kt fine — enough to bench-prove the IAS/TAS/wind
math against a hand pump and against GPS GS in zero-wind taxi), then
queue the layout work.
Firmware to write when rev B lands:
  - `firmware/ms4525.py` — TE protocol (different from Sensirion), one
    driver covers both units. ~70 lines.
  - `main.py` instantiates the driver twice, address-strapped.
  - `airdata.py` is unchanged — it consumes `dp_pa` regardless of
    which transducer produced it.
  - AOA math: linear calibration curve fit on first-flight data, then
    persisted; `aoa_deg` + `aoa_src` already reserved in the `$AHRS`
    JSON by the AOA-CALC entry, so the display side picks it up free.

### WAVESHARE-35-DPI  Pi 4 Waveshare 3.5" DPI panel won't initialise
Status: **OPEN — low priority, blocked on time, ROADOM 7" HDMI works fine**
Target: `/boot/firmware/config.txt`, possibly `pi4/config.py` profile
overlay name, possibly Waveshare's `LCD-show` package.
Context: tried switching from the ROADOM 7" HDMI to the Waveshare 3.5"
DPI hat. Set `DISPLAY_PROFILE = "waveshare_35"` and uncommented the
DPI lines in `config.txt`:
  ```
  dtoverlay=waveshare-35dpi-3b-4b
  framebuffer_width=640
  framebuffer_height=480
  ```
Pi boots and SSH works, but the Waveshare panel stays dark. Diagnosis:
the overlay file `waveshare-35dpi-3b-4b.dtbo` is **not present** in
`/boot/firmware/overlays/` on Pi OS Bookworm (kernel 6.12). Only the
DSI-Waveshare and CAN-hat overlays ship now — the older panel-specific
DPI overlays were deprecated. The dtoverlay line is silently ignored;
`/sys/class/drm/` shows only HDMI connectors, never a DPI one.
Two paths forward when picking this up:
  - **A1**: Install Waveshare's `LCD-show` package
    (`git clone https://github.com/waveshare/LCD-show && sudo
    ./LCD35-show`) — ships the missing overlay. Old script, edits
    `config.txt` itself and reboots; back up `config.txt` first.
  - **A2**: Use the modern `vc4-kms-dpi-generic` overlay with explicit
    panel timings looked up from the Waveshare datasheet. Cleaner,
    keeps the install self-managed.
Confirmed today that path **B** (override `DISPLAY_W`/`DISPLAY_H`
to 640×480 in `config_local.py` while keeping HDMI on the ROADOM)
would let us validate the small-screen *layout* without bringing
up the Waveshare panel — useful as a pre-step for any future
sessions that want to verify PFD rendering at 640×480 before doing
the hardware swap.
Recovery applied today: reverted `config.txt` to HDMI-only, restored
ROADOM 7" as the active display.

### SVT-GROUND-SKIRT  Ground hidden by sky at low altitude + steep bank
Status: **OPEN**
Target: `pi4/svt_renderer_gl.py` (inner mesh near-zone, sky shader,
possibly a new fixed-elevation ground polygon).
Context: at low altitude with steep bank, the camera looks nearly
straight down through the AI window. The terrain mesh has finite
extent and the inner mesh's near zone has a small hole / discard
band near the camera. In that combination, fragments along the
"down-the-wing" sightline fall outside the mesh's footprint at the
camera's near plane, so the sky shader fills in — pilot sees a
strip of blue under the wing where ground should be.
Work items:
  - Identify whether the gap is from the inner mesh's near-zone
    discard, the camera near plane clipping mesh triangles, or the
    outer-mesh discard square not extending below the inner mesh
    when banked. A frame capture at low alt + 60° bank should make
    the geometry obvious.
  - Add a low-cost "ground skirt": a flat polygon at terrain
    elevation that extends well below and around the camera so any
    near-camera gap fills with terrain colour rather than sky.
    Cheap (single quad) and depth-tested so legitimate terrain
    overdraws it.
  - Verify under the ROADOM 7" sim: low-pass at 100 ft AGL at
    Sedona with 45–60° bank should show ground edge-to-edge
    through the AI, not a wedge of blue along the lower wing.

### SVT-MESH-OVERLAP  Visible blue gap between high-res and low-res mesh
Status: **OPEN**
Target: `pi4/svt_renderer_gl.py` — outer mesh's `grid_max_dist_m` /
mesh extents, plus the inner mesh's far edge.
Context: the SVT renders an inner high-res mesh (sharp foreground)
and an outer coarse mesh (distant ridges). They overlap by ~20 %
(`discard_inside_m = mesh_radius_m * 0.80`) so the inner owns the
foreground. In a few situations a thin wedge of sky shows through
the seam between the two meshes — typically along the horizon at
moderate banks, where the inner mesh's far edge sits just above
the outer mesh's near edge as drawn through the perspective
projection.
Work items:
  - Increase the overlap band — drop `discard_inside_m` to
    something like 0.65 of the inner radius, or extend the inner
    mesh outward by a tier so the seam lives further out where
    perspective compresses it below pixel resolution.
  - Alternative: pull the outer mesh slightly down toward the
    horizon by biasing its vertices' Z by a small constant when
    rendered, so any sliver always reads as terrain rather than
    sky. Cheap if the bias is small enough not to affect the
    silhouette.
  - Confirm the fix doesn't reintroduce the "morphing recentre"
    artefacts from the original mesh-snap work (commit chain on
    the GL bring-up). A regression-style preview that captures
    pre/post for the same scene at the same camera state would
    catch this.

### #8  Range rings — distance circles on terrain
Status: **OPEN**
Target: symbol overlay in pi4/pi_zero.
Context: draw 1 nm / 2 nm / 5 nm distance rings on the SVT so pilot
has spatial reference for nearby airports/obstacles.

### #9  Pico W firmware — debug AP not appearing
Status: **OPEN**
Target: `firmware/main.py`, `firmware/config.py`.
Context: when `AP_SSID = "AHRS-Link-DEBUG"` or similar diagnostic
values, the AP doesn't come up. Works with default SSID. Possible
channel/password-length edge case.

### SDP31-AIRDATA  SDP33-1500Pa airspeed driver + air-data computer
Status: **FIRMWARE LANDED — waiting on hardware install + in-flight calibration**
Target: new `firmware/sdp31.py`, additions to `firmware/main.py`,
new fields in the `$AHRS,{json}` packet consumed by `pi4/serial_link`
and the iPhone SSE client.
Resolution (firmware side): `firmware/sdp31.py` ships the Sensirion
continuous-mode I²C driver (CRC-validated 9-byte frames, soft reset
on init, manual + auto zero offset). `firmware/airdata.py` ships IAS
(against ρ₀), TAS (density-corrected via BME280), density altitude
(inverse ISA), and the wind-triangle solution. `firmware/main.py`
inits the SDP33 from `SDP31_ENABLE` in `config.py`, populates the
new `ias_kt` / `tas_kt` / `dp_pa` / `oat_c` / `dens_alt_ft` /
`wind_dir` / `wind_kt` / `airdata_ok` fields in `state`, and
broadcasts them on both the SSE event stream and the `$AHRS,…`
USB serial line. `web_server.py` adds a `/sdp_zero` HTTP endpoint
for in-flight zero re-capture. Documentation: REQUIREMENTS_AHRS
gains §7B Air-Data Computer (REQ-AHRS-AIR-001 … 008); USER_MANUAL_PI4
§21 covers wiring + plumbing + range; the speed-tape source switch
is documented in §2 of both pilot manuals.
Still open:
  - **Hardware install + first-flight cal.** Bench the SDP33 with
    a hand pump (0–1500 Pa) to confirm `dp_pa → ias_kt` math; then
    plumb pitot + static and validate IAS against GS at cruise in
    near-zero wind.
  - **Higher-range swap path — decided as MS4525DO × 2 in rev B.** The
    SDP33-1500Pa saturates at ~96 kt IAS sea level. With S-21 cruise
    actually at ~130 kt (= 2740 Pa dp) the part on the rev-A board is
    undersized for the real airframe — it pegs in cruise. Pilot
    decision: **finish bench-validation on the current SDP33** (it'll
    read up to 96 kt fine, plenty to prove the air-data math), then
    swap to **TE MS4525DO at ±1 psi** on the next board spin. Same
    pair gets used for AOA — see AOA-PROBE below for the rationale —
    so the rev B BOM gains one part number that covers both
    pitot/static and AOA. Driver work is a new ~70-line
    `firmware/ms4525.py` (different protocol from Sensirion); the
    rest of the air-data pipeline doesn't change.
  - **Stall-warn enunciator** below configured Vs1 — visual + voice
    callout to make the existing speed-tape colour band
    authoritative. Pairs with REQ-DISP-PI4-AUD-001.
Context: the new sensor board carries a Sensirion SDP33-1500Pa
differential-pressure sensor — pitot pressure on one port, static on
the other.  With the existing BME280 (static pressure + OAT) we get
a complete pitot-static air-data set:
  - **IAS** (knots) = `sqrt(2·dp / ρ₀)` — what the speed tape should
    show.  Currently the tape is fed by GPS groundspeed, which lies
    in any wind.
  - **TAS** (knots) = `IAS · sqrt(ρ₀ / ρ)` where ρ comes from BME280
    static + OAT.  Needed for centripetal accel in AHRS-GPS-AID and
    for the wind-triangle solution.
  - **Pressure altitude** is already computed by BME280 + QNH from
    the firmware's existing baro path; this entry doesn't change it.
  - **Wind solution**: with TAS + heading (from AHRS) + GS + track
    (from GPS), wind = ground_vec − air_vec.  Drop it into the
    `$AHRS` packet as `wind_dir` / `wind_kt` so the displays can
    show a wind ribbon.  Side benefit: validates AHRS-MAGCAL by
    cross-checking the wind solution against forecast / pilot
    observation.
  - **Stall-warning hook**: with IAS available we can light a
    `LOW SPD` enunciator below configured Vs1 in the V-speeds
    profile.  Already a pi4 colour band on the speed tape; this
    just makes the audible/visual alert authoritative.
Work items:
  - I²C driver for the SDP33 — Sensirion's reference protocol is
    short (start continuous mode, read 9-byte frames with CRC,
    handle the auto-zero offsets).  About 80 lines of MicroPython.
  - Air-data math in `firmware/main.py` (or a small `airdata.py`):
    IAS, TAS, density-altitude.  Cross-check IAS against GS at
    cruise to verify driver math before depending on it.
  - `$AHRS` JSON gains `ias_kt`, `tas_kt`, `wind_dir`, `wind_kt`.
  - Pi 4 + iPhone speed tapes: switch the primary source to IAS
    when the air-data path is live (fall back to GS with a small
    "GS" subscript when SDP33 reports unhealthy, mirroring the
    existing GPS-fallback pattern on the heading tape).
  - V-speeds page: nothing changes structurally — the existing
    Vs0 / Vs1 / Vfe / Vno / Vne entries already drive the colour
    bands.  Stall-warn enunciator is the only addition.
Pairs with AHRS-GPS-AID (TAS is the correct centripetal input).

### AOA-CALC  Computed AOA from speed + load factor + ρ (pre-probe)
Status: **OPEN — software-only, can land TODAY with current sensors**
Target: new `firmware/aoa_calc.py` (or extend `firmware/airdata.py`),
`$AHRS` packet, AOA indexer in `pi4/pfd.py` and the iPhone display.
Context: in the linear region of the lift curve, AOA can be inferred
from sensors we already have on the bench: WT901 (load factor),
BME280 (static + OAT for ρ), and GPS (groundspeed).  No new hardware
required to start.  Useful as an on-speed cue and as a bridge until
AOA-PROBE ships; not a substitute for measured AOA at the margins.
Math: from the lift equation `L = n·W = ½·ρ·V²·S·Cl`, solve for Cl
and divide by the airframe's lift-curve slope:
  `α ≈ α₀ + Cl / Cl_α`
  `Cl  = (n·W) / (½·ρ·V²·S)`
where `n` is load factor (from the WT901 accel Z, in g), `V` is
TAS (SDP33 + BME280), `ρ` is air density (BME280 static + OAT), and
`W` / `S` / `Cl_α` / `α₀` are airframe constants for the Rans S21.
Inputs (with the same fallback ladder AHRS-GPS-AID uses):
  - **Velocity** — TAS from SDP31-AIRDATA when it lands; GS from
    `gps.speed_kt` until then.  In zero wind GS == TAS; in wind the
    error scales with the wind component.  Surface the active
    source in the indexer (small `gs` / `tas` subscript) so the
    pilot doesn't trust an upwind on-speed cue.
  - **Load factor** from WT901 (use the same gravity-vector estimate
    the AHRS produces; rotate the body-frame accel into the
    wing-perpendicular axis).
  - **Density** ρ from BME280 static + OAT.
  - **Weight** as a pilot-entered field on the V-speeds / Flight
    Profile screen — accepts dry-weight + fuel and decrements by
    the fuel-flow estimate over the flight (or just a single GW
    entry to start; refine later).
  - **Cl_α, α₀, S** stored in the airframe profile alongside the
    V-speeds (already a JSON profile file).
Caveats — explicit so the indexer doesn't lie:
  - Linear-region only.  Departs from real AOA near the stall, in
    deep flap, and during accelerated stalls.  Calibrate the
    indicator's "yellow" band conservatively and treat the "red"
    band as advisory until AOA-PROBE replaces it.
  - Configuration-blind.  Flap deployment changes Cl_α and α₀; if
    we read flap position later, branch the constants.  Until
    then, calibrate against clean configuration only.
  - Weight-dependent.  Bad fuel-state estimate biases the whole
    output.  Surface the assumed weight on the profile screen.
  - Until SDP31-AIRDATA lands, "velocity" means GS — see source
    subscript above.
Work items:
  - Add airframe constants (Cl_α, α₀, S, max-gross W, flap-clean
    flag) to the V-speeds profile.  Default to Rans S21 numbers;
    pilot tunes against measured stall on first-flight cards.
  - `aoa_calc.py` runs each AHRS frame, emits `aoa_deg` and a
    `aoa_src` = `"calc"` field on the `$AHRS` packet.  When
    AOA-PROBE goes live the same field flips to `"probe"` and
    the same display consumes both.
  - Display: AOA indexer on the right side of AI when no approach
    is active (same slot AOA-PROBE will use).  Show a small `c`
    subscript on the indexer while `aoa_src == "calc"` so the
    pilot knows it's the inferred value.
Pairs with SDP31-AIRDATA (the inputs come from there) and with
AOA-PROBE (this entry retires when the probe lands, or stays as
a redundant cross-check).

### AOA-PROBE  Add a second differential-pressure transducer for AOA
Status: **OPEN — bundled into the rev B board spin alongside the
MS4525DO airspeed swap**
Target: hardware (rev B board), new `firmware/ms4525.py`, additions
to the `$AHRS` packet, AOA indicator on `pi4/pfd.py` and the iPhone
display.
Context: with one differential-pressure transducer doing pitot/static
(SDP31-AIRDATA), a second sensor connected to a flush-port AOA probe
gives a real AOA signal essentially free.  Standard experimental
implementation is a two-hole probe on the wing or a side-mount on
the fuselage where the upper / lower ports sit at different angles
to the local airflow — the ΔP across them is monotonic with AOA over
the normal envelope.  AOA buys things IAS-only can't:
  - **AOA-based stall warn** — fires at the actual stall margin
    regardless of weight, bank, or load factor.  IAS-based stall
    cues only work at 1 g and gross weight (the published Vs1 is
    a lie at any other condition).
  - **Optimal-AOA cues for approach and climb** — fly the
    indexer / donut, not the airspeed.
  - **Energy management on approach** — particularly relevant
    behind a Rotax that responds slowly to throttle.
Sensor selection: **TE Connectivity MS4525DO at ±1 psi (±6 895 Pa)**.
Same part as the rev B pitot/static transducer (see SDP31-AIRDATA
"Higher-range swap path"), strapped to the alternate I²C address so
both units share the bus. Rationale:
  - **Single BOM line** covers pitot/static + AOA. One driver
    (`firmware/ms4525.py`), one stock-keeping unit.
  - **Range never saturates** in the S-21 envelope. At 130 kt cruise
    pitot dp is ~2740 Pa, AOA ΔP at typical cruise AOA is ~100–300
    Pa, AOA ΔP at stall AOA approaches 1500–2200 Pa. All comfortably
    inside ±6 895 Pa.
  - **PixHawk-grade** so there's a deep community calibration data
    set, well-known temperature-compensation behaviour, and shipping
    is cheap.
Probe choice (decoupled from sensor — see USER_MANUAL_PI4 §21
hardware notes for the longer discussion):
  - **AlphaSystems Eagle AOA probe head** is the experimental
    standard. Two ports, pre-calibrated geometry, mounts under the
    wing on a riblet. Pair with the second MS4525DO. ~$150 for just
    the head (no electronics).
  - Cheap alternative: 2-hole DIY flush probe on a brass tube glued
    into the leading-edge cap. ~$40, takes more in-flight calibration.
  - Skip the Dynon AOA pitot unless heat is required — its
    electronics aren't needed and you'd ignore them.
Work items (rev B board):
  - Drop a second MS4525DO footprint on the rev B board, address
    strapped to the alternate slot (0x36 for the AOA twin if pitot
    sits at 0x28, or vice versa). Same package, same 3V3/GND rails,
    same I²C bus as the pitot transducer.
  - Two silicone-hose nipples next to the AOA sensor for the probe
    pair (upper / lower).
  - Pick + mount the AOA probe head (AlphaSystems Eagle preferred).
  - Build `firmware/ms4525.py` covering both units, instantiated
    twice in `main.py`. AOA math = calibration curve (linear over
    the cruising range, departs near the stall — fit on
    first-flight data, persist coefficients to flash).
  - `aoa_deg` and `aoa_src` fields added to `$AHRS` JSON. The
    pre-probe AOA-CALC entry already reserves the same fields, so
    the display path needs no rewrite — `aoa_src` flips from
    `"calc"` to `"probe"` when the hardware lands.
  - Display: AOA indexer on the right side of the AI when not on
    approach (mutually exclusive with the VDI from the recent work
    — VDI takes priority during approach, AOA at all other times).
    Standard cue: green/yellow/red segments with a fast-erecting
    diamond, donut at on-speed.
Pairs with SDP31-AIRDATA (same MS4525DO driver covers both) and with
AHRS-GPS-AID (AOA-based stall warn is the safety-of-flight payoff
once attitude is honest).

---

### #17  iPhone airport overlay — symbols + labels + download screen
Status: **OPEN**
Target: `iphone_display/` — new `airports.js` module, additions to
`index.html` for the AI overlay, and a new download/manage panel
plumbed into the setup menu next to TERRAIN.
Context: Pi4 has full airport support — `airports.py` parses the
OurAirports CSV into a numpy cache, `draw_airport_symbols()`
renders them as projected symbols on the AI with S/M/L filter,
`draw_airport_data()` is the dedicated data screen with download
controls, and the status badges include NO APT / EXP APT. iPhone
has none of this. The data set is ~3 MB (from `fetch_airports.sh`,
~80K airports worldwide), so it ships from the same upstream
(`davidmegginson/ourairports-data`) that pi4 already uses.
Work items:
  - **Data**: convert the airports + runways CSVs into a compact
    browser-loadable form (JSON shards by lat/lon tile, or a single
    binary blob with a header index — match what terrain.js does
    so the cache + service-worker story is consistent).
  - **airports.js module**: Terrain-style API:
    `Airports.init()`, `Airports.downloadGlobal(progressCb)`,
    `Airports.downloadRegion(lat, lon, radiusNm, progressCb)`,
    `Airports.nearby(lat, lon, radiusNm)`, `Airports.tileCount`,
    `Airports.status`. Use IndexedDB (or the same Cache API
    terrain.js uses) so it survives offline.
  - **Marker on AI**: `Airports.render(ctx, D, L)` called after
    `Terrain.render` and before the tape overlays — projects each
    nearby airport via the same focal/yaw/pitch/roll math the
    terrain mesh uses (factor that out into a shared helper if
    it isn't already). Render as a simple "signpost": small
    vertical pole with the ICAO identifier next to it. No
    paved/unpaved/heliport symbol distinction — just the post
    and the label, same shape for every airport.
  - **Type + size filter**: carry over pi4's four type toggles
    (`show_public`, `show_heli`, `show_seaplane`, `show_other` —
    public covers S/M/L by longest runway). Pi4-only `show_runways`
    and `show_centerlines` are skipped since iPhone only renders
    the signpost. The marker stays the simple post regardless of
    type/size; the filter just controls which airports appear.
    Persist all toggles to localStorage.
  - **Download/manage screen**: new "AIRPORTS" entry in the setup
    menu mirroring TERRAIN. Two buttons (Global / Regional),
    progress bar, count display, last-updated timestamp, clear
    cache button. Reuse the existing terrain panel CSS so it
    looks like a sibling, not a one-off.
  - **Status indicators**: NO APT / EXP APT badges in the same
    row as the GPS / link badges, mirroring pi4's `_AMBER`
    convention so the displays stay visually aligned.
  - Decide whether airport data should auto-download on first
    install (PWA add-to-home-screen), or be opt-in like terrain.
    Probably opt-in for the global set, auto for the
    home-airport-region.

---

### MAGCAL-PIZ-TUMBLE  Port pi4's hard-iron tumble mag-cal flow to pi_zero
Status: **OPEN — pi4 done, pi_zero pending**
The hard-iron tumble pass (PR #7 / commits a560924, 8280f68, 51705cd)
landed on pi4 + firmware in last session's main merge.  pi_zero's cal
modal still has the older 8-cardinal-only flow with no TUMBLE button.
Needed:
  - Cal modal: replace RESTART button with TUMBLE / STOP TUMBLE
  - Live elapsed + per-axis spread readout during tumble
  - Wire /magoff?action=tumble_start|tumble_finish HTTP endpoints
    (or the same over USB serial) — the Pico side already exists
  - State plumbing: _magtumble_active gate + _mag_cal_tumble_tick
Reference: pi4 implementation in pi4/pfd.py and firmware/main.py.

### DATA-USB-BUNDLER  Desktop "data update" tool + Pi-side USB ingest
Status: **OPEN — deferred until in-aircraft refresh becomes painful**
Long-term goal: mirror how certified avionics (Garmin G3X, Dynon,
Avidyne) do 28-day cycle updates.  Pilot runs a desktop app at home
with real internet, it builds a complete data bundle, writes to a
labeled USB stick.  At the hangar the pilot inserts the stick into
each Pi; a small daemon detects the mount, rsyncs the bundle to the
runtime data dir, validates the manifest, restarts pfd.service.
Both displays get the same data without needing any in-aircraft
network.

Bundle contents (all generation already exists, just needs glue):
  - airspaces.json          via tools/build_airspaces_us.py
  - SRTM .hgt tiles         via tools/compact_srtm.py
  - airports cache (.npy)   via shared/airports.py
  - obstacles cache         via shared/obstacles.py
  - water tiles             via tools/build_water_tiles.py
  - Natural Earth .npz      via shared/natural_earth.py
  - manifest.json           cycle date + per-source version stamps

Desktop app: probably Python tkinter or PyQt, cross-platform.  Could
also ship as a CLI for power users.  Reuses the existing converter
modules in tools/ + shared/ — no duplication.

Pi-side ingest: systemd path-unit watching /media/pfd-data/, rsync
into data/, atomic-replace each cache, systemctl restart pfd.service.
~100 lines.

When to build: as long as the in-Pi DOWNLOAD buttons work in the
hangar with whatever LTE/WiFi is available, the existing flow is
fine.  The moment a 28-day cycle update at the airport is a real
pain (slow LTE, no signal, can't sit and wait), build this.

### DEPLOY-RSYNC  Friend-friendly deploy story (rsync recipe)
Status: **OPEN**
Multiple friends will be setting up displays — current workflow has too
many manual steps.  Consolidate into one place:
  - SRTM3 hand-off: `tools/compact_srtm.py --output-dir` on pi4 →
    rsync to pi_zero (already implemented; document the recipe)
  - Water masks hand-off: rsync pi4's `data/water/` → pi_zero
  - State-lines cache: rsync pi4's `data/natural_earth/` → pi_zero
    (pi_zero won't need pyshp at all in this mode)
  - Single bootstrap script that takes a pi4 hostname and does all
    three rsyncs end-to-end
End-state: friend boots a fresh pi_zero, runs one command, has
working terrain + water + state lines without doing any Mapzen
downloads.

### DOCS-SWEEP  README + user manual refresh
Status: **OPEN — recurring**
Last session landed PR #8 (77 commits, screen sync, MFD parity, Pico
2W, IAS enable, mag-cal tumble, terrain backdrop, etc.).  Manuals
and README don't yet cover:
  - Screen sync setup + per-category TX/RX UX
  - MFD MAP LAYERS row + AIRPORT DATA type filters
  - Pico 2W (RP2350) BOOTSEL + UF2 flow
  - COMPACT button + tools/compact_srtm.py
  - TUMBLE mag-cal flow + when to use it
  - Updated zoom ladder (1/2/5/10/20/40/80/160/AUTO) on pi_zero MFD
  - Heading-source AUTO + 3 kt threshold
README needs the deploy story from DEPLOY-RSYNC once that's nailed.
Done this session (winds/FPV + weather/traffic): both pilot manuals now
cover the **flight-path vector**, **winds aloft (WND)**, the full
**weather suite** (RADIO/AUTO/INET sources, OVLY cycle, MET page with
the METAR/TAF/AIRMET/SIGMET/NOTAM readout picker, graphical
AIRMET/SIGMET, NEXRAD), **traffic** (diamonds/threat/TFC/detail-card/
declutter + collision alert), the **full-screen MFD** chrome, and the
**NOTAM** key fields.  `ADSB_IN.md` shipped items moved to Implemented;
`README.md` roadmap refreshed.  iPhone manual covers the FPV.
Also done (full-update pass): **Pi 4 / Pi 5** reframe + the three
**display profiles** (roadom_7 / roadom_10 / waveshare_35) in pi4 §1 and
README; **Screen Sync** setup (pi4 §12A, pi_zero §12); **TUMBLE**
hard-iron mag-cal (pi4 §11); **COMPACT** + `tools/compact_srtm.py`
(pi_zero §14, pi4 §14); **Pico 2W** BOOTSEL/UF2 flashing + the
**multi-display deploy (rsync)** recipe + winds-sharing note (README);
**flight-path-vector** preview wired into the render tool, with image
refs + a live-capture catalog for the WND/MET/TFC/MFD shots in
`pi4/previews/README.md`.
Still pending: only the internal **REQUIREMENTS_* / TEST_PROCEDURE_***
docs (architectural/QA, not pilot-facing) and **regenerating the actual
preview PNGs** on a Pi (the cloud box has no display/GL — run
`tools/regen_previews.sh` + the live `fbgrab` captures).

### SYNC-CACHES-PI4-TO-PIZ  Push water + state-line caches pi4 → piZ
Status: **OPEN — covered by DEPLOY-RSYNC but worth tracking**
On users who have both displays, pi4 already does the heavy lift
(downloading Natural Earth, pyshp water-mask rasterisation, etc.).
Pi_zero should be able to pull the cooked `data/water/` and
`data/natural_earth/` from pi4 over the network — no need to repeat
the work or even install pyshp on pi_zero.  Subset of the
DEPLOY-RSYNC story; included here as a standalone item in case it
gets implemented as an in-app "Sync from pi4" button instead of a
bare rsync.

### FPV-PIZ  Port the flight-path-vector marker to pi_zero
Status: **OPEN — pi4 + iPhone done (see FPV), pi_zero pending**
Target: `pi_zero/pfd.py` AI overlay block (~the
`draw_airport_symbols` / `draw_obstacle_symbols` SRCALPHA-rotate path).
Context: pi4 + iPhone shipped the FPV marker (see the FPV entry). pi_zero
draws its AI symbol overlays into a roll=0 SRCALPHA surface that is then
rotated whole by `pygame.transform.rotate(_overlay, roll)`, rather than
the per-feature roll rotation pi4 uses. Dropping the FPV into that
overlay would rotate the *symbol* with the bank too, which isn't the
convention (the FPV glyph should stay upright). Port options:
  - Compute the FPV screen position the pi4 way (rel-bearing + FPA →
    px, manual roll rotation) and blit the upright glyph directly onto
    `surf` after the rotated overlay, OR
  - Draw it into the overlay but counter-rotate the glyph by `-roll`.
Reuse the same 5 kt gate, cyan colour, circle+wings+stub geometry, and
edge-clamp ghost arrow. Add the `fpv_enabled` toggle to pi_zero's
display-settings screen for parity.

### NAVDATA-FAA  IFR nav-data foundation — fixes, airways, navaids, procedures
Status: **IN PROGRESS — runtime module + cache schema + query API + FAA build
tool DONE; UI consumers next.  Build tool needs a real 28-day NASR+CIFP run to
confirm CIFP column offsets before shipping a cache.**
Done:
  - `shared/navdata.py` (+ `shared/test_navdata.py`, 24 checks) — `NavData`
    holds lat-sorted fix/navaid structured arrays + airway/procedure/hold
    dicts + 28-day `cycle` stamp; queries `fix`/`navaid`/`waypoint`,
    `nearby_fixes`/`nearby_navaids` (searchsorted band, nearest-first),
    `airway`/`airway_between`, `procedures_for`/`procedure`, `hold`; `load()`
    degrades gracefully on a missing/partial cache.  Cache layout
    (`navdata_fixes.npy`, `navdata_navaids.npy`, `navdata.json`) documented in
    the module docstring.
  - `tools/build_navdata_us.py` — FAA NASR CSV (FIX_BASE/NAV_BASE/AWY_SEG) +
    CIFP (FAACIFP18 ARINC-424) → that cache.  NASR path resolves columns by
    header name (cycle-tolerant); CIFP path parses approaches/SIDs/STARs +
    enroute holds with named, tunable column offsets and a `--dump-cifp`
    debug mode, resolving each leg's lat/lon from the NASR arrays at build
    time.  `--verify` loads the result back through `shared/navdata.py`.
    Smoke-tested end-to-end on synthetic NASR+CIFP; column offsets must be
    confirmed against a real FAACIFP18 (run `--dump-cifp 20` and eyeball).
  - `NAVDATA_DIR` wired into `pi4/config.py` + `pi_zero/config.py`
    (`data/navdata/`).
  - New **DATA & MAPS** setup page (`downloads_setup`, both renderers) — one
    home for every downloadable dataset (TERRAIN / OBSTACLES / AIRPORTS /
    AIRSPACE / NAV DATA), each a roomy tile routing to its existing management
    subscreen.  Pulled the cramped 4-tile row out of SYSTEM (reclaimed space).
    Added a **NAV DATA** subscreen (`navdata_data`) with a real download flow
    (`_nd_load`/`_nd_start_download`, mirrors the airport/airspace fetch):
    pulls the three cache files from `navdata.DOWNLOAD_BASE_URL` (configurable
    in `config_local.py`; greyed "no source configured — copy to data/navdata/"
    until set, since the cache is built off-aircraft).  `navdata.cache_stats()`
    feeds the status line; cache loaded at startup + on entry.  Both renderers
    verified headless (`--ss-mode`).
Still TODO: a real-data build to validate CIFP offsets; then the UI consumers
(see NAV-FIXES-AIRWAYS-DISPLAY / FPL-APPROACHES / FPL-HOLDS below).
Publishing path DONE: `tools/publish_navdata.sh` (laptop + `gh`) or the new
`.github/workflows/publish-navdata.yml` (browser/iPad — Actions → "Publish nav
data" → Run workflow, paste the FAA NASR + CIFP ZIP URLs) build the cache and
push it to the fixed `navdata` release the in-app DOWNLOAD button pulls from.
Target: new `tools/build_navdata_us.py` (28-day converter, mirrors
`tools/build_airspaces_us.py`), new `shared/navdata.py` parser + spatial
query (mirrors `shared/airports.py`), runtime cache under
`data/navdata/`.
Data-access answer (the open question on approach fixes + victor
airways): **yes, all of it is available for free, US-only.** Two FAA
28-day subscription products cover everything the FPL items need —
none of it is in the OurAirports CSVs we ship today:
  - **FAA NASR** (National Airspace System Resource, 28-day
    subscription, free at the FAA ADDS / NASR portal) — the `FIX`
    file gives named intersections/fixes with lat/lon; the `AWY`
    file gives Victor (low) and Jet (high) airways as ordered fix
    sequences; the `NAV` file gives VOR/NDB/DME navaids (also in
    OurAirports `navaids.csv` if we want a global-but-navaid-only
    fallback).
  - **FAA CIFP** (Coded Instrument Flight Procedures, ARINC 424 /
    "424-18" fixed-width, 28-day, free at the FAA CIFP download) —
    carries SIDs, STARs, **approaches** (with transitions + final
    approach fix), **missed-approach** legs, and **holding-pattern**
    definitions (`PI`/`HM`/`HF`/`HA` leg types) keyed to airport +
    procedure ident.
Scope decision (pilot): **US-only is accepted** for all the IFR FPL
items — no need to chase a global procedure source. Still surface it
in the UI: gate the IFR features behind a "NAVDATA loaded" badge (same
pattern as NO APT / EXP APT) so it degrades gracefully outside US
coverage rather than silently showing nothing. Note these build on
the **synthetic glideslope already drawn on an active direct-to**
(`disp["nav"]`, ~line 415–427) — FPL-APPROACHES generalises that
hand-built threshold guidance to a published procedure.
Distribution: too big + procedural to
fetch in-aircraft cleanly — strong candidate to ride the
DATA-USB-BUNDLER pipeline (add `navdata` to the bundle manifest)
rather than an in-Pi DOWNLOAD button.
Work items:
  - `tools/build_navdata_us.py`: parse NASR FIX/AWY/NAV + CIFP into a
    compact numpy/JSON cache (sorted by lat for `np.searchsorted`
    spatial query, same trick as airports/runways).
  - `shared/navdata.py`: load + spatial-query API — `nearby_fixes`,
    `airway(ident)`, `navaid(ident)`, `procedure(airport, ident)`,
    `hold(fix)`. Shared by pi4 + pi_zero + (later) iPhone.
  - Decide cache format + manifest stamp (28-day cycle date) so a
    stale-data badge can be shown.
This entry is the prerequisite for NAV-FIXES-AIRWAYS-DISPLAY,
FPL-APPROACHES, and FPL-HOLDS below.

### NAV-FIXES-AIRWAYS-DISPLAY  Approach fixes + Victor airways on map/AI
Status: **OPEN — blocked on NAVDATA-FAA**
Target: `pi4/moving_map.py` + `pi_zero/moving_map.py` (new fix/airway
layers), `pi4/pfd.py` + `pi_zero/pfd.py` MAP LAYERS row, optional
fix symbols projected onto the AI via the airport-projection helper.
Context: once `shared/navdata.py` exists, render named fixes
(intersection triangles + ident labels) and Victor airways
(thin lines along the fix sequence, with airway ident) on the
moving-map inset / MFD. Mirrors the existing polyline + symbol layers.
Work items:
  - New `_draw_fixes` + `_draw_airways` in `moving_map.py` (reuse the
    vectorised `_draw_polylines` for airways; fixes are point symbols
    like obstacles/airports).
  - Two new pills on the MAP LAYERS row (FIX / AWY), persisted with the
    rest of the layer toggles. Gate display ≥ a sensible zoom so fixes
    don't clutter wide views.
  - Fixes become selectable waypoints for the FPL editor (feeds
    FPL-APPROACHES — a fix ident resolves to lat/lon via navdata).
  - iPhone parity deferred (same pattern as the #17 airport-overlay
    port).

### FPL-APPROACHES  Approaches + missed approaches in flight plans
Status: **OPEN — blocked on NAVDATA-FAA**
Target: pi_zero FPL editor (`pi_zero/pfd.py` — it owns FPL editing
today; pi4 renders the active leg via the synced `disp["fpl"]`),
`disp["fpl"]` schema, screen-sync `KIND_FPL`, the direct-to / leg
sequencer (`_fpl_is_active`, `_fpl_check_advance`,
`_FPL_ADVANCE_DIST_NM`).
Context: today an FPL is a flat list of waypoints with a simple
distance-gated auto-sequencer. Loading a CIFP **approach** appends its
ordered leg sequence (transition → IAF → IF → FAF → MAP) to the
active plan, and the **missed approach** is held as a separate
segment that the sequencer only arms past the MAP / on a pilot
"activate missed" action. The system already auto-points the
direct-to at a runway threshold and draws a glideslope on approach
(see `disp["nav"]` notes ~line 415–427) — this generalises that to a
published procedure.
Work items:
  - Extend the FPL schema: a waypoint gains an optional `leg_type`
    (ARINC-424 path/terminator: TF/CF/DF/RF…) and a `segment` tag
    (`enroute` / `approach` / `missed`). Keep flat-list back-compat so
    existing saved plans still load (`fpl_saved` is `[{name,
    waypoints}]`).
  - FPL editor: "LOAD APPROACH" picker (airport → approach ident →
    transition) that pulls legs from `navdata.procedure(...)` and
    appends them; "ACTIVATE MISSED" control that switches the
    sequencer onto the missed segment.
  - Sequencer: honour leg types enough to fly the common cases (TF/CF
    as great-circle-to-fix is most of GA IFR); don't attempt full
    ARINC-424 leg geometry on day one — document which leg types are
    approximated.
  - Screen sync: the richer schema rides the existing `KIND_FPL` /
    `KIND_FPLLIB` channels — bump a schema version so a peer on the
    old schema degrades to the flat waypoint list instead of choking.
  - Render: pi4 + pi_zero draw the approach legs distinctly from
    enroute (e.g. dashed for missed), FAF/MAP labelled.

### FPL-HOLDS  Holding patterns
Status: **OPEN — blocked on NAVDATA-FAA**
Target: same FPL path as FPL-APPROACHES, plus a racetrack-geometry
helper in `moving_map.py` and a hold-entry cue.
Context: holds come from CIFP (`HM`/`HF`/`HA` leg types: hold-to-
manual-termination / -to-fix / -to-altitude) keyed to a fix, and a
pilot may also build an ad-hoc hold at any fix (inbound course, turn
direction, leg length/time). Render the racetrack on the moving map
and sequence the FPL through it.
Work items:
  - Hold definition: fix + inbound course + turn direction (L/R) +
    leg length (nm or time). Pull published holds from
    `navdata.hold(fix)`; allow a manual hold dialog for the ad-hoc
    case.
  - Geometry: racetrack polygon (two semicircles + two straights)
    computed from the hold params, drawn on the inset/MFD; own-ship
    chevron shows progress around it.
  - Entry guidance: classify direct / teardrop / parallel from the
    inbound heading vs hold course and show the recommended entry —
    nice-to-have, can ship the racetrack draw first.
  - Sequencer: a hold leg does NOT auto-advance on the
    `_FPL_ADVANCE_DIST_NM` gate; it loops until the pilot taps
    "EXIT HOLD" (then resume the next leg). This is the one place the
    existing distance-gated sequencer needs a real state change.

### PIZ-APPROACHES  Published approaches on pi_zero (parity with pi4)
Status: **DONE — piZ consumes + renders a synced approach AND loads its own**
LOAD-on-piZ shipped this session:
  - **Runway DB on the Zero**: `pi_zero/pfd.py` now loads `runways.csv` (same
    OurAirports source as the Pi 4) into `_runways` and downloads it alongside
    `airports.csv` on the AIRPORT DATA screen.  Data-only — used to resolve the
    landing threshold (lat/lon + authoritative field elevation); the map still
    does NOT draw runway polygons / centerlines (panel stays uncluttered).
  - **Loader + pickers**: ported `_approach_load_published`, the leg dedupe /
    missed-split helpers, fly-by `_approach_check_advance` sequencing, and the
    SELECT APPROACH → TRANSITION pickers (`_prc_*` scroll list) + a self-
    contained schematic **APPROACH PREVIEW** (no terrain map).  Entry is the
    3-state LOAD APPR / ACTIVATE / CANCEL button on the FPL screen (off the
    destination).  Flies the legs on the existing raw CDI (no SVT/HITS/VDI).
  - **Publish parity**: the Zero now PUBLISHES `KIND_APPR` (was consume-only),
    so a load on ANY screen mirrors to the others (last-write-wins).
  - **Re-alignment after resets**: a low-rate `_ssync_state_keepalive()` on both
    pi4 + piZ re-announces the loaded approach / active FPL / bare direct-to so a
    screen that just powered up re-syncs within a few seconds.  Only screens that
    HAVE state announce (a blank booted screen can't clobber a peer under LWW).
Context: the published-approach work (LOAD APPR picker, transition/IAF picker,
preview, leg sequencing, missed + holds, HITS/VDI) lives in `pi4/pfd.py`.  A
pi_zero MFD on the same network RECEIVES the approach over screen sync
(KIND_APPR is in shared/screen_sync.py); previously `pi_zero/pfd.py` had no
consumer or renderer, so the approach didn't draw on piZ.  Done this session:
  - **Consumer**: `_ssync_apply_approach` (mirrors pi4) stores the synced
    procedure into `disp["approach"]`; KIND_APPR is registered on piZ and added
    to the FPL-gated consume set (piZ has no approach loader, so it only
    consumes — it never re-publishes KIND_APPR and can't clobber pi4's load).
    When the approach is active the active leg is mirrored into `disp["nav"]`
    so the existing **raw CDI** tracks it (no SVT/HITS on piZ, per pilot).
  - **Renderer**: `pi_zero/moving_map.py` now draws `approach_path` (cyan
    polyline + fix diamonds/labels), `runway_marker` (a course stub — piZ
    carries no runway DB), `missed_path` (dashed amber), and `holds`
    (racetracks).  Ported the pi4 helpers (`_dashed_polyline`, `_place_label`,
    `_hold_racetrack_pts`, `_MISSED_AMBER`).  Holds re-derive from piZ's own
    `_navdata`.  Render-arg builders (`_approach_render_path/_missed/_holds`,
    `_appr_runway_marker`) mirror pi4 and read only the synced state.
  - **(Stretch, still OPEN)** the LOAD APPR flow itself on piZ so an approach
    can be selected there, not just received.
Lower priority than the build-data cleanup; the pi4/pi5 PFD is the approach
display and piZ is a secondary map.

### NAVDATA-BUILD-CLEANUP  Fix approach legs in the build, not at runtime
Status: **OPEN — runtime works around a dirty cache; clean the cache instead**
Context: the CIFP cache has artifacts the runtime currently papers over every
frame.  Per flight-test (KFLG RNAV 03), the raw `final` is
`['SEZCY','TOHQU','TOHQU','YEDUV','RW03','·(CA)','TAWNE']` — i.e. a **doubled
fix** (TOHQU TOHQU), a **no-coord climb leg** (CA/VA/FA), and the **missed
approach folded into `final`** after the MAP (RWxx).  `pi4/pfd.py` cleans all
this at load time: `_appr_dedupe` (drop consecutive same-ident), `_appr_leg_pts`
(drop no-coord legs), and a runtime MAP-split at the `RWxx` fix to peel the
missed off `final`.  That's the right *display* but the wrong *place* — do it
once in `tools/build_navdata_us.py` so the cache is clean and the runtime is a
straight read.  Build-side fixes:
  - **Dedupe** consecutive same-fix legs when writing each segment.
  - **Split missed properly**: CIFP flags the missed via the common-route's
    route-type 'M'; track per-leg route type (we already read col 20) and route
    those legs to `missed` instead of the heuristic "everything after RWxx".
  - **Climb/no-fix legs** (CA/VA/FA): keep the leg (course+alt drive the missed
    climb-ahead render) but mark it so the runtime needn't infer; the runtime
    already synthesises the climb point off the MAP course.
  - Re-confirm **SID/STAR classification** (type=SID/STAR via subsection D/E) so
    the approach-list name+type filter can eventually relax.
Once the cache is clean, the runtime `_appr_dedupe` / MAP-split can be dropped
(or kept as cheap belt-and-suspenders).  Rebuild + re-run `tools/diag_navdata.py`
to verify each procedure reads clean.

### DEPARTURES-PICKER  SID/STAR selection (own section, not the approach list)
Status: **OPEN — SIDs/STARs are parsed + cached; just not selectable yet**
Context: the approach picker now filters to approaches only (by type + name), so
departures (e.g. FLG ONE) no longer pollute it.  But the SIDs/STARs ARE in the
cache and should be selectable — under their own DEPARTURE / ARRIVAL section
(off the FPL origin for SIDs, the destination for STARs), loaded onto the plan
like approaches.  Mirror the appr_proc_select / transition / preview flow with
`_navdata.procedures_for` filtered to type SID (origin) / STAR (destination).

### INFO-VIEWER  Airport / approach / navaid data viewer
Status: **OPEN — data is in hand; this is a display feature**
Context: the NAVDATA-FAA cache + the OurAirports DB already carry far more
than we surface today. Build a tappable info viewer (tap an airport / navaid /
fix → a detail card) showing the rich data:
  - **Navaid frequencies** — already in `navdata_navaids.npy` (`freq`, `name`,
    `ntype`); surface VOR/VORTAC/NDB freqs on the map tap + a navaid card.
  - **Airways** — log/keep the CIFP enroute `R` records (19k in the file); the
    NASR `AWY_BASE.csv` `AIRWAY_STRING` is the other source. Build the
    `tools/build_navdata_us.py` airway parser (deferred earlier) so V/J routes
    can draw (ties into NAV-FIXES-AIRWAYS-DISPLAY) and list in the viewer.
  - **Airport card** — runways (length/surface/lighting), elevation, published
    approaches (from `navdata.procedures_for`), and — once parsed from NASR —
    CTAF/TWR/GND/ATIS comm frequencies + AWOS/ASOS.
  - **Approach card** — the procedure's legs, FAF, MAP, missed, minimums (CIFP
    has the altitudes; minimums proper need the CIFP `S…P…F` continuation /
    minima records — investigate).
Probably its own full-screen viewer reachable from a map/airport tap, plus the
inline navaid-freq display as a quick first win.

### VNAV-ADVISORY  Vertical guidance from FPL / approach crossing altitudes
Status: **OPEN — lateral guidance + altitude display already shipped**
Context: we already fly lateral guidance (CDI) and show each approach fix's
published crossing altitude in the plan (`_appr_alt_label`); the final approach
already drives a VDI glideslope to the threshold. Extend that to a real
advisory vertical path off the crossing altitudes, with two visual levels by
context (pilot's call):
  - **Enroute (pilot-entered altitudes): VDI only — no boxes.** Add a per-
    waypoint target-altitude entry on the FPL (a field per row / via the leg
    menu), compute a vertical path between altitude-constrained waypoints
    (glidepath angle + top-of-descent), and drive the VDI to it. No HITS
    corridor enroute (just the deviation needle).
  - **Approach (published altitudes): VDI + HITS boxes.** Use the CIFP leg
    altitudes (already parsed) to build the descent path through the whole
    procedure (not just the final glideslope today) and render the HITS
    highway-in-the-sky corridor along it, with the VDI.
Work items:
  - Vertical-path model: given altitude-constrained legs + groundspeed, compute
    the target altitude at the current along-track distance + the deviation
    (above/below) for the VDI; flag top-of-descent.
  - Enroute alt entry: numpad on a FPL waypoint (leg menu → "SET ALT"), store
    on the waypoint dict, persist with the plan; show it on the row like the
    approach legs do.
  - Approach: drive the existing HITS renderer along the published descent path
    (currently HITS is only the final-segment corridor); VDI follows the path
    through the step-downs, not just the runway glideslope.
  - Honor constraint types (at / at-or-above / at-or-below / window) when
    building the path — don't descend below an at-or-above floor.

## Completed

### SENTRY-INTEGRATION  uAvionix/ForeFlight Sentry as a GDL90 source
Status: **WON'T DO — investigated, dead end (encrypted), code reverted**
A full Sentry was bench-tested.  It does broadcast GDL90 on UDP 4000 and the
Pi receives it fine (~31 datagrams / 6 s, no handshake needed), BUT every
frame is a **proprietary uAvionix/ForeFlight message** — IDs **0x25 (37)** and
**0x26 (38)** — carrying **encrypted** payloads (high-entropy, variable
length, multiplexing traffic/AHRS/GPS).  The Sentry config page
(`http://192.168.4.1`) exposes only WiFi/LED/CO/power settings — **no toggle
to disable encryption or emit standard GDL90**.  uAvionix and ForeFlight both
**refuse to document** 0x25/0x26 (co-developed, proprietary); the public
"Reversing the Scout" effort has **not** decoded them and there is no known
decoder.  ForeFlight Connect is the *inbound* spec (device → ForeFlight on
4000; ForeFlight announces on 63093) so the iPad can't be used as a bridge to
re-emit the data either.  Net: **the Sentry cannot feed this (or any
non-ForeFlight) display — it's a walled garden.**  Conclusion: use the WT901
for AHRS (better anyway) and an *open* GDL90 receiver (Stratux / dump978) for
radio traffic + weather.  The exploratory work — a ForeFlight `0x65` AHRS
decoder, an AHRS source selector, and a Sentry attitude/GPS feed with a LEVEL
button across pi4 + pi_zero — was correct against the public spec but useless
against the encrypted stream, so it was reverted (commits b06bddc / b34a738 /
7d659fc).  NOTE: the public ForeFlight `0x65` spec was captured here in case a
future *open* ForeFlight-protocol source is added — roll: 1/10° positive =
right-wing-down; pitch: 1/10° positive = nose-up; heading bit15 0=true/1=mag,
1/10°; IAS/TAS knots; all 0x7fff/0xffff = invalid.  An **open-receiver**
(Stratux / dump978) path is the supported way to get radio data — worth a new
entry if pursued.

### TINT-SHIMMER-PAN  Terrain tint shading shifts a bit on a pan + density bump
Status: **DONE (pi4 + pi_zero) — verify the slow-pan on the Pi 5**
Resolution: `_build_tint_pixels` now **world-anchors the sample lattice** —
the grid's top-left corner snaps to a fixed global multiple of the per-sample
spacing (`dlat = span_lat/(n-1)`, `dlon = span_lon/(n-1)`), so consecutive
builds sample the SAME absolute lat/lon points wherever their windows overlap
and a pan slides a stable field instead of re-sampling (numeric check: a pure
E pan keeps all N lat samples identical and N−1/N lon samples, only the new
edge column sliding in).  The anchored grid centre (`a_lat, a_lon`, up to half
a sample off the aircraft) is threaded back through `_build_tint` /
`_tint_async_worker` / `_tint_get` (cache value + `_tint_ready` entries are now
`(surface, elev, a_lat, a_lon)`) and the inset blits at `_project(a_lat, a_lon)`
so registration stays exact across a cell-boundary snap.  Density: `_TINT_N` is
**64 on pi4 (Pi 5)** / **48 on pi_zero** as agreed.  Both files compile; the
Pi-5 slow-pan visual check is the only thing left (no GL here).  Original
report below.
After the tint registration fix (scale + projected-quantised-centre blit),
the tint sits in the right place and no longer jumps several NM, but the
hypsometric *shading* still "pops" a little at each cell crossing while
panning.  Cause: the 48×48 sample grid (`_TINT_N`) is anchored to the
aircraft's quantised centre, so each rebuild re-anchors the grid and the
coarse shading re-samples onto shifted points (a peak sampled or not, a
water edge moved by a sample).  Position is correct; it's the *sampling
lattice* shifting per rebuild.
Fix: **world-anchor the sample lattice** — snap the grid's top-left to a
fixed multiple of the sample spacing (`dlat = span_lat/(n-1)`,
`dlon = span_lon/(n-1)`) in `_build_tint_pixels` so the SAME absolute
lat/lon points are sampled regardless of pan; consecutive (quantised)
builds then sample identical points where the windows overlap, so panning
slides a stable field with no pop.  The anchored grid centre differs from
the quantised centre by up to half a sample, so thread the true centre
(`a_lat, a_lon`) back through `_build_tint` / `_tint_async_worker` /
`_tint_get` (cache value becomes `(surface, elev, a_lat, a_lon)`) and blit
at `_project(a_lat, a_lon)` so registration stays exact.  Lat lattice is
fully world-stable; lon spacing depends on `cos(lat)` so it's world-stable
to within a hair over a few cells — fine.
Density: also bump `_TINT_N` 48 → **64** on the Pi 5 (pilot's call) for
crisper mountains/coastlines — the extra samples are cheap reads from
already-loaded tiles, just more smoothscale per build.  Gate it by platform
(keep 48 on the 2 GB Pi 4 unless confirmed it doesn't tax it; Pi 5 fine).
Apply to both `pi4/moving_map.py` and `pi_zero/moving_map.py`.  Verify on
the Pi 5 (a slow pan should show terrain sliding smoothly, no shading pop).

### DISPLAY-SETUP-SPLIT  Break the DISPLAY setup screen into 3 tabbed pages
Status: **DONE (pi4 + pi_zero, headless-verified)** — the screen is now three
tabbed sub-pages (UNITS / DISPLAY / MAP) with a 3-segment tab bar under the
header; each page fits with no scrolling.  Grouping as agreed:
  - **UNITS** — SPEED UNITS, ALTITUDE, PRESSURE
  - **DISPLAY** — BRIGHTNESS, ALERT AUDIO, ALERT VOLUME, SUN POSITION,
    FLIGHT PATH (pi_zero: BRIGHTNESS, NIGHT MODE)
  - **MAP** — MAP INSET (+TRK↑/N↑), MAP RANGE, WINDS ALT, TFC ALT, TFC RANGE,
    then the tall MAP LAYERS multi-toggle
Implementation: `_DSP_ROWS` split into `_DSP_ROWS_UNITS/_DISPLAY/_MAP` +
`_DSP_TAB_ROWS`; draw + hit iterate the current tab by LOCAL index via a
shared `_dsp_row_y()` (offset below the tab bar, no scroll), `_dsp_tab_geom`/
`_draw_dsp_tabs`/`_dsp_tab_hit` for the bar, `disp["dsp_tab"]` holds the tab
(reset to 0 on entry, not persisted).  MAP LAYERS draws at
`_dsp_row_y(_DSP_LAYERS_ROW_LOCAL_INDEX)` on the MAP tab only.  A `tab:<id>`
action is handled in the `display_setup` dispatcher; `display_setup` removed
from `_SS_DRAG_MODES` and `_dsp_max_scroll()` dropped.  Both `pi4/pfd.py` and
`pi_zero/pfd.py`.
Verification: rendered all three tabs headless for BOTH displays (the setup
screen is pure pygame 2D — no GL — so the dummy-driver render is faithful to
hardware; pi4's GL-only caveat does NOT apply here).  Hit-tests smoke-checked
(tab taps → `tab:N`, row segments → `set:…`, layer pills → `set:map_show_*`,
empty area → None).  Previews regenerated: `preview_setup_display.png` (UNITS)
+ `_units` / `_disp` / `_map` in `pi4/previews/` and `pi_zero/previews/`;
manual §10 updated on both (tab description, figures, full row table).

### WX-SOURCE-DISPLAY-FILTER  Auto/Radio/Internet should filter what's drawn
Status: **DONE for NEX (pi4 + pi_zero); MET already correct; WND + TFC + AIR/SIG
carved out** — the weather-source pill (`wx_source`: auto | radio | internet)
was only gating the *pollers*, so switching to RADIO left stale INTERNET data
on screen until it aged out.  It's now a hard render-time filter where the layer
has two real sources:
- **NEX** — `_nexrad_render_arg` returns None in RADIO (hide the downloaded
  mosaic); `_fisb_nexrad_cells` returns [] in INTERNET (hide the FIS-B cells);
  AUTO shows both.
- **MET** — already filtered at the merge (`inet=[]` in radio, `rdr=[]` in
  internet).  No change.
- **WND** — carve-out: winds aloft is **internet-only** (there is no FIS-B
  winds), so it ALWAYS pre-loads and ALWAYS shows regardless of the pill — like
  the traffic sensor below, hiding the only source just blanks the layer.
  `_winds_client.enabled = True` unconditionally, and the `set_winds` store feed
  is pulled out of the `not radio_only` gate so it feeds in every mode.  (The
  first instinct was the opposite — RADIO ⇒ barbs gone — but that assumed FIS-B
  carried winds; it doesn't, so "always visible" is the right version.)
- **TFC** — carve-out (separate `traffic_source` selector).  RADIO = radio
  only, AUTO = radio+internet merged, **INTERNET still keeps radio** on purpose:
  the local ADS-B receiver is the real see-and-avoid picture and must never be
  hidden to honour a literal "internet only" (it'd suppress real, locally-sensed
  targets — unlike weather, where source is just provenance of the same data).
- **AIR/SIG — NOT filterable as-is (deferred).** The FIS-B store *dedupes*
  AIRMET/SIGMET advisories by text and graphics by geometry and stores **no
  source tag** (`add_advisory`/`add_graphic` in `shared/fisb.py`), so a radio
  and internet copy of the same NWS bulletin collapse to one.  A hard
  source-filter would need per-item source tagging + a rework of the cross-source
  dedup.  Low value (the bulletins are identical across radio/internet — it's the
  same product, so a lingering "internet" AIRMET in RADIO mode isn't *wrong*
  data), so left for a follow-up if strict consistency is wanted.
Files: `_nexrad_render_arg`, `_fisb_nexrad_cells`, and the winds enable/feed in
`_update_weather` (always-on) in both `pi4/pfd.py` and `pi_zero/pfd.py`.

### WINDS-FORECAST-SERIES  Winds roll forward to "now"; inset is always now
Status: **DONE (pi4 + pi_zero)** — winds-aloft barbs are no longer a frozen
fetch-time snapshot.  Each national-cache column now carries the forecast
**series** (per-hour `[dir,spd,temp]` flat rows out to ~30 h, stored in
`t0`/`step_s`/`series`/`alts`).  Open-Meteo already returns a 48 h forecast per
call, so the series is free; we just stopped throwing all but one hour away.
- **Retarget at draw time.** `_winds_barbs(offset_h)` and the barb-tap table
  pick the hour for `now + offset_h` via `wx.winds_levels_at()`.  The PFD inset
  passes `offset_h=0` → it is ALWAYS *now*, independent of the WND-page
  forecast-time selector.  The page passes its `winds_time_offset_h`.  A target
  outside the held window draws blank (no wrong-time forecast).
- **Re-pull on the 6 h GFS run** (`max_age_s`), not to chase "now" — the series
  advances on its own between fetches.  Changing the page offset no longer
  forces a re-fetch (instant, zero API calls); `force_refresh()` removed from
  `_mfd_cycle_winds_time`.
- **LAN sharing stays compact.** The full series is ~30× too big for one UDP
  datagram, so a feeder broadcasts a single-hour *now*-snapshot (existing
  packet format) re-derived each tick and stamped `st=now`; adopters roll
  forward as `st` advances (`ingest_packed` adopts a newer run OR a newer
  snapshot of the same run).  A relayed/frozen snapshot carries an
  un-advancing `st`, so a dead feeder can't pin the panel — deferral lapses and
  someone re-pulls.  A screen holding its own series ignores peer snapshots
  (never downgrades).
- Memory: series kept as flat int rows (~7.5 MB national, shared by reference
  into the FIS-B store), not dicts (~90 MB).  Disk persists the series.
- Files: `shared/wx.py` (`parse_open_meteo_winds(series_h=…)`,
  `_build_winds_series`, `winds_levels_at`, `_winds_cols_snapshot`,
  `_zone_packet`, `ingest_packed`, `WindsUSCache(series_h=30)`); `_winds_barbs`
  + `_draw_wx_winds` + `_mfd_cycle_winds_time` in both `pi4/pfd.py` and
  `pi_zero/pfd.py`.  Tests: `shared/test_wx_winds.py` (12 cases).
- **Self-heal on deploy.** A pre-series `conus_winds.json` (from before this
  change) has no series but looks "fresh" (< 6 h), so the cache would never
  re-pull and the `+Nh` offset would do nothing on *any* screen (and screens
  each sitting on a different stale snapshot would disagree).  `_due_zone` now
  treats a series-less zone (old disk cache OR a peer's now-snapshot) as **due**
  regardless of age, so a deploy re-pulls to populate the series and the LAN
  share reconciles the panel.  The startup gate is staggered by the per-device
  fetch jitter so a synchronised "everyone's cache is due" event doesn't hit
  Open-Meteo all at once.
- **One feeder, not three (429 fix).** Field test showed all three screens each
  fetching the same zones (the aircraft's zone first) → repeated 429s, because
  every screen wants its OWN series so its `+Nh` works.  `_due_zone` now has a
  global gate: a screen holding NONE of its own fetched series, while a peer is
  actively sharing, **stays a pure adopter and does not fetch**.  The first
  screen to pull (lowest jitter) becomes the sole feeder; the rest adopt its
  now-snapshots.  `peer_grace_s` 360→600 s so an occasional dropped broadcast
  doesn't expire coverage and trigger a redundant pull.  Consequence: `+Nh`
  works on the feeder only — the adopters need the offsets SHARED (Phase 2).
  NOTE: to elect cleanly on already-split hardware, delete `conus_winds.json` on
  every Pi and restart them together (otherwise each keeps the zones it already
  fetched).
- **DEFERRED — WINDS-SERIES-PEER-OFFSET (Phase 2):** to make `+Nh` work on the
  adopters too, the feeder must SHARE the offsets.  Measured: the full 31 h
  series zlib-compresses to ~145 KB (too big for one 64 KB UDP datagram), BUT
  the 7 discrete selector offsets {0,3,6,9,12,18,24 h} compress to **~37 KB —
  fits one datagram** (b64 in JSON ~50 KB, still under 64 KB).  Phase 2 = feeder
  packs a 7-offset bundle (zlib+b64) per zone, adopters store it offset-keyed
  and `_winds_barbs` picks the matching offset.  No chunking needed.  CAVEAT: a
  field log showed a ~7 min gap where a ~20 KB winds broadcast wasn't reaching a
  peer — the LAN may be dropping fragmented broadcasts; the bigger Phase-2
  packets would be dropped more (survivable via the 20 s re-broadcast, but check
  `screen_sync` rx/tx counters first).  The inset (now) is correct everywhere
  regardless.

### WINDS-STALE-STATUS  "6/6 loaded" was uninformative; report stale/expired
Status: **DONE** — zones refresh in place and never drop, so a loaded-count
sat at `6/6` forever.  `status()` now returns `(fresh, total, age_s, stale,
expired)`: fresh `< max_age_s` (6 h), stale `6–24 h` (drawn as a fallback),
expired `≥ expire_s` (24 h — `columns()`/`count()` stop SERVING it, drawn
blank).  Status line reads e.g. `WINDS 4/6 · 7h · 2 stale`.  `stale_zones()`
lists which.  `shared/wx.py`, status line in both `pfd.py`.

### TFC-RA-SENSITIVITY  Traffic collision alert (RA) fires too eagerly
Status: **FIXED** — closure/tau-based RA (replaces the flat ring)
`threat_level` now fires the "alert" (red / "Traffic, Traffic") tier only
when a target is **actually converging and will be close soon**: tau =
range / closure ≤ `ADSB_TAU_S` (30 s) AND within the vertical protected band
(`ADSB_ALERT_FT`) AND inside the advisory range — plus a hard floor backstop
(`ADSB_ALERT_FLOOR_NM/FT` = 1 NM / 400 ft) for anything right on top of us
regardless of closure.  Range-rate is tracked per ICAO frame-to-frame and
EMA-smoothed in `_update_traffic` (both pi4 + pi_zero) so jitter can't fake
convergence; diverging / parallel / non-closing traffic no longer trips it.
Proximate (amber) advisory unchanged at the static 6 NM / 1200 ft envelope.
Unit-tested in `shared/test_adsb.py` (`test_threat_tau`).  Original spec
retained below for reference.
Pilot report: the traffic "RA" (the `Traffic, Traffic` callout + flashing
TRAFFIC banner) feels too sensitive — it triggers on traffic that isn't
really a threat.  Today it's a pure static envelope: fires when a target
is within **ADSB_ALERT_NM = 3.0** *and* **ADSB_ALERT_FT = 600**
(`shared/config_base.py`), classified in `shared/adsb.py threat_level()`,
edge-triggered in `pi4/pfd.py _update_traffic` (~line 1807).  Real TCAS/TAS
RAs are **closure/time-based** (tau — time to closest approach), not a flat
ring, which is why a flat 3 NM/600 ft ring nuisance-trips on parallel or
diverging traffic.
**Decision (pilot): do it properly — intercept/closure-based, not a
distance ring.**  Real TAS/TCAS uses **tau** = time to closest point of
approach: alert only when the target is actually *converging* and will be
close *soon*.  Plan:
  - Track each target's **range rate** (closure) frame-to-frame (Δrange /
    Δt), and ideally vertical closure (Δrel_alt / Δt).
  - **Alert when `tau = range / closure_rate` is below a threshold**
    (~25–35 s is typical TAS) **AND** the projected miss distance / vertical
    separation is inside a small protected volume — i.e. it's both closing
    and going to be close.  Diverging or co-altitude-but-parallel traffic
    never trips it.
  - Keep a hard **floor** ring (e.g. anything inside ~1 NM/400 ft regardless
    of closure) as a backstop, and keep the **proximate** (amber) tier as the
    current static 6 NM/1200 ft advisory.
  - Smooth the range-rate (a frame or two of EMA) so GPS/ADS-B jitter
    doesn't produce phantom closure.
Touches `shared/adsb.py` (add range-rate to the relativised target +
a tau-based `threat_level`) and `pi4/pfd.py _update_traffic` (per-target
previous-range memory).  `shared/config_base.py` gains `ADSB_TAU_S` etc.

### SETUP-SCROLL-SHORT  Display setup page scroll stops before the bottom
Status: **FIXED (band-aid)** — superseded by DISPLAY-SETUP-SPLIT
`_DSP_ROWS` had grown to 12 rows (FLIGHT PATH / TFC ALT / TFC RANGE) but the
scroll clamp still assumed 11 + a 2-row approximation of the taller MAP
LAYERS row, so it stopped ~56 px short.  Fixed on pi4 by `_dsp_max_scroll()`
computing the real content height (standard rows + `_DSP_LAYERS_ROW_H` +
padding).  pi_zero was already correct (7 rows, clamp 9).  Proper long-term
fix is the page split below.

### INSET-ORIENT-STUCK  Moving-map inset stuck north-up — TRK↑ toggle dead
Status: **FIXED**
The inset forced north-up whenever `_eff_range > 40`
(`_eff_orient = "nrth" if _eff_range > 40 else _orient_pref`), which
swallowed the pilot's TRK↑ choice on the WND page (winds zoom ≥40) and at
wide manual zooms — the toggle and the setup pill both flipped `map_orient`
but the render ignored it.  The reasons for the force (rotated-tint smear,
per-heading rebuild) are gone now that tint registration is fixed and the
cache key excludes rotation, so the inset honours the pilot's choice at
every manual range; only AUTO stays north-up so the destination doesn't
spin under the chevron.  (pi_zero already honoured `map_orient` directly.)

### WINDS-INSET-ALT-SELECT  No winds-altitude selector on the inset
Status: **FIXED (verify position on hardware)**
When the WND overlay is up on the PFD inset, a small **"9k ft"** readout
now sits just under the range label and **cycles the level** (3k/6k/9k/12k/
18k) on tap, reusing `_mfd_cycle_winds_alt` — so the inset can change winds
altitude without the full-screen MFD.  Winds zoom stays on the L/R half
taps.  The draw box + the hit-test box are kept in sync in `pi4/pfd.py`
(inset overlay draw + the `_last_map_rect` tap handler); eyeball the exact
position/size on the panel and nudge the two boxes if needed.  Forecast-time
on the inset (`_mfd_cycle_winds_time`) was left for later — not requested.

### FPLLIB-DELETE-RESURRECT  Deleted saved flight plans come back from peers
Status: **FIXED (tombstones)** — `shared/fpllib.py` `merge_plan_lib` is a
tombstone-aware union: deleting a plan records `{NAME_UPPER: deleted_ts}` in
`fpl_saved["deleted"]`, which rides the `KIND_FPLLIB` sync so peers drop the
plan and won't re-add a tombstoned name (a re-save clears the tombstone so a
re-create wins).  Same path covers user-waypoint deletes.  Wired in both
`pi4/pfd.py` (`_fpl_plan_delete`, `_ssync_apply_fpl_lib`) and `pi_zero/pfd.py`;
covered by `shared/test_fpllib.py`.  Original report below.
Deleting a saved flight plan (LOAD-plan picker → DEL) only removes it on
the local display.  The saved-plan / user-waypoint library syncs between
screens (`KIND_FPLLIB`, gated by SHARE FPL), and that sync is a pure
**additive union merge** with no concept of deletion: `_ssync_apply_fpl_lib`
adds any peer plan whose name we don't already have, and every display
re-broadcasts its full plan list every ~5 s (`_ssync_publish_fpl_lib`).
So a plan you delete on screen A is re-broadcast by screen B (which still
has it) and re-added on A within ~5 s — it "resurrects" unless you race to
delete it on every connected screen at once.  Same flaw applies to **user
waypoint** deletes.  Repro: two+ displays with SHARE FPL on, DEL a plan on
one → it reappears.
Root cause: union merge can't express "this was deleted" — there is no
tombstone or deletion propagation.
Fix options:
  - **Tombstones (preferred):** on delete, record `{name, deleted_ts}` and
    include a `deleted` set in the `KIND_FPLLIB` payload.  Peers drop any
    plan whose name has a tombstone newer than the plan's own
    creation/update time, and don't re-add a tombstoned name.  Expire
    tombstones after a window (e.g. 24 h) so the set stays small.  Needs a
    creation/update timestamp per saved plan (currently plans carry only
    `name` + `waypoints`).
  - **Explicit delete event:** broadcast a one-shot `KIND_FPLLIB_DELETE`
    `{name}` that peers apply immediately — simpler, but lost if a peer is
    offline during the delete (it'll re-resurrect when that peer rejoins,
    so tombstones are still the robust answer).
Touches: `shared/screen_sync.py` (payload shape), `_ssync_apply_fpl_lib` /
`_ssync_publish_fpl_lib` / `_fpl_plan_delete` (+ the user-waypoint delete
path) in both `pi4/pfd.py` and `pi_zero/pfd.py`.

### FPV  Velocity vector / flight-path marker on the AI
Status: **pi4 + iPhone LANDED — pi_zero port pending (tracked as FPV-PIZ)**
Resolution (pi4 + iPhone): `draw_fpv_marker()` in `pi4/pfd.py` projects
the velocity vector (NED azimuth = GPS track, elevation = flight-path
angle `atan2(VS, GS)`) into the same `_full_ai` frame the airport /
runway / obstacle overlays use (ah/48° px-per-deg, roll rotation), so
it banks with the SVT horizon and aligns with the airport symbols.
Open circle + two wings + vertical stub, cyan, self-hides below 5 kt
GS, clamps to the AI box with a ghost arrow when the vector falls
outside (drawn even in extreme attitudes, unlike the other overlays).
Toggle `fpv_enabled` (default ON) on the Display setup screen ("FLIGHT
PATH" row), persisted via the existing `ds` subtree. iPhone mirror:
`drawFPV()` in `iphone_display/index.html` using the same focal /
pitchOff / roll math `drawAI()` draws the horizon with, with a "✈
FLIGHT PATH" toggle in the setup menu (localStorage `fpv_enabled`).
Sign check (matches the cue we wanted): in a coordinated climb the FPV
sits below the nose by the AOA. Still open: **pi_zero port** — its AI
overlays use a rotate-the-whole-SRCALPHA-surface model rather than
per-feature roll, so the upright-symbol behaviour needs a small
adaptation; see FPV-PIZ below.
Target: `pi4/pfd.py` (new draw routine inside the AI block), iPhone
display equivalent.
Context: a velocity-vector / flight-path-vector marker shows the
pilot where the airplane is actually going through space, not where
the nose is pointing.  Standard on every modern PFD (G3X, Dynon,
Garrecht, mil HUDs).  Indispensable on approach — pilot flies the
FPV onto the runway numbers and lands there, whatever the crab
angle and AOA are doing.  Inputs we already have:
  - **GPS track** (`gps.track_deg`) — azimuthal direction the
    airplane is moving over the ground.
  - **GPS GS + VS** — flight-path angle = `atan2(VS_fps, GS_fps)`.
    GS from `gps.speed_kt`, VS from `gps.vspeed_fpm` (already
    smoothed in the firmware).
  - **AHRS attitude** (yaw/pitch/roll from WT901) — needed to
    project the FPV onto the AI viewport, since the AI is
    drawn in body-frame.
Math: the FPV's screen position is the projection of the velocity
vector into the camera frame the AI is rendered with.  The same
projection chain `draw_airport_symbols` already uses (yaw / pitch
/ roll, focal length, screen centre) takes a unit vector in the
NED frame and returns AI pixel coordinates.  Build a NED unit
vector from track + flight-path-angle, run it through the existing
projection, draw a small open circle with two horizontal "wings"
and a short vertical stub (the conventional FPV symbol).
Work items:
  - Compute FPV NED unit vector from GPS track + GS + VS each
    frame.  Skip when GS < 5 kt (parked / taxi noise) — hide the
    symbol below that gate.
  - Reuse the airport projection helper to land it on the AI.
    Clamp to the AI rectangle so it never escapes the viewport
    in extreme attitudes; show a "ghost" arrow at the edge in
    that case (G3X convention).
  - Symbol: 12 px circle, 6 px wings either side, 6 px vertical
    stub.  Cyan, no fill.  Same colour as the heading-bug bug
    set (pilot-relevant, not alert).
  - Display setup gains an FPV ON/OFF toggle (default ON when
    GPS is healthy).  Persist with the rest of the display
    settings.
  - Sanity check: on the ground rolling forward, the FPV should
    sit in front of the nose (track ≈ heading, FPA ≈ 0).  In a
    coordinated climb-out, the FPV sits below the nose by the
    AOA (a free cross-check against AOA-CALC once it lands).
Pairs with AOA-CALC (the vertical offset between aircraft symbol
and FPV is exactly AOA when the wind is along the flight path —
a free in-flight calibration target for the airframe constants).

### PI4-ETE-LATENCY  pi4 inset ETE takes a beat to populate
Status: **FIXED** — pi4 inset ETE now populates immediately on D2 activation
(confirmed on hardware).  Original report below.
PiZ data-strip ETE updates instantly when a D2 is activated; pi4's
inset ETE shows `--:--` for a noticeable interval before catching up.
Both code paths now use great-circle distance (per PR #8 ETE fix),
so it's not a math thing — likely a stale-cache or projector-recompute
in the inset draw path on pi4.  Check whether pi4's inset uses a
quantised render cycle that delays first-frame ETE pickup.

### MAP-POLYLINE-WIDE-ZOOM  Inset/MFD still not snappy at 160 nm
Status: **DONE — no polyline change needed.**  The proposed stride
decimation (below) was tried and **rejected: it looked horrible** at 160 nm.
The actual cause of the wide-zoom lag turned out to be elsewhere (not the
polyline projection), so once that was addressed the `_draw_polylines` path
was left as-is and 160 nm is snappy.  Original investigation notes retained
below for context, but the "next lever" decimation idea is a dead end —
don't re-attempt it.
After 2bbb7fe (vectorised polyline projection in `_draw_polylines`,
both `pi4/moving_map.py` and `pi_zero/moving_map.py`), zoom levels
20–80 nm are snappy and 160 nm is "better, not amazing".  Bench
note: at 160 nm the AI was previously laggy across all three axes
because the polyline layer was dropping the render loop below 30 FPS;
that's gone now, but 160 nm still has visible cost from the surviving
admin_1 and admin_0 vertex counts inside the cull window.

Next lever (one-line change, no quality loss at extreme zoom because
inset is ~1.5 px/nm there → vertices closer than ~3 nm are sub-pixel):
add stride decimation inside the `for idx in visible_idx:` loop,
between the `ring = points[s:e]` line and the vectorised projection:
  ```python
  stride = 1 if range_nm < 80 else (2 if range_nm < 160 else 4)
  if stride > 1:
      ring = ring[::stride]
  ```
Keep the threshold conservative — at 80 nm the inset is still ~3 px/nm
so stride=1 is right there.  Only kick in at ≥80 nm.

If even that isn't enough, the *next* lever would be moving the
per-polyline draw call into a single `pygame.draw.lines` flush over
all visible rings (with `None`-terminated breaks) — but pygame doesn't
expose that primitive, so it'd mean dropping to `pygame.gfxdraw` or
keeping the per-ring call.  Don't go there until stride decimation
has been tried and proven insufficient.

LOD caches were considered and explicitly rejected — see commit
message on 2bbb7fe and the design discussion in chat: the rasterised
water-mask pipeline already covers the "huge vertex count, fill
rendering" case (lakes + ocean via `tools/build_water_tiles.py` +
`pi4/svt_renderer_gl.py`'s fragment shader sample), so the only
remaining vector-line layer (state + country borders) doesn't have
enough vertex count to justify a build-time LOD pipeline once
vectorisation removes the Python per-vertex overhead.

### WINDS-INET-REFETCH  Internet winds aloft freeze at startup, don't follow the route
Status: **FIXED — settle gate corrected + route-corridor winds added (pi4 + pi_zero)**
Resolution: (1) Both `WxClient.run` and `AwcPoller.run` replaced the
exact-equality `settled` test with a pan-DRAG debounce — a slice is
treated as a drag only when the view jumped more than
`max(move_frac·radius, 2 nm)`; ownship motion (even a ~30× time-
compressed sim, ~0.9 nm/slice) stays under that, and the periodic
`interval_s` refresh is always allowed through regardless. So
view-driven products (winds, TAF, AIRMET/SIGMET, NOTAM) now follow the
aircraft instead of freezing at the departure field. (2) New
`fetch_winds_route` / `_route_winds_points` in `shared/wx.py` build a
corridor along an active direct-to / flight-plan course — samples down
the polyline (ownship first, then remaining legs) with ±`WINDS_ROUTE_
WIDTH_NM` (=25 nm, `shared/config_base.py`) lateral offsets, deduped and
capped at 96 points so the batched Open-Meteo request stays bounded.
`_winds_fetch` (pi4 + pi_zero) uses the corridor when a course is active
and falls back to the visible-area grid otherwise. Verified: PHX→ABQ
(~285 nm) yields 60 corridor points covering both ends with lateral
spread; settle gate passes flight motion and rejects finger-drags;
`test_wx.py` + `test_fisb.py` still pass. Remaining nicety (not blocking):
`force_refresh()` on a D2/FPL change so the corridor switches instantly
rather than on the next move/periodic tick.
Field-test follow-ups (same session): (a) the corridor must *augment*,
not replace, the visible-area grid — a D2 to a near waypoint shrank the
winds page to ~3 clustered barbs. `fetch_winds()` now always builds the
full visible grid and adds the route corridor on top (dedup + cap 96),
so the page fills at any zoom. (b) The WND page now drops the
hypsometric terrain tint like the METAR/NEXRAD pages (`wx_active` in
`moving_map.py`) — on pi4 the 80 nm tint build pulls a huge SRTM-tile
set that could OOM/lock the display; with the winds poller now active
(no longer frozen) the contention tipped it over. pi_zero already caps
the tint below 80 nm so this is parity-only there.
Performance redesign (field-test round 2): the fetch-per-view model
hammered Open-Meteo (stalls of seconds–minutes on every pan/zoom) and
the draw re-rendered a `font.render()` temp tag per barb per frame
(~0.5–1 ms each — the real "barb draws are slow" cause). Reworked around
"cache wide, draw the subset":
  - **Wide cached grid.** `_winds_view` now returns a FIXED wide range
    (`WINDS_CACHE_RANGE_NM` = 110) instead of the zoom, with a constant
    `WINDS_GRID_SPACING_NM` (20 nm) barb spacing; `fetch_winds` builds
    that square grid (+ corridor beyond the cache for long routes). The
    poller only re-pulls on a big centre drift (½ the cache) or the
    periodic timer — so zoom and small pans need NO network.
  - **Decimate on draw.** `_winds_decimate` keeps at most one barb per
    screen cell (~one per `min(w,h)/3.5`), so any zoom shows a clean
    ~12–20 evenly-spread set — fixes the inset's wide-zoom pile-up and
    the short-D2 centre stack, and slashes draw cost.
  - **Glyph cache.** `_wx_glyph` memoises rendered temp/LV text, turning
    the per-frame `font.render` storm into blits.
  - Zoom-in refetch bug (strict `<0.5×`) made moot by the fixed cache
    range, but the symmetric `1.4×/0.7×` threshold is kept for the
    other view-driven pollers.
Net: winds follow the aircraft, pan/zoom is instant, draw is cheap, and
the data covers a wide area + the route. Open items: at very tight zoom
(≤20 nm) the fixed-spacing cache is naturally sparse (winds are smooth,
so acceptable); tune `WINDS_GRID_SPACING_NM` / `WINDS_CACHE_RANGE_NM` if
denser close-in barbs are wanted.
Original diagnosis below for reference.
Status (orig): **OPEN — diagnosed, fix not yet applied**
Target: `shared/wx.py` (`WxClient.run` / `AwcPoller.run` settle gate),
`pi4/pfd.py` `_winds_view` / `_winds_fetch`, `shared/fisb.py`
`set_winds` (replace-vs-accumulate).
Symptom (reported from an all-night sim run out of PHX): the INET winds
barbs loaded once for the local area around the departure field and
never updated as the aircraft flew — no winds along the route, no new
columns appearing en route.
Diagnosis — two separate problems:
  1. **Settle-debounce starves a moving aircraft of refetches.** Both
     `WxClient.run` and `AwcPoller.run` only fetch when the view has
     "settled": `settled = (cur == prev_view)` where
     `cur = (round(lat,2), round(lon,2), round(radius))`, compared
     between consecutive ~0.7 s poll slices. round(,2) is ~0.01° ≈ 0.6
     nm. A continuously-moving ownship (and especially a
     time-compressed overnight sim) changes that rounded tuple on most
     slices, so `settled` is rarely/never true — and BOTH the
     move-based AND the periodic (`interval_s`) refetch are gated
     behind it. Result: the only fetch that fired was the one on the
     ground at PHX where the view genuinely sat still. The debounce was
     meant to avoid a burst of fetches mid pan-drag, but it wrongly
     also suppresses ownship motion. Affects winds, TAF, AIRMET/SIGMET,
     NOTAM, NEXRAD — every view-driven poller shares this pattern.
  2. **Replace-not-accumulate + tiny grid = no route picture.**
     `set_winds()` deletes all prior INET columns each poll
     (`shared/fisb.py:1197`), and `_winds_view` requests only a
     `map_zoom_nm`-sized grid (default 5 nm in PFD mode) centred on the
     ownship. So even with refetch working you'd only ever hold a ~4 nm
     patch around the aircraft — never the whole route.
Fix sketch:
  - Replace the exact-equality settle test with a tolerance + dwell:
    treat the view as settled when it hasn't moved more than a small
    fraction of the radius for ~1–2 s (debounce drags) but never let
    that gate block the periodic `interval_s` refresh or a large
    ownship move. Cleanest: compute `settled` from a distance
    threshold against the last *evaluated* view, and always allow the
    periodic timer through regardless of settle.
  - For route coverage, decide between (a) widening the winds grid to a
    forward-biased corridor along the active FPL/track, or (b) keeping
    the local grid but bumping the grid extent so barbs read for the
    visible MFD range. (a) is the real fix; (b) is the quick one.
  - Add a one-line "[WX] winds refetch @lat,lon" debug print behind a
    flag so the next sim run can confirm the poller is following.
Bench/sim repro: start at PHX, fly a long leg (time-compressed if
possible), watch whether the winds barbs re-centre. Pre-fix they stay
at PHX; post-fix they should track the ownship.
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

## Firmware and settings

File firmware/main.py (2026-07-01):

# ---------------------------------------------------------------------------
# main.py  –  AHRS PFD main application
# ---------------------------------------------------------------------------
# Boot sequence
# 1. Start WiFi access point (SSID / password from config.py)
# 2. Initialise WT901 AHRS on UART0
# 3. Initialise GPS on UART1
# 4. Optionally initialise BME280 barometer on I2C1 (GP2/GP3)
# 5. Start async HTTP/SSE server
# 6. Sensor-read loop runs concurrently, updating shared state dict
#
# Altitude source priority: BME280 (if present) → GPS
# If BME280 is not connected or fails to init, GPS altitude is used and
# state['baro_src'] = 'gps'.  No restart required.
#
# On the phone: connect to the WiFi AP, open http://192.168.4.1
# ---------------------------------------------------------------------------

import uasyncio as asyncio
import network
import utime
import ujson
import sys
import gc
import machine
from machine import Pin, WDT

from config import (
    WT901_UART_ID, WT901_TX_PIN, WT901_RX_PIN, WT901_BAUD,
    WT901_FORCE_DEFAULT_OUTPUT,
    GPS_UART_ID,  GPS_TX_PIN,  GPS_RX_PIN,  GPS_BAUD,
    BME280_ENABLE, BME280_I2C_ID, BME280_SDA_PIN, BME280_SCL_PIN,
    BME280_I2C_ADDR, BME280_QNH_DEFAULT,
    SDP31_ENABLE, SDP31_I2C_ID, SDP31_SDA_PIN, SDP31_SCL_PIN,
    SDP31_I2C_ADDR, SDP31_AUTO_ZERO_AT_BOOT,
    MS4525_ENABLE, MS4525_I2C_ID, MS4525_SDA_PIN, MS4525_SCL_PIN,
    MS4525_I2C_ADDR, MS4525_PSI_RANGE, MS4525_AUTO_ZERO_AT_BOOT,
    WT901_AY_SIGN,
    AHRS_PITCH_TRIM, AHRS_ROLL_TRIM, AHRS_YAW_TRIM,
    AHRS_CONNECTOR, AHRS_MOUNTING,
    AHRS_FILTER_ENABLE, AHRS_KP_ACC, AHRS_KI_ACC, AHRS_KP_MAG,
    AHRS_ACCEL_GATE_G, AHRS_USE_MAG,
    AHRS_MAG_GYRO_GATE_LO_DPS, AHRS_MAG_GYRO_GATE_HI_DPS,
    AHRS_GPS_TRACK_ENABLE, AHRS_GPS_TRACK_MIN_KT,
    AHRS_GPS_TRACK_INTERVAL_S, AHRS_GPS_TRACK_ALPHA,
    AHRS_FWD_IN_SENSOR, AHRS_ALIGN_DURATION_S, FW_VERSION,
    AHRS_PITCH_ALIGN, AHRS_ROLL_ALIGN,
    AHRS_DYN_GYRO_LO_DPS, AHRS_DYN_GYRO_HI_DPS,
    AHRS_DYN_AC_LO_G, AHRS_DYN_AC_HI_G, AHRS_DYN_KP_SCALE_MIN,
    AHRS_DEBUG_PRINT, AHRS_DEBUG_PRINT_DECIM,
    AP_SSID, AP_PASSWORD, HTTP_PORT, BROADCAST_HZ,
)
from wt901        import WT901
from gps          import GPS
from web_server   import start_server
from ahrs_filter  import Mahony
import airdata
import math

TRIMS_FILE  = 'trims.json'
MAGDEV_FILE = 'magdev.json'
MAGCAL_FILE = 'magcal.json'   # hard-iron offsets (mx_off, my_off, mz_off)
ORIENT_FILE = 'orient.json'
BOOT_LOG_FILE = 'boot_log.json'  # boot count + last reset cause + last alive ms

# Human-readable map for machine.reset_cause(). Values vary by port; the names
# we care about are PWRON_RESET (clean power-up), WDT_RESET (watchdog fired,
# usually means a task starved the scheduler > 8 s), SOFT_RESET (machine.reset()
# or REPL Ctrl-D), HARD_RESET (RUN pin or external reset).
_RESET_NAMES = {}
for _n in ('PWRON_RESET', 'WDT_RESET', 'SOFT_RESET', 'HARD_RESET',
           'DEEPSLEEP_RESET', 'BROWN_OUT_RESET'):
    _v = getattr(machine, _n, None)
    if _v is not None:
        _RESET_NAMES[_v] = _n


def load_boot_log():
    try:
        with open(BOOT_LOG_FILE, 'r') as f:
            d = ujson.loads(f.read())
        return {
            'boot_count':       int(d.get('boot_count', 0)),
            'last_cause':       int(d.get('last_cause', -1)),
            'last_alive_ms':    int(d.get('last_alive_ms', 0)),
        }
    except Exception:
        return {'boot_count': 0, 'last_cause': -1, 'last_alive_ms': 0}


def save_boot_log(d):
    try:
        with open(BOOT_LOG_FILE, 'w') as f:
            f.write(ujson.dumps(d))
    except Exception as e:
        print(f'save_boot_log failed: {e}')


async def alive_ticker():
    """Persist current uptime to flash every 60 s. On the next boot, the boot
    logger reports the value as 'last alive ms' — i.e. how long we ran before
    we died. Lets us bracket the death to within a one-minute window without
    needing to be attached to the REPL when it happens.

    Interval chosen against RP2040 flash endurance (~100k erase cycles per
    sector): 60 s gives ≳ 5 years of continuous operation before we'd start
    worrying about wear. 5 s — what we used during the bring-up soak — would
    have burned through that in under a week."""
    while True:
        try:
            d = load_boot_log()
            d['last_alive_ms'] = utime.ticks_ms()
            save_boot_log(d)
        except Exception:
            pass
        await asyncio.sleep(60)


def load_trims():
    try:
        with open(TRIMS_FILE, 'r') as f:
            t = ujson.loads(f.read())
        return {k: float(t.get(k, d)) for k, d in
                [('pitch_trim', AHRS_PITCH_TRIM),
                 ('roll_trim',  AHRS_ROLL_TRIM),
                 ('yaw_trim',   AHRS_YAW_TRIM)]}
    except Exception:
        return {'pitch_trim': AHRS_PITCH_TRIM,
                'roll_trim':  AHRS_ROLL_TRIM,
                'yaw_trim':   AHRS_YAW_TRIM}


def save_trims(state):
    try:
        with open(TRIMS_FILE, 'w') as f:
            f.write(ujson.dumps({'pitch_trim': state['pitch_trim'],
                                  'roll_trim':  state['roll_trim'],
                                  'yaw_trim':   state['yaw_trim']}))
    except Exception as e:
        print(f'save_trims failed: {e}')


def load_magdev():
    try:
        with open(MAGDEV_FILE, 'r') as f:
            t = ujson.loads(f.read()).get('corrections', [])
        return [float(x) for x in t] if len(t) == 36 else []
    except Exception:
        return []


def save_magdev(table):
    try:
        with open(MAGDEV_FILE, 'w') as f:
            f.write(ujson.dumps({'corrections': table}))
    except Exception as e:
        print(f'save_magdev failed: {e}')


def load_magcal():
    """Hard-iron offsets (mx_off, my_off, mz_off) — subtracted from raw mag
    before it's handed to the Mahony filter. Captured at install time by
    the 8-cardinal cal wizard. Default (0,0,0) = no correction."""
    try:
        with open(MAGCAL_FILE, 'r') as f:
            d = ujson.loads(f.read())
        return (float(d.get('mx_off', 0.0)),
                float(d.get('my_off', 0.0)),
                float(d.get('mz_off', 0.0)))
    except Exception:
        return (0.0, 0.0, 0.0)


def save_magcal(offset):
    try:
        with open(MAGCAL_FILE, 'w') as f:
            f.write(ujson.dumps({'mx_off': offset[0],
                                  'my_off': offset[1],
                                  'mz_off': offset[2]}))
    except Exception as e:
        print(f'save_magcal failed: {e}')


def load_orient():
    """Returns (connector, mounting, pitch_align, roll_align).  The two
    align fields are fine-grained input-side rotations that compensate
    for sensor mounting that's a few degrees off the four 90° connector
    quanta — see config.AHRS_PITCH_ALIGN."""
    _valid_c = ('forward', 'right', 'left', 'aft')
    _valid_m = ('normal', 'inverted')
    try:
        with open(ORIENT_FILE, 'r') as f:
            d = ujson.loads(f.read())
        c  = d.get('connector', AHRS_CONNECTOR)
        m  = d.get('mounting',  AHRS_MOUNTING)
        pa = float(d.get('pitch_align', AHRS_PITCH_ALIGN))
        ra = float(d.get('roll_align',  AHRS_ROLL_ALIGN))
        if c not in _valid_c: c = AHRS_CONNECTOR
        if m not in _valid_m: m = AHRS_MOUNTING
        # Clamp to ±15° — the flight-zero (LEVEL) cage folds the mounting
        # residual into the alignment, so give it headroom beyond a hand-dialed
        # trim; the connector quanta still handle larger (90°) rotations.
        if pa < -15.0: pa = -15.0
        elif pa > 15.0: pa = 15.0
        if ra < -15.0: ra = -15.0
        elif ra > 15.0: ra = 15.0
        return c, m, pa, ra
    except Exception:
        return AHRS_CONNECTOR, AHRS_MOUNTING, AHRS_PITCH_ALIGN, AHRS_ROLL_ALIGN


def save_orient(state):
    try:
        with open(ORIENT_FILE, 'w') as f:
            f.write(ujson.dumps({'connector':   state['orientation'],
                                  'mounting':    state['mounting'],
                                  'pitch_align': state['pitch_align'],
                                  'roll_align':  state['roll_align']}))
    except Exception as e:
        print(f'save_orient failed: {e}')



def apply_magdev(yaw, table):
    """Interpolate a 36-point (10°/slot) deviation table and apply to yaw."""
    if len(table) != 36:
        return yaw
    idx = (yaw % 360) / 10.0
    i0 = int(idx) % 36
    i1 = (i0 + 1) % 36
    frac = idx - int(idx)
    c0, c1 = table[i0], table[i1]
    dc = c1 - c0
    if dc > 180:  dc -= 360
    elif dc < -180: dc += 360
    return (yaw + c0 + frac * dc) % 360

# ── Onboard LED ─────────────────────────────────────────────────────────────
led = Pin('LED', Pin.OUT)

# ── Shared state (read by web_server, written by sensor_loop) ───────────────
state = {
    '_broadcast_hz': BROADCAST_HZ,
    # AHRS
    'roll'     : 0.0,   # degrees  (+right wing down)
    'pitch'    : 0.0,   # degrees  (+nose up)
    'yaw'      : 0.0,   # degrees  magnetic heading [0, 360)
    'ay'       : 0.0,   # lateral acceleration g (+right); drives slip ball
    # GPS position (always from GPS)
    'lat'      : 0.0,   # decimal degrees
    'lon'      : 0.0,   # decimal degrees
    'speed'    : 0.0,   # groundspeed knots
    'track'    : 0.0,   # track over ground degrees true
    'fix'      : 0,     # 0=none 1=GPS 2=DGPS
    'sats'     : 0,     # satellites in use
    'gps_alt'  : 0.0,   # GPS MSL altitude ft (always present for calibration ref)
    # Altitude (BME280 when available, else GPS)
    'alt'      : 0.0,   # feet MSL – displayed altitude
    'vspeed'   : 0.0,   # vertical speed ft/min
    'baro_src' : 'gps', # 'bme280' | 'gps'
    # Barometric setting (user-adjustable via /baro endpoint)
    'baro_hpa' : BME280_QNH_DEFAULT,  # QNH in hPa; written by /baro, broadcast via SSE
    # AHRS trim offsets (degrees; adjustable via /trim, persisted to trims.json)
    'pitch_trim': 0.0,
    'roll_trim':  0.0,
    'yaw_trim':   0.0,
    # AHRS orientation (reflects config.py values; broadcast for Pi4 info display)
    'orientation': AHRS_CONNECTOR,
    'mounting':    AHRS_MOUNTING,
    # Input-side axis alignment (degrees; airframe convention).
    # Applied to raw gyro/accel/mag before the Mahony filter to kill
    # yaw → pitch/roll coupling from imperfect sensor mounting.
    'pitch_align': AHRS_PITCH_ALIGN,
    'roll_align':  AHRS_ROLL_ALIGN,
    # Air data (SDP33-1500Pa + BME280 density correction)
    'ias_kt'     : 0.0,  # indicated airspeed (knots) — ρ₀ reference
    'tas_kt'     : 0.0,  # true airspeed (knots) — density-corrected
    'dp_pa'      : 0.0,  # raw differential pressure (Pa); diagnostic
    'oat_c'      : 0.0,  # outside air temperature (°C) from BME280
    'dens_alt_ft': 0.0,  # density altitude (ft)
    'wind_dir'   : 0.0,  # wind direction (deg from); 0 = wind absent or unknown
    'wind_kt'    : 0.0,  # wind speed (knots)
    'airdata_ok' : False, # True when SDP33 + BME280 both fresh
    # On-Pico Mahony filter state (broadcast for display diagnostics)
    'att_src'   : 'wt901', # 'mahony' when filter is active, else 'wt901'
    'att_aid'   : 'basic', # 'tas' | 'gs' | 'basic' — centripetal speed source
    'ahrs_aligning': True, # True for the first AHRS_ALIGN_DURATION_S after the
                           # filter starts receiving gyro data — display shows
                           # an "AHRS ALIGN" banner so the pilot knows the
                           # attitude is still settling.
    'ahrs_zupt' : False,   # True when Zero-Velocity Update is engaged (gyro
                           # input forced to zero because the airframe is
                           # confirmed stationary — prevents long-term drift).
    'fw_ver'    : FW_VERSION, # Firmware date code (broadcast to display)
    # Sensor health flags (set every sensor_loop tick)
    'ahrs_ok':   False,
    'gps_ok':    False,
    'gps_comm':  False,  # True when GPS UART is sending valid NMEA sentences
    'baro_ok':   False,
    # Magnetic deviation table (36 corrections at 10° steps; loaded from magdev.json)
    '_magdev'  : [],
    # Hard-iron offsets (mx_off, my_off, mz_off) — subtracted from raw mag
    # in _run_filter_step before mag is handed to the Mahony filter. Captured
    # by the tumble-cal wizard from the display. Loaded from magcal.json.
    '_mag_offset': (0.0, 0.0, 0.0),
    # Tumble-cal state: when active, accumulate min/max of each mag axis
    # for offset computation on $MAGOFF,FINISH.
    '_magtumble_active': False,
    '_magtumble_min'   : [None, None, None],
    '_magtumble_max'   : [None, None, None],
    # Raw mag readings (unscaled int counts) — broadcast for the cal wizard
    # to compute fresh hard-iron offsets each calibration run.
    'mx': 0.0, 'my': 0.0, 'mz': 0.0,
    # Pre-correction heading (post yaw_trim, pre magdev) — broadcast for cal panel
    'yaw_raw'  : 0.0,
    # WT901's PKT_ANGLE yaw (post-remap) — broadcast for the cal wizard's
    # RAW HDG display. Fast response, no Mahony filter dynamics in the way.
    'yaw_wt901': 0.0,
}


# ── WiFi AP setup ────────────────────────────────────────────────────────────
def setup_ap():
    ap = network.WLAN(network.AP_IF)
    ap.active(True)
    if AP_PASSWORD:
        ap.config(essid=AP_SSID, password=AP_PASSWORD, security=4)  # WPA2
    else:
        ap.config(essid=AP_SSID, security=0)
    timeout = 10_000  # ms
    start   = utime.ticks_ms()
    while not ap.active():
        if utime.ticks_diff(utime.ticks_ms(), start) > timeout:
            raise RuntimeError('WiFi AP failed to start')
        utime.sleep_ms(100)
    ip = ap.ifconfig()[0]
    print(f'WiFi AP "{AP_SSID}" active  →  http://{ip}')
    return ip


_G_PER_M_S2 = 1.0 / 9.80665
_KT_TO_M_S  = 0.514444

# ── Linear-acceleration aid for the filter ──────────────────────────────────
# Without this, forward acceleration / braking show up as pitch changes —
# the accelerometer measures (gravity − dV/dt), so an accelerating airframe
# looks like nose-up to the filter and a braking one looks like nose-down.
# We differentiate the active speed source (TAS preferred, GS fallback),
# low-pass-filter the result, and add it as a body-forward component to the
# existing centripetal-correction subtraction.
_LIN_ACCEL_ALPHA       = 0.1     # IIR α for smoothing dV/dt — τ ≈ 200 ms at 50 Hz
_LIN_ACCEL_MIN_DT_S    = 0.05    # minimum dt before computing a new sample
_LIN_ACCEL_DV_SPIKE_MS = 5.0     # m/s — guards against fix loss / source switch
_lin_v_ms     = 0.0
_lin_v_t_ms   = 0
_lin_a_filt   = 0.0     # filtered linear accel (m/s²), forward = positive
_lin_v_valid  = False   # only differentiate once we've seen two consecutive valid samples


def _update_linear_accel():
    """Compute forward linear acceleration from rate of change of the active
    speed source. Returns m/s² along aircraft +forward (matches the sign
    convention of AHRS_FWD_IN_SENSOR — a positive value = accelerating).
    Smoothed with a 200 ms time constant to suppress GPS-rate jitter and
    SDP/MS4525 noise."""
    global _lin_v_ms, _lin_v_t_ms, _lin_a_filt, _lin_v_valid

    # Same source ladder as the centripetal correction: TAS preferred → GS.
    if state.get('airdata_ok') and state.get('tas_kt', 0.0) > 5.0:
        v_kt = state['tas_kt']
        v_ok = True
    elif state.get('gps_ok') and state.get('speed', 0.0) > 1.0:
        v_kt = state['speed']
        v_ok = True
    else:
        v_kt = 0.0
        v_ok = False

    now_ms = utime.ticks_ms()
    v_ms = v_kt * _KT_TO_M_S

    if not v_ok:
        # Lost the source — decay the filtered value toward zero and reset
        # the differentiator state so the next valid sample doesn't compute
        # a huge bogus dV/dt against a stale prior value.
        _lin_a_filt *= 0.5
        _lin_v_valid = False
        return _lin_a_filt

    if not _lin_v_valid:
        # First valid sample after a gap — prime the differentiator.
        _lin_v_ms = v_ms
        _lin_v_t_ms = now_ms
        _lin_v_valid = True
        return _lin_a_filt

    dt_s = utime.ticks_diff(now_ms, _lin_v_t_ms) / 1000.0
    if dt_s < _LIN_ACCEL_MIN_DT_S:
        return _lin_a_filt   # too soon — hold last filtered value

    dv_ms = v_ms - _lin_v_ms
    # Reject obviously bogus jumps (GPS reacquisition, source switch).
    if abs(dv_ms) > _LIN_ACCEL_DV_SPIKE_MS:
        _lin_v_ms = v_ms
        _lin_v_t_ms = now_ms
        return _lin_a_filt

    raw_a = dv_ms / dt_s
    _lin_a_filt = (1.0 - _LIN_ACCEL_ALPHA) * _lin_a_filt + _LIN_ACCEL_ALPHA * raw_a
    _lin_v_ms = v_ms
    _lin_v_t_ms = now_ms
    return _lin_a_filt


# ── Zero-Velocity Update (ZUPT) ──────────────────────────────────────────────
# When we're confident the airframe is stationary, force gyro input to the
# Mahony to zero. This eliminates any drift from gyro bias (temperature,
# component aging) over long stationary periods — the user left the system
# powered overnight and saw the attitude indicator slowly walk in roll/pitch.
# The accel correction stays active so roll/pitch lock to the gravity vector;
# yaw freezes at its last estimate (mag aiding still allowed if enabled).
_ZUPT_GS_THRESHOLD_KT     = 1.0     # GPS GS below this counts as still
_ZUPT_IAS_THRESHOLD_KT    = 5.0     # IAS below this counts as still
_ZUPT_GYRO_THRESHOLD_DPS  = 1.0     # gyro magnitude below this (deg/s)
_ZUPT_ACCEL_GATE_G        = 0.05    # |a|-1g| below this (tighter than filter)
_ZUPT_QUIET_DURATION_MS   = 3000    # all conditions sustained this long → engage

_zupt_quiet_since_ms = None         # monotonic ms when conditions first held


def _detect_stationary(ahrs, now_ms):
    """Conservative stationary detector. Returns True only after every
    condition has held continuously for _ZUPT_QUIET_DURATION_MS:
      - GPS groundspeed below threshold (or no fix at all)
      - Air-data unavailable OR IAS below threshold
      - Gyro magnitude below threshold (no rotation)
      - Accel magnitude within tight band of 1g (no linear motion)
    All four must hold so we don't accidentally ZUPT during a hover, a
    coordinated zero-G push-over, or any other "GPS is zero but the
    aircraft is moving" edge case."""
    global _zupt_quiet_since_ms

    gs = state.get('speed', 0.0) or 0.0
    gps_quiet = (not state.get('gps_ok')) or gs < _ZUPT_GS_THRESHOLD_KT
    ias = state.get('ias_kt', 0.0) or 0.0
    air_quiet = (not state.get('airdata_ok')) or ias < _ZUPT_IAS_THRESHOLD_KT

    gyro_mag = math.sqrt(ahrs.wx*ahrs.wx + ahrs.wy*ahrs.wy + ahrs.wz*ahrs.wz)
    gyro_quiet = gyro_mag < _ZUPT_GYRO_THRESHOLD_DPS

    accel_mag = math.sqrt(ahrs.ax*ahrs.ax + ahrs.ay*ahrs.ay + ahrs.az*ahrs.az)
    accel_quiet = abs(accel_mag - 1.0) < _ZUPT_ACCEL_GATE_G

    if gps_quiet and air_quiet and gyro_quiet and accel_quiet:
        if _zupt_quiet_since_ms is None:
            _zupt_quiet_since_ms = now_ms
        elif utime.ticks_diff(now_ms, _zupt_quiet_since_ms) >= _ZUPT_QUIET_DURATION_MS:
            return True
    else:
        _zupt_quiet_since_ms = None
    return False


def _hdg_offset_for(connector):
    """Connector orientation → heading offset applied in the Euler remap."""
    if connector == 'forward': return 90.0
    if connector == 'left':    return 180.0
    if connector == 'aft':     return 270.0
    return 0.0   # 'right' (default)


def _fwd_in_sensor_for(connector):
    """Aircraft +forward unit vector expressed in the WT901 sensor frame,
    derived from the connector orientation. Used by both the centripetal
    correction (a_c = ω × V_fwd_sensor) and the linear-acceleration aid
    (a_lin · fwd_sensor) — both need to subtract inertial acceleration along
    the *actual* aircraft forward direction, which depends on how the chip
    is rotated in the airframe.

    Reference: in 'right' mode (connector points right of aircraft), the
    WT901's +Y axis points along aircraft forward. Each 90° change in
    connector orientation rotates the chip by 90° about its +Z axis, so
    the aircraft-forward direction in chip frame rotates correspondingly.

    Returns a 3-tuple (x, y, z) unit vector. Caller may also use the
    AHRS_FWD_IN_SENSOR config constant as a manual override for installations
    that don't match the standard connector geometry."""
    if connector == 'forward':
        return (1.0, 0.0, 0.0)
    if connector == 'left':
        return (0.0, -1.0, 0.0)
    if connector == 'aft':
        return (-1.0, 0.0, 0.0)
    return (0.0, 1.0, 0.0)   # 'right' (default)


def _ac_axes_in_sensor(connector):
    """Return (roll_axis, pitch_axis) as 3-tuples expressed in the WT901
    sensor frame, given the connector orientation.  Derived from the
    same axis mapping that _apply_remap uses on the output Euler — kept
    in sync by inspection (a mismatch would make ALIGN behave the
    opposite of what the user expects)."""
    if connector == 'forward':
        # output: airframe roll = +sensor_pitch (axis = sensor +Y)
        #         airframe pitch = +sensor_roll (axis = sensor +X)
        return ((0.0, 1.0, 0.0), (1.0, 0.0, 0.0))
    if connector == 'left':
        # output: airframe roll = +sensor_roll (axis = sensor +X)
        #         airframe pitch = -sensor_pitch (axis = sensor -Y)
        return ((1.0, 0.0, 0.0), (0.0, -1.0, 0.0))
    if connector == 'aft':
        # output: airframe roll = -sensor_pitch (axis = sensor -Y)
        #         airframe pitch = -sensor_roll (axis = sensor -X)
        return ((0.0, -1.0, 0.0), (-1.0, 0.0, 0.0))
    # 'right' (default): airframe roll = -sensor_roll, pitch = +sensor_pitch
    return ((-1.0, 0.0, 0.0), (0.0, 1.0, 0.0))
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

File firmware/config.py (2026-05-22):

# ---------------------------------------------------------------------------
# config.py  –  Hardware pin assignments and system settings
# ---------------------------------------------------------------------------
#
# Pin map (same as the AHRS PCB rev A; matches bench breakouts wired the
# same way).  Both build paths share this file — the only difference is
# whether the sensors hang off a single board or four separate breakouts.
#
#   WT901 AHRS         UART0   GP0 TX / GP1 RX        3V3 @ 36
#   GY-NEO6MV2 GPS     UART1   GP4 TX / GP5 RX        VSYS @ 39
#   BME280 baro        I2C1    GP2 SDA / GP3 SCL      addr 0x76, 3V3
#   SDP33-1500Pa        I2C1    GP2 SDA / GP3 SCL      addr 0x21, 3V3
#   (reserved AOA)     I2C1    GP2 SDA / GP3 SCL      addr 0x22 (future SDP3x)
#
# I²C1 is shared across BME280 + SDP33 + (future) AOA sensor — each device
# has a distinct address so they coexist on the same SDA/SCL pair without
# arbitration logic.
#
# NOTE: UART0 on GP0/GP1 is shared with USB-serial debug.  During normal
#       (non-debug) flight use this is fine.  If you need USB debug
#       simultaneously, move WT901 to GP12/13 (UART0 alt) and update
#       WT901_TX_PIN / WT901_RX_PIN below.
# ---------------------------------------------------------------------------

# ── WT901 AHRS ──────────────────────────────────────────────────────────────
WT901_UART_ID = 0
WT901_TX_PIN  = 0   # GP0  – Pico TX → WT901 RX  (for sending config, optional)
WT901_RX_PIN  = 1   # GP1  – Pico RX ← WT901 TX
WT901_BAUD    = 9600  # WT901 factory default; increase to 115200 after config

# Force the WT901's Return-Data-Switch back to the factory default
# (ACC + GYRO + ANGLE + MAG) at every firmware boot. Recovers from a chip
# whose config has somehow been corrupted — we hit this with PKT_ANGLE
# (0x53) silently disappearing after many bench reboots. The reconfigure
# is idempotent (writes the same value) so leaving this True forever is
# safe. Set False only if you have a deliberately customised WT901 config
# you don't want overwritten.
WT901_FORCE_DEFAULT_OUTPUT = True

# ── GPS (GY-NEO6MV2 / u-blox NEO-6M) ───────────────────────────────────────
GPS_UART_ID = 1
GPS_TX_PIN  = 4   # GP4  – Pico TX → GPS RX  (for UBX config, optional)
GPS_RX_PIN  = 5   # GP5  – Pico RX ← GPS TX
GPS_BAUD    = 9600  # NEO-6M factory default

# ── WiFi Access Point ────────────────────────────────────────────────────────
# Phone connects to this network – no internet required
AP_SSID     = "AHRS-PFD"
AP_PASSWORD = ""           # empty = open AP (no password); WPA2 if non-empty

# ── Web server ────────────────────────────────────────────────────────────────
HTTP_PORT = 80   # Navigate to http://192.168.4.1 on the phone

# ── BME280 Barometer (optional) ──────────────────────────────────────────────
# Set BME280_ENABLE = False if no barometer is connected; the firmware will
# fall back to GPS altitude automatically.
#
# Wiring (I2C1):
#   VCC → 3V3(OUT)   GND → GND
#   SDA → GP2  (pin 4)    SCL → GP3  (pin 5)
#   SDO → GND  → I2C address 0x76  (pull SDO high for 0x77)
BME280_ENABLE      = True
BME280_I2C_ID      = 1
BME280_SDA_PIN     = 2      # GP2  (I2C1 SDA)
BME280_SCL_PIN     = 3      # GP3  (I2C1 SCL)
BME280_I2C_ADDR    = 0x76   # 0x76 (SDO=GND) or 0x77 (SDO=VCC)
BME280_QNH_DEFAULT = 1013.25  # hPa – ICAO standard; update via /baro on the display

# ── SDP33-1500Pa Differential Pressure (optional – airspeed sensor) ──────────
# Set SDP31_ENABLE = False on bench builds that don't carry the air-data
# sensor; the firmware will fall back to GPS groundspeed automatically and
# the $AHRS packet will report airdata_ok = False.
#
# Wiring (I2C1, shared with BME280):
#   VDD → 3V3(OUT)  GND → GND
#   SDA → GP2       SCL → GP3
#   ADDR pin floating → 0x21  (default; 0x22 if pulled to VDD — useful when
#   pairing a second SDP3x for AOA on the same bus, see AOA-PROBE in
#   Docs/BUGS_AND_TODO.md)
#
# Pneumatic plumbing on the airframe:
#   "+" port  → pitot   (ram pressure)
#   "−" port  → static  (cabin/airframe static reference, tee'd into BME280)
SDP31_ENABLE   = True
SDP31_I2C_ID   = 1
SDP31_SDA_PIN  = 2          # shared with BME280 (I2C1 SDA)
SDP31_SCL_PIN  = 3          # shared with BME280 (I2C1 SCL)
SDP31_I2C_ADDR = 0x21       # 0x21 default; 0x22 when ADDR pin tied to VDD

# Zero-offset capture at boot.  When True, the firmware records the dp_pa
# reading observed in the first ~2 s after power-up and subtracts it from
# subsequent readings — relies on the aircraft being stationary at boot.
# Disable if the aircraft is already moving at firmware start (in-flight
# restart).  The display also exposes a manual /sdp_zero endpoint.
SDP31_AUTO_ZERO_AT_BOOT = True
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

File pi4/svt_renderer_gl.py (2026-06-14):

"""
svt_renderer_gl.py – OpenGL ES SVT renderer for Pi 4.

Hybrid architecture: this module renders only the SVT terrain background.
The rest of the PFD (tapes, ladder, drum boxes, UI) continues to be
drawn by pygame in pfd.py.  This module exposes one function:

    render_svt_gl(srtm_dir, ai_w, ai_h, pitch, roll, hdg, alt, lat, lon)
        → pygame.Surface

which is a drop-in replacement for the pygame scanline renderer.
The rendered Surface can be blitted into the AI region of the main PFD.

Implementation:
  - Standalone EGL context (offscreen, no display required)
  - Terrain mesh built from SRTM tiles within MESH_RADIUS_NM of aircraft
  - World coordinates: X=East, Y=North, Z=Up (metres relative to aircraft)
  - Vertex shader: world → clip space using look-at + perspective matrices
  - Fragment shader: clearance-based color palette (matches pygame version)
  - Sky gradient rendered as a fullscreen quad behind the terrain
  - Result read back via glReadPixels → pygame.Surface

Falls back to None if EGL/moderngl unavailable.  pfd.py handles fallback
to the pygame renderer.
"""

import math
import os
import threading

try:
    import numpy as np
    HAS_NUMPY = True
except ImportError:
    HAS_NUMPY = False

try:
    import moderngl
    HAS_MODERNGL = True
except ImportError:
    HAS_MODERNGL = False

import pygame

# Import shared terrain utilities
from terrain import load_tile, get_elevation_ft
# Water-mask loader (Natural Earth ocean+lakes rasterised per SRTM tile).
# Optional — if no .water tiles are present the renderer paints terrain
# everywhere as before.
try:
    from water import load_tile as load_water_tile
    HAS_WATER = True
except ImportError:
    HAS_WATER = False
    load_water_tile = None

# ── Constants ─────────────────────────────────────────────────────────────────
MESH_RADIUS_NM    = 20.0        # nm — terrain mesh extent around aircraft
MESH_GRID_N       = 300         # mesh resolution (300×300 = 90K vertices)

# Outer (far-LOD) mesh — drawn underneath the inner mesh to fill the gap
# between the inner mesh edge and the geometric horizon with real terrain
# silhouettes instead of a flat haze gradient.  Coarser sampling so the
# extra coverage doesn't blow up vertex count.
OUTER_MESH_RADIUS_NM = 75.0     # nm — out to ~75 nm ridges silhouette
OUTER_MESH_GRID_N    = 60       # 60x60 = 3600 verts (~5x coarser than inner)

# Mesh sizing strategy:
#   "constant"  — always use MESH_RADIUS_NM regardless of altitude.  Keeps the
#                 grid spacing consistent and predictable; simpler to reason
#                 about distances.  Recommended default.
#   "altitude"  — scale radius with sqrt(alt_ft) so that higher altitudes
#                 show more terrain (up to MESH_RADIUS_MAX_NM).  Clamped at
#                 MESH_RADIUS_MIN_NM on the low end.  Keeps the ~90 m vertex
#                 spacing since MESH_GRID_N scales with the radius.
MESH_SIZE_MODE    = "constant"  # "constant" | "altitude"
MESH_RADIUS_MIN_NM = 10.0       # floor (altitude mode)
MESH_RADIUS_MAX_NM = 40.0       # ceiling (altitude mode)
NM_TO_M        = 1852.0         # nautical miles → metres
FT_TO_M        = 0.3048         # feet → metres
M_TO_FT        = 1.0 / FT_TO_M

# Vertical FOV chosen to match the pygame pitch-ladder scale exactly:
# pitch_ladder uses px_per_deg = ai_h / 48, so vertical FOV = 48° ensures the
# SVT horizon, pitch-ladder 0° bar, and zero-pitch reference line all align
# at the same screen position for any given pitch angle.
V_FOV_DEG      = 48.0           # vertical field of view
NEAR_PLANE_M   = 50.0
FAR_PLANE_M    = OUTER_MESH_RADIUS_NM * NM_TO_M * 1.5

# ── Distance grid overlay ─────────────────────────────────────────────────────
# Cyan-tinted lines on the terrain to help judge distance and orientation.
# Aligned with cardinal directions (N/S and E/W).
GRID_SPACING_NM   = 0.5         # minor grid spacing (0.5 nm squares)
GRID_MAJOR_EVERY  = 4           # major (brighter) line every N minor lines (= 2 nm)
GRID_FADE_NM      = MESH_RADIUS_NM   # grid fades out at the mesh edge

# ── Sun-angle lighting ────────────────────────────────────────────────────────
# Direction FROM terrain TOWARD the sun, in world frame (X=East, Y=North, Z=Up).
# Default: mid-morning sun from the SE at 45° elevation.
#   azimuth_deg measured from North, clockwise (compass bearing of the sun)
#   elevation_deg above horizon (0° = horizon, 90° = directly overhead)
SUN_AZIMUTH_DEG   = 135.0       # SE (compass bearing)
SUN_ELEVATION_DEG = 45.0        # sun height above horizon
SUN_INTENSITY     = 0.75        # 0.0 = lighting off, 1.0 = full strength
SUN_AMBIENT       = 0.45        # 0.0 = pitch-black shadows, 1.0 = no shadow

# ── GLSL shaders ──────────────────────────────────────────────────────────────

VERTEX_SHADER = """
#version 300 es
precision highp float;

in vec3 in_pos;          // (East, North, Up_absolute) in metres. Origin at
                         // mesh centre. East metric scales with cos(mesh_lat)
                         // (mesh covers a fixed *angular* span); Z is absolute
                         // elevation above sea level.
in float in_water;       // 0.0 = land, 1.0 = water (sampled at vertex from
                         // Natural Earth ocean+lakes mask).
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

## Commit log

2026-03-31 Add complete AHRS PFD firmware and phone display
    - firmware/config.py – pin assignments, WiFi AP, baud rates
    - firmware/wt901.py – WT901 UART binary packet driver (0x53 Euler angles)
    - firmware/gps.py – NMEA parser for GPRMC/GPGGA, VSI computed from alt delta
    - firmware/web_server.py – async HTTP + Server-Sent Events server (no SHA-1 needed)
    - firmware/main.py – uasyncio entry point, WiFi AP, 50 Hz sensor loop
    - display/index.html – full-screen Canvas PFD: synthetic vision, pitch ladder,
    roll arc, aircraft symbol, slip ball, speed/alt boxes,
    heading tape, GPS status, live SSE link indicator
    https://claude.ai/code/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
    [config.py, gps.py, main.py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]
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2026-04-01 Add real ay slip ball, BME280 barometer with QNH calibration
    - firmware/bme280.py: new BME280 I2C driver (float compensation,
    ICAO hypsometric altitude, EMA vertical speed, calibrate_to_alt_ft)
    - config.py: BME280 on I2C1 GP2/GP3, WT901_AY_SIGN for mount orientation
    - main.py: optional BME280 init with GPS fallback; ay forwarded to state;
    gps_alt always kept in state for calibration reference; /baro?cal_ft
    calibration request handled via _cal_ft flag
    - web_server.py: query-string parser; new /baro?qnh=X&cal_ft=X endpoint
    - index.html: slip ball now driven by real D.ay (0.2g full deflection);
    QNH + BME/GPS source drawn below VSI; baro badge + adjustment panel
    with +/-1/+/-0.1 hPa bu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
    [bme280.py, config.py, main.py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]
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2026-04-01 Add AHRS trim adjustments, sensor health flags, and red-X failure overlays
    - firmware/config.py: AHRS_PITCH_TRIM / AHRS_ROLL_TRIM / AHRS_YAW_TRIM defaults
    - firmware/main.py: load_trims()/save_trims() persisting to trims.json; trim
    applied to raw WT901 output in sensor_loop; ahrs_ok/gps_ok/baro_ok health
    flags broadcast via SSE (ahrs_ok uses 5-second staleness window)
    - firmware/web_server.py: /trim endpoint (±10° pitch/roll, ±180° yaw)
    - display/index.html: TRIM badge + slide-up panel with per-axis ±0.1°/±0.5°
    (pitch/roll) and ±0.5°/±1° (heading) buttons; drawRedX() overlays AHRS,
    GPS, and ALT tapes when the corresponding sensor is unavailable
    - display/preview.html: hea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
    [config.py, main.py, web_server.py]
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2026-04-09 Add Pi Zero 2W PFD display system (pi_display/)
    GI-275 inspired fullscreen 640x480 PFD with synthetic vision:
    - pi_display/pfd.py Main display: SVT AI, speed/alt/hdg tapes,
    roll arc, aircraft symbol, slip ball,
    failure overlays, demo mode (Sedona AZ),
    touch/key input for bugs and baro
    - pi_display/sse_client.py Threaded SSE client connecting to Pico W
    at 192.168.4.1/events
    - pi_display/terrain.py SRTM3 .hgt tile loader + scanline SVT
    perspective renderer (numpy-accelerated)
    - pi_display/config.py Layout constants, V-speeds (C172S defaults)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
    [config.py, sse_client.py, terrain.py]
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2026-04-10 Add FAA Digital Obstacle File download, parser, and AI rendering
    - pi_display/obstacles.py: new module — DOF fixed-width parser, numpy
    structured-array cache (dof_cache.npy), spatial query with bounding-box
    pre-filter, disk_stats(), pure-Python fallback when numpy absent
    - pi_display/config.py: OBSTACLE_DIR, OBSTACLE_RADIUS_NM, OBSTACLE_WINDOW_FT,
    OBSTACLE_CAUTION_FT, OBSTACLE_WARNING_FT
    - pi_display/pfd.py: draw_obstacle_data() screen with download/progress/legend;
    obstacle_data_hit(); _od_download_thread() fetches ZIP, extracts DAT, parses
    cache; draw_obstacle_symbols() projects nearby obstacles onto AI viewport as
    red/amber/green tower symbols with lit-indicator dot; startup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
    [config.py, obstacles.py]
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2026-04-10 Make obstacle alert radius time-based with config constants
    Replace hardcoded 3 nm radius with a dynamic lookahead computed from
    airspeed: radius_nm = speed_kt × ALERT_TIME_S / 3600, clamped to
    [ALERT_RADIUS_MIN_NM, ALERT_RADIUS_MAX_NM].
    New config.py constants:
    ALERT_TIME_S = 60 s (lookahead window)
    ALERT_RADIUS_MIN_NM = 1.0 nm (floor)
    ALERT_RADIUS_MAX_NM = 3.0 nm (ceiling)
    Effective radii by airspeed:
    60 kt → 1.0 nm 90 kt → 1.5 nm
    120 kt → 2.0 nm 180 kt → 3.0 nm
    _update_terrain_alert() now accepts speed_kt; _alert_radius_nm()
    encapsulates the clamped calculation. Terrain clearance is still
    sampled at current position (no horizontal lookahead needed for
    a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
    [config.py]
2026-04-10 Add obstacle download date, expiry badge, and clean up status strip
    obstacles.py: download_date() and is_expired() using DAT file mtime
    config.py: OBSTACLE_EXPIRY_DAYS = 28
    - disp["od"] gains dl_date / expired / age_days fields
    - _od_load_obstacles() populates date and expiry on each load
    - draw_system_setup(): OBSTACLE DATA tile subtitle shows date or
    ⚠ EXPIRED when data is older than 28 days
    - draw_status_badges(): badges are now shown only when required —
    blank strip during normal flight; AHRS FAIL, NO LINK, NO TER,
    NO OBS, EXP OBS on left; GPS ALT, NO GPS on right
    preview_640x480.py: match new badge logic; system tile shows date;
    two new previews (badges_no_data, ba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
    [config.py, obstacles.py]
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2026-04-10 Add stale-data timeout and GPS-slaved heading source
    Stale-data timeout (STALE_TIMEOUT_S = 3 s):
    - Track _link_lost_t in main loop; when NO LINK persists beyond
    STALE_TIMEOUT_S the data_stale flag is raised.
    - render() overrides ahrs_ok=False when data_stale, causing the AI and
    heading strip to receive the AHRS FAIL red-X treatment.
    - On reconnect, _link_lost_t is cleared immediately.
    GPS-slaved heading source (AHRS / Sensors screen → HEADING SOURCE):
    - disp["ss"]["hdg_src"]: "mag" (default) or "gps"
    - New Row 4 in draw_ahrs_setup / ahrs_setup_hit with MAG / GPS TRK
    segment buttons and a note that GPS TRK requires a valid fix.
    - In render(), hdg = disp["track"] when hdg_src=="gps" a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
    [config.py]
2026-04-10 GPS TRK heading: complementary filter (gyro + GPS)
    Raw GPS track is too noisy to use directly as a heading indicator.
    Replace the simple track pass-through with a complementary filter:
    High-frequency: AHRS yaw rate (d(yaw)/dt each frame) propagates
    _gps_hdg smoothly at 30 Hz.
    Low-frequency: GPS ground track slowly slaves the absolute value
    at GPS_HDG_SLAVE_K (5%) per frame, resolving a
    10° error in ~1.5 s at 30 fps.
    Wrap-safe signed-angle arithmetic handles the 359°→0° boundary.
    Filter state (_gps_hdg, _prev_yaw_disp) resets when switching back
    to MAG mode so there is no stale value on re-entry.
    New config constant: GPS_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
    [config.py]
2026-04-10 Add SimFlyState and sim presets (partial — UI wiring in progress)
    config.py:
    - SIM_PRESETS: 12 airport locations (ICAO, city, lat/lon, field elev)
    - disp["sim"]: preset_idx, init_alt/hdg/spd, gps_fail/baro_fail/ahrs_fail
    - _sim_state: module-level SimFlyState handle (None when not running)
    - SimFlyState class: physics tick driven by hdg_bug/alt_bug/spd_bug
    - Standard-rate turns (3°/s), proportional bank (±25°)
    - VS = clamp(alt_err × 0.5, ±1000 fpm); pitch from VS
    - Speed accel/decel 2 kt/s toward spd_bug
    - Dead-reckoning position update (lat/lon nm from hdg + speed)
    - Sensor failure flags: gps_fail/baro_fail/ahrs_fail → state fields
    - Aircraft keeps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
    [config.py]
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2026-04-12 fix(pfd): kmsdrm SDL driver, native-res scaling, DISPLAY_ROTATE config
    Three display fixes for HDMI output on Pi Zero 2W:
    1. SDL_VIDEODRIVER: changed default from fbcon to kmsdrm (matches what
    the Pi requires when running headless with vc4-kms-v3d). Removed the
    SDL_FBDEV line which is irrelevant to kmsdrm.
    2. Jumpiness fix: fullscreen mode now opens the display at the monitor's
    native resolution instead of 640×480, renders the PFD to a 640×480
    Surface, then smoothscales it to fit with aspect-ratio letterboxing.
    This avoids the driver-level scaling that caused frame-rate stuttering.
    3. DISPLAY_ROTATE (config.py): new 0/90/180/270 option applied at flip
    time via pygame.t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
    [config.py]
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2026-04-12 perf: SVT block-sampling (4×) + disable KMS vsync
    terrain.py:
    - Add _SVT_STEP=4 block-sampling to _render_svt_numpy: compute SRTM
    elevations on a 1/4-resolution grid (121×50 ≈ 6K samples instead of
    97K), then nearest-neighbour upsample with np.repeat back to full
    resolution. Expected ~16× speedup on the bilinear-interpolation step,
    bringing SVT frame time from ~400ms down to ~25ms.
    - Set SDL_RENDER_VSYNC=0 and SDL_VIDEO_KMSDRM_VSYNC=0 before pygame.init()
    to prevent display.flip() from blocking on the display vsync signal.
    The 82ms flip time was consuming ~15% of each frame budget at vsync-
    locked 12Hz; disabling it should drop flip time to ~1ms.
    Together these t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
    [terrain.py]
2026-04-12 perf: pygame.SCALED display + SVT_STEP=8 + nearest-neighbour elevation
    - Replace manual pygame.transform.scale(640×480 → native_res) with
    pygame.SCALED display mode. SDL2 handles the logical→physical scale
    in C, removing the ~75-100 ms Python scale+blit that was misidentified
    as vsync overhead. flip() is now just pygame.display.flip().
    - Simplify _flip(): the surf-is-not-screen branch is now only reached
    when DISPLAY_ROTATE != 0 (rotated DSI displays), which is the only
    case that still needs a manual transform.
    - Increase _SVT_STEP from 4 to 8: 484×200 grid sampled at 61×25 =
    1525 SRTM lookups instead of 6050 (STEP=4) or 97K (STEP=1).
    - Switch from bil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
    [terrain.py]
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2026-04-13 Add display hardware support: Waveshare 3.5" DPI + ROADOM 7"/10" HDMI
    Pi Zero 2W: Configure for Waveshare 3.5" DPI LCD (640x480, IPS,
    DPI parallel RGB, I2C capacitive touch, PWM backlight on GPIO 18).
    Setup script adds waveshare-35dpi DT overlay to config.txt.
    Pi 4: Multi-display support via DISPLAY_PROFILE config setting.
    Layout constants computed dynamically from resolution so the PFD
    scales correctly to any display size:
    - "waveshare_35": 640x480 DPI (same small form factor)
    - "roadom_7": 1024x600 HDMI (ROADOM LE070-01 7" IPS)
    - "roadom_10": 1024x600 HDMI (ROADOM 10" IPS)
    - "custom": user-defined resolution
    Font sizes and pitch-ladder geometry scale proportionally with
    display d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
    [config.py]
2026-04-13 Fix roll arc thickness, tape transparency, and arc scaling
    Roll arc (all versions):
    - Replace two offset 1px concentric arcs with a single width=2 arc
    - Cleaner, consistent 2px line without jagged gaps between the pair
    Tape transparency (all versions):
    - Extend AI sky/ground background to full display width (0 to DISPLAY_W)
    instead of just the center AI region
    - Semi-transparent tape backgrounds (alpha 195) now blend over the
    sky/ground horizon instead of over black
    Arc scaling (Pi 4 only):
    - ROLL_R now scales by min(_SX, _SY) instead of _SY alone
    - Prevents the arc from stretching on non-4:3 displays like the
    1024x600 ROADOM (16:10 aspect ratio)
    https://claude.ai/code/session_018sB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
    [config.py]
2026-04-13 Fix roll arc, tape widths, centering, and heading bug artifact
    Roll arc: Replace pygame.draw.arc (jagged rasteriser) with two
    concentric anti-aliased polylines (60 segments) for a smooth 2px arc
    on all display sizes.
    Tape widths: Keep SPD_W=74 and ALT_W=82 at their hand-tuned pixel
    sizes instead of scaling linearly. Extra horizontal pixels on
    1024x600 go to a wider AI region rather than fatter tapes.
    Centering: CX is now the centre of the AI region (between the tapes)
    rather than DISPLAY_W/2. This aligns the aircraft symbol, roll arc,
    and pitch ladder on the same vertical axis.
    Heading bug artifact: Treat hdg_bug=0 as "not set" so no magenta
    chevron is drawn at 000 degrees on startup.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
    [config.py]
2026-04-13 Fix arc, tapes, centering, heading artifact, and clipping issues
    Roll arc (both versions):
    - Replace pygame.draw.arc with 4 concentric AA polylines for bold ~3px arc
    - Fix upside-down rendering (was using math Y-up, now uses screen Y-down)
    - Tick marks widened to 2px to match arc weight
    Magenta heading artifact (both versions):
    - GPS track pointer suppressed when track ≈ hdg (within 1°) to avoid
    stray magenta triangle at tape centre when there's no wind/crab angle
    Alt tape alignment (both versions):
    - Alt tape background now extends from y=0 to TAPE_BOT, matching the
    speed tape which already covered the full height
    Pi 4 specific:
    - Tape widths: SPD_W=79, ALT_W=87 (+5px each for 102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
    [config.py]
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2026-04-14 Add OpenGL SVT renderer for Pi 4 (true 3D synthetic vision)
    Hybrid architecture: pygame continues to render all PFD UI (tapes,
    ladder, drum boxes, menus). OpenGL via moderngl + EGL renders only
    the SVT terrain background, then the result is composited as a
    pygame.Surface in the AI region.
    New module svt_renderer_gl.py:
    - Standalone EGL context (offscreen, no display server required)
    - Builds a 200x200 vertex terrain mesh from SRTM tiles within a
    10nm radius of the aircraft (cached, only rebuilds when position
    moves significantly)
    - Vertex shader: world-to-clip-space transform via look-at + perspective
    - Fragment shader: clearance-based color palette matching pygame version
    - Sky gradien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
    [config.py, render_preview_gl.py, svt_renderer_gl.py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]
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2026-04-14 SVT grid: contrast-aware colors, finer spacing, extended range
    Mesh: MESH_RADIUS_NM 10 → 20 (grid now extends to ~20nm visible at
    high altitude). MESH_GRID_N 200 → 300 to maintain ~90m vertex spacing
    across the larger area (90K verts, well within Pi 4 GPU budget).
    Grid spacing: 1nm minor / 5nm major → 0.5nm minor / 2nm major.
    Finer reference for closer-in distance estimation.
    Contrast-aware grid colors via clearance lookup in fragment shader:
    Brown terrain (clearance > 500ft) → light cyan-white grid
    Red/orange terrain (clearance < 500ft) → dark blue/black grid
    Smooth blend between via smoothstep over the 0–500ft transition.
    Line strength also boosted on red zones (40%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
    [svt_renderer_gl.py]
2026-04-14 Integrate OpenGL SVT into full PFD render
    Generated full-PFD preview PNGs at 1024×600 verifying the OpenGL
    SVT renderer composites correctly with all pygame UI overlays:
    - Tapes, drum boxes, pitch ladder, roll arc all draw correctly
    on top of the GL-rendered terrain background
    - Tape transparency works as expected (sky/terrain visible through)
    - Cyan zero-pitch reference line draws over the SVT
    - Level / climb-turn / approach / low-alt / high-alt / climb-left
    all render with proper 3D perspective
    New helper: pi4/render_pfd_offline.py
    - Bypasses pygame.display.init() (which conflicts with EGL on Xvfb)
    - Creates offscreen pygame.Surface and calls pfd.render() directly
    - Used to validate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
    [render_pfd_offline.py]
2026-04-14 Fix roll arc, sky shader, and add sun-angle lighting + mesh size config
    Roll arc (both versions): The arc and tick marks were rotating with
    roll, which is wrong for a ground-pointer design. The arc, ticks,
    and hollow ±45 triangles now stay FIXED on screen; only the moving
    doghouse pointer swings around the arc to indicate current bank.
    The fixed bottom doghouse remains the aircraft/airplane reference.
    Sky shader (OpenGL SVT): The flat horizon line in the sky shader
    created a brown triangular artifact whenever the aircraft was banked
    (terrain mesh tilted correctly but sky's horizon stayed flat). Now
    the sky shader un-rolls NDC coordinates (with aspect correction)
    before comparing against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
    [svt_renderer_gl.py]
2026-04-14 Roll arc direction + eliminate brown band beyond mesh edge
    Roll arc (both versions): Reverted to sky-pointer behavior but with
    correct sign — arc and ticks rotate WITH the sky (opposite direction
    from the previous broken version). At right bank the arc rotates
    visually CCW in pygame so the fixed aircraft pointer at the top of
    the screen reads off the current bank angle on the arc scale. Matches
    GI-275 convention.
    Brown artifact in climb turn: The 20 nm terrain mesh doesn't reach the
    geometric horizon (100+ nm at altitude), so there was always a gap
    between the mesh edge and the true horizon — the sky shader's "below
    horizon" fallback color was showing as a solid brown band through
    tha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
    [svt_renderer_gl.py]
2026-04-14 Fix _horizon_y_ndc sign — haze band was showing instead of sky in climbs
    Root cause of the "bad look" in climbing scenes (pitch > 0):
    _horizon_y_ndc had a double-negation bug that flipped the sign.
    At pitch +6° (nose up), the geometric horizon should be at NDC Y = -0.29
    (below centre in OpenGL Y-up), but the buggy formula returned +0.29
    (above centre). The sky shader then painted everything below Y=+0.29
    with the "haze" gradient — which included the ENTIRE true-sky region
    between Y=-0.29 and Y=+0.29. Visible as a huge brown/haze band
    stretching across where the sky should have been.
    Fix: horizon_y = -tan(pitch) / tan(fov/2). Pitched up → negative Y
    (horizon below centre). Pitche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
    [svt_renderer_gl.py]
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2026-04-14 Match SVT vertical FOV to pitch-ladder scale (40° → 48°)
    Root cause of the misaligned zero-pitch line in climb scenes:
    the pitch ladder draws bars using px_per_deg = ai_h / 48, which
    corresponds to a 48° vertical FOV. The SVT was rendering at 40°
    FOV, giving px_per_deg ≈ ai_h / 40 in the terrain projection.
    That 20% mismatch meant:
    - Pitch ladder's 0° bar at pitch × 10.9 px below AI centre
    - SVT's actual horizon at pitch × 13.1 px below AI centre
    - At pitch +8° they disagreed by ~18 px
    Fix: set V_FOV_DEG = 48° so the SVT renders with the same
    px-per-degree as the pitch ladder. Now at any pitch angle, the
    pitch ladder 0° bar, the zero-pitch cyan reference line, and the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
    [svt_renderer_gl.py]
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2026-04-14 Fix baro source detection: accept any non-'gps' value as baro-active
    The firmware sends baro_src='bme280' when the sensor is active, but
    the sim/demo/preview code uses 'baro'. The render code's check
    required exactly 'bme280', so sim/preview renders showed 'GPS ALT'
    in magenta alongside a CYAN altitude bug — inconsistent state.
    Fix: change the check from `baro_src == "bme280"` to
    `baro_src != "gps"` in both pi_zero and pi4 pfd.py. Any non-'gps'
    value now correctly indicates an active baro sensor, keeping the
    alt bug color and baro button in sync.
    Also updated the offline preview generator's seed value from 'baro'
    to 'bme280' for consistency with the firmware convention.
    https://claude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
    [render_pfd_offline.py]
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2026-04-14 Add combined SVT + airport + obstacle preview scene
    New preview scene preview_svt_airports_obstacles shows all three
    information layers composited together on the AI:
    - 3D SVT terrain with sun-angle shading and distance grid
    - Airport symbols with ident labels (KSEZ visible in approach view)
    - Obstacle tower symbols (red/amber/green by clearance)
    Scene parameters: aircraft approaching Sedona (KSEZ) from the NE at
    5500 ft / 85 kt on heading 226, slight left bank and -2° descent.
    At this altitude the aircraft is roughly 500 ft AGL over rising
    terrain that reaches ~6000 ft — so the preview demonstrates a
    realistic caution scenario with terrain, obstacles, and airport
    visible simultane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
    [render_pfd_offline.py]
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2026-04-14 Preview obstacles: SRTM-anchored ground elevations, cap heights ≤ 350 ft AGL
    Synthetic tower records in the preview generator were using hardcoded
    MSL values that didn't match where SRTM actually places the terrain
    at each tower location — which is why some towers still read as
    floating: the caret's base anchored to the DOF-record ground, but
    the rendered SVT terrain was 100–1000 ft higher or lower than that.
    Fix: query the SRTM elevation at each tower's (lat, lon), then derive
    msl_ft = srtm_ground + agl. Now the base of every caret falls
    exactly on the rendered terrain surface.
    Also reduced the synthetic AGL heights (was 280–820 ft, now 180–310)
    — these are only for preview s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
    [render_pfd_offline.py]
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2026-04-15 Fix Pi 4 system info text + extend offline preview gen to setup screens
    Pi 4 system screen was showing "Pi Zero 2W + Pico W" and "640x480 DSI"
    because the draw_system_setup hardware/display lines were copied
    verbatim when the codebases split. Now both versions read
    DISPLAY_W/DISPLAY_H from config and identify the correct hardware
    (Pi 4 + Pico W (OpenGL SVT) / Pi Zero 2W + Pico W).
    render_pfd_offline.py now also generates the setup screens (system,
    flight profile, display, AHRS, connectivity, main, airport_data)
    since those don't need GL. Setup PNGs land alongside the rest in
    pi4/previews/ so the doc image references stay current.
    Pi 4 setup_system PNG regenerated showing the new 3-tile d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
    [render_pfd_offline.py]
2026-04-15 Add user settings persistence across reboots
    New shared module shared/settings.py:
    - JSON save/load of a whitelisted subset of disp[] subtrees:
    fp (V-speeds, callsign, aircraft type)
    ds (units, brightness, baro_unit, night_mode)
    ss (pitch/roll trim, mounting, hdg_src, airspeed_src)
    cs (ahrs_url, wifi_ssid — wifi_pass NOT persisted)
    ad (airport filter toggles: show_public, show_heli, etc.)
    - Top-level scalars: hdg_bug, alt_bug, display_mode
    - Explicit skip-list for volatile / secret keys (WiFi password,
    download progress, SSE connection status, etc.)
    - Background debounced writer thread (1.5 s coalesce window) so
    rapid toggles batch into one dis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
    [config.py, settings.py]
2026-04-15 Add runway polygons + extended centerlines on attitude indicator
    New shared/runways.py parses OurAirports runways.csv (~14,700 records)
    into a NumPy structured array cached as runways_cache.npy. fetch_airports.sh
    now downloads both airports.csv and runways.csv in one pass and invalidates
    both caches so the PFD rebuilds them on next launch.
    Runway polygons project from each threshold's lat/lon using the same
    flat-earth atan2 convention as airport and obstacle symbols, so they
    correctly translate and scale with aircraft position, bank and pitch.
    Polygons draw within 8 NM. Extended dashed centerlines extend 10 NM
    off each threshold (shown within 15 NM of the airport).
    Both features are togg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
    [render_pfd_offline.py, runways.py]
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2026-04-15 Fix manual accuracy, Pi 4 BACK overflow, and centerline wrap artifacts
    Code:
    - pi4/pfd.py: widen BACK button to scale with FONT_SCALE (72→90 px on 1024×600)
    so "← BACK" at 19pt bold no longer overflows the outline. Factored all
    BACK draw/hit sites into _draw_back_button() + _back_hit() helpers.
    - pi4/pfd.py, pi_zero/pfd.py: add optional max_fov_deg to _project_latlon();
    extended-centerline draw now skips dashes whose endpoints are more than
    60° off the nose. Removes phantom horizontal streaks across the AI
    caused by flat-earth bearing wrap when the centerline extends behind us.
    - shared/config_base.py, pi_display/config.py: swap KATL for KOSH in the
    flight simulator prese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
    [config.py, config_base.py, render_pfd_offline.py]
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
